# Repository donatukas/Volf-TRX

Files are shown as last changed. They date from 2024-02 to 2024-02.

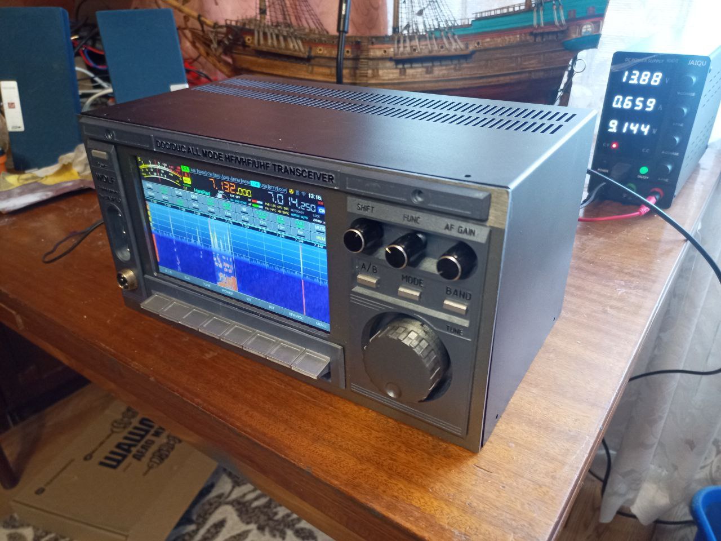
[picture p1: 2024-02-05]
Schematic/Wolf/CASE/7/Panel/photo_2023-04-01_13-19-56.jpg

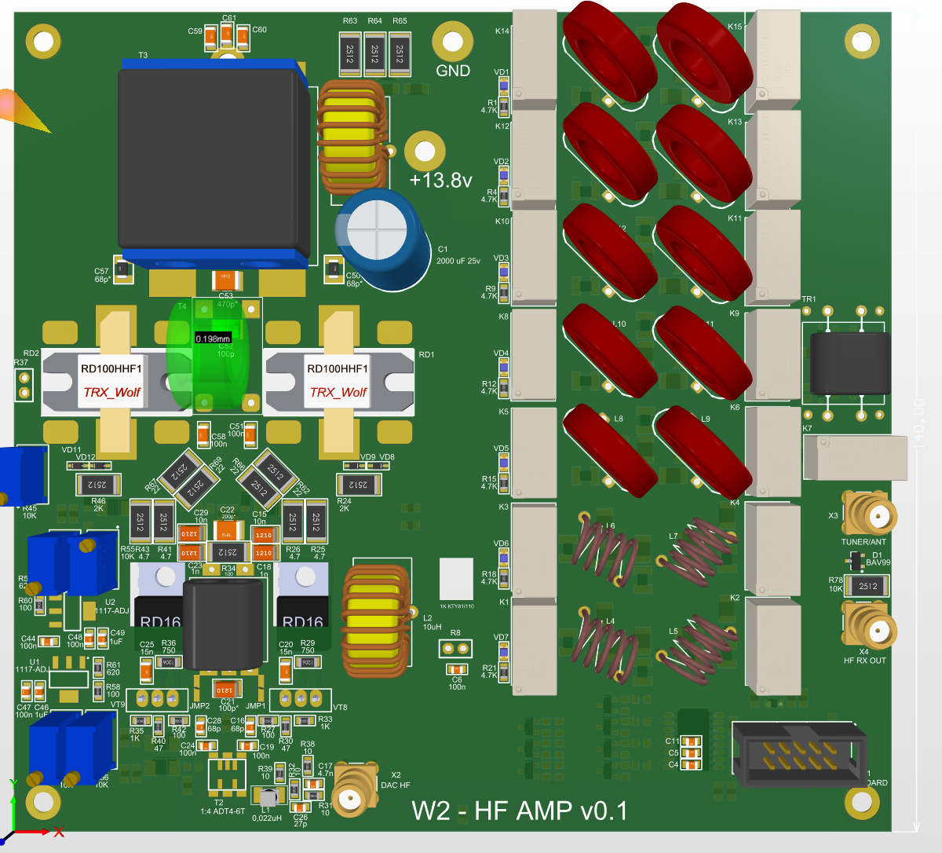
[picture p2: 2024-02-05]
Schematic/Wolf-2/Altium_Designer/W2-HF_AMP/HFAmp_UP_v01.png

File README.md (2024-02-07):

# Transceiver "Wolf"
DDC-DUC SDR Tranceiver project https://ua3reo.ru/tag/transiver-ua3reo/
* DUC-DDC TRANSCEIVER “WOLF”: RELEASE VERSION 9.3.1
* Community telegram channel: https://t.me/TRX_Wolf
* На русском https://github.com/donatukas/Volf-TRX/blob/main/README.ru-RU.md

## Principle of operation

The RF signal is digitized by a high-speed ADC chip and fed to an FPGA processor. <br>
It performs DDC / DUC conversion (digital frequency shift down or up the spectrum) - by analogy with a direct conversion receiver. <br>
The I and Q quadrature signals from the conversions are fed to the STM32 microprocessor. <br>
It filters, (de) modulates and outputs audio to an audio codec / USB. It also handles the entire user interface. <br>
When transmitting, the process occurs in the opposite order, only at the end of the chain there is a DAC, which converts the digital signal back to analog RF. <br>

## Specifications

* Receiving frequencies: 0 MHz - 750 MHz with fading each 61.44 MHz (above 145 MHz - without input filters)
* Transmission frequencies: 0 MHz - 150 MHz with fading on 110 MHz
* TX power (QRP version): 7W+ (HF), 5W (VHF)
* TX power (QRP++ DB5AT version): 20W (HF), 7W (VHF)
* TX power (RU4PN/WF-100D version): 100W (HF), 50W+ (VHF)
* Two antenna inputs
* Modulation types (TX / RX): CW, LSB, USB, AM, FM, WFM, DIGI
* LNA, Preamplifier
* Adjustable attenuator 0-31dB
* Band pass filters
* ADC dynamic range (16 bit) ~100dB
* Supply voltage: 13.8V (overvoltage and polarity reversal protection)
* Consumption current when receiving: ~0.7А (3'2 QRP), 0.9A (7' BIG)
* Current consumption during transmission: ~2.5А+ (QRP), 15A+ (BIG)
* Support for different displays: RA8875/HX8357B/HX8357C/ST7789/ST7796S/ST7735S/ILI9341/ILI9481/ILI9486

## Transceiver Features

* Panorama (spectrum + waterfall) up to 384 kHz wide
* Panorama tweaks and themes
* Dual receiver (mixing A + B or A&B audio in stereo)
* Adjustable bandwidth: HPF from 0Hz to 2700Hz, LPF from 100Hz to 20kHz
* Integrated SWR/power meter (HF)
* Automatic and manual Notch filter
* Switchable AGC (AGC) with adjustable attack rate
* Range map, with the ability to automatically switch modes
* Digital Noise Reduction (DNR), Pulse Noise Reduction (NB)
* CAT virtual COM port (FT-450 / TS-2000 emulation, RTS - PTT, DTR - CW)
* USB operation (audio transmission, IQ, CAT, KEY, PTT)
* RDS/CW/RTTY decoder, self-control, gauss filter
* SWR Graphs
* Spectrum analyzer
* FT8 receiver/transmitter
* Automatic send FT8 qso to log https://allqso.ru/
* WSPR Beacon
* VOX
* Equalizer TX/RX, reverber
* SSB/FM Scanner mode
* Support SDHC/SDSC/SDXC memory cards up to 16Gb
* WAV files radio recording and playback, fast broadcast recorded CQ message
* AGC takes into account the characteristics of human hearing (K-Weighting)
* TCXO frequency stabilization (it is possible to use an external clock source, such as GPS)
* WiFi operation: Time synchronization, virtual CAT interface (see Scheme/WIFI-CAT-instruction.txt)
* Tangent support Yaesu MH-36 и MH-48
* Hardware self-testing
* Firmware update over USB, SD, WiFi
* Digital pre-distortion
* And other.. (see menu)

### RF Parameters

Sensitivity at 10 dB SNR, LNA enabled:

* <150 MHz | -131 dBm | 63.0 nV
* 435 MHz | -121 dBm | 0.2 uV

Out-of-band emissions:

* 14 MHz -69 dBc
* 28 MHz -63 dBc
* 145 MHz -48 dBc -55 dBc

## Build

I ordered the boards in the Chinese service JLCPCB, they and their schemes are in the Scheme folder. <br>
After assembly, you need to flash FPGA and STM32 chips. <br>
If necessary, calibrate the transceiver through the appropriate menu <br>
WiFi module ESP-01 must have fresh firmware with SDK 3.0.4 and higher, and AT commands 1.7.4 and higher <br>

## Management

* **AF GAIN** - Volume
* **RIT / GAIN** - When the RIT function is active - smooth offset from the selected transceiver frequency. Inactive - IF gain control
* **ENC MAIN** - Main encoder for frequency control and menu settings
* **ENC 2** - Auxiliary encoder for menu operation. In normal mode, quickly switches the frequency, in CW fast change WPM
* **ENC 2[click]** - In CW mode, toggles between fast step and WPM selection, in other modes it opens the bandwidth properties.
* **BAND -** - Switch to the band below
* **BAND +** - Switch to higher band
* **MODE -** - Mode group switching SSB-> CW-> DIGI-> FM-> AM
* **MODE +** - Switching subgroup mod LSB-> USB, CW_L-> CW_U, DIGI_U-> DIGI_L, NFM-> WFM, AM-> IQ-> LOOP
* **FAST** - Mode of fast x10 rewinding of the frequency by the main encoder (configurable)
* **FAST [clamp]** - Frequency step settings
* **PRE** - Turn on the preamplifier (LNA)
* **PRE [clamp]** - Turn on the driver and / or amplifier ADC
* **ATT** - Turn on the attenuator
* **REC** - Save audio to SD card
* **CQ** - Play recorded CQ-message from SD card
* **MUTE** - Mute the sound
* **MUTE [clamp]** - Scanner mode
* **AGC** - Turn on AGC (automatic gain control)
* **AGC [clamp]** - AGC settings
* **A = B** - Setting the second bank of the receiver equal to the current
* **BW** - Switch to bandwidth selection menu (LPF)
* **BW [clamp]** - Switch to bandwidth selection menu (HPF)
* **TUNE** - Turn on the carrier for tuning the antenna
* **RF POWER** - Transmitter power selection
* **RF POWER [clamp]** - Squelch setting
* **A / B** - Switches between VFO-A / VFO-B receiver settings banks
* **A / B [clamp]** - Enable automatic mode change by bendmap
* **DOUBLE** - Turn on the dual receiver
* **DOUBLE [clamp]** - Switching between the modes of the dual receiver A&B (each channel of the headphones has its own path) or A + B (mixing signals of 2 receivers)
* **DNR** - Enable digital noise reduction
* **DNR [clamp]** - Turn on the impulse noise suppressor (NB)
* **NOTCH** - Turn on the automatic Notch filter to eliminate narrowband interference
* **NOTCH [clamp]** - Turn on the manual Notch filter to eliminate narrowband interference
* **SPLIT** - Allows you to split transmission and reception to different VFO banks
* **RIT [clamp]** - Enables RIT control from the front panel
* **WPM** - Switch to key speed selection menu (WPM)
* **WPM [clamp]** - Automatic key enable
* **MENU** - Go to the menu
* **MENU [clamp]** - Enable key lock LOCK
* **MENU [at power on]** - Reset transceiver settings
* **MENU [at power on+PRE]** - Reset transceiver settings and calibration
* **RIT** - Offset of the receiving frequency relative to the current frequency (TX without offset)
* **XIT** - Offset of the transmission frequency relative to the current frequency (RX without offset)

## Settings

### TRX Settings

* **Band Map** - Band Map, automatically switches mode depending on the frequency
* **Beeper** - Beep on key press
* **Callsign** - User callsign
* **Channel Mode** - Channel frequency mode (for LPD/PMR and etc.)
* **Custom Transverter** - Enable external transverter on non-ham band (just offset display frequency)
* **DEBUG Type** - Output of debug and service information to USB / UART ports
* **Encoder Accelerate** - Accelerate encoder on fast rates
* **Fine RIT Tune** - Fine or coarse tuning for RIT/XIT (encoder or resistor)
* **Freq Step xxx** - Frequency step by main encoder in each mode, Hz
* **FAST Step Multiplier** - Frequency step multiplier for FAST mode
* **ENC2 Step Mult** - Frequency step multiplier for ENC2 rotation (for CW/SSB)
* **Notch Step** - Frequency step of manual notch filter
* **Full Duplex** - Full duplex RX+TX mode
* **Locator** - User QTH locator
* **RIT Interval** - Offset range RIT (+ -)
* **XIT Interval** - Offset range XIT (+ -)
* **Split freq sync** - Synchronous VFO frequency change in SPLIT mode
* **Transverter XXcm** - Enable external ham band transverter support
* **URSI Code** - Ionogramm URSI Code https://digisonde.com/index.html#stationmap-section
* **Tropo Region** - Region for tropospheric forecast https://www.dxinfocentre.com/tropo.html 
* **Wolf Cluster** - Display Wolf TRX users on spectrum and send self data

### FILTERS Settings

* **AM/FM/CW/SSB LPF Stages** - Adjusting the slopes of the LPF filters in defferent modes
* **CW LPF Pass** - LPF cutoff frequency when working in CW
* **CW Gauss filter** - Gauss responce LPF filter
* **DIGI LPF Pass** - LPF cutoff frequency when working in DIGI
* **FM LPF Pass** - LPF cutoff frequency when working in FM
* **SSB HPF Pass** - HPF cutoff frequency when operating in SSB
* **SSB LPF Pass** - LPF cutoff frequency when operating in SSB
* **NOTCH Filter width** - Cutting width of Manual Notch filter

### RX Settings

* **ADC Dither** - Enable ADC dither for receiving weak signals
* **ADC Driver** - Turn on the preamplifier-ADC driver
* **ADC Preamp** - Turn on the preamplifier built into the ADC
* **ADC Randomizer** - Enables ADC digital line encryption
* **ADC Shutdown** - Turn off the ADC
* **AGC Gain target, LKFS** - Maximum AGC gain (Maximum volume with AGC on)
* **AGC Spectral** - Enable FFT-based AGC
* **AGC Threshold** - Enabling the AGC opening threshold
* **Att step, dB** - Attenuator tuning step
* **Attenuation, dB** - Current attenuation
* **Auto Snap** - Automaticly track and snap to near signal frequency (CW mode)
* **AutoGainer** - Automatic ATT / PREAMP control depending on the signal level on the ADC
* **A/B Balance** - Channels balance in dual RX modes A+B and A&B
* **CODEC Gain** - Adjusting AF gain in audio codec
* **DNR xxx** - Digital squelch adjustment
* **Squelch** - Enable SSB/AM/CW/FM Squelch
* **FM Squelch level** - FM squelch level
* **IF Gain, dB** - IF gain
* **NB Threshold** - Threshold of Noise blanker
* **Free tune** - Allows you to move the reception frequency across the spectrum without changing the center frequency of the spectrum itself
* **Center After Idle** - Center the spectrum with Free Tune active after 20 seconds of inactivity
* **Noise Blanker** - Activating the Surge Suppressor
* **RX AUDIO Mode** - Audio lines control: Stereo\Left\Right
* **RX AGC Hold time** - Time before release of AGC gain in signal peaks, ms
* **RX AGC Hold limit** - Burst limit for AGC delay time
* **RX AGC Hold step up** - AGC Delay Time Step on Peaks
* **RX AGC Hold step down** - AGC Delay Falloff Step at Peaks
* **RX AGC Max gain** - Limit of AGC gain, dB
* **RX AGC Speed** - AGC (automatic signal level control) response speed for reception (more-faster)
* **RX EQ xxx** - Receiver equalizer levels
* **TRX Samplerate** - Max FFT/samplerate on CW/SSB/NFM/DIGI/etc modes
* **FM Samplerate** - Max FFT/samplerate on NFM/WFM mode
* **VAD Threshold** - VAD voice detector threshold (noise suppressor for SSB mode and SCAN mode)
* **Volume step** - AF gain step by ENC2 (X1, Lite)
* **Volume** - AF gain
* **WFM Stereo** - select WFM stereo or mono decoder
* **WFM Stereo Modulation** - Stereo FM sub-carrier level

### TX Settings

* **ATU Cap** - Tuner Capacitance Combination
* **ATU Enabled** - Turning on the automatic antenna tuner
* **ATU Ind** - Combination of tuner inductances
* **ATU T** - Tuner capacitive arm position
* **ATU Mem step, kHz** - Step of saving tuner values for frequencies into memory
* **Auto Input Switch** - Auto input switch (PTT - mix, CAT - USB)
* **CESSB** - Enable controlled-envelope single-sideband modulation
* **CESSB Compress, dB** - Signal pre-amplification level before compression in CESSB
* **Compressor MaxGain** - Maximum comressor gain
* **Compressor Speed** - TX compressor response speed for transmission (more-faster)
* **CTCSS Frequency** - Transmit FM CTCSS sub-tone frequency
* **FT8 Auto CQ** - Automatic transition to CQ mode after FT8 communication
* **Input Type** - Select audio input (microphone, line in, USB)
* **LINE Gain** - Line input codec gain
* **MIC Boost** - +20db hardware mic amplifier
* **MIC EQ xxx** - Microphone equalizer levels
* **MIC Gain** - Microphone gain
* **MIC Noise Gate** - The level below which the microphone signal is muted, dbFS
* **MIC Reverber** - Microphone reverberator level
* **Power for each band** - Save power settings for each band individually
* **Power for each mode** - Save power settings for each mode individually
* **RF Power** - Transmission power,%
* **Repeater Mode"** -  Operation mode via repeater
* **Repeater offset, kHz"** -  Transmission frequency offset in repeater mode
* **SelfHear Volume** - Self Hearing (CW/DIGI) volume relative to the overall transceiver volume
* **TUNER Enabled** - Turning on the antenna tuner
* **Two Signal tune** - Two-signal generator in TUNE mode (1.0 + 2.2kHz)
* **VOX Threshold, dbFS** - VOX Threshold, dbFS
* **VOX Timeout, ms** - VOX transmission delay after silence, milliseconds
* **VOX** - TX Voice activation

### CW Settings

* **Auto CW Mode** - Automatic transition to CW mode when the key is pressed
* **CW In SSB** - Allow CW TX manipulation in SSB mode
* **DotToDash Rate** - Keyer dash to dot length rate
* **Edges smooth, ms** - Smoothing signal edges
* **Iambic Keyer** - Enable Iambic mode keyer
* **Iambic Type** - Type of Iambic keyer (A/B)
* **Key Invert** - Invert dash/dot on key
* **Key timeout** - Time before stopping the transmission mode after releasing the key
* **Keyer WPM** - Key Speed, WPM
* **Keyer** - Automatic Key
* **One symbol memory** - Keyer memory for one symbol for transmit
* **PTT Type** - RX/TX switch type for CW: by key or external PTT (tangent, etc.)
* **Pitch** - Detuning the receive generator from the transmit frequency
* **Self Hear** - Self-control CW (key press is heard)
* **Macros x** - Setting up macros for CW transmission
* **Macros x name** - Setting the macro name to be displayed in the interface

### SCREEN Settings

* **Bottom navi buttons** - Show bottm menu navigation buttons (for 7 inch displays)
* **Color Theme** - Select colors theme (0 - black, 1 - white, 2 - black with colored frequency)
* **Layout Theme** - Select interface theme (0 - default)
* **DX Cluster Type** - Selecting a Data Source for a DX Cluster
* **FFT 3D Mode** - Enable FFT 3D mode (0 - disabled, 1 - lines, 2 - pixels)
* **FFT Automatic** - Automatic FFT scale
* **FFT Averaging** - FFT burst averaging level. Full - automatic selection of upper and lower boundaries, Half - auto lower and manual upper, No - manual setting of the range of spectrum levels. (Remember to select the correct FFT Scale Type so that your range will fit on the screen)
* **FFT BW Style** - FFT bandwidth style: high opacity, low opacity, lines
* **FFT BW Position** - Position of the receiving band on FFT/WTF (everywhere \ at the top \ at the top + lines \ top + bottom with time delay)
* **FFT Background** - Gradient FFT background
* **FFT Color** - FFT colors: 1(blue -> yellow -> red), 2(black -> yellow -> red), 3(black -> yellow -> green), 4(black -> red), 5(black -> green), 6(black -> blue), 7(black -> white)
* **FFT Compressor** - Enable FFT peak comressor
* **FFT DXCluster Azimuth** - Add azimuth data to DX-cluster
* **FFT DXCluster Timeout** - Timeout of DX-cluser spots in minutes
* **FFT DXCluster** - Show DXCluster info over FFT
* **FFT Enabled** - Enable waterfall and FFT
* **FFT Freq Grid** - FFT and waterfall grids: 1(no grid), 2(fft grid), 3(fft+wtf grids), 4(wtf grid)
* **FFT Height** - FFT and waterfall proportional height
* **FFT Hold Peaks** - Show peaks on FFT spectrum
* **FFT Lens** - Enable FFT lens mode (magnify center of spectrum)
* **FFT Manual Bottom, dBm** - Bottom FFT threshold in manual mode
* **FFT Manual Top, dBm** - Top FFT threshold in manual mode
* **FFT Scale Type** - Y-axis style on FFT between signal amplitude and dBm to fit more dynamic range on screen (Useful when manually adjusting FFT range).
* **FFT Sensitivity** - Top threshold of FFT sensitivity in automatic mode (30 - scale to strongest signal)
* **FFT Speed** - FFT and waterfall speed
* **FFT Style** - FFT style: 1(gradient), 2(fill), 3(dots), 4(contour), 5(gradient + contour)
* **FFT Window** - Select FFT window (1-Dolph–Chebyshev 2-Blackman-Harris 3-Nutall 4-Blackman-Nutall 5-Hann 6-Hamming 7-No window)
* **FFT Zoom CW** - FFT spectrum zooming for CW Mode
* **FFT Zoom** - FFT spectrum zooming
* **FFT dBm Grid** - FFT signal power grid
* **LCD Brightness** - Set LCD brightness (not all lcd support)
* **LCD Sleep Timeout** - Idle time before the screen brightness decreases, sec (0 - disabled)
* **Show Sec VFO** - Show secondary VFO position on spectrum
* **WTF Color** - Waterfall colors: 1(blue -> yellow -> red), 2(black -> yellow -> red), 3(black -> yellow -> green), 4(black -> red), 5(black -> green), 6(black -> blue), 7(black -> white)
* **WTF Moving** - Mowe waterfall with frequency changing

### Decoders
* **CW Decoder** - Software CW receive decoder
* **CW Decoder Threshold** - CW receive decoder sensivity
* **RDS Decoder** - Enable RDS Decoder for WFM mode
* **RTTY Freq** - Central frequency of RTTY decoding
* **RTTY InvertBits** - RTTY invert 0 and 1 bits
* **RTTY Shift** - RTTY carrier shifts
* **RTTY Speed** - Speed of RTTY data
* **RTTY StopBits** - RTTY Stop bits

### WIFI Settings

* **WIFI Enabled** - Enable WiFi module (need restart after enable)
* **WIFI Network** - WiFi hotspot selection
* **WIFI Network Pass** - Set password for WiFi hotspot
* **WIFI Timezone** - Time zone (for updating the time via the Internet)
* **WIFI CAT Server** - Server for receiving CAT commands via WIFI
* **WIFI Update ESP firmware** - Start cloud autoupdate firmware for ESP-01 (if present)
* **ALLQSO.RU Token/LogId** - Token и LogID from https://allqso.ru/ web-log

### SD Card

* **File Manager** - Show SD Card file manager, support WAV playback and deleteing files, listening and broadcasting recordings, as well as updating firmware from a memory card
* **Record CQ message** - Record a short message for quick broadcast
* **USB SD Card Reader** - Enable USB SD Card reader
* **Export Settings** - Export settings and calibration data to SD card
* **Import Settings** - Import settings and calibration data from SD card
* **Format SD card** - Format media drive

### Satellites

* **SAT Mode** - Enable satellite mode
* **Download TLE** - Download current satellite data
* **Select SAT** - Select a satellite from the downloaded TLE file
* **QTH xxx** - Setting the Latitude\Longitude\Altitude of your location

### Calibration [appears by long pressing the MENU button in the settings menu]

* **ALC Port Enabled** - Activation of transceiver power control by an external amplifier via the ALC line: up to 1 volt - ALC is disabled and the power set in the transceiver is used. from 1.0v to 3.0v - power adjustment from 0 to 100%
* **ALC Inverted** - Invert ALC logic (3.0v - 0%, 1.0v - 100%)
* **AM Modulation Index** - Set TX AM Modulation Scale
* **ATU Averaging** - The number of steps of averaging SWR values during measurements in the operation of an automatic tuner
* **BPF x** - Bandpass filter parameters
* **CAT Type** - Type of CAT subsystem (FT-450 / TS-2000)
* **COM CAT DTR/RTS** - Configuring the functions of the DTR/RTS control lines of the CAT port
* **COM DEBUG DTR/RTS** - Configuring the functions of the DTR/RTS control lines of the Debug port
* **CICCOMP Shift** - Bit shift after CIC compensator
* **Calibrate reset** - Reset all calibrations to defaults
* **DAC Driver Mode** - DAC Driver OPA2673 bias mode (2 = 100% bias, 1 = 75% bias, 0 = 50% bias)
* **DAC Shift** - Bit shift of the output to the DAC
* **ENABLE 2200m/60m/6m/4m/FM/2m/AIR/Marine Band/70cm** - Enable hidden bands
* **EXT xxx** - External port control by band (EXT3, EXT2, EXT1, EXT0) - open drain
* **Encoder acceleration** - The encoder acceleration on faster rotation speeds
* **Encoder debounce** - Time of debouncing contacts of the main encoder
* **Encoder invert** - Invert the rotation of the main encoder
* **Encoder on falling** - The encoder is triggered only when level A falls
* **Encoder slow rate** - Deceleration rate of the main encoder
* **Encoder2 debounce** - Time of debouncing contacts of the additional encoder
* **Encoder2 invert** - Invert the rotation of the additional encoder
* **Encoder2 on fall** - Mode of operation of the secondary encoder (some encoders skip a step or make an extra one)
* **FAN Full start** - Temperature of the PA for starting the fan at full speed
* **FAN Medium start** - Temperature of the PA for starting the fan at medium speed
* **FAN Medium stop** - Temperature of the PA for stopping the fan
* **FAN Medium PWM** - Adjusting the duty cycle of a PWM fan in Medium mode
* **FM Deviation Scale** - Set TX FM Deviation Scale
* **Flash GT911** - Starting the touchpad update procedure according to LCD screen resolution
* **HPF START** - HPF filter parameters
* **IF Gain MIN/MAX** - IF Gain adjusting limits
* **INA226** - Activation and calibration of the INA226 voltage/current sensor on the I2C bus
* **KTY81 Calibration** - Calibration of the KTY81 sensor (setting the resistance of the divider arm)
* **LCD Rotate** - Rotate screen at 180 degrees
* **LNA Compensation** - Compensates the S-meter value when the LNA is turned on, dBm
* **ATT Compensation** - Compensates the S-meter value when the ATT is turned on
* **LPF END** - LPF filter parameters
* **Linear Pwr Control** - Sets a linear way to change the signal amplitude when adjusting the power (if disabled - logarithmic)
* **MAX ChargePump, kHz** - Maximum PWM frequency for ChargePump circuit
* **MAX PWR on Meter** - Maximim RF power (for indication)
* **MAX Power in TUNE** - Maximum RF power in Tune mode
* **MAX RF Temp** - Maximum temperature of the PA before the protection operation
* **MAX SWR** - Maximum VSWR before protection operation
* **NOTX xxx** - Disable TX on selected bands
* **OTA Update** - Enable OTA firmware update over WiFi
* **RF GAIN xxx** - Calibration of the maximum TX output power for each range
* **RF-Unit Type** - RF-Unit Type (QRP / BIG)
* **RTC COARSE CALIBR** - Very coarse clock crystal calibration
* **RTC FINE CALIBR** - Clock crystal calibration, one division is 0.954 ppm
* **S METER** - S-meter calibration
* **SSB Power addition** - Addition of RF power in SSB power, %
* **SWR FWD/BWD RATE** - Adjustment of the transformation ratio of the SWR meter (forward / return)
* **Swap USB IQ** - Swap USB IQ output
* **Settings reset** - Reset all settings to defaults
* **TCXO Frequency, kHz** - Frequency adjustment of the reference oscillator
* **VCXO Correction** - Correction for main generator frequency offset
* **Touchpad flip** - Flip the touchpad operation horizontally/vertically
* **Touchpad timeout** - Minimum time between taps (protection against false trigger), ms
* **Touchpad click threshold** - Minimum time for triggering a short click, ms
* **Touchpad click timeout** - Maximum time for triggering a short click, ms
* **Touchpad hold timeout** - Time before a long press is triggered, ms
* **Touchpad swipe threshold** - Minimum distance to trigger a swipe, px
* **TSignal Balance** - Sets the power balance between signals in Two signal tune mode
* **TX CICCOMP Shift** - Bit shift after TX CIC compensator
* **TX Start Delay** - Delay before the RF signal is applied (ms), so that the relay has time to trigger
* **Tangent Type** - Select tangent type
* **Transverter Offset, MHz** - Offset frequency shown on the display (for custom transverters)
* **Transverter xxx IF, MHz** - Setting the IF frequency of the transverter
* **Transverter xxx RF, MHz** - Setting the RF frequency of the transceiver to match the IF

### Memory Channels

* Changing names for transceiver memory channels

### Set Clock Time

* Clock setting

### DFU Mode

* Launch STM32 USB firmware update over DFU mode

### OTA Update

* Launch FPGA/STM32 firmware update over internet

### System info

* Show info about TRX

## Services

### Spectrum Analyzer

* **Spectrum START** - Start the spectrum analyzer
* **Begin, kHz** - Starting frequency of the analyzer with a step of 1 kHz
* **End, kHz** - End frequency of the analyzer in 1 kHz steps
* **Top, dBm** - Upper threshold of the graph
* **Bottom, dBm** - Lower threshold of the graph

### WSPR Beacon

* **WSPR Beacon START** - Start WSPR beacon
* **Freq offset** - Offset from center of WSPR band
* **WSPR Band xxx** - Select bands to WSPR beacon

### DX Cluster 

* Show DX Cluster info by current band (from internet)

### Propagation 

* Show propagation statistics (from internet)

### Tropo 

* Show tropospheric forecast

### DayNight Map 

* Displaying the day/night terminator on the map (from internet)

### Ionogram 

* Displaying the ionogram for the selected URSI Code (from internet)

### SWR Analyser

* Run SWR analizer (Band SWR - on current band, HF SWR - on all HF bands, Custom SWR - in selected range)

### RDA Statistics 

* Print statistics from RDA award (from internet)

### FT8

* FT8 Receiver / transmitter

### Locator Info

* Calculate distance and azimuth from QTH-locator

### Callsign Info

* Show callsign data

### Time Beacons

* List of beacons of the exact time (for adjusting the frequency of reception by carrier)

### Self Test

* Run hardware self diagnostic

### Auto calibration

* **Calibrate SWR** - Assistant in measuring SWR and power meter
* **Calibrate Power** - Assistant in adjusting RF Power output

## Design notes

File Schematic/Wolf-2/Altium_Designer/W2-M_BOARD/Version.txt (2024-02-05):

-- v0.3 --
1. Исправлены посадочные под ST6PIC595
2. Диаметр сигнальных межслойных переходов изменен с 0.6мм на 0.5мм
3. Добавлено управление основным вентилятором с соответствующим разъемом.
4. Исправлена инверсия ключа K_VHF (+BSS123).
5. Изменена цепь питания LTC2208 + добавлены блокировочные C - попытка отделить питание цифры и аналога, должно еще снизить шумы.
6. Увеличена площадка стабилизатора +1V2 для улучшения теплоотвода.
7. Стабилизатор 3V3 питания АЦП разместил чуть дальше от стабилизатора 1V2, для лучшего распределения тепла.
8. Стабилизатор 2v5 Плис запитан от 5В. Не хватало входных 3.3В для полной стабилизации.
9. Мелкие правки по шелкографии.
 
-- v0.4 --
1. Исправление по шине управления тюнером

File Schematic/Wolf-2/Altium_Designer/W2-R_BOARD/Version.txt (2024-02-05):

--- v0.3 ---
1. Танталы в УНЧ заменены на электролиты.
2. Сделан выбор питания УНЧ - с фронта или напрямую.
3. Подправлена шелкография реле К1
4. Разъемы выдвинуты еще на пару мм - чтобы прижимались к плате полностью.
5. Увеличены посадочные под SMD шунты (4х0.1R)
6. Исправлено посадочное под ADUM4160
7. Добавлены аттенюаторы по входу УНЧ и Bluetooth, чтобы выровнить сигнал по нужному уровню.
8. В цепи Stand-by УНЧ сделана цепь задержки для исключения кратковременных выключений при смене моды и т.д.
9. Чуть сдвинут разъем X4 внутрь.

--- v0.4 ---
1. Изменена схема управления питанием Bluetooth и УНЧ. Теперь при отключении УНЧ включается Bluetooth и наоборот.

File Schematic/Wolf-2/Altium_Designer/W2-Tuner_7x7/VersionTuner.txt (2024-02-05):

-- v01 --
1. Первый опытный образец.

-- v02 --
1.Исправление по управлению ключами - дешифраторы заменены на регистры.

-- v03 --
1. Исправление полярности реле K4 и К16.

-- v0.4 - 
1. Исправление подключения разъемов Х3, Х4

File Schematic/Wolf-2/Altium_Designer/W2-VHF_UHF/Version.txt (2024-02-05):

-- v0.2 --
1. Разделение платы на логические блоки: управление/144/430.

-- v0.3 --
1. Исправление питания VT1 при FM и WB.
2. Корректировка номиналов обвязки стабилизаторов LP1, LP2, LP3
3. Исправление номиналов L3, L16, L10
4. Аттенюатор TX-сигнала заменен на 5дб.
5. Исправление названия стабилизатора U3. Правильно - AMS1117-5.0

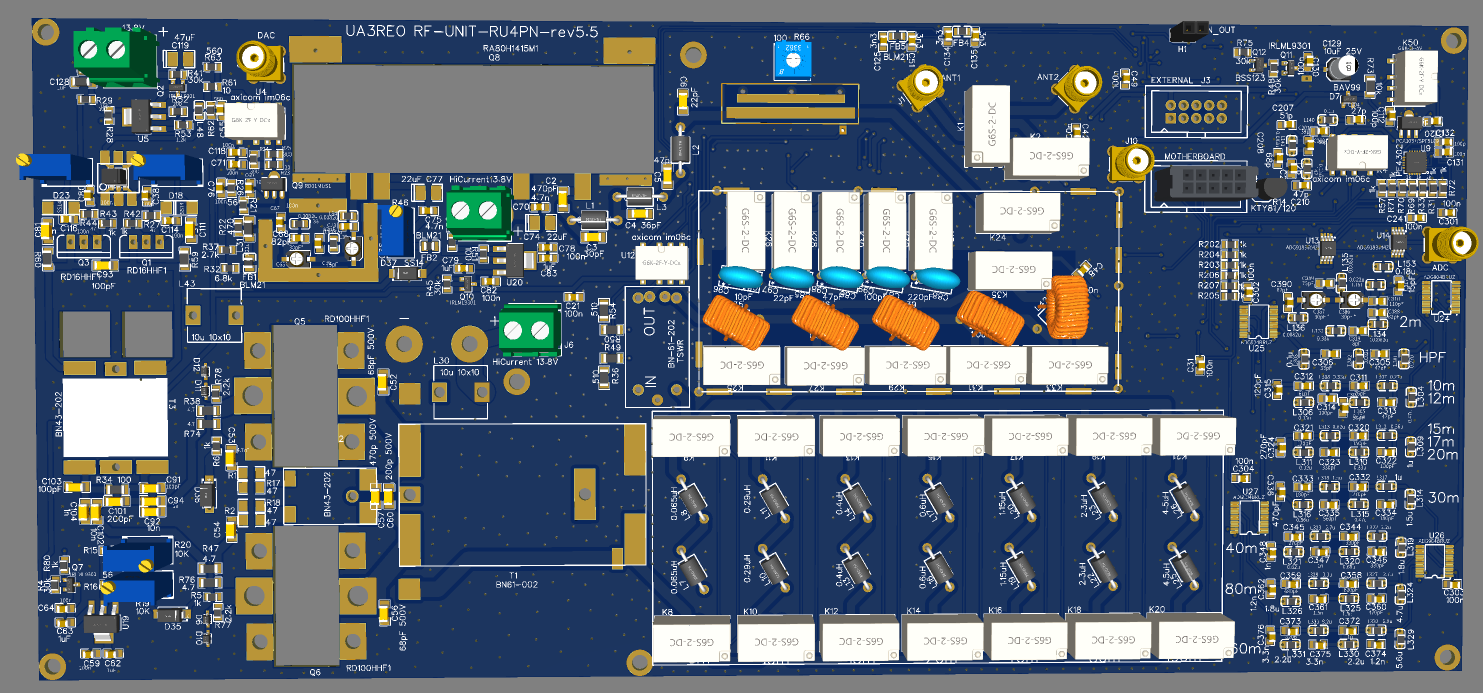
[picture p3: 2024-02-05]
Schematic/Wolf/Assembly/SCHEMATIC-RF-UNIT-BIG-RU4PN-rev5.5_UP.png

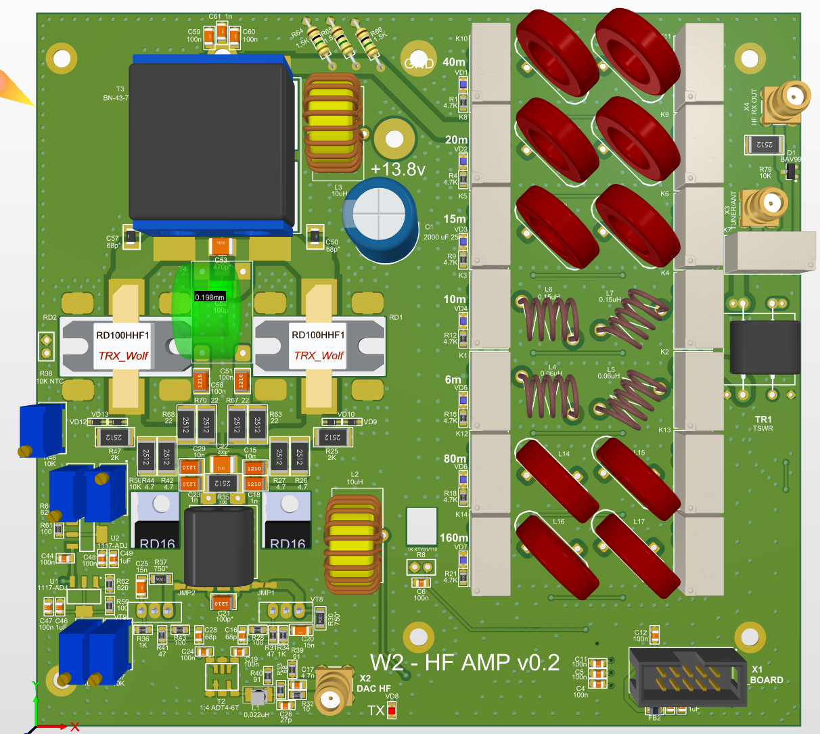
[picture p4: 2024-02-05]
Schematic/Wolf-2/Altium_Designer/W2-HF_AMP/HFAmp_UP_v02.png

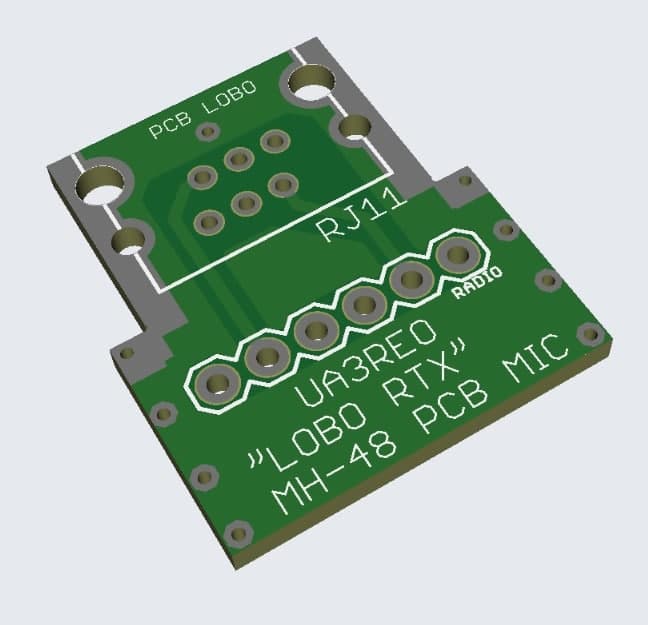
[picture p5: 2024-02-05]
Schematic/Wolf/Addons/PCB MIC MH-48/pcb2.jpg

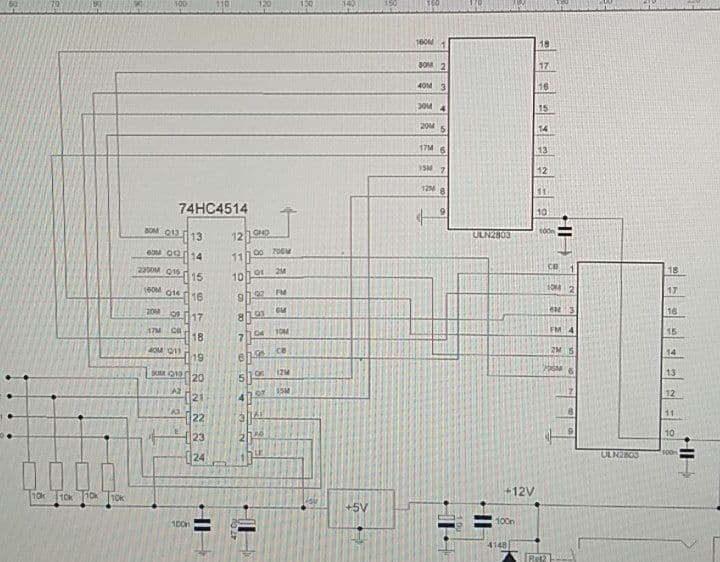
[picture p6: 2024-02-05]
Schematic/Wolf/Addons/LPF_switch.jpg

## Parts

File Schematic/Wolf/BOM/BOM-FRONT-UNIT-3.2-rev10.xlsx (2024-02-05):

Comment | Description | Designator | Footprint | Quantity
0 | RES_0805 | R23, R24, R25 | RES_0805 | 3
1n | CAP_1206 | C5 | CAP_1206 | 1
1n4148w | Diode | D25, D27 | SOD3716X135N | 2
1uF | CAP_1206 | C3 | CAP_1206 | 1
3.3k | RES_0805 | R20, R21, R22 | RES_0805 | 3
4.7k | RES_0805 | R3, R4, R5, R6, R7, R8, R9, R10, R11, R12, R13, R14, R15, R16, R17, R18, R19, R29, R30, R31, R32, R33, R34, R35, R36 | RES_0805 | 25
8.2n | CAP_1206 | C11 | CAPC2013X94X50LL20T25 | 1
10n | CAP_0805 | C12, C13 | CAP_0805 | 2
22uF 10V | EEEFC_sizeB | C10 | EEEFC_sizeB | 1
30k | RES_0805 | R26, R27, R28 | RESC2013X60X40NL20T25 | 3
100n | CAP_0805 | C1, C2, C9 | CAP_0805 | 3
100n | CAP_1206 | C4 | CAP_1206 | 1
120p | CAP_1206 | C8 | CAP_1206 | 1
470p | CAP_1206 | C7 | CAP_1206 | 1
1000uF | CAP250RP | C6 | CAP250RP | 1
BNX016-01 | BNX016-01 | T1 | TRANSF_ICORE | 1
BSS123 | N-Channel Logic Level Enhancement Mode Field Effect Transistor, 1.7 V, -55 to 150 degC, 3-Pin SOT-23, RoHS, Tape and Reel | Q2 | FAIR-SOT23-3_V | 1
DM3AT-SF-PEJM5 | Connector | J2 | DM3ATSFPEJM5 | 1
ESP-01 ESP8266 | ESP-01 ESP8266 | ESP-8266 | ESP-01 ESP8266 | 1
FPC-45P-0.5mm | Connector | J7 | FH12S45S05SH60 | 1
ILI9481 480*320 3'2 | LCD-MODULE_3'2_480х320 | LCD-MODULE | LCD-MODULE-3.2-480-320 | 1
IRFR9024NPBF | IRFR9024NPBF, Транзистор, Р-канал 55В 11А | Q1 | ONSC-DPAK-3-369C-01_V | 1
JX2 | JX2 | ACCUM, IN, MOTHERBOARD, RF-UNIT | JX2 | 4
MCP3008-I/SL | MCP3008-I/SL | U1, U2, U3 | MCP3008-I/SL | 3
MF-MSMF110_16-2 | Fuse | F2 | FUSC4632X85N | 1
OPTICAL ENCODER | OPTICAL ENCODER | ENCODER_MAIN | 644456-4 | 1
PEC12 | PEC12 | ENC2 | PEC12 | 1
PJ-050B | PJ-050B | IN_2 | PJ-050B | 1
PTS645SK50LFS | PTS645SK50LFS | S1, S2, S3, S4, S5, S6, S7, S8, S9, S10, S11, S12, S13, S14, S15, S16, S17, S18, S19, S20, S21, S22, S23 | PTS645SK50LFS | 23
ptv09a-4225f-b102 | Adjustable Resistor PTV09 | R1, R2 | PTV09 | 2
RUEF400 | Fuse | F1 | RUEF400 | 1
SM6T15A | Diode | D28 | SMBJ36CATR | 1

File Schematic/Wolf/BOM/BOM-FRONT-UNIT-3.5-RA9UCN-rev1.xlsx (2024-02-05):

Comment | Description | Designator | Footprint | LibRef | Quantity
JX2 | JX2 | ACCUM, IN, MOTHERBOARD, RF-UNIT | JX2 | JX2 | 4
100n | CAP_0805 | C1, C2, C9, C14, C15, C16, C17, C18, C19, C20, C21, C22, C23, C24, C25, C26 | CAP_0805 | CAP_0805 | 16
1uF | CAP_1206 | C3 | CAP_1206 | CAP_1206 | 1
100n | CAP_1206 | C4 | CAP_1206 | CAP_1206 | 1
1n | CAP_1206 | C5 | CAP_1206 | CAP_1206 | 1
1000uF | CAP250RP | C6 | CAP250RP | CAP250RP | 1
470pF | CAP_1206 | C7 | CAP_1206 | CAP_1206 | 1
120pF | CAP_1206 | C8 | CAP_1206 | CAP_1206 | 1
22uF | EEEFC_sizeB | C10 | EEEFC_sizeB | EEEFC_sizeB | 1
8.2n | CAP_1206 | C11 | CAPC2013X94X50LL20T25 | CMP-2007-04444-1 | 1
10n | CAP_0805 | C12, C13 | CAP_0805 | CAP_0805 | 2
470uF | 10x7.7, 8.7, 10, 10.5, 12.5 | C1001, C1002 | SMD-G-10X10.2 | _SMD-G-10 | 2
1n4148w | Diode | D25, D27 | SOD3716X135N | 1n4148w | 2
SM6T15A | Diode | D28 | SMBJ36CATR | SM6T15A | 1
PEC12 | PEC12 | ENC2 | PEC12 | PEC12 | 1
OPTICAL ENCODER | OPTICAL ENCODER | ENCODER_MAIN | 644456-4 | 644456-4 | 1
ESP-01 ESP8266 | ESP-01 ESP8266 | ESP-8266 | ESP-01 ESP8266 | ESP-01 ESP8266 | 1
RUEF400 | Fuse | F1 | RUEF400 | RUEF400 | 1
MF-MSMF110_16-2 | Fuse | F2 | FUSC4632X85N | MF-MSMF110_16-2 | 1
PJ-050B | PJ-050B | IN_2 | PJ-050B | PJ-050B | 1
DM3AT-SF-PEJM5 | Connector | J2 | DM3ATSFPEJM5 | DM3AT-SF-PEJM5 | 1
FPC-45P-0.5mm | Connector | J7 | FH12S45S05SH60 | FH12S-45S-0.5SH_55_ | 1
 | LCD-MODULE_3'2_480�320 | LCD-MODULE | LCD-MODULE-3.2-480-320 | LCD-MODULE_3'2_480�320 | 1
ESP-07S |  | M1 | ESP-07S | ESP-07S | 1
IRFR9024NPBF | IRFR9024NPBF | Q1 | ONSC-DPAK-3-369C-01_V | CMP-1058-00387-1 | 1
BSS123 | N-Channel Logic Level Enhancement Mode Field Effect Transistor, 1.7 V, -55 to 150 degC, 3-Pin SOT-23, RoHS, Tape and Reel | Q2 | FAIR-SOT23-3_V | CMP-2000-04934-1 | 1
ptv09a-4225f-b102 | Adjustable Resistor PTV09 | R1, R2 | PTV09 | PTV09 | 2
4.7k | RES_0805 | R3, R4, R5, R6, R7, R8, R9, R10, R11, R12, R13, R14, R15, R16, R17, R18, R19, R29, R30, R31, R32, R33, R34, R35, R36 | RES_0805 | RES_0805 | 25
3.3k | RES_0805 | R20, R21, R22 | RES_0805 | RES_0805 | 3
0 | RES_0805 | R23, R24, R25 | RES_0805 | RES_0805 | 3
30k | RES_0805 | R26, R27, R28 | RESC2013X60X40NL20T25 | CMP-2001-00626-1 | 3
PTS645SK50LFS | PTS645SK50LFS | S1, S2, S3, S4, S5, S6, S7, S8, S9, S10, S11, S12, S13, S14, S15, S16, S17, S18, S19, S20, S21, S22, S23 | PTS645SK50LFS | PTS645SK50LFS | 23
BNX016-01 | BNX016-01 | T1 | TRANSF_ICORE | TRANSF_ICORE | 1
MCP3008-I/SL | MCP3008-I/SL | U1, U2, U3 | MCP3008-I/SL | MCP3008-I/SL | 3

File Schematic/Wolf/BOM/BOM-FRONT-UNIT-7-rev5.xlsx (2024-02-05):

Comment | Description | Designator | Footprint | Quantity
0 | RES_0805 | R27, R28, R29 | RES_0805 | 3
0.1 |  | C12 | CH0805C | 1
1k | RES_0805 | R12, R13, R14, R15 | RES_0805 | 4
1n | CAP_1206 | C8 | CAP_1206 | 1
1n4148w | Diode | D2, D3 | SOD3716X135N | 2
1uF | CAP_1206 | C6 | CAP_1206 | 1
2k | RES_0805 | R17, R18, R19, R20 | RES_0805 | 4
3.3k | RES_0805 | R30, R31, R32 | RES_0805 | 3
3.3uH | IND_1812 | L2 | IND_1812 | 1
4.7k | RES_0805 | R1, R8, R9, R10, R11, R21, R22, R23, R24, R33, R34 | RES_0805 | 11
4.7uF 16V | CAPAE_6.6x6.6h5.4 | C2 | CAPAE_6.6x6.6h5.4 | 1
8.2n | CAP_1206 | C11 | CAPC2013X94X50LL20T25 | 1
10n | CAP_0805 | C17, C18 | CAP_0805 | 2
10uH | Inductor | L1 | IND_FERRITE_CORE | 1
15k | RES_0805 | R2 | RES_0805 | 1
22uF 10V | CAPAE_4.3x4.3h5.4 | C3 | CAPAE_4.3x4.3h5.4 | 1
22uF 10V | EEEFC_sizeB | C13 | EEEFC_sizeB | 1
30k | RES_0805 | R3, R4, R5 | RESC2013X60X40NL20T25 | 3
47k |  | R25 | CH0805R | 1
47k |  | R26 | CH0805C | 1
100 |  | R16 | CH0805R | 1
100n | CAP_0805 | C1, C4, C14, C15, C16 | CAP_0805 | 5
100n | CAP_1206 | C7 | CAP_1206 | 1
120p | CAP_1206 | C10 | CAP_1206 | 1
470p | CAP_1206 | C9 | CAP_1206 | 1
1000uF | CAP250RP | C5 | CAP250RP | 1
BNX016-01 | BNX016-01 | T1 | TRANSF_ICORE | 1
BSS123 | N-Channel Logic Level Enhancement Mode Field Effect Transistor, 1.7 V, -55 to 150 degC, 3-Pin SOT-23, RoHS, Tape and Reel | Q2 | FAIR-SOT23-3_V | 1
DM3AT-SF-PEJM5 | Connector | J2 | DM3ATSFPEJM5 | 1
ESP-01 ESP8266 | ESP-01 ESP8266 | ESP-1 | ESP-01 ESP8266 | 1
FPC-45P-0.5mm | Connector | J1 | FH12S45S05SH60 | 1
IRFR9024NPBF | IRFR9024NPBF, Транзистор, Р-канал 55В 11А | Q1 | ONSC-DPAK-3-369C-01_V | 1
JX2 | JX2 | IN1, MOTHERBOARD1, RF-UNIT1 | JX2 | 3
LCD-RA8875 | LCD-RA8875 | U1 | LCD-RA8875 | 1
MCP3008-I/SL | MCP3008-I/SL | U3 | MCP3008-I/SL | 1
MCP6001UT |  | U4, U5 | SOT23-5 | 2
MF-MSMF110_16-2 | Fuse | F2 | FUSC4632X85N | 1
MIC_OUT | 51022-0200 | MIC_OUT1 | 51022-0200 | 1
OPTICAL ENCODER | OPTICAL ENCODER | ENCODER_MAIN1 | 644456-4 | 1
PEC12 | PEC12 | ENC1 | PEC12 | 1
PJ-3,5 |  | J3, J4, J5 | Audio-PJ-392 | 3
PTS645SK50LFS | PTS645SK50LFS | S1, S2, S3, S4, S5, S6, S7, S8, S9, S10, S11, S12 | PTS645SK50LFS | 12
PTT |  | X1, X2 | CON: PLS-6 | 2
PTT_OUT | 51022-0200 | PTT_OUT1 | 51022-0200 | 1
ptv09a-4225f-b102 | Adjustable Resistor PTV09 | R6, R7 | PTV09 | 2
RUEF400 | Fuse | F1 | RUEF400 | 1
SM6T15A | Diode | D1 | SMBJ36CATR | 1
SMAJ5.0A-TR | Diode | D4 | SMBJ36CATR | 1
ST1S10 | ST1S10 | U2 | ST1S10 | 1

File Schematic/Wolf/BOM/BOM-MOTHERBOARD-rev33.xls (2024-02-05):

Comment | Description | Designator | Footprint | LibRef | Quantity | LCSC Part #
JX2 | JX2 | 13.8V + | JX2 | JX2 | 1
51022-0300_1 | 51022-0300 | A_OUT, MIC_IN2 | 51022-0200 - duplicate | 51022-0300_1 | 2
CR1220 + | BR1632A/FA | B1 | KLS5-CR1220-01 | BR1632A/FA | 1
 | 2 Pin | BOOT | 51022-0200 | 51022-0200 | 1
4.7uF 16V | CAPAE_6.6x6.6h5.4 | C1 | SMC | CAPAE_6.6x6.6h5.4 | 1
22uF 10V | CAPAE_4.3x4.3h5.4 | C2, C125, C126 | CAPAE_4.3x4.3h5.4 | CAPAE_4.3x4.3h5.4 | 3
100n | CAP_0805 | C3, C4, C5, C6, C9, C16, C19, C21, C23, C31, C44, C45, C46, C47, C48, C49, C51, C53, C56, C57, C58, C59, C61, C62, C65, C67, C69, C70, C71, C72, C73, C74, C76, C78, C79, C81, C82, C83, C84, C86, C87, C88, C89, C91, C93, C94, C95, C96, C97, C98, C99, C100, C107, C109, C110, C112, C113, C114, C115, C117, C118, C120, C123, C124, C135 | CAP_0805 | CAP_0805 | 65
1uF | CAP_0805 | C7, C11, C12, C13, C14, C15, C35, C92, C119, C121, C122, C1003, C1004 | CAP_0805 | CAP_0805 | 13
10uF 10V | CAPAE_4.3x4.3h5.4 | C8, C20, C22, C24, C32, C54, C60, C75, C77, C80, C85, C1002 | CAPAE_4.3x4.3h5.4 | CAPAE_4.3x4.3h5.4 | 12
470p | CAP_0805 | C10, C90, C104, C116 | CAP_0805 | CAP_0805 | 4
10uF 10V | CAP_0805 | C17 | CAP_0805 | CAP_0805 | 1
1uF 10V | CAPAE_4.3x4.3h5.4 | C25, C26, C29 | CAPAE_4.3x4.3h5.4 | CAPAE_4.3x4.3h5.4 | 3
220p | CAP_0805 | C27, C28, C30 | CAP_0805 | CAP_0805 | 3
220uF 10V | CAPAE_4.3x4.3h5.4 | C33, C34 | EEEFC_size� | CAPAE_4.3x4.3h5.4 | 2
100pF | CAP_0805 | C36 | CAP_0805 | CAP_0805 | 1
10n | CAP_0805 | C37, C63, C137 | CAP_0805 | CAP_0805 | 3
6pF | CAP_0805 | C38, C39 | CAP_0805 | CAP_0805 | 2
10uF | CAP_0805 | C40, C41, C50, C52, C64, C66, C68 | CAP_0805 | CAP_0805 | 7
22p | CAP_0805 | C42, C43 | CAP_0805 | CAP_0805 | 2
7.5p | CAP_0805 | C55 | CAP_0805 | CAP_0805 | 1
10uF 20V | CAPAE_4.3x4.3h5.4 | C101, C108 | CAPAE_4.3x4.3h5.4 | CAPAE_4.3x4.3h5.4 | 2
1uF | CAP_1206 | C102, C103 | CAP_1206 | CAP_1206 | 2
680p | CAP_1206 | C105, C106 | CAP_1206 | CAP_1206 | 2
10p | CAP_0805 | C127 | CAP_0805 | CAP_0805 | 1
8.2n | CAP_0805 | C136 | CAP_0805 | CAP_0805 | 1
1n | CAP_0805 | C1001 | CAP_0805 | CAP_0805 | 1
SMAJ5.0A-TR | Diode | D1, D3, D29, D30, D31, D34, D35, D36, D37, D38, D39, D40 | SMBJ36CATR | SMLVT3V3 | 12 | [NoParam], test
SS34 | Schottky Diode | D1001 | SMB | D Schottky | 1
Diode | Default Diode | D1002 | C1206 | Diode | 1
SJ1-3525NG | SJ1-3525NG | J1, J2, J3, J5 | SJ1-3525NG | SJ1-3523N | 4
RF-UNIT | 2*5 Pin | J4 | 90131-0126 | 90131-0126 | 1
FPC-45P-0.5mm | Connector | J6 | FH12S45S05SH60 | FH12S-45S-0.5SH_55_ | 1
FAN | 51022-0200 | J7 | 51022-0200 | 51022-0200 | 1
USB | 2-1734035-3 | J8 | 2-1734035-3 | 2-1734035-3 | 1
DAC_OUT | SMA | J9 | 31-5431 | 31-5431 | 1
ADC | SMA | J10 | 31-5431 | 31-5431 | 1
 | 2*5 Pin | JTAG_FPGA, JTAG_STM32 | IDC10 | IDC10 | 2
3.3uH | IND_1812 | L1, L9 | IND_1812 | IND_1812 | 2
BLM21 | BLM21 | L3, L8 | CAP_0805 | IND_FERRITE_BEAD | 2
22uH | IND_1206 | L7 | IND_7x7 | IND_1206 | 1
10uH | Inductor | L37, L1001 | IND_7x7 | IND_FERRITE_CORE | 2
10uH | IND_1812 | L1002 | IND_1812 | IND_1812 | 1
PTT_IN | 51022-0200 | PTT_IN | 51022-0200 | 51022-0200 | 1
2SC5103TLP | Transistor BJT NPN | Q1 | 2SC5103TLQ | 2SC5103TLP | 1
7.5k | RES_0805 | R1 | RES_0805 | RES_0805 | 1
39k | RES_0805 | R2 | RES_0805 | RES_0805 | 1
0/NONE | By used crystal | R3 | RES_0805 | RES_0805 | 1
NONE / 0 | RES_0805 | R4, R1001, R1002 | RES_0805 | RES_0805 | 3
5.6k | RES_0805 | R5, R6, R7, R9, R51 | RES_0805 | RES_0805 | 5
30k | RES_0805 | R8, R55 | RES_0805 | RES_0805 | 2
10k | RES_0805 | R10, R13, R24, R27, R28, R30, R31, R32, R33, R36, R37, R38, R39, R46, R47, R48, R56, R57 | RES_0805 | RES_0805 | 18
680 | RES_0805 | R11 | RES_0805 | RES_0805 | 1
47k | RES_0805 | R12, R14, R15, R45 | RES_0805 | RES_0805 | 4
1.5k | RES_0805 | R16, R66 | RES_0805 | RES_0805 | 2
1k | RES_0805 | R17, R18, R19, R25, R26, R49, R50, R52 | RES_0805 | RES_0805 | 8
130 | RES_0805 | R20, R21 | RES_0805 | RES_0805 | 2
82 | RES_0805 | R22, R23 | RES_0805 | RES_0805 | 2
1m | RES_0805 | R29 | RES_0805 | RES_0805 | 1
100 | RES_0805 | R34, R35 | RES_0805 | RES_0805 | 2
22 | RES_0805 | R40, R53, R54, R58 | RES_0805 | RES_0805 | 4
24 | RES_0805 | R41, R42, R43, R64, R65 | RES_0805 | RES_0805 | 5
200 | RES_0805 | R44 | RES_0805 | RES_0805 | 1
 | RES_0805 | R59, R60 | RES_0805 | RES_0805 | 2
330 | RES_0805 | R61 | RES_0805 | RES_0805 | 1
5.6 | RES_1206 | R62, R63 | RES_1206 | RES_1206 | 2
56 | RES_0805 | R67 | RES_0805 | RES_0805 | 1
10 | RES_0603 | R68, R69 | RES_0603 | RES_0603 | 2
Thermistor 20k | Thermistor | R70 | MF52A103F3950A1 | MF52A103F3950_A1_ | 1
ADJ-5k | 306J | R71 | 306J | 306J | 1
0 | RES_0805 | R1003 | RES_0805 | RES_0805 | 1
1:1+1 | Transformer | T3 | TRANSF_ACORE2 | TRANSF_ACORE2 | 1
1:4 ADT4-6T | Transformer | T4 | TRANSF_ACORE2 | TRANSF_ACORE2 | 1
1:1 | Transformer | T6 | TRANSF_ACORE | TRANSF_ACORE | 1
PAM8406 | PAM8406 | U1 | PAM8403 | PAM8406 | 1
LD3985 | LD3985 | U2 | LD3985 | LD3985 | 1
ST1S10 | ST1S10 | U3 | ST1S10 | ST1S10 | 1
WM8731 | WM8731 | U4 | WM8731 | WM8731 | 1
STM32H743VIT6-rev.V | STM32H743VIT6 | U5 | STM32H743VIT6 | STM32H743VIT6 | 1
LM1084IS-3.3 | LM1084IS-3.3 | U6 | LM1085-3.3 | LM1085-3.3 | 1
W25Q16 | W25Q16 | U7 | W25Q16 | W25Q16 | 1
DAC5674 | Integrated Circuit | U8 | QFP50P900X900X100-49N | DAC5674IPHP | 1
25P80 | 25P80 | U9 | 25P80 | 25P80 | 1
EP4CE22E22C8N | EP4CE22E22C8N | U10 | QFP144-20-2222A | EP4CE22E22C8N | 1
1117DT-2.5 | LD1117DT-2.5 DPAK | U11 | TO228P991X238-3N | LM1117DT-ADJ | 1
1117DT-1.2 | LD1117DT-1.2 DPAK | U12 | TO228P991X238-3N | LM1117DT-ADJ | 1
1117-3.3 | LT1117CST-3.3 | U13 | LT1117CST-3.3 | LT1117CST-3.3 | 1
1117-1.8 | LT1117CST-1.8 | U14 | LT1117CST-3.3 | LT1117CST-3.3 | 1
SPEAKER | 4 pins conn | U15 | speaker conn | speaker conn | 1
LTC2208CUP | LTC2208CUP | U16 | LTC2208CUP | LTC2208CUP | 1
LTC6400IUD | Single Channel, Low Noise, Low Distortion Differential ADC Driver for 300 MHz IF, 1800 MHz Typical GBW, 4500 V/us Typical SR, 2.85 to 3.5 V, 16-Pin QFN (UD-16), Industrial, Pb-Free | U17 | LT-UD-16_N | CMP-0359-03855-2 | 1
1117DT-3.3 | LD1117DT33 DPAK | U18 | TO228P991X238-3N | LM1117DT-ADJ | 1
ADUM4160 | Integrated Circuit | U19 | SOIC127P1032X265-16N | ADUM4160BRWZ | 1
OPA2673 | Integrated Circuit | U20 | QFN65P400X400X100-17N-D | OPA2673IRGVT | 1
LM2940S-12/NOPB | 1-A, 26-V, high-PSRR, low-dropout voltage regulator | U21 | TO254P1524X483-4N | LM2940S-12/NOPB | 1
122.88Mhz | NV7050SA VG-4513CA-122.8800M-GGCT3 | XG1 | NV7050SA | NV7050SA | 1
12.288Mhz TCXO 3.3v TTL/CMOS (set other freq in fpga code) | Crystal or Oscillator | XG2 | 581L200X2ITT | 581L200X2ITT | 1
ABS25-32.768KHZ-6-T | Crystal or Oscillator | Y1 | ABS25 | ABS25-32.768KHZ-6-T | 1
8mhz | ECS-200-20-1 | Y2 | ECS-200-20-1 | ECS-200-20-1 | 1

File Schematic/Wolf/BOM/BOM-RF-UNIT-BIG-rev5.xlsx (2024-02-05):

Comment | Description | Designator | Footprint | Quantity
 | Capacitor NP0 HiVolt | C96, C97, C98, C99, C100 | CAP_1206 | 5
0 | RES_0805 | R49, R50, R65, R67 | RES_0805 | 4
0.1uH | Inductor | L35 | IND_FERRITE_CORE_1 | 1
0.22uH | Inductor | L36 | IND_FERRITE_CORE_1 | 1
0.45uH | Inductor | L39 | IND_FERRITE_CORE_1 | 1
1:1 | 1:1 | T5 | TRANSF_ACORE2 | 1
1k | RES_0805 | R5, R6, R35, R42, R43, R64, R68 | RES_0805 | 7
1k | RES_0805 | R31, R33, R57, R69, R70, R71, R72 | RESC2013X60X40NL20T25 | 7
1n | CAP_0805 | C112, C115, C120 | CAP_0805 | 3
1n | CAP_0805 | C122 | 6-0805_M | 1
1n | CAP_1206 | C94, C104 | CAP_1206 | 2
1n8 | CAP_1206 | C105 | CAP_1206 | 1
1N4148 | 1N4148 | D4, D5, D6, D8, D9, D10, D11, D12, D13, D14, D15, D16, D17, D19, D20, D21, D22, D24, D25, D26, D27, D28, D29, D30, D31, D32, D38, D39, D40, D41, D42, D43, D44, D45, D46, D47, D48 | SS14 | 37
1uF | CAP_0805 | C62, C63, C79, C83, C126, C128 | CAP_0805 | 6
1uH | Inductor | L7, L8, L9, L41 | IND_FERRITE_CORE_1 | 4
1.2k | RES_0805 | R53 | RES_0805 | 1
1.2n 500V | CAP_1206 | C57 | CAP_1206 | 1
1.6uH | Inductor | L13, L14, L15, L16, L17, L18 | IND_FERRITE_CORE_1 | 6
2k | RES_0805 | R13 | RES_0805 | 1
2p | Capacitor NP0 HiVolt | C2, C3 | CAP_1206 | 2
2.2k | RES_0805 | R77, R78 | RES_0805 | 2
2.2n | Capacitor NP0 HiVolt | C48, C49 | CAP_1206 | 2
2.2p | Capacitor NP0 HiVolt | C7, C8 | CAP_1206 | 2
2.2uF | CAP_1206 | C95 | CAP_1206 | 1
2.2uH | Inductor | L42 | IND_FERRITE_CORE_1 | 1
2.7k | RES_0805 | R37 | RES_0805 | 1
2.7uH | Inductor | L19, L20, L21 | IND_FERRITE_CORE_1 | 3
4.7 | RES_1206 | R38, R47, R74, R76 | RES_1206 | 4
4.7n | CAP_0805 | C70, C75 | CAP_0805 | 2
4.7n | Capacitor NP0 HiVolt, CAP_1206 | C50, C53, C54 | CAP_1206 | 3
5p | Capacitor NP0 HiVolt | C4, C5, C6 | CAP_1206 | 3
5.1p | Capacitor NP0 HiVolt | C12, C13 | CAP_1206 | 2
6.5-30p | TZC3P300A110 | C65, C66 | 5025[2010] | 2
6.8k | RES_0805 | R32 | RES_0805 | 1
6.8n | Capacitor NP0 HiVolt | C1, C51 | CAP_1206 | 2
6.8uH | Inductor | L22, L23, L24 | IND_FERRITE_CORE_1 | 3
8.2nH | IND_0805 | L32, L33, L34 | IND_0805 | 3
10k | RES_1206 | R73 | RES_1206 | 1
10n | CAP_0805 | C121 | 6-0805_M | 1
10n | CAP_1206 | C69, C92, C102 | CAP_1206 | 3
10p | Capacitor | C84 | B32620A0682J000 | 1
10p | Capacitor NP0 HiVolt | C10 | CAP_1206 | 1
10uF 25V | CAPAE_5.3x5.3h6.1 | C129 | CAPAE_5.3x5.3h6.1 | 1
10uH | Inductor | L30, L43 | IND_FERRITE_CORE | 2
11uH | Inductor | L25, L26, L27 | IND_FERRITE_CORE_1 | 3
12p | Capacitor NP0 HiVolt | C9, C11 | CAP_1206 | 2
13.8V | JX2 | J8 | 1986717-2 | 1
15n | CAP_1206 | C81, C111 | CAP_1206 | 2
18 | RES_1206 | R39 | RES_1206 | 1
20 | RES_1206 | R23, R61 | RES_1206 | 2
22 2W | CFR200J100R | R1, R2 | RES-2W | 2
22nH | IND_0805 | L48 | IND_0805 | 1
22p | Capacitor | C85 | B32620A0682J000 | 1
22p | Capacitor NP0 HiVolt | C14, C15, C16, C17, C18, C22, C23 | CAP_1206 | 7
22uF | CAPAE_6.6x6.6h5.4 | C74, C77 | CAPAE_6.6x6.6h5.4 | 2
27pF | CAP_0805 | C55 | CAP_0805 | 1
30k | RES_0805 | R4, R41, R45, R48, R75 | RES_0805 | 5
33p | Capacitor NP0 HiVolt | C20 | CAP_1206 | 1
39p | Capacitor NP0 HiVolt | C19, C21 | CAP_1206 | 2
47p | Capacitor | C86 | B32620A0682J000 | 1
47p | Capacitor NP0 HiVolt | C25 | CAP_1206 | 1
47uF 25V | CAPAE_6.6x6.6h5.4 | C119 | CAPAE_6.6x6.6h5.4 | 1
50 | RES_1206 | R55, R56 | RES_1206 | 2
56 | RES_0805 | R15, R16, R26, R27, R44 | RES_0805 | 5
56p | Capacitor NP0 HiVolt | C24, C26, C27, C28, C32, C33 | CAP_1206 | 6
82p | Capacitor NP0 HiVolt | C30, C37, C39 | CAP_1206 | 3
100 | RES_0805 | R28, R29, R51 | RES_0805 | 3
100 | RES_1206 | R34 | RES_1206 | 1
100n | CAP_0805 | C38, C59, C64, C67, C71, C76, C78, C80, C82, C89, C90, C107, C108, C109, C110, C113, C114, C116, C117, C118, C123, C124, C125, C130, C133, C134, C135, C136, C137, C138, C139, C140, C141, C142, C143, C144, C145, C146, C147, C148, C149, C150, C151, C152, C153, C154, C155, C156, C157, C158, C159, C160, C161, C162, C163, C164, C165, C166, C167, C168, C169, C170, C171 | CAP_0805 | 63
100n | CAP_0805 | C131 | 6-0805_M | 1
100n | CAP_1206 | C58, C61, C106 | CAP_1206 | 3
100p | CAP_0805 | C72 | CAP_0805 | 1
100p | CAP_0805 | C127, C132 | 6-0805_M | 2
100p | Capacitor | C87 | B32620A0682J000 | 1
100p | Capacitor NP0 HiVolt, CAP_1206 | C29, C31, C91, C93, C103 | CAP_1206 | 5
100pF 500V | CAP_1206 | C52, C56 | CAP_1206 | 2
120p | CAP_0805 | C68, C73 | CAP_0805 | 2
120p | Capacitor NP0 HiVolt | C35 | CAP_1206 | 1
150p | Capacitor NP0 HiVolt | C34, C36 | CAP_1206 | 2
158uH | Inductor | L28, L29, L40 | IND_FERRITE_CORE_1 | 3
180p | Capacitor NP0 HiVolt | C41, C43, C44 | CAP_1206 | 3
200 | RES_0805 | R52 | RES_0805 | 1
200nH | Inductor | L1, L2, L3 | IND_FERRITE_CORE_1 | 3
200p | CAP_1206 | C101 | CAP_1206 | 1
200pF 500V | CAP_1206 | C60 | CAP_1206 | 1
220nH | IND_1206 | L31, L46 | IND_1206 | 2
220p | Capacitor | C88 | B32620A0682J000 | 1
220p | Capacitor NP0 HiVolt | C40, C42 | CAP_1206 | 2
300 | RES_1206 | R24, R25, R62, R63 | RES_1206 | 4
390p | Capacitor NP0 HiVolt | C46 | CAP_1206 | 1
430 | RES_1206 | R59, R60 | RES_1206 | 2
470 | RES_1206 | R22 | RES_1206 | 1
470p | Capacitor NP0 HiVolt | C45, C47 | CAP_1206 | 2
510 | RES_0805 | R36, R54 | RES_0805 | 2
560 | RES_0805 | R3, R7, R8, R9, R10, R11, R12 | RES_0805 | 7
620 | RES_0805 | R58 | RES_0805 | 1
680nH | Inductor | L4, L5, L6 | IND_FERRITE_CORE_1 | 3
750 | RES_1206 | R21 | RES_1206 | 1
820nH | Inductor | L10, L11, L12 | IND_FERRITE_CORE_1 | 3
2027-07-SM-RPLF | Undefined or Miscellaneous | U13 | 200307SMRPLF | 1
51022-0200 | 51022-0200 | FAN_OUT | 51022-0200 | 1
ADC | SMA | J2 | 31-5431 | 1
ADG918BRMZ | Integrated Circuit | U8, U10 | SOP65P490X110-8N | 2
ADJ-1k | 306J | R30, R40, R46 | 306J | 3
ADJ-10k | 3296W-1-103LF | R19, R20 | 3296W-1 | 2
ADJ-100 | 306J | R66 | 306J | 1
ANT1 | SMA | J1 | 31-5431 | 1
ANT2 | SMA | J5 | 31-5431 | 1
Axicom IM06 | Axicom IM06 | U4, U12 | IM06GR | 2
BAT46JFILM | Diode | D1, D3, D49, D50 | SOD2513X117N | 4
BAV99 | BAV99 | D7 | SOT23 | 1
BLM21 | BLM21 | FB1 | IND_0805 | 2
BSS123 | N-Channel Logic Level Enhancement Mode Field Effect Transistor, 1.7 V, -55 to 150 degC, 3-Pin SOT-23, RoHS, Tape and Reel | Q12 | FAIR-SOT23-3_V | 1
DAC | SMA | J9 | 31-5431 | 1
EXTERNAL | 2*5 PIN | J3 | 90131-0126 | 1
G6S-2-DC12 | Relay or Contactor | K1, K2, K3, K4, K5, K6, K7, K8, K9, K10, K11, K12, K13, K14, K15, K16, K17, K18, K19, K20, K21, K22, K23, K24, K25, K26, K27, K28, K29, K30, K31, K32, K33, K34, K35 | G6S2DC12 | 35
HiCurrent 13.8V | JX2 | J6, J7 | 1986717-2 | 2
IRLML9301 | MOSFET | Q2, Q7, Q10, Q11 | SOT23 | 4
KTY81/120 | Integrated Circuit | R14 | TO254P420X460X770-2P | 1
LM1117DT-5.0 | Integrated Circuit | U6 | TO228P991X238-3N | 1
LT1117IST-5.0 | LT1117IST-5.0 | U19 | LT1117IST-ADJ | 1
LT1117IST-ADJ | LT1117IST-ADJ | U5, U20 | LT1117IST-ADJ | 2
MOTHERBOARD | 2*5 PIN | J4 | 90131-0126 | 1
PE4302 | Integrated Circuit | U9 | QFN50P400X400X90-21N | 1
PGA-103+ / SPF5189Z | PGA-103+ / SPF5189Z | Q4 | SOT89 | 1
RA80H1415M1 | RA80H1415M1 | Q8 | RA80H1415M1 | 1
RD01MUS1 | RD01MUS1 | Q9 | SOT89 | 1
RD16HHF1 | RD16HHF1 | Q1, Q3 | RD16_V2 | 2
RD100HHF1 | RD100HHF1 | Q5, Q6 | RD100_V2 | 2
SMAJ5.0A-TR | Diode | D2 | SMBJ36CATR | 1
SS14 | SS14 | D18, D23, D35, D36, D37 | SS14 | 5
STPIC6C595TTR | Integrated Circuit | U1, U2, U3, U7, U11 | SOP65P640X120-16N | 5
SWR_TANDEM_MATCH | SWR_TANDEM_MATCH | TSWR | SWR_TANDEM_MATCH | 1
SWR_VHF | SWR_VHF | T6 | SWR_VHF | 1
TRANSF_HF1 | TRANSF_HF1 | T2 | TRANSF_HF1 | 1
TRANSF_HF2 | TRANSF_HF2 | T1 | TRANSF_HF2-3 | 1
TRANSF_HF3 | TRANSF_HF3 | T3 | TRANSF_HF3 | 1

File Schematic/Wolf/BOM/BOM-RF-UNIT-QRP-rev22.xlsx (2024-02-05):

Comment | Description | Designator | Footprint | Quantity
0 | RES_0805 | R49, R50 | RES_0805 | 2
0 | RES_1206 | R34, R38 | RES_1206 | 2
1:1 | 1:1 | T5 | TRANSF_ACORE2 | 1
1k | RES_0805 | R28, R29, R35, R42, R43 | RES_0805 | 5
1k | RES_0805 | R31, R65, R71, R72, R73, R74, R75, R76, R77, R78, R79, R80, R81, R82, R83, R84, R85 | RESC2013X60X40NL20T25 | 17
1n | CAP_0805 | C47, C112, C115, C120 | CAP_0805 | 4
1n | CAP_0805 | C122 | 6-0805_M | 1
1n8 | CAP_1206 | C105 | CAP_1206 | 1
1n8 100V | CAP_1206 | C92, C94 | CAP_1206 | 2
1N4148 | 1N4148 | D4 | 1N4148 | 1
1uF | CAP_0805 | C126, C128 | CAP_0805 | 2
1uH | IND_0805 | L17 | IND_0805 | 1
1.1n | CAP_0805 | C72, C74 | CAP_0805 | 2
1.2k | RES_0805 | R53 | RES_0805 | 1
1.2n | CAP_0805 | C62 | CAP_0805 | 1
1.3n | CAP_0805 | C61 | CAP_0805 | 1
1.3uH | IND_0805 | L18 | IND_0805 | 1
1.5uH | IND_0805 | L14, L25 | IND_0805 | 2
1.6uH | IND_0805 | L26 | IND_0805 | 1
2k | RES_0805 | R13 | RESC2013X60X40NL20T25 | 1
2uH | IND_0805 | L19, L22, L39, L47 | IND_0805 | 4
2.2uF | CAP_1206 | C95 | CAP_1206 | 1
2.2uF 100V | CAP_1206 | C91, C93 | CAP_1206 | 2
2.2uH | IND_0805 | L30 | IND_0805 | 1
2.4uH | IND_0805 | L31 | IND_0805 | 1
2.7uH | IND_0805 | L23, L27 | IND_0805 | 2
3n | CAP_0805 | C76 | CAP_0805 | 1
3.3n | CAP_0805 | C75 | CAP_0805 | 1
3.6uH | IND_0805 | L28 | IND_0805 | 1
4.3uH | IND_0805 | L24 | IND_0805 | 1
6.2uH | IND_0805 | L29 | IND_0805 | 1
6.5-30p | TZC3P300A110 | C86, C87 | 5025[2010] | 2
6.8uH | IND_0805 | L32 | IND_0805 | 1
8p | CAP_0805 | C16, C19 | CAP_0805 | 2
8T M2000HM 10*6*5 | Transformer | T1 | Rutrof 2 | 1
8T M2000HM 10*6*5 | Transformer | T3 | Rutrof | 1
8.2nH | IND_0805 | L34, L35, L36 | IND_0805 | 3
9.1uH | IND_0805 | L33 | IND_0805 | 1
10k | RES_0805 | R37 | RESC2013X60X40NL20T25 | 1
10k | RES_1206 | R1 | RES_1206 | 1
10n | CAP_0805 | C121 | 6-0805_M | 1
10uF 25V | CAPAE_5.3x5.3h6.1 | C129 | CAPAE_5.3x5.3h6.1 | 1
10uH | Inductor | L37, L38, L43 | IND_FERRITE_CORE | 3
11p | CAP_0805 | C103 | CAP_0805 | 1
15p | CAP_0805 | C18 | CAP_0805 | 1
15pF | CAP_0805 | C17 | CAP_0805 | 1
18 | RES_1206 | R39 | RES_1206 | 1
20p | CAP_1206 | C123, C125 | CAP_1206 | 2
22nH | IND_0805 | L48, L49, L51 | IND_0805 | 3
27nH | IND_0805 | L50 | IND_0805 | 1
27p | CAP_0805 | C55, C104 | CAP_0805 | 2
30k | RES_0805 | R33, R45, R70 | RESC2013X60X40NL20T25 | 3
30k | RES_0805 | R41, R57 | RES_0805 | 2
33p | CAP_0805 | C6 | CAP_0805 | 1
36p | CAP_1206 | C124 | CAP_1206 | 1
43p | CAP_0805 | C101 | CAP_0805 | 1
47p | CAP_0805 | C5, C13, C110 | CAP_0805 | 3
47uF 25V | CAPAE_6.6x6.6h5.4 | C119 | CAPAE_6.6x6.6h5.4 | 1
50 | RES_1206 | R55, R56 | RES_1206 | 2
56 | RES_0805 | R27, R44 | RES_0805 | 2
56p | CAP_0805 | C107 | CAP_0805 | 1
62p | CAP_0805 | C12, C102 | CAP_0805 | 2
68nH | Inductor | L44, L45 | IND_FERRITE_CORE_1 | 2
68p | CAP_0805 | C108 | CAP_0805 | 1
82p | CAP_0805 | C11 | CAP_0805 | 1
91nH | IND_0805 | L2, L41 | IND_0805 | 2
100n | CAP_0805 | C1, C2, C3, C4, C38, C80, C113, C114, C116, C117, C118, C130, C133, C134, C135, C136, C137, C139, C140, C141, C142 | CAP_0805 | 21
100n | CAP_0805 | C131 | 6-0805_M | 1
100n | CAP_1206 | C81, C111 | CAP_1206 | 2
100nH | IND_0805 | L3, L40 | IND_0805 | 2
100p | CAP_0805 | C9 | CAP_0805 | 1
100p | CAP_0805 | C127, C132 | 6-0805_M | 2
110p | CAP_0805 | C8, C10, C22, C89 | CAP_0805 | 4
120 | RES_0805 | R32, R46 | RES_0805 | 2
120p | CAP_0805 | C15, C21 | CAP_0805 | 2
130p | CAP_0805 | C14, C88, C90 | CAP_0805 | 3
160nH | IND_0805 | L5, L42 | IND_0805 | 2
160p | CAP_0805 | C20 | CAP_0805 | 1
180nH | IND_0805 | L6, L53, L54 | IND_0805 | 3
180p | CAP_0805 | C33, C34 | CAP_0805 | 2
200 | RES_0805 | R52 | RES_0805 | 1
220nH | IND_1206 | L46 | IND_1206 | 1
240p | CAP_0805 | C32 | CAP_0805 | 1
270nH | IND_0805 | L1, L7 | IND_0805 | 2
270p | CAP_0805 | C24, C45 | CAP_0805 | 2
300 | RES_1206 | R47, R48 | RES_1206 | 2
300p | CAP_0805 | C23 | CAP_0805 | 1
330nH | IND_0805 | L10, L52, L55 | IND_0805 | 3
330p | CAP_0805 | C44 | CAP_0805 | 1
360nH | IND_0805 | L8, L11 | IND_0805 | 2
360p | CAP_0805 | C46 | CAP_0805 | 1
470nH | IND_0805 | L4, L15 | IND_0805 | 2
470p | CAP_0805 | C36, C60 | CAP_0805 | 2
510 | RES_0805 | R36, R54 | RES_0805 | 2
510p | CAP_0805 | C35 | CAP_0805 | 1
560 | RES_0805 | R3, R7, R8, R9, R10, R11, R12 | RES_0805 | 7
560nH | IND_0805 | L16 | IND_0805 | 1
560p | CAP_0805 | C59 | CAP_0805 | 1
620nH | IND_0805 | L12 | IND_0805 | 1
680nH | IND_0805 | L20 | IND_0805 | 1
750nH | IND_0805 | L21 | IND_0805 | 1
750p | CAP_0805 | C58 | CAP_0805 | 1
820nH | IND_0805 | L13 | IND_0805 | 1
820p | CAP_0805 | C73 | CAP_0805 | 1
910nH | IND_0805 | L9 | IND_0805 | 1
910p | CAP_0805 | C48 | CAP_0805 | 1
2027-07-SM-RPLF | 2027-07-SM-RPLF | U18 | 200307SMRPLF | 1
51022-0200 | 51022-0200 | AMP1_PWR, AMP2_PWR, FAN_OUT | 51022-0200 | 3
ADC | SMA | J2 | 31-5431 | 1
ADG904BRUZ-R | Integrated Circuit | U4, U15, U16, U17 | SOP65P640X120-20N | 4
ADG918BRMZ | Integrated Circuit | U8, U10, U11, U12, U13, U14 | SOP65P490X110-8N | 6
ADJ-1k | 306J | R30, R40 | 306J | 2
ANT1 | SMA | J1 | 31-5431 | 1
ANT2 | SMA | J5 | 31-5431 | 1
Axicom V23079 | Axicom V23079 | K1 | V23079 | 1
BAT46JFILM | Diode | D1, D3 | SOD2513X117N | 2
BAV99 | BAV99 | D24 | SOT23 | 1
BSS123 | N-Channel Logic Level Enhancement Mode Field Effect Transistor, 1.7 V, -55 to 150 degC, 3-Pin SOT-23, RoHS, Tape and Reel | Q6, Q7, Q8 | FAIR-SOT23-3_V | 3
DAC | SMA | J9 | 31-5431 | 1
EXTERNAL | 2*5 PIN | J3 | 90131-0126 | 1
IRLML9301 | MOSFET | Q2, Q5 | SOT23 | 2
JX2 | JX2 | J8 | 1986717-2 | 1
KTY81/120 | Integrated Circuit | R14 | TO254P420X460X770-2P | 1
LM1117DT-5.0 | Integrated Circuit | U6 | TO228P991X238-3N | 1
LT1117IST-ADJ | LT1117IST-ADJ | U5 | LT1117IST-ADJ | 1
MOTHERBOARD | 2*5 PIN | J4 | 90131-0126 | 1
PE4312 | Integrated Circuit | U9 | QFN50P400X400X90-21N | 1
PGA-103+ / SPF5189Z | PGA-103+ / SPF5189Z | Q4 | SOT89 | 1
RD07MVS1 | RD07MVS1 | Q1, Q3 | RD07MVS1 | 2
SMAJ5.0A-TR | Diode | D2 | SMBJ36CATR | 1
SN74HC595D | 8-Bit Shift Registers With 3-State Output Registers, D0016A, TUBE | U1, U3, U7 | D0016A_L | 3
SS14 | SS14 | D18, D23 | SS14 | 2
SWR_TANDEM_MATCH | SWR_TANDEM_MATCH | TSWR | SWR_TANDEM_MATCH | 1
TRANSF_OUT | TRANSF_OUT | T4 | TRANSF_OUT | 1
ULN2003BDR | ULN2003BDR | U2 | ULN2003BDR | 1

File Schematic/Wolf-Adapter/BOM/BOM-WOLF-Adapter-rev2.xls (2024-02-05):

Comment | Description | Designator | Footprint | Quantity
"1.2Ghz" | RF | J8 | CON: SMA | 1
"5.6Ghz" | RF | J9 | CON: SMA | 1
"10Ghz" | RF | J10 | CON: SMA | 1
"144Mhz" | RF | J6 | CON: SMA | 1
"430Mhz" | RF | J7 | CON: SMA | 1
"OUTPUTS_1" |  | J3 | CON: PLD-10 | 1
"OUTPUTS_2" |  | J4 | CON: PLD-10 | 1
"PTT" |  | J5 | CON: PLD-10 | 1
"PTT" |  | X1 | CON: PLS-5 | 1
"TRX" |  | J1 | CON: PLD-10 | 1
"TRX_VHF" | RF | J2 | CON: SMA | 1
0.1u |  | C2, C4 | CH0805C | 2
1k |  | R1, R2, R3, R4 | CH0805R | 4
1N4148 |  | VD1, VD2, VD3, VD4, VD5, VD6, VD7, VD8, VD9, VD10, VD11, VD12, VD13, VD14, VD15, VD16, VD17, VD18, VD19, VD20 | 1N4148 | 20
10k |  | R6 | CH0805R | 1
10uF |  | C1, C3 | TANTAL_B | 2
30k |  | R5 | CH0805R | 1
74HC4514D |  | IC1 | 24-SOIC (W) | 1
100n |  | C5, C6, C7, C8, C9, C10, C11, C12, C13, C14 | CH0805C | 10
BSS123 |  | VT2 | SOT23_132 | 1
G6S-2-D?12 |  | K1, K2, K3, K4, K5, K6, K7, K8, K9, K10 | G6S-2-DC12 | 10
IRLML9301 |  | VT1 | SOT23_132 | 1
LM1117DT-5-5.0 |  | U1 | SOT223 | 1
ULN2803AFWG |  | IC2, IC3 | 18-SOIC (W) | 2

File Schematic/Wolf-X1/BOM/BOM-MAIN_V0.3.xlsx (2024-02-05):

Посадочное место | Номинал | Количество | Footprint
MicroSD1 | DM3AT-SF-PEJM5 | 1 | Micro SD - M
B1 батарейка | CR1220 | 1 | CR1220
C1 | 7.5p | 1 | CH0603C
C2, C3 | 22p | 2 | CH0603C
C4, C7, C30, C33, C38, C39, C40, C44, C45, C46, C47, C62, C63, C64, C66, C118, C154, C176, C177, C181, C182, C184, C190, C193 | 0.1u | 24 | CH0603C
C5, C6 | 2u2 | 2 | CH0603C
C8, C37, C85, C155, C157, C164 | 10u | 6 | CH0603C
C9, C10 | 6p | 2 | CH0603C
C11, C12, C13, C14, C15, C16, C17, C18, C19, C20, C21, C22, C23, C24, C25, C26, C27, C28, C29, C54, C55, C56, C67, C76, C79, C80, C82, C83, C84, C86, C88, C89, C90, C91, C92, C93, C94, C95, C96, C97, C98, C101, C102, C103, C105, C108, C110, C112, C114, C115, C116, C117, C120, C122, C123, C124, C125, C126, C127, C128, C129, C130, C131, C132, C133, C183, C187, C207, C208 | 0.1 | 69 | CH0603C
C31, C32, C178, C179, C180 | 10uF10V | 5 | TANTAL_A
C34, C36, C41, C42, C73, C74, C191, C195, C198 | 1u | 9 | CH0603C
C35, C77, C185, C189 | 470p | 4 | CH0603C
C43 | 10p | 1 | CH0603C
C48, C49, C99 | 1n | 3 | CH0603C
C50, C51, C52 | 1uF | 3 | CH0603C
C53, C57, C58 | 220uF | 3 | POLIMER-E
C59, C60, C61, C65 | 10uF10V | 4 | TANTAL_A
C68, C70, C71 | 1uF 10V | 3 | TANTAL_A
C69, C78 | 10n | 2 | CH0603C
C72, C140, C148 | 220p | 3 | CH0603C
C75 | 10uF 10V | 1 | TANTAL_A
C81, C111 | 8.2n | 2 | CH0603C
C87, C221 | 8p | 2 | CH0603C
C100, C107 | 10uF 10V | 2 | TANTAL_B
C104, C137, C153, C220 | 110p | 4 | CH0603C
C106, C212 | 15p | 2 | CH0603C
C109 | 4.7uF 47V | 1 | POLIMER-E
C113 | 22uF 10V | 1 | POLIMER-E
C119, C204 | 120p | 2 | CH0603C
C121, C145, C201, C211 | 100p | 4 | CH0603C
C134, C138, C142, C146, C150 | 180p | 5 | CH0603C
C135, C151 | 51p | 2 | CH0603C
C136, C152 | 390p | 2 | CH0603C
C139, C147 | 43p | 2 | CH0603C
C141, C149 | 91p | 2 | CH0603C
C143, C199 | 47p | 2 | CH0603C
C144 | 330p | 1 | CH0603C
C156, C165, C172, C202 | 33p | 4 | CH0603C
C158, C174 | 39p | 2 | CH0603C
C159, C168 | 20p | 2 | CH0603C
C160, C162, C166, C214 | 22uf | 4 | CH1206C
C161, C170 | 24p | 2 | CH0603C
C163 | 27p | 1 | CH0603C
C167, C169, C171 | 4.7uF | 3 | TANTAL_A
C173, C175, C192, C194 | 6.8n | 4 | CH0603C
C186 | 10n/none | 1 | CH0603C
C188 | 2.7n | 1 | CH0603C
C196, C197 | 680p | 2 | CH0603C
C200, C203 | 6.5-30pF | 2 | C_trimer
FB1, FB2, FB3 | Ferrite_Bead | 3 | CH0805L
FB4, FB5, L2 | BLM21 | 3 | CH0805L
J1 | BOOT | 1 | CON: PLS-2
J2, J4, J5 | PJ-307 | 3 | PJ-307
L1 | 22uH | 1 | 4020
L3, L44 | 330nH | 2 | L1210
L4, L43 | 22nH | 2 | L1210
L5 | 3.3uH | 1 | IND: CDRH74
L6 | 10uH | 1 | IND: CDRH74
L7, L11, L15 | 6.2uH | 3 | L1210
L8, L12, L16 | 2.2uH | 3 | L1210
L9, L13, L17 | 12uH | 3 | L1210
L10, L14, L18 | 3.3uH | 3 | L1210
L19, L24, L28 | 0.68uH | 3 | L1210
L20, L22, L23, L37 | 2.2uH | 4 | 4020
L21, L26, L30 | 1.2uH | 3 | L1210
L31 | 270nH | 1 | L1210
L32, L34, L36 | 8.2nH | 3 | L1210
L33 | 82nH | 1 | L1210
L35 | 100nH | 1 | L1210
L40, L42 | 180nH | 2 | L1210
L41 | 27nH | 1 | L1210
R1, R2, R3, R7, R11, R13, R14, R15, R16, R23, R24, R25, R33, R42, R65, R70, R73, R87, R88 | 10k | 19 | CH0603R
R4, R48 | 11k | 2 | CH0603R
R5, R6, R9, R51, R75, R77 | 22 | 6 | CH0603R
R8, R27, R28 | 3.3К | 3 | CH0603R
R10, R12, R32, R66, R67, R68, R69, R71, R74 | 1k | 9 | CH0603R
R17 | 1.5k | 1 | CH0603R
R18, R78 | 56 | 2 | CH0603R
R19, R20 | 10 | 2 | CH0603R
R21, R22, R54, R80, R81 | 100 | 5 | CH0603R
R26 | 680 | 1 | CH0603R
R29, R30, R31, R36, R55, R56 | 47K | 6 | CH0603R
R34, R35 | none | 2 | CH0603R
R37 | 5.6k | 1 | CH0603R
R38, R39 | 82 | 2 | CH0603R
R40, R41 | 130 | 2 | CH0603R
R43 | 120k +100k parallel | 1 | CH0603R
R44, R45, R46 | 30k | 3 | CH0603R
R47, R49 | 2K | 2 | CH0603R
R50, R53 | 0 | 2 | CH0603R
R52 | 18k | 1 | CH0603R
R57, R58 |  | 2 | CH0603R
R72 | 1k5 | 1 | CH0603R
R82, R83, R84 | 330 | 3 | CH0603R
R85, R86 | 5.6 | 2 | CH0603R
T1 | 1:4 ADT4-6T | 1 | TC4-1-ADT4-6
T2 | 1:1 T1-6T | 1 | TC4-1-ADT4-6
T3 | 1:1 ADT1-1 | 1 | TC4-1-ADT4-6
U1 | W25Q16 | 1 | SOIC-8-1
U2 | STM32H743 | 1 | 100-LQFP
U3 | M25P80 | 1 | SOIC-8-1
U4 | EP4CE22E22C8N | 1 | 144-QFN
U5, U13 | LM1085-3.3 | 2 | DPAK_132
U6 | LTC6400IUD | 1 | 16-QFN 3x3
U7 | LTC2208CUP | 1 | 64-QFN 9x9
U8 | PAM8406 | 1 | SOP-16
U9 | WM8731 | 1 | 28-SSOP
U10 | LD3985M33R | 1 | SOT23-5
U11 | ACS712-20 | 1 | 8-SOIC
U12, U18 | ADG918BRMZ | 2 | 8-MSOP (NO PAD)
U14 | ST1S10 | 1 | 8-SOIC (PAD)
U15, U16 | MCP6001UT | 2 | SOT23-5
U17 | USBLC6-2SC6 | 1 | SOT23-6-ASM
U19 | SC189CSKTRT | 1 | SOT23-5
U20 | PE4302 | 1 | 20-QFN (4x4)
U21, U22, U23, U24 | FST3253 | 4 | 16-SSOP
U25 | AMS1117-1.8 | 1 | SOT223
U26 | AMS1117-3.3 | 1 | SOT223
U27 | DAC5674IPHP | 1 | 48-TQFP
U28 | OPA2673IRGVT | 1 | 16-QFN 4x4 PAD17
U29, U30, U31 | SC189 | 3 | SOT23-5
D2 | BAV-99 | 1 | SOT23_132
VD1, VD2 | 1N4108 | 2 | 1N4148
VD3 | BZT52-C5V1 | 1 | SOD123
VT1 | BSS123 | 1 | SOT23_132
VT2 | IRFR9024NPBF | 1 | D2PAK_132
X1 | USB-B | 1 | CON: USB-B
X2 | PLS-5 | 1 | CON: PLS-5
X3, X4 | PLD-10 | 2 | CON: PLD-10
X5 | CWF-3 | 1 | CON: CWF-3
X6 | Разъем DC005 | 1 | CON: PJ-102AH
X7 | PLD-10 | 1 | CON: PLD-10
X9 | PLS-3 | 1 | CON: PLS-3
X10 | ENCODER_MAIN1 | 1 | CON: PLS-4
X12, X14 | U.FL-R-SMT U FL IPEX | 2 | CON: u.Fl
X13 | "PTT" | 1 | RJ25-6pin
XG1 | 12.288Mhz TCXO 3.3v TTL/CMOS (set other freq in fpga code) | 1 | OSC: 5032
XG2 | 122.88Mhz | 1 | OCS: GENA
Y1 | 8 мГц | 1 | OSC: Hz
Y2 | ABS 32.768khz | 1 | ABS-25

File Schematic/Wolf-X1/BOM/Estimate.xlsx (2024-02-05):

№ | Название | Количество | Цена | доставка | штук | Ссылка | Чип и дип | Общая цена | Доставка
MAIN |  |  |  |  |  |  |  | 346.32 | 39.12
 | DM3AT-SF-PEJM5 | 1 | 2.94 | 0.74 | 10 | Aliexpress (https://s.click.aliexpress.com/e/_9isgm1)
 | Индуктивность SMD 0630 3.3uH | 1 | 0.63 | 0.24 | 10 | Aliexpress (https://aliexpress.ru/item/4000557059726.html?item_id=4000557059726&sku_id=10000002922152209) |  | 385.44
 | Индуктивность SMD 0630 10uH | 1 | 0.63 | 0.24 | 10 | Aliexpress (https://aliexpress.ru/item/4000557059726.html?item_id=4000557059726&sku_id=10000002922152209)
 | Индуктивность SMD 0420 2,2uH | 4 | 1.60 | 1.29 | 10 | Aliexpress (https://aliexpress.ru/item/1005001648530241.html?spm=a2g2w.productlist.0.0.7b42d5be3thNsw) | ChipDip (https://www.chipdip.ru/product/ha72l-04202r2lftr?from=suggest_product)
 | Индуктивность SMD 0530 10uH | 1 | 0.70 | 0.18 | 10 | Aliexpress (https://aliexpress.ru/item/4001035691825.html?item_id=4001035691825&sku_id=10000013672787789)
 | SC189CSKTRT | 4 | 2.75 | 1.23 | 10 | Aliexpress (https://s.click.aliexpress.com/e/_97KRnB) | ChipDip (https://www.chipdip.ru/product0/8001051325?from=suggest_product)
 | LM1085-3.3 | 2 | 0.79 | 0.75 | 1 | Aliexpress (https://s.click.aliexpress.com/e/_A281Oz)
 | ST1S10PHR | 1 | 4.85 | 2.53 | 5 | Aliexpress (https://s.click.aliexpress.com/e/_9g82VX)
 | ACS712-20 | 1 | 4.36 | 2.53 | 5 | Aliexpress (https://s.click.aliexpress.com/e/_ADbq7F)
 | LD3985M33R | 1 | 0.94 |  | 10 | Aliexpress (https://s.click.aliexpress.com/e/_AMh9kh)
 | AMS1117-3.3 | 2 | 0.92 |  | 20 | Aliexpress (https://s.click.aliexpress.com/e/_AeJeaD)
 | AMS1117-1.8 | 1 | 1.18 |  | 20 | Aliexpress (https://s.click.aliexpress.com/e/_AeJeaD)
 | MCP6001UT | 2 | 1.96 |  | 10 | Aliexpress (https://s.click.aliexpress.com/e/_9ihxe9)
 | PE4302 | 1 | 2.31 | 0.65 | 5 | Aliexpress (https://s.click.aliexpress.com/e/_AfZ1iz)
 | NV7050SA 122.88Mhz | 1 | 5.00 | 3.79 | 1 | Aliexpress (https://s.click.aliexpress.com/e/_A5JA5P)
 | 12.288Mhz | 1 | 20.00 | 3.47 | 2 | Aliexpress (https://aliexpress.ru/item/4000577979227.html?sku_id=10000003324946109)
 | PAM8406DR | 1 | 3.00 | 0.74 | 10 | Aliexpress (https://s.click.aliexpress.com/e/_A8j981)
 | M25P80-VMW6G | 1 | 1.45 |  | 10 | Aliexpress (https://s.click.aliexpress.com/e/_A6hL4Z)
 | EP4CE22E22C8N | 1 | 59.85 | 2.11 | 1 | Aliexpress (https://s.click.aliexpress.com/e/_9iUwY9)
 | STM32H743VIT6 | 1 | 17.78 |  | 1 | Aliexpress (https://aliexpress.ru/item/1005003007981742.html?mp=1&sku_id=12000023197731242)
 | 25Q16BVSIG | 1 | 1.37 |  | 5 | Aliexpress (https://s.click.aliexpress.com/e/_AqCio9)
 | WM8731 | 1 | 4.68 | 2.53 | 2 | Aliexpress (https://s.click.aliexpress.com/e/_Akey6D)
 | LTC6400IUD | 1 | 2.85 | 1.24 | 1 | Aliexpress (https://s.click.aliexpress.com/e/_AseOOZ)
 | LTC2208CUP | 1 | 11.05 | 3.16 | 1 | Aliexpress (https://s.click.aliexpress.com/e/_ADIvIz)
 | OPA2673IRGVT | 1 | 4.95 |  | 5 | Aliexpress (https://s.click.aliexpress.com/e/_AAqwKp)
 | DAC5674IPHP | 1 | 14.00 | 3.04 | 1 | Aliexpress (https://s.click.aliexpress.com/e/_9y3KyN)
 | MC306 32,768 кГц | 1 | 1.08 | 0.41 | 10 | Aliexpress (https://aliexpress.ru/item/1994878414.html?sku_id=52635197667)
 | USBLC6-2SC6 | 1 | 1.01 |  | 10 | Aliexpress (https://s.click.aliexpress.com/e/_9xdO4z)
 | hc-49s 8 МГц | 1 | 1.14 | 0.20 | 20 | Aliexpress (https://s.click.aliexpress.com/e/_9QtdNT)
 | USB B типа «мама» | 1 | 1.01 | 0.37 | 10 | Aliexpress (https://s.click.aliexpress.com/e/_A1iVsh)
 | PJ-307 | 3 | 0.73 |  | 10 | Aliexpress (https://s.click.aliexpress.com/e/_AUoOZf)
 | ADG918BRMZ | 2 | 1.17 | 0.20 | 1 | Aliexpress (https://s.click.aliexpress.com/e/_989xMD)
 | FST3253MTCX | 4 | 1.68 |  | 5 | Aliexpress (https://s.click.aliexpress.com/e/_AFJSln)
 |  |  | 180.36 | 31.64
PA UNIT
 | STPIC6C595TTR | 1 | 2.42 | 0.74 | 5 | Aliexpress (https://aliexpress.ru/item/1005001359582377.html?sku_id=12000015804019376)
 | Реле | 4 | 2.73 |  | 5 | Aliexpress (https://aliexpress.ru/item/4000017778928.html?item_id=4000017778928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)
 | MCP3008-I/SL | 1 | 1.45 | 0.20 | 1 | Aliexpress (https://s.click.aliexpress.com/e/_9JQuQz)
 | RA08H1317M | 1 | 12.89 |  | 1 | Aliexpress (https://s.click.aliexpress.com/e/_A64gRR)
 | RJ12 6pin | 1 | 1.83 |  | 10 | Aliexpress (https://s.click.aliexpress.com/e/_AmN5bL)
 | PGA-103+ | 1 | 2.20 | 1.58 | 1 | Aliexpress (https://s.click.aliexpress.com/e/_9hNUwN)
 | AMS117-ADJ-8V | 1 | 0.99 |  | 20 | Aliexpress (https://s.click.aliexpress.com/e/_9x7Ew5)
 | AMS1117-5 | 1 | 0.99 |  | 20 | Aliexpress (https://s.click.aliexpress.com/e/_A60xMl)
 | Кнопки 4x4х3.5 мм | 7 | 1.67 | 0.74 | 50 | Aliexpress (https://s.click.aliexpress.com/e/_9HYNvf)
 | BN-43-302 | 1 | 0.80 |  | 1 | cqradio.ru (http://cqradio.ru/products/bn-43-302)
 | BN-43-202 | 1 | 0.94 |  | 1 | cqradio.ru (http://cqradio.ru/products/bn-43-202)
 | FT23-43 | 1 | 0.25 |  | 1 | cqradio.ru (http://cqradio.ru/products/ft-23-43)
 | T37-6 | 3 | 0.80 |  | 3 | cqradio.ru (http://cqradio.ru/products/t37-6)
 | RD16 | 2 | 8.00 |  | 2 | CihpDip (https://www.chipdip.ru/product/rd16hhf1-101?from=suggest_product)
 | RD01 | 2 | 1.95 |  | 5 | Aliexpress (https://s.click.aliexpress.com/e/_A4k9sN)
 |  |  | 39.91 | 3.26
Разное
 | Корпус | 1 | 10.38 |  | 1 | Aliexpress (https://s.click.aliexpress.com/e/_ADzTtP)
 | Динамики AIYIMA, 27 мм | 1 | 5.04 | 1.46 | 2 | Aliexpress (https://s.click.aliexpress.com/e/_A2uQWH)
 | Валкодер EC11 | 1 | 1.97 |  | 5 | Aliexpress (https://s.click.aliexpress.com/e/_A7EsjB)
 | Валкодер ENS1D-441-M00128 | 1 | 14.25 |  | 1 | Aliexpress (https://aliexpress.ru/item/1005003171237807.html?bizType=ProductDetail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)
 | Дисплей 1.8, 128x160 | 1 | 4.19 |  | 1 | Aliexpress (https://aliexpress.ru/item/32996979276.html?item_id=32996979276&sku_id=67278796295)
 | Тангента MH-48 | 1 | 10.15 |  | 1 | Aliexpress (https://aliexpress.ru/item/1005001706845338.html?sku_id=12000017235262329)
 | U.FL-R-SMT | 4 | 0.70 | 0.80 | 10 | Aliexpress (https://s.click.aliexpress.com/e/_AOLDKD)
 | Кабель 10см IPEX U.fl | 2 | 4.87 |  | 10 | Aliexpress (https://s.click.aliexpress.com/e/_ACJlXT)
 | UHF SO-239 | 1 | 0.48 | 0.63 | 1 | Aliexpress (https://s.click.aliexpress.com/e/_AUVL2p)
 | ESP8266 ESP-07 | 1 | 1.50 | 0.20 | 1 | Aliexpress (https://s.click.aliexpress.com/e/_A6cNcd)
 | Диоды LL4148 | 5 | 0.53 | 0.37 | 50 | Aliexpress (https://s.click.aliexpress.com/e/_AOTU3P)
 | Конденсаторы 100n |  | 15.71 |  | 4000 | Aliexpress (https://s.click.aliexpress.com/e/_A1oQBJ)
 | Диоды SS14 | 3 | 1.28 | 0.76 | 100 | Aliexpress (https://s.click.aliexpress.com/e/_9IueWH)
 | Набор плат + активация |  | 55.00 |  |  | Telegramm (https://t.me/Wolf_X1)
 |  |  | 126.05 | 4.22

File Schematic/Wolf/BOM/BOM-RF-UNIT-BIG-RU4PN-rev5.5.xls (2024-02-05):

ID | Name | Designator | Footprint | Quantity | Manufacturer Part | Manufacturer | Supplier | Supplier Part | Price
1 | 100n | C1,C7,C8,C9,C10,C11,C16,C21,C26,C31,C36,C38,C42,C47,C48,C49,C50,C59,C64,C67,C71,C76,C78,C80,C82,C89,C90,C113,C114,C116,C117,C118,C130,C131,C136,C137,C138,C139,C167,C170,C171,C241,C301,C302,C303,C304 | C0805 | 46
2 | 470pF | C2 | C1206 | 1
3 | 30pF | C3 | C1206 | 1
4 | 36pF | C4 | C1206 | 1
5 | 47pF | C5,C86 | C1206 | 2
6 | 22pF | C6,C85 | C1206 | 2
7 | 27pF | C12,C15 | C1210 | 2
8 | 20pF | C13 | C1210 | 1
9 | 100pF | C14,C17,C19,C20 | C1210 | 4
10 | 120pF | C18 | C1210 | 1
11 | 150pF | C22,C23,C25,C28 | C1210 | 4
12 | 220pF | C24,C27,C30 | C1210 | 3
13 | 330pF | C29 | C1210 | 1
14 | 470pF | C32,C33,C34,C35 | C1210 | 4
15 | 470+330pF | C37,C41 | C1210 | 2
16 | 1000pF | C39,C45 | C1210 | 2
17 | 560pF | C40 | C1210 | 1
18 | 1000+220pF | C43,C46 | C1210 | 2
19 | 1000+470pF | C44 | C1210 | 1
20 | 3n3 | C51,C125,C134,C135 | C0805 | 4
21 | 68pF 500V | C52,C56 | C1206 | 2
22 | 4.7n* | C53,C54 | C1206 | 2
23 | 27pF | C55 | C0805 | 1
24 | 470p 500V | C57 | C1206 | 1
25 | 100n | C58,C61,C106 | C1206 | 3
26 | 200p 500V | C60 | C1206 | 1
27 | 1uF | C62,C63,C79,C83,C126 | C0805 | 5
28 | 30pF* | C65,C66 | CAP-ADJ-SMD_L4.5-W3.2-L | 2 | TZC3P300A110R00 | Murata Electronics | LCSC | C107707
29 | 82pF | C68,C73,C388,C390 | C0805 | 4
30 | 10n | C69,C107,C108,C109,C110,C121,C123,C124,C133,C141,C142,C143,C144,C145,C146,C147,C148,C149,C150,C151,C152,C153,C154,C157,C158,C159,C160,C161,C162,C163,C164,C165,C166 | C0805 | 33
31 | 4.7n | C70,C75 | C0805 | 2
32 | 75pF | C72,C311,C389 | C0805 | 3
33 | 22uF | C74,C77 | CASE-B_3528 | 2
34 | 15n | C81,C111 | C1206 | 2
35 | 10pF | C84 | C1206 | 1
36 | 100pF | C87,C91,C93,C103 | C1206 | 4
37 | 220pF | C88 | C1206 | 1
38 | 10n | C92,C102 | C1206 | 2
39 | 1n | C94,C104 | C1206 | 2
40 | 2.2uF | C95 | C1206 | 1
41 | * | C96,C97,C98,C99,C100 | CAP-TH_L8.0-W4.0-P7.50-D0.6 | 5 | CC45SL3AD101JYSNA | TDK | LCSC | C2835349 | 0.006
42 | 200pF | C101 | C1206 | 1
43 | 1n8 | C105 | C1206 | 1
44 | 100p | C112,C127,C132 | C0805 | 3
45 | 1n | C115,C122,C347,C348,C372 | C0805 | 5
46 | 47uF | C119 | CASE-B_3528 | 1
47 | 68p | C120,C202,C208 | C0805 | 3
48 | 1uF | C128 | C1206 | 1
49 | 10uF 25V | C129 | CAP-D4.0×H5.5 | 1
50 | 39p | C201 | C0805 | 1
51 | 12p | C203 | C0805 | 1
52 | 27p | C204 | C0805 | 1
53 | 51p | C207 | C0805 | 1
54 | 47p | C210 | C0805 | 1
55 | 47pF | C305,C313 | C0805 | 2
56 | 33pF | C306 | C0805 | 1
57 | 39pF | C307 | C0805 | 1
58 | 110pF | C310 | C0805 | 1
59 | 61pF | C312 | C0805 | 1
60 | 100pF | C314,C322 | C0805 | 2
61 | 120pF | C315,C321 | C0805 | 2
62 | 15pF | C317 | C0805 | 1
63 | 8pF | C319 | C0805 | 1
64 | 150pF | C320 | C0805 | 1
65 | 330pF | C323,C344,C346 | C0805 | 3
66 | 270pF | C324,C332,C345 | C0805 | 3
67 | 180pF | C333,C334 | C0805 | 2
68 | 560pF | C335 | C0805 | 1
69 | 470pF | C336,C360 | C0805 | 2
70 | 820pF | C358,C373 | C0805 | 2
71 | 680pF | C359 | C0805 | 1
72 | 1.5n | C361 | C0805 | 1
73 | 1.2n | C362,C374 | C0805 | 2
74 | 3.3n | C375,C376 | C0805 | 2
75 | 30pF * | C386,C387 | CAP-ADJ-SMD_L4.5-W3.2-L | 2 | TZC3P300A110R00 | Murata Electronics | LCSC | C107707
76 | BAT46JFILM | D1,D3,D49,D50 | SOD-323_L1.8-W1.3-LS2.5-RD | 4 | BAT46JFILM | STMicroelectronics | LCSC | C111205
77 | SMAJ5.0A-TR | D2 | SMA_L4.3-W2.6-LS5.2-RD | 1 | SMAJ5.0A-TR | STMicroelectronics | LCSC | C98802 | 0.037
78 | 1N4148W | D4,D5,D8,D9,D13,D15,D17,D20,D22,D25,D27,D31,D32,D38,D39,D40,D41,D42,D43,D44,D45,D46,D47,D48,D51 | SOD-123FL_L2.6-W1.6-LS3.4-RD | 25 | 1N4148W | Tak Cheong | LCSC | C129216 | 0.003
79 | CDSOD323-T05C | D6,D10,D11,D12 | SOD-323_L1.8-W1.3-LS2.5-BI | 4 | CDSOD323-T05C | BOURNS | LCSC | C711706 | 0.048
80 | BAV99 | D7 | SOT-23-3_L2.9-W1.3-P1.90-LS2.4-BR | 1 | BAV99-7-F | DIODES | LCSC | C106919 | 0.005
81 | SS14 | D18,D23 | SS14 | 2 | SS14 | MDD | LCSC | C2480 | 0.002
82 | SS14 | D35,D36,D37 | SMA_L4.4-W2.8-LS5.4-RD | 3 | SS14 | MDD | LCSC | C2480 | 0.002
83 | BLM21 | FB1,FB2 | L0806 | 2
84 | BLM21 | FB4,FB5 | L0805 | 2 | BLM21PG300SN1D | MuRata | LCSC | C16903 | 0.004
85 | FAN_OUT | H1 | HDR-F-2.54_1X2 | 1 |  |  | LCSC | C49661 | 0.006
86 | ANT1 | J1 | SMA-TH_BWSMA-KE-Z001 | 1 | SMA-KE-P901 | DreamLNK | LCSC | C914556 | 0.109
87 | ADC | J2,J10 | SMA-TH_BWSMA-KE-Z001 | 2 | SMA-KE-P901 | DreamLNK | LCSC | C914556 | 0.109
88 | EXTERNAL | J3 | IDC-10 | 1
89 | MOTHERBOARD | J4 | IDC-10 | 1
90 | ANT2 | J5 | SMA-TH_BWSMA-KE-Z001 | 1 | SMA-KE-P901 | DreamLNK | LCSC | C914556 | 0.109
91 | HiCurrent 13.8V | J6 | CONN-TH_TY500-5.08-02P-14-00AH | 1 | TY500-5.08-02P-14-00AH | Toponelec(拓宜) | LCSC | C2828268 | 0.032
92 | HiCurrent13.8V | J7 | CONN-TH_TY500-5.08-02P-14-00AH | 1 | TY500-5.08-02P-14-00AH | Toponelec(拓宜) | LCSC | C2828268 | 0.032
93 | 13.8V | J8 | CONN-TH_TY500-5.08-02P-14-00AH | 1 | TY500-5.08-02P-14-00AH | Toponelec(拓宜) | LCSC | C2828268 | 0.032
94 | DAC | J9 | SMA-TH_BWSMA-KE-Z001 | 1 | SMA-KE-P901 | DreamLNK | LCSC | C914556 | 0.109
95 | G6S-2-12V | K1,K2,K8,K9,K10,K11,K12,K13,K14,K15,K16,K17,K18,K19,K20,K21,K24,K25,K26,K27,K28,K29,K30,K31,K32,K33,K34,K35 | RELAY-TH_G6S-2-X | 28 | G6S-2-12V | OMRON | LCSC | C28410 | 0.145
96 | axicom im06c | K4,U4,U12 | IM06C | 3 | axicom im06c |  | axicom
97 | G6K-2F-5V | K50 | RELAY-TH_G6K-2F-Y | 1 | 0 | Omron Electronics | LCSC | C231389 | 0.201
98 | 0,047uH | L1 | BEAD-TH_BD3.5-L4.7-P8.70-D0.7 | 1 | BL02RN2R1M2 | China |  | C84974
99 | 0.047uH | L2,L3 | BEAD-TH_BD3.5-L4.7-P8.70-D0.7 | 2 | BL02RN2R1M2 | China |  | C84974
100 | 0.065uH | L7,L8 | BEAD-TH_BD3.5-L4.7-P8.70-D0.7 | 2 | BL02RN2R1M2 | China |  | C84974
101 | 0.29uH | L10,L11 | BEAD-TH_BD3.5-L4.7-P8.70-D0.7 | 2 | BL02RN2R1M2 | China |  | C84974
102 | 0.4uH | L13,L14 | BEAD-TH_BD3.5-L4.7-P8.70-D0.7 | 2 | BL02RN2R1M2 | China |  | C84974
103 | 0.6uH | L16,L17 | BEAD-TH_BD3.5-L4.7-P8.70-D0.7 | 2 | BL02RN2R1M2 | China |  | C84974
104 | 1.15uH | L19,L20 | BEAD-TH_BD3.5-L4.7-P8.70-D0.7 | 2 | BL02RN2R1M2 | China |  | C84974
105 | 2.3uH | L22,L23 | BEAD-TH_BD3.5-L4.7-P8.70-D0.7 | 2 | BL02RN2R1M2 | China |  | C84974
106 | 4.5uH | L25,L26 | BEAD-TH_BD3.5-L4.7-P8.70-D0.7 | 2 | BL02RN2R1M2 | China |  | C84974
107 | 10u 10x10 | L30,L43 | B82464Z4 | 2
108 | 0.22u | L31 | L1206 | 1
109 | 0.0082u | L32,L33,L34 | L0805 | 3
110 | 0.1uH | L35 | BEAD-TH_BD3.5-L4.7-P8.70-D0.7 | 1 | BL02RN2R1M2 | China |  | C84974
111 | 0.22uH | L36 | BEAD-TH_BD3.5-L4.7-P8.70-D0.7 | 1 | BL02RN2R1M2 | China |  | C84974
112 | 0.45uH | L39 | BEAD-TH_BD3.5-L4.7-P8.70-D0.7 | 1 | BL02RN2R1M2 | China |  | C84974
113 | 1.0uH | L41 | BEAD-TH_BD3.5-L4.7-P8.70-D0.7 | 1 | BL02RN2R1M2 | China |  | C84974
114 | 2.2uH | L42 | BEAD-TH_BD3.5-L4.7-P8.70-D0.7 | 1 | BL02RN2R1M2 | China |  | C84974
115 | 0.22u | L46 | L0805 | 1
116 | 0.022u | L48 | L0805 | 1
117 | 0.0082u | L134,L135,L136 | L0805-WOLF | 3 | L0805C100MDWIT | KEMET | LCSC | C696787 | 0.037
118 | 0.1u | L140 | L0805-WOLF | 1
119 | 0.082u | L141 | L0805-WOLF | 1
120 | 0.15u | L142 | L0805-WOLF | 1
121 | 0.022u | L151 | L0805-WOLF | 1 | L0805C100MDWIT | KEMET | LCSC | C696787 | 0.037
122 | 0.18u | L153 | L0805-WOLF | 1 | L0805C100MDWIT | KEMET | LCSC | C696787 | 0.037
123 | 0.33u | L155,L308,L310,L311 | L0805-WOLF | 4 | L0805C100MDWIT | KEMET | LCSC | C696787 | 0.037
124 | 0.27u | L301,L307 | L0805-WOLF | 2 | L0805C100MDWIT | KEMET | LCSC | C696787 | 0.037
125 | 0.082u | L302 | L0805-WOLF | 1 | L0805C100MDWIT | KEMET | LCSC | C696787 | 0.037
126 | 0.1u | L303 | L0805-WOLF | 1 | L0805C100MDWIT | KEMET | LCSC | C696787 | 0.037
127 | 0.47u | L304,L315 | L0805-WOLF | 2 | L0805C100MDWIT | KEMET | LCSC | C696787 | 0.037
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

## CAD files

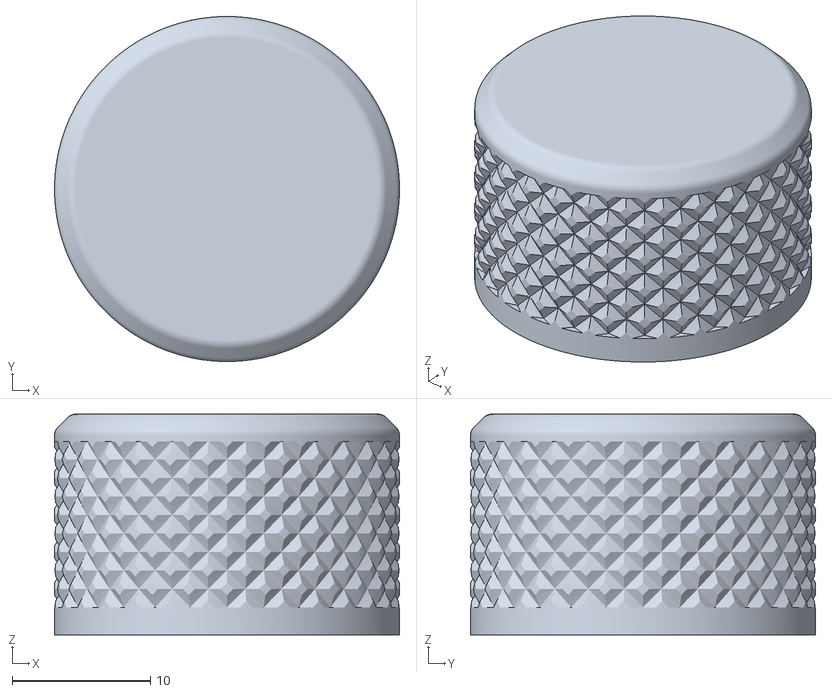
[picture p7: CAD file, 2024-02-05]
Schematic/Wolf-X1/Addons/20mm_Main_Encoder.stl
25.0 x 25.0 x 16.0

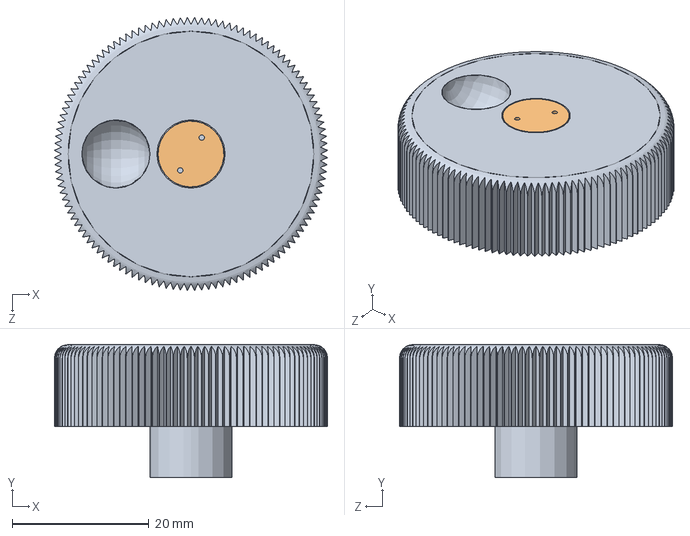
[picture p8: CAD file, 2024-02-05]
Schematic/Wolf/CASE/3'2/3DPrinter/case/shuttle_knob_construct.SLDASM
40.0 x 19.5 x 40.0 mm
shuttle_knob
shuttle_knob_cap

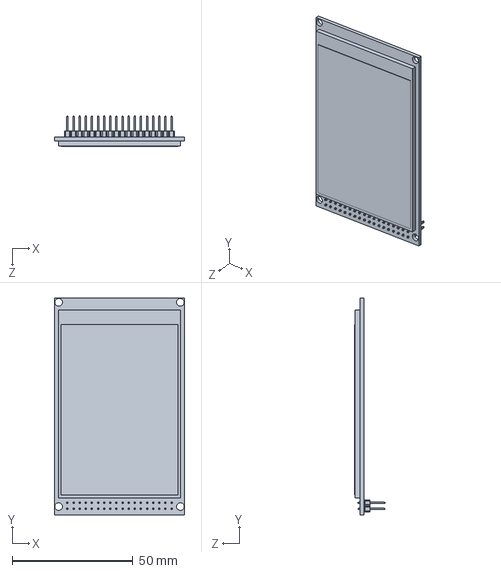
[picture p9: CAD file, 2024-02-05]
Schematic/Wolf/CASE/3'2/3DPrinter/Display480x320.SLDASM
54.1 x 90.0 x 12.6 mm

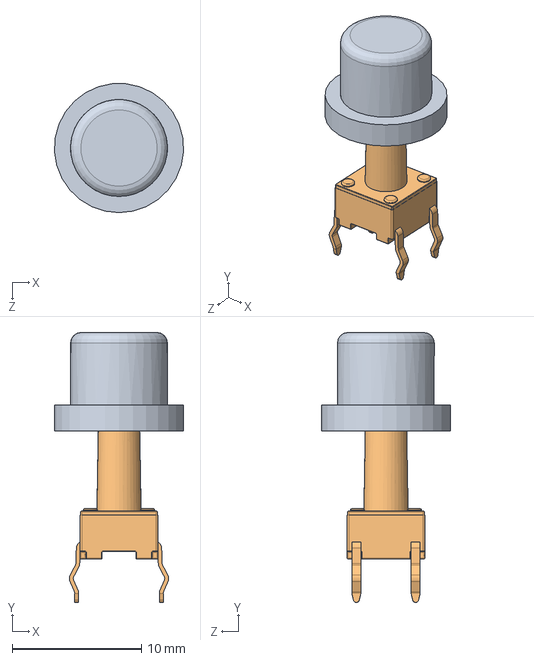
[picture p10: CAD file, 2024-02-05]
Schematic/Wolf/CASE/3'2/3DPrinter/case/button_construct.SLDASM
9.99 x 20.9 x 10.0 mm
button
tactileswitch-long

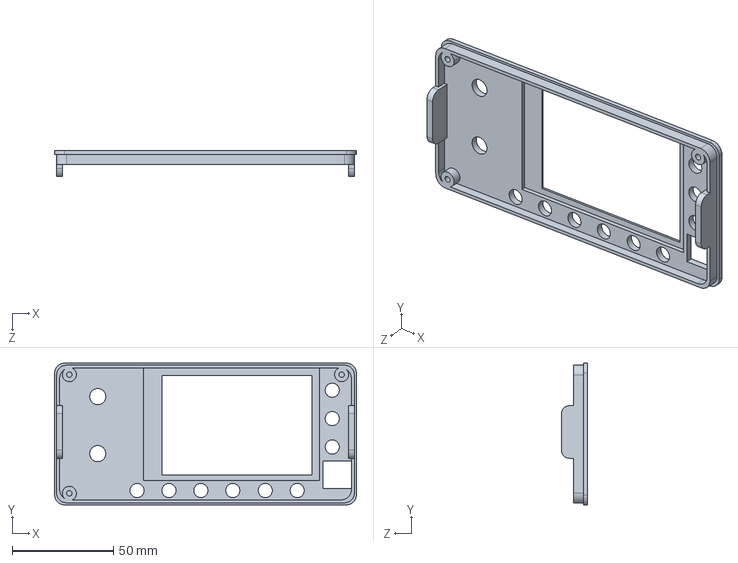
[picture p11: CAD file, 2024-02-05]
Schematic/Wolf-Lite/Case/Front Lite V2.SLDPRT
149.0 x 70.0 x 13.0 mm

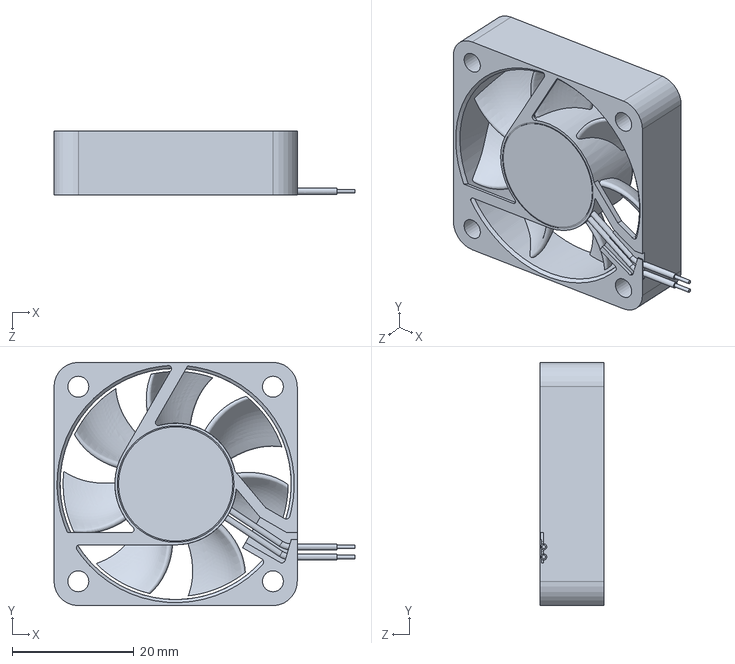
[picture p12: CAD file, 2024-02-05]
Schematic/Wolf/CASE/3'2/3DPrinter/40x40x10 DC Fan.SLDPRT
49.5 x 40.0 x 10.5 mm

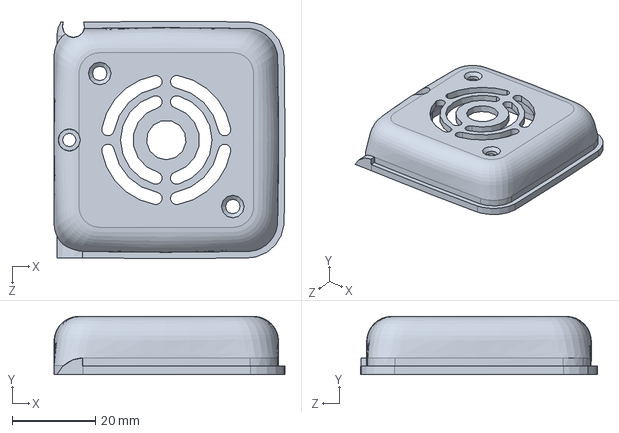
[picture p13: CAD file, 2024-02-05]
Schematic/Wolf/CASE/3'2/3DPrinter/case/case_cooller.SLDPRT
55.5 x 14.0 x 57.1 mm

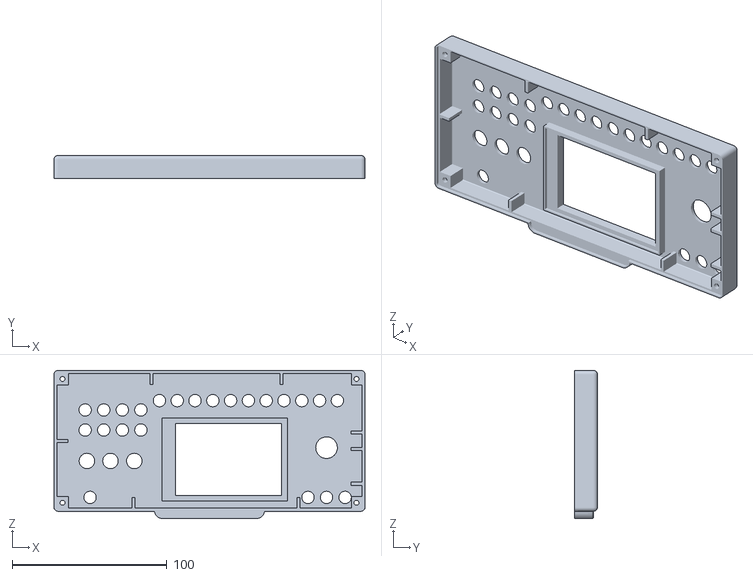
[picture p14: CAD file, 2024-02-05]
Schematic/Wolf/CASE/3'2/3DPrinter/STL/case_front.STL
201.0 x 14.8 x 95.7

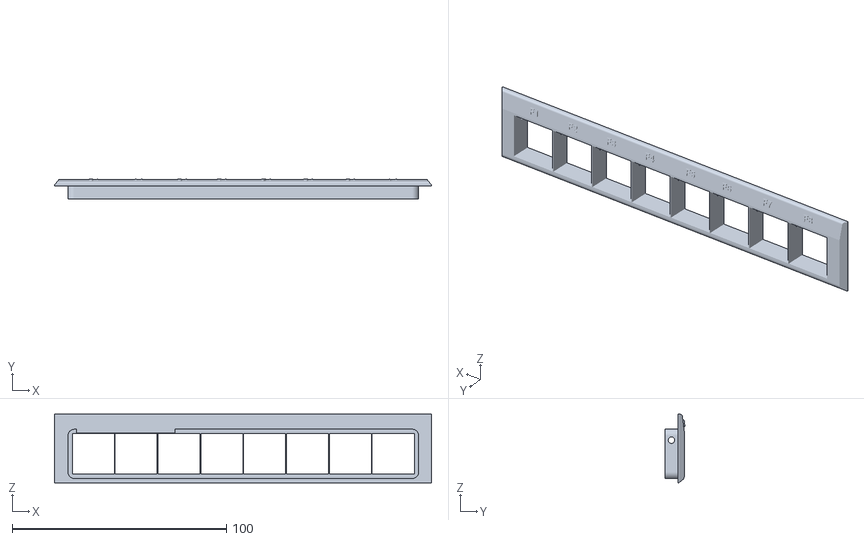
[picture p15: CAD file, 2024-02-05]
Schematic/Wolf/CASE/7/Panel/рамка_низ_7.stl
176.0 x 9.31 x 32.0

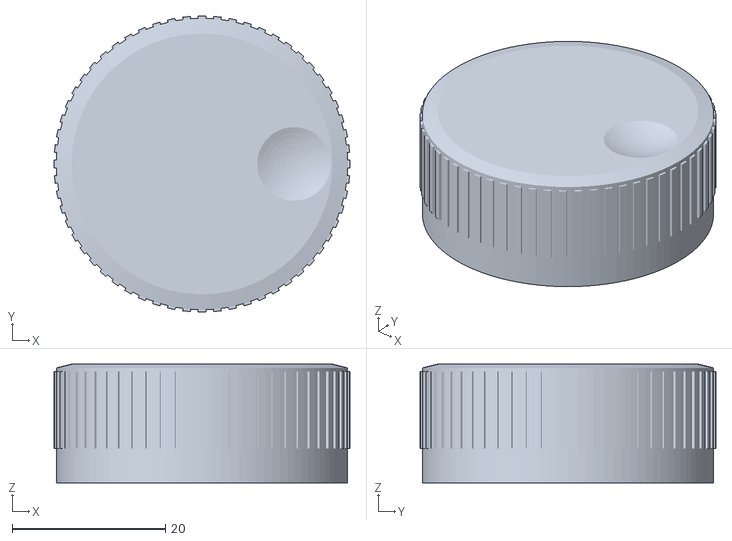
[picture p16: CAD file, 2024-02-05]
Schematic/Wolf/CASE/VFO/VFO_38mm.stl
38.6 x 38.6 x 15.5

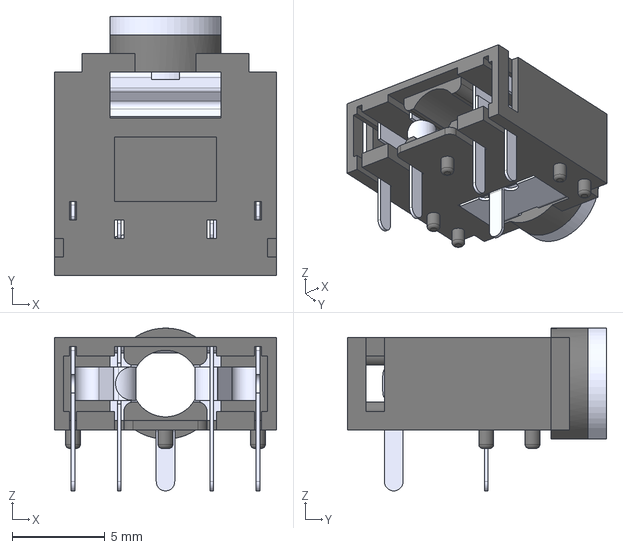
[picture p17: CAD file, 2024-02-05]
Schematic/Wolf/CASE/3'2/3DPrinter/ST-212.step
12.0 x 14.0 x 8.80 mm

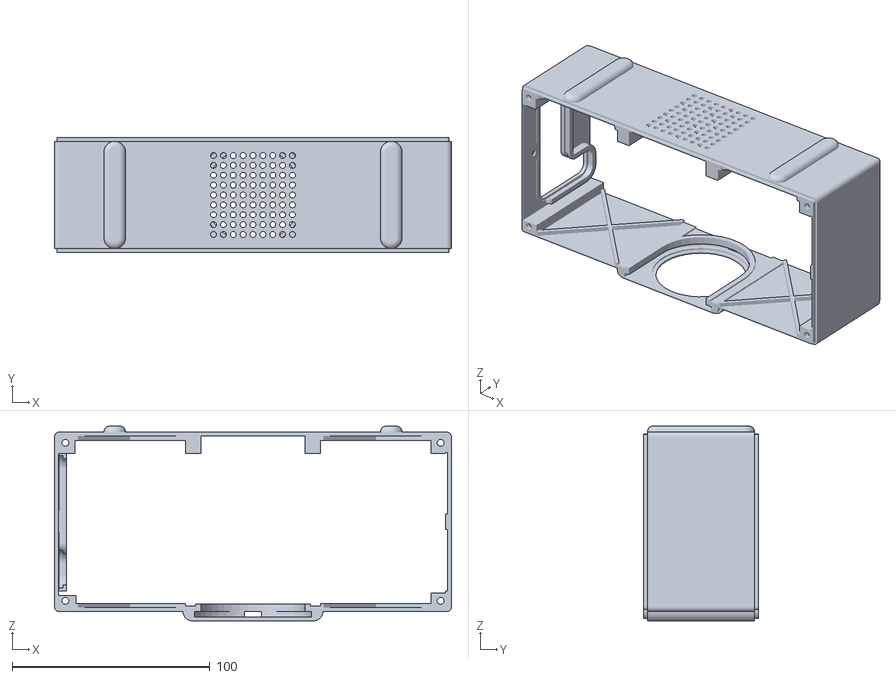
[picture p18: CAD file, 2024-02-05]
Schematic/Wolf/CASE/3'2/3DPrinter/STL/case_shell.STL
201.0 x 58.4 x 98.7

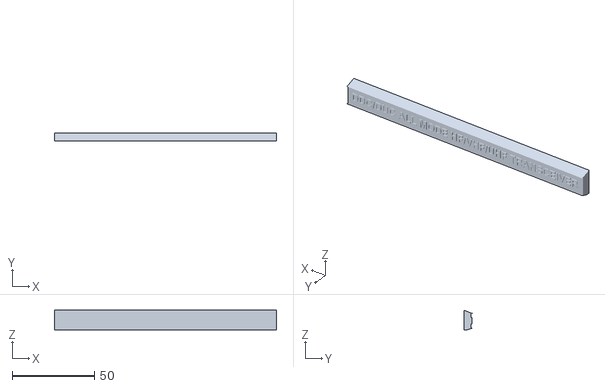
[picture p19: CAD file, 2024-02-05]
Schematic/Wolf/CASE/7/Panel/верхняя планка волк7_2.stl
135.0 x 5.00 x 12.0

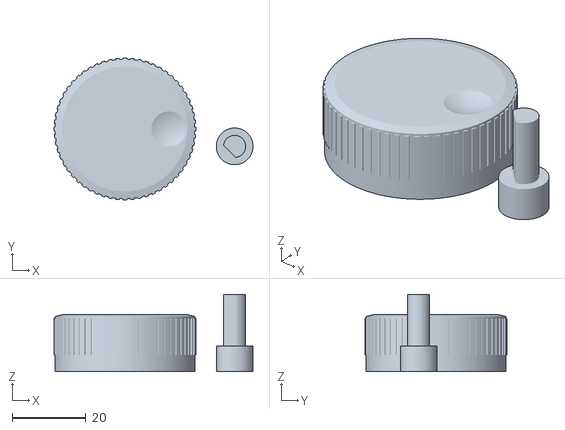
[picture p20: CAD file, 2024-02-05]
Schematic/Wolf/CASE/VFO/VFO38WithExt.stl
54.1 x 38.6 x 21.0

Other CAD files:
Schematic/Wolf/CASE/3'2/3DPrinter/KY-040 Rotary Encoder.SLDASM
Schematic/Wolf-Lite/Case/BOT-LITE.SLDPRT
Schematic/Wolf-X1/Addons/Milling_Top.DWG
Schematic/Wolf/CASE/3'2/3DPrinter/case/case_front.SLDPRT
Schematic/Wolf-Lite/Altium_Designer/Front-Unit/Wl-FRONT-EDM/16-SOIC_MCP3008-I_SL.x_t
Schematic/Wolf-Lite/Altium_Designer/Front-Unit/Wl-FRONT-EDM/BAT__CH224-2032_POWER_BAT.x_t
Schematic/Wolf-Lite/Altium_Designer/Front-Unit/Wl-FRONT-EDM/BUT__6x6_SMD_Tactile_switches.x_t
Schematic/Wolf-Lite/Altium_Designer/Front-Unit/Wl-FRONT-EDM/BUT__6x6_Tactile_switches.x_t
Schematic/Wolf-Lite/Altium_Designer/Front-Unit/Wl-FRONT-EDM/CH0805C_Capacitor.x_t
Schematic/Wolf-Lite/Altium_Designer/Front-Unit/Wl-FRONT-EDM/CH0805R_Resistor.x_t
Schematic/Wolf-Lite/Altium_Designer/Front-Unit/Wl-FRONT-EDM/CON__PLS-5_5-Connector.x_t
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

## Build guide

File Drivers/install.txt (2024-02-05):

This driver uses windows USB Virtual com port driver files
If it;s dont work, please update system drivers from https://my.st.com/content/my_st_com/en/products/development-tools/software-development-tools/stm32-software-development-tools/stm32-utilities/stsw-stm32102.html

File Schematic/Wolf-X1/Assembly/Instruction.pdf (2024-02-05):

Инструкция по сборке трансивера Wolf X1

Трансивер Wolf X1 является совместной разработкой UA3REO и R7KBI автор не несет ответственность за не качественные комплектующие в случае если у Вас не запустился трансивер с первого раза, в случае если не работает какой то узел, обращается нужно в телеграмм чат https://t.me/TRX_Wolf четко изложить проблему, по возможности приложить фотографии не работающего узла или участка, либо записать коротенькое видео.

При правильной сборке и не бракованных комплектующих, вся наладка сводится на проверку АЧХ полосовых фильтров, ФНЧ. Установку токов покоя на транзисторы VT4, VT6 (RD16HHF1) выходного каскада и установку опорного напряжения U5 RA08H1317M. На этом при правильной сборке вся наладка заканчивается. Остается только калибровка в меню настроек.

Ниже я опишу сборку MAIN платы, так как это собирал я R7KBI Вы в праве нарушить алгоритм сборки как посчитаете лучше для Вас, но рекомендую следовать инструкции.

### 1. В первую очередь необходимо запаять dc-dc, U14 ST1S10 с AliExpress это

«Русская рулетка» я бы по советовал либо искать проверенного продавца или искать в местных магазинах. Это довольно ответственный узел, если пробьет U14 она за собой потянет другие узлы. Необходимо убедится, что на выходе ST1S10 было не больше 5V, это важно!!!

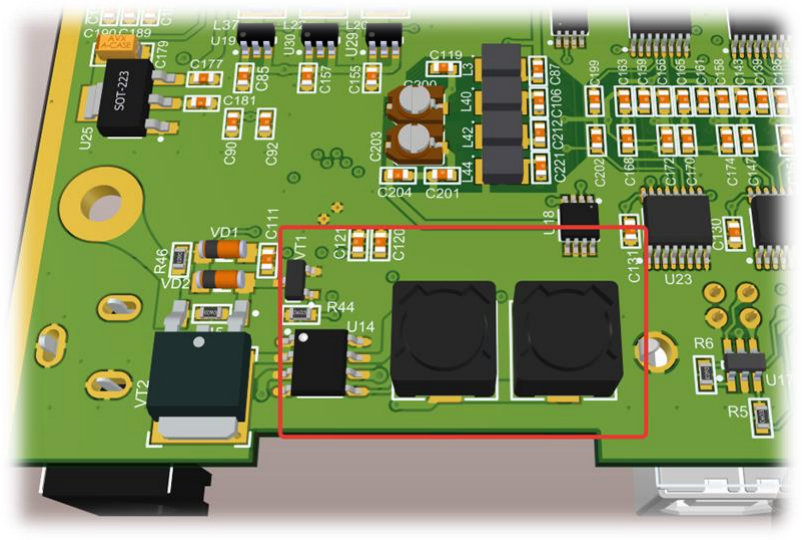
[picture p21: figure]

Рисунок – 1

### 2. Вторым этапом запаять dc-dc U19, U29, U30. Микросхемы SC189 бывают

на напряжения, которые указаны в таблице, нас интересуют в корпусе SOT23-5.

Для питания U4 EP4CE22E22C8N, необходима три напряжения 1.2V, 2.5V, 3.3V. Можно применить U19 SC189CSKTRT, U29 SC189YSKTRT, U30 SC189ZSKTRT, но в этом случае резисторы R34, R3, R4 не устанавливать, а резисторы R53, R48, R52 заменить на нулевые (перемычки). На момент написания данной инструкции, я не смог найти по оптимальной цене с нужным индексом данные микросхемы, поэтому можно применить SC189ASKTRT или SC189CSKTRT в этом случае устанавливаем делители на резисторах согласно схеме.

Индуктивности должны быть силовые, но по высоте есть конструктивные ограничения, (это касается всех компонентов, которые находятся на нижнем слое платы MAIN) не выше 5мм.

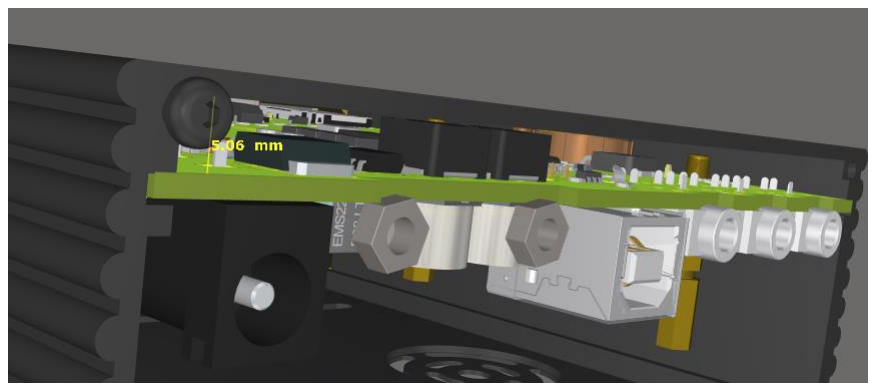
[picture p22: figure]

Рисунок – 2

После установки необходимо проверить выходные напряжения, они должны быть строго как на схеме 1.2V, 2.5V, 3.3V в ином случае можно сжечь U4 EP4CE22E22C8N.

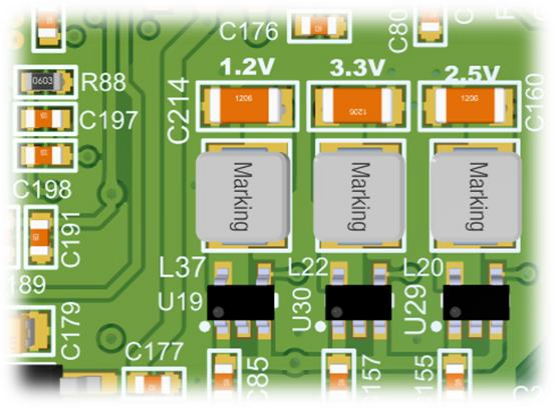
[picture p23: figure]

Рисунок – 3

3. Следующим | этапом | можно | распаивать | линейные | стабилизаторы
напряжения. Обратите внимания для питания STM32H743VIT6 и периферии применяется на выбор понижающие стабилизаторы, U13 LM1085-3.3 или U31 SC189 (смотрите пункт 2 по обвязке). Тут вы сами определяйтесь какой применить dc-dc или линейный стабилизатор, я испробовал два варианта оба отлично за рекомендовали и у обоих есть свои плюса.

Смотря что, Вы выбрали, к примеру U13, в этом случае обвязку U31 распаивать не нужно (смотрите схему).

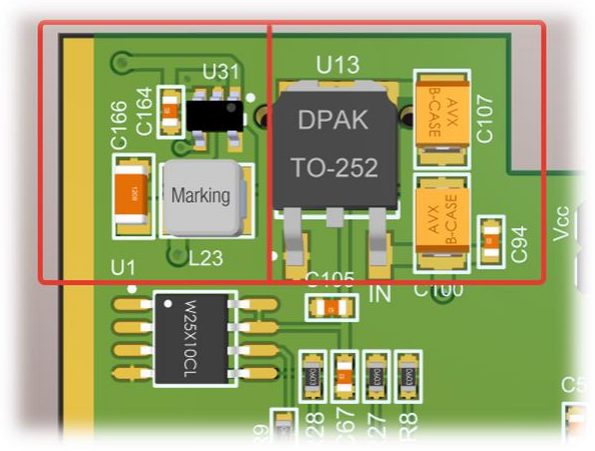
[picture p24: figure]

Рисунок – 4

### 4. После установки всех стабилизаторов напряжения, приступаем к установке

всех блокировочных конденсаторов 0.1мкф (100n). Почему именно с них следующий этап!? Да все просто, лично я не раз попадал на конденсаторы, которые в КЗ (коротком замыкании) поэтому я рекомендую, запаивать партиями, то есть – запаять штук 10, подать питание, если все нормально идем дальше, пока все не установите. В ином случае если не повезет, может оказаться один в КЗ, в этом случае будет сложно найти какой из 93 штук.

Примечание

Не запаивайте гнезда под наушники, микрофон и телеграфный ключ. Обосную почему я рекомендую их установить в самом конце сборки – дело в том, что Вам придется работать с паяльным феном, и эти гнезда расплавятся от высокой температуры. Но учтите, что без гнезда J2 под наушники не будет звука в динамике.

### 5. После проделанных 4 пунктов, можно устанавливать компоненты, которые

есть в наличии, но первые 4 пункта настоятельно рекомендую соблюсти, во избежание проблем с выхода из строя дорогостоящих компонентов.

Обратите внимание на крепежное отверстие для латунной стоки с нижней правой стороны

Рисунок – 5

Через данную стойку поступает напряжение на плату UM поэтому будьте внимательны, когда под стойку установите шайбу, что бы она не была большого размера и не замкнулась с земляным полигоном. И рекомендую на бронзовую стойку одеть термоусадку.

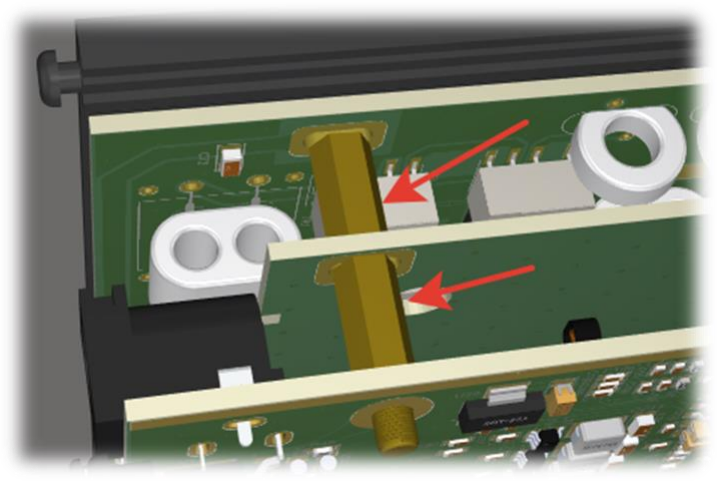
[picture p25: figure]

Рисунок – 6

После сборки можно приступить к прошивке трансивера, последовательность что прошивать в первую очередь не имеет значения.

Чтобы первый раз прошить STM32H743VIT6 есть два способа.

- При помощи программатора ST-Link
- Через USB

Второй способ через USB более универсальный, не нужны ни какие программаторы, просто подключаем трансивер через USB шнур к компьютеру, замыкаем перемычку J1 BOOT рис. 7 и подаем питание на плату MAIN при этом удерживаем кнопку включения, но ею будет не удобно воспользоваться если трансивер не полностью собран, По этому

Рисунок – 7

Нужно исключить узел, отвечающий за включение рис. 8 Или лучше даже посадить на землю пин on/off на разъеме X7 рис. 7.

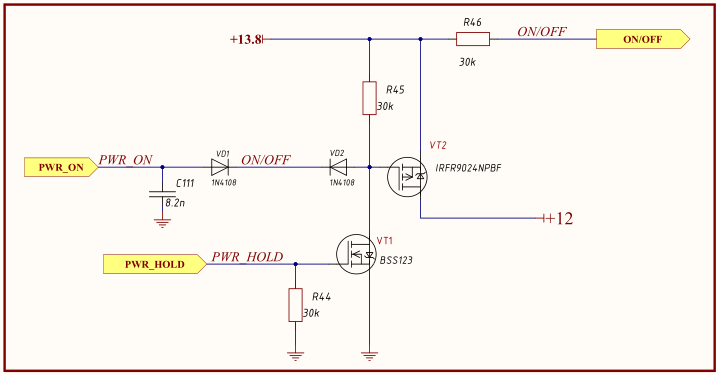
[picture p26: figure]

Рисунок – 8

И подать питание на прямую на сток транзистора VT2 это фланец транзистора рис. 9.

Рисунок – 9

После проделанной процедуры трансивер определите на компьютере и при помощи программы STM32CubeProgrammer (скачать можно с официального сайта https://www.st.com она бесплатная, нужна только регистрация)

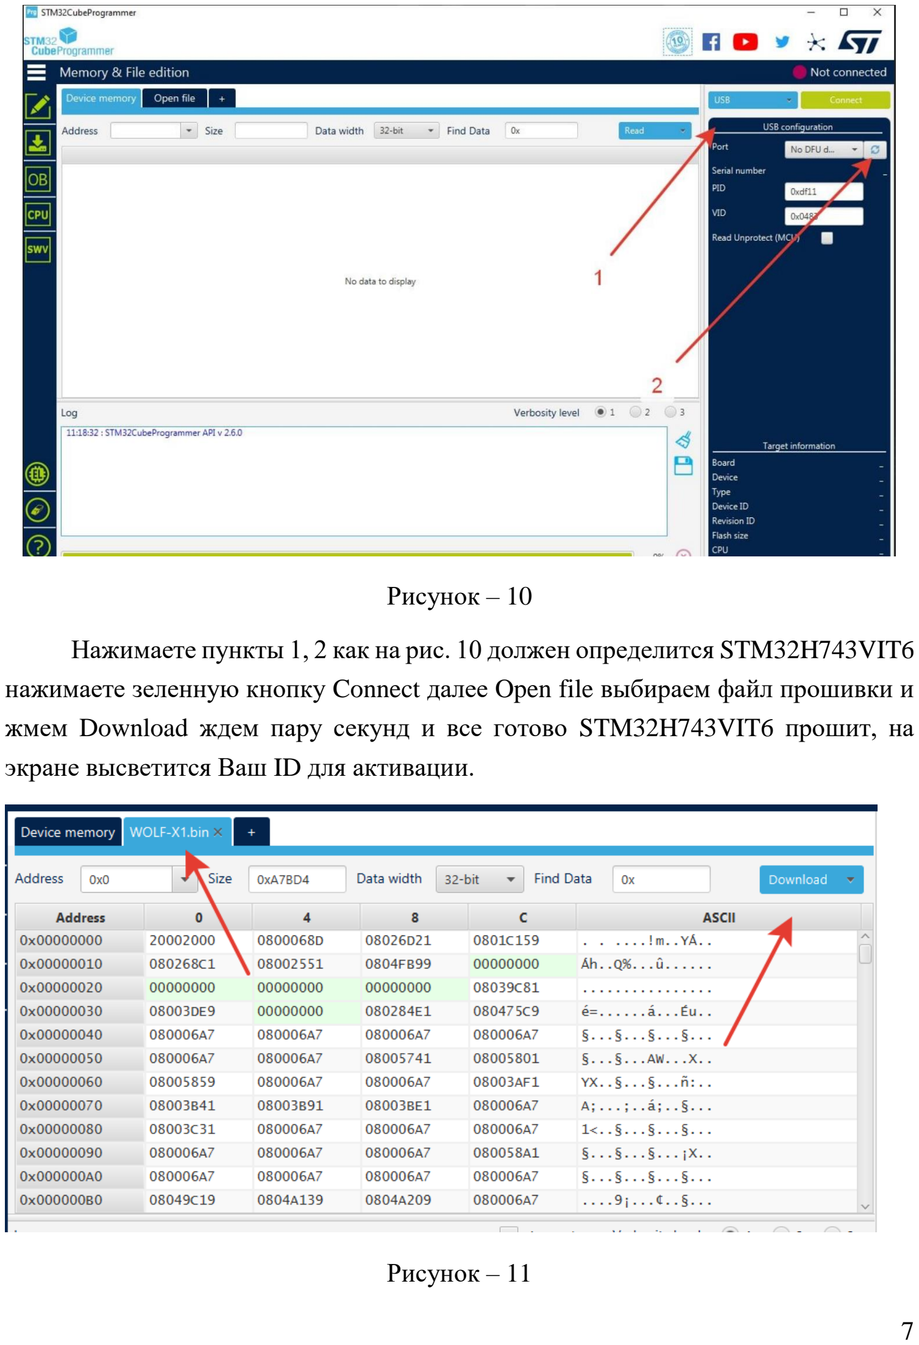
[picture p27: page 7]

Рисунок – 10

Нажимаете пункты 1, 2 как на рис. 10 должен определится STM32H743VIT6 нажимаете зеленную кнопку Connect далее Open file выбираем файл прошивки и жмем Download ждем пару секунд и все готово STM32H743VIT6 прошит, на экране высветится Ваш ID для активации.

Рисунок – 11

Данную процедуру прошивки необходимо провести только в случае, если прошиваете первый раз, в последующие обновления это не понадобится, можно будет прошиться через WI-Fi, или файловые менеджер, предварительно загрузив прошивку на SD карту.

Прошивка FPGA |

Как проверить АЧХ ДПФ!? Да есть некоторые сложности из-за тесноты компоновки. Есть два способа:

- На выключенной плате MAIN, но при этом не запаянные ключи U21, U22, U23, U24, U12, U18
- На включенном и полностью собранной плате MAIN

Первый вариант не совсем удобен, но в этом ключи не будут вносить затухания это, как и плюс так и минус.

Второй способ более правильный, в этом случае необходимо исключить конденсатор С122 что бы он не садил сигнал через трансформатор T1.

Необходимо под паятся кабелями от измерительного прибора (к примеру NanoVNA) к резисторам R65, R70 к верхней части как на рис. 12, а минусовой в любом удобном месте. После проверки АЧХ желательно продублировать процедуру, но уже проверить сквозное АЧХ от антенного гнезда и до входа трансформатора T1, но это не обязательно.

Особое внимание уделите полосовому фильтру на 144мГц от точности настройки зависит чувствительно приема на диапазоне 2М (145мГц) или вообще может отсутствовать прием.

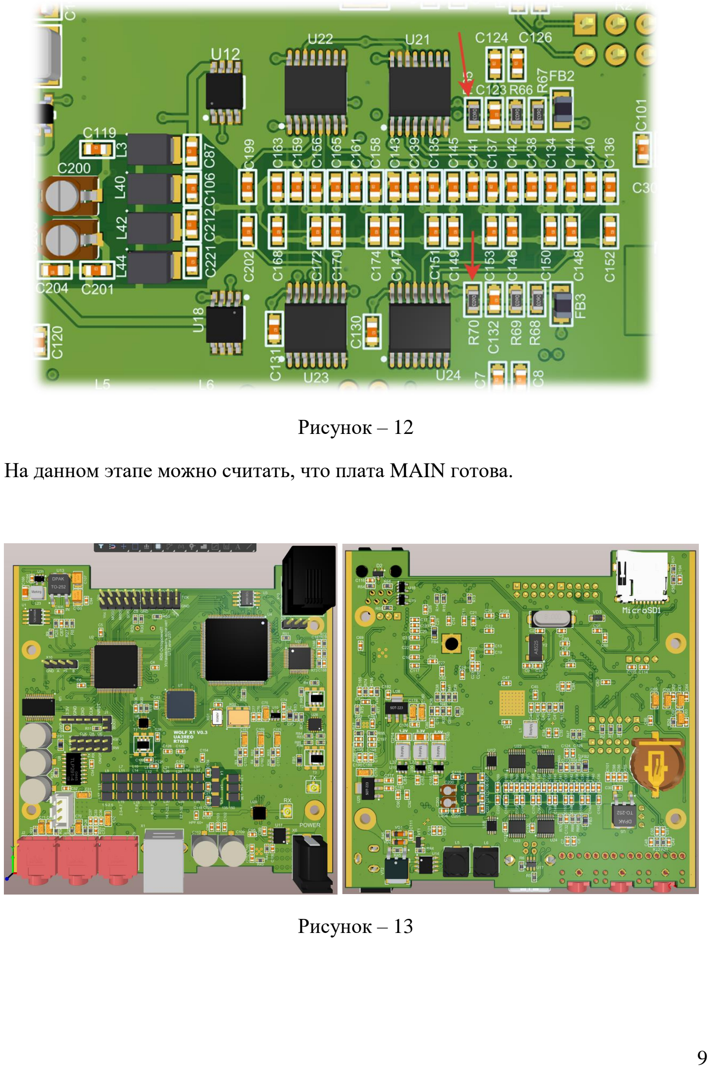
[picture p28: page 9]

Рисунок – 12

На данном этапе можно считать, что плата MAIN готова.

Рисунок – 13

СБОРКА «СРЕДНЕЙ» ПЛАТЫ

она служить для экранирования платы UM от платы MAIN, а также для соединения платы MAIN с платой UM, и на ней размещен модуль WI-FI.

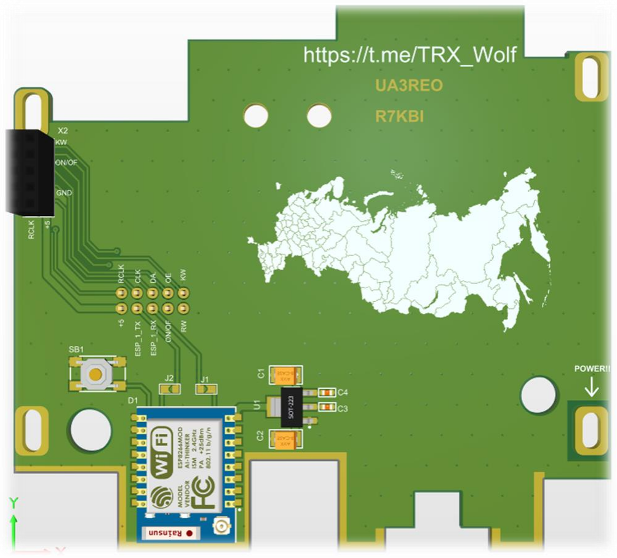
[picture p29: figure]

Рисунок – 14

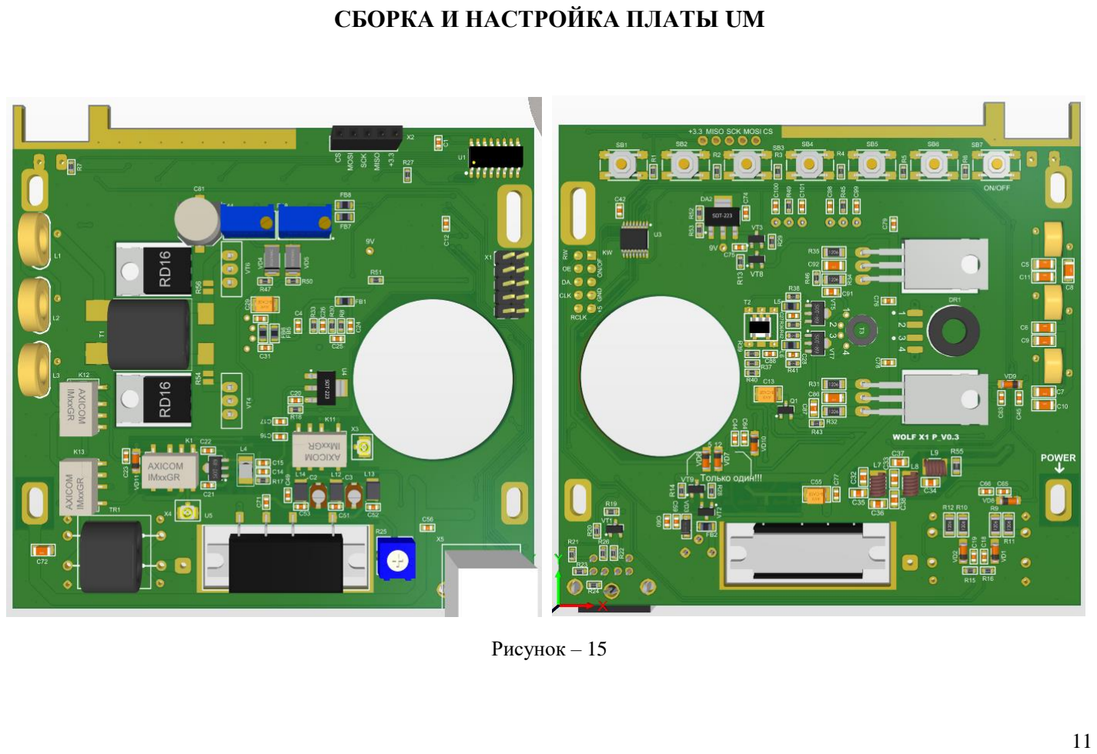
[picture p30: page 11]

11

СБОРКА И НАСТРОЙКА ПЛАТЫ UM

Рисунок – 15

Сборка UM не привязана к последовательности, можно запаивать что есть в наличии. Тут только нужно настроить токи покоя для транзисторов VT4, VT6, и установить напряжение на выводе VGG (2 пин) модуля U5 RA08H1317M построечным резистором R25, оно должно соответствовать графику на конкретный модуль, для примера график на рис.16

Не гонитесь за большой мощностью не нужно «стрелку ложить»

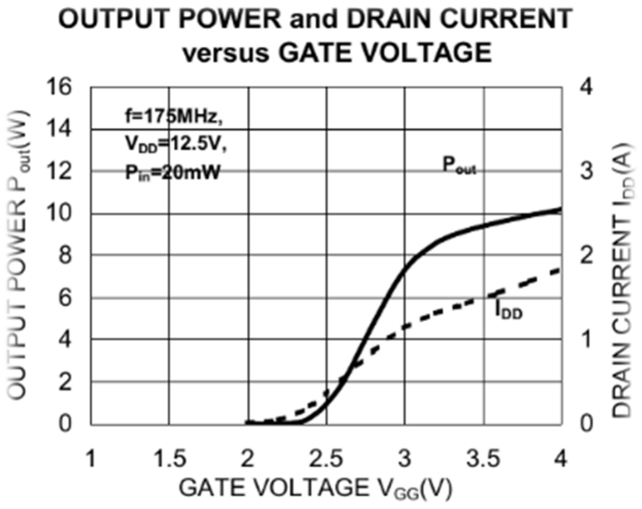
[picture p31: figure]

Рисунок – 16

Проще всего настроить токи покоя для VT4, VT6, которое должно составлять 200ма на каждый, это отвязать плату UM от MAIN от лабораторного источника питания подать напряжение 13.8V через миллиамперметр на переходное отверстие которое является (как рассказывал в пункте 5 ) рис. 17

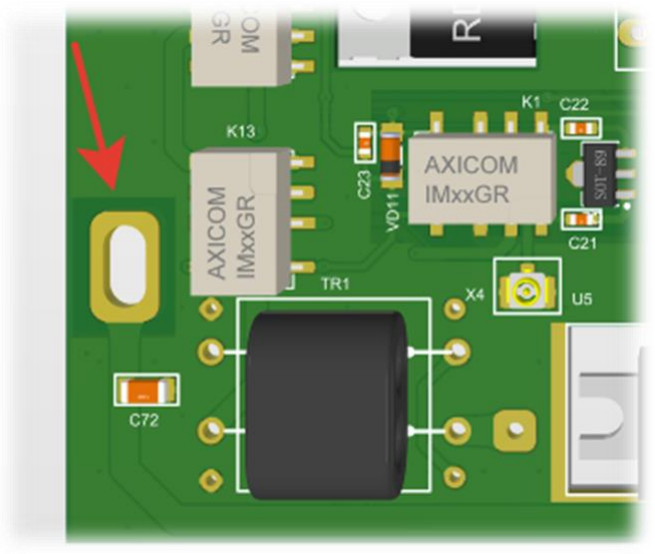
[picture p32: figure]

Рисунок – 17

Далее, чтобы перевести плату в режим TX необходимо запаять перемычку на стабилизатор DA2, подать на прямую напряжение как на рис. 18-19

Рисунок – 18

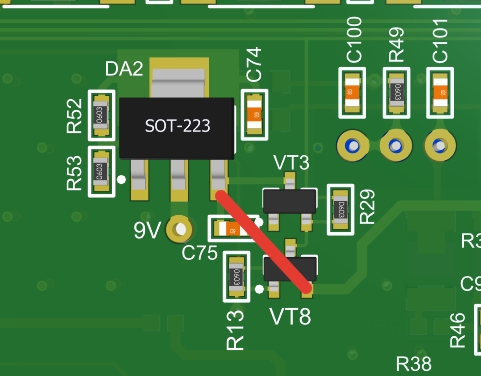
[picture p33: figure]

Рисунок – 19

К выходному трансформатору подключить эквивалент нагрузки 50 Ом. Подстроечные резисторы R44, R48 выкрутить в нулевое положение, и при подаче напряжения показания миллиамперметра должно показать потребление 20ма, по очереди выкручивая движки подстрочных резисторов установить на каждом транзисторе 200ма, учитывая потребление самой платы, должно получится на одном плече 220ма, и при подстройке на втором общее потребление 420ма.

В ревизии платы UM V0.3 рис.20 добавил джампера для установки токов покоя в этом случае можно не учитывать общее потребление платы, после установки токов покоя джампера J1, J2 нужно замкнуть каплей припоя

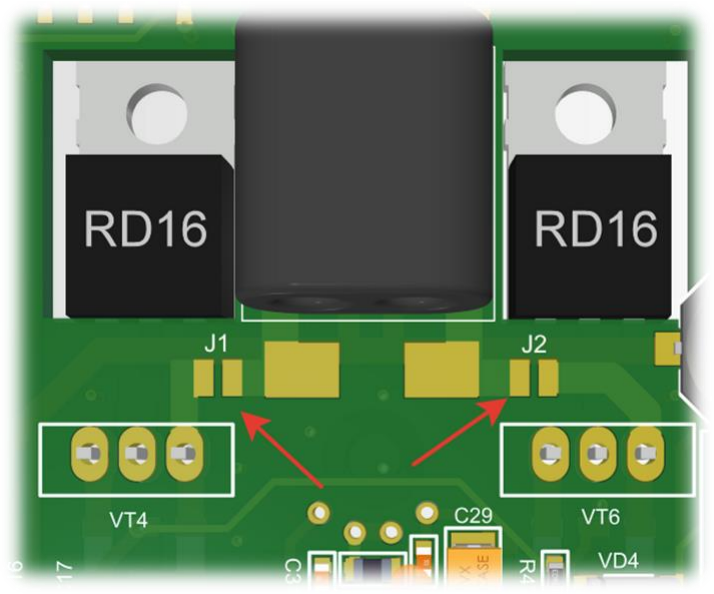
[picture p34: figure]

Рисунок – 20

Не забываем еще снять АЧХ с ФНЧ. Я применял самодельные катушки, рассчитать индуктивность можно в онлайн калькуляторе . (https://coil32.ru/calc/one-layer.html)

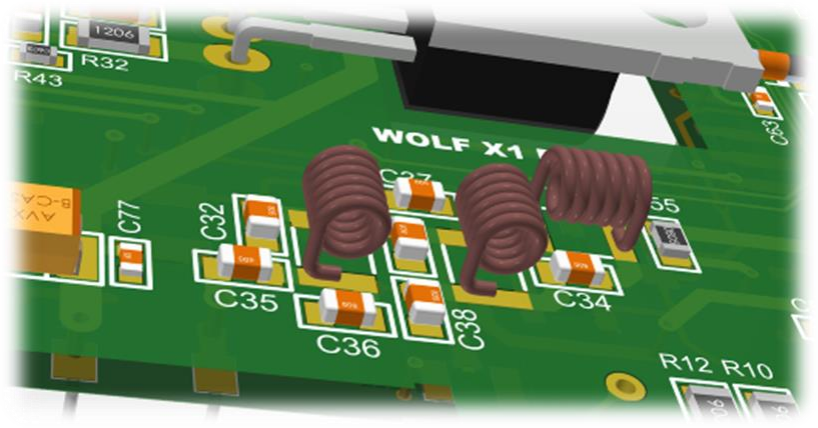
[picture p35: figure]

Рисунок – 21

На этом сборка и настройка платы UM завершена.

КРЕПЛЕНИЕ ДИСПЛЕЯ К ЛИЦЕВОЙ ПАНЕЛИ

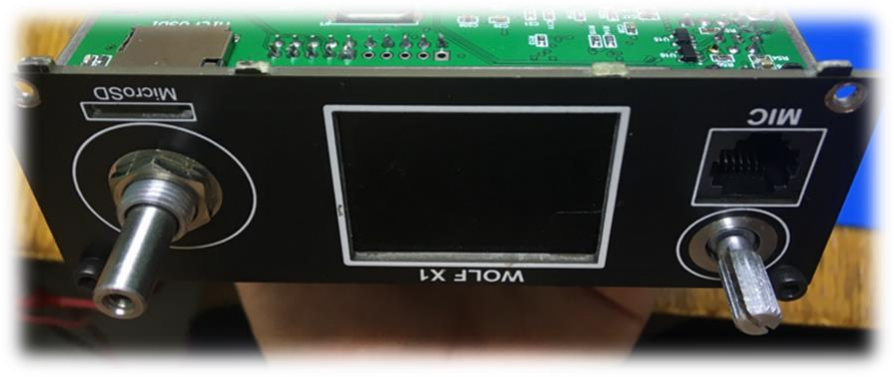
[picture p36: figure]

Рисунок – 22

Тут ничего хитроумного нет 😊позиционируем и лужёным проводом фиксируем.

В процессе наладки можно использовать длинные провода от дисплея, а при финишной сборке необходимо максимально укоротить во избежание ВЧ наводок.

Дисплей | MAIN

GND –––––––––––––––– GND
VDD –––––––––––––––– Vcc
SCL –––––––––––––––– SCK
SDA –––––––––––––––– MOSI
RES соединить с VDD
DC –––––––––––––––– MISO
CS –––––––––––––––– CS
BLK не задействуется

СБОРКА ПЛАТ В ОДИН «БУТЕРБРОД» И УСТАНОВКА В КОРПУС

Рисунок – 23

Расстояние нижней платы MAIN от верхнего слоя и до нижнего слоя платы UM должно быть 23мм рис.24

Рисунок – 24

Я применял латунные стойки длиной 10мм рис. 25 две стойки с учетом толщины средней платы 1.6мм получается 21.6мм отставшие 1.4мм подогнал шайбами.

Рисунок – 25

Когда сложили «бутерброд» можно приступить к сборке его в корпус. Сборка в корпус начинается с платы UM к верхней крышке (в папке с документацией есть файл DWG и PDF с чертежом вырезов в крышке под кнопки, вырез под динамик и крепежные отверстия под транзисторы VT4, VT6, отверстия рассчитаны под транзисторы от центров отверстий в плате, я бы рекомендовал их наметить самостоятельно что бы не промазать. Как это сделать, красим фланцы транзисторов, к примеру лаком для ногтей и прикладываем к крышке, останется след от отверстий, останется просверлить и нарезать резьбу М3. Есть один нюанс, когда будите прикладывать плату для оставления следа, необходима чтобы задний торец платы был на одном уровне с крышкой рис.26

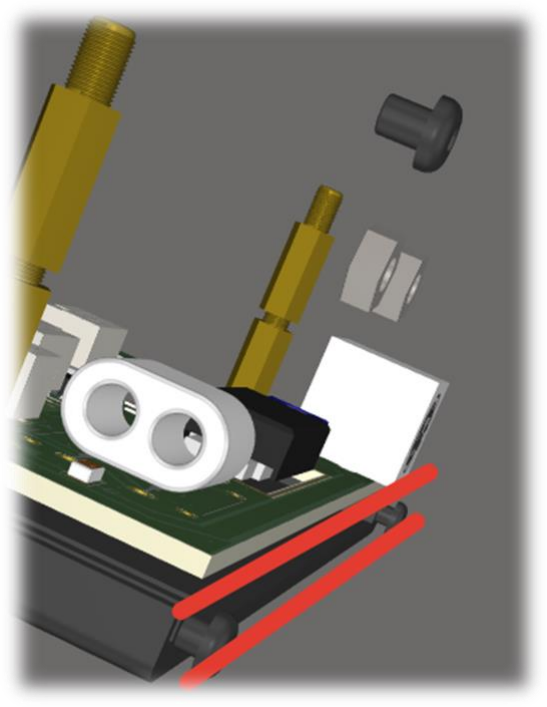
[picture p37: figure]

Рисунок – 26

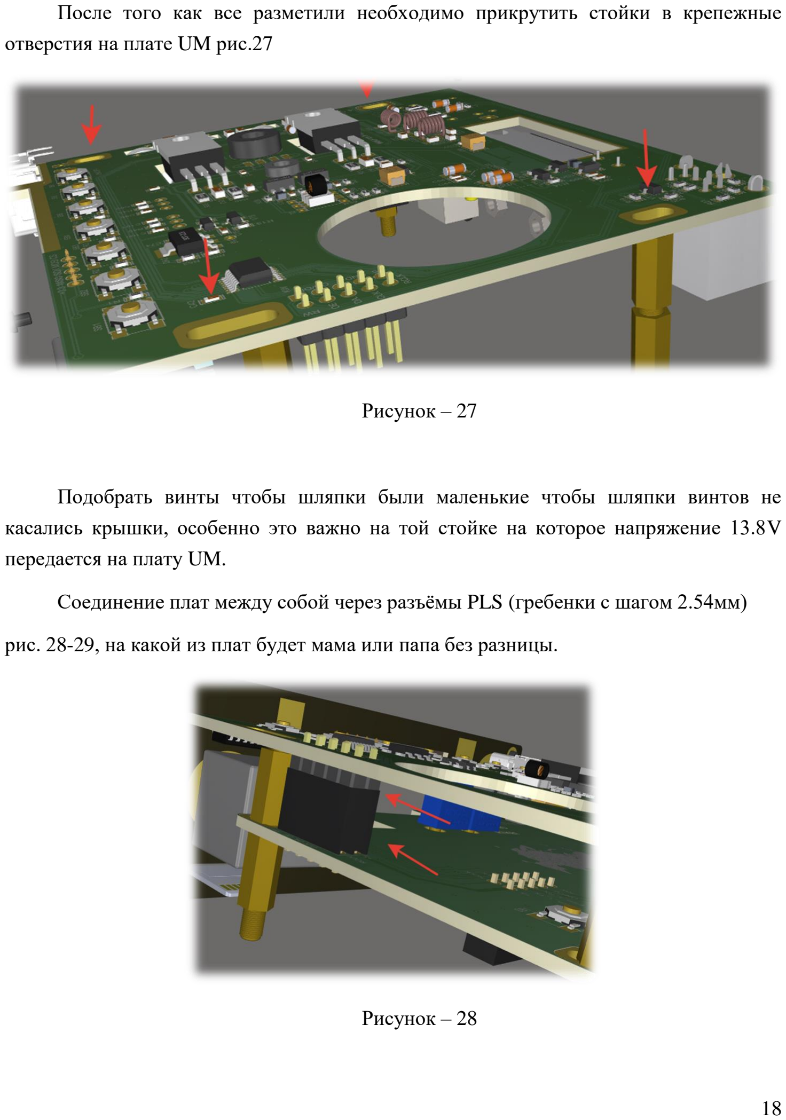
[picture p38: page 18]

После того как все разметили необходимо прикрутить стойки в крепежные отверстия на плате UM рис.27

Рисунок – 27

Подобрать винты чтобы шляпки были маленькие чтобы шляпки винтов не касались крышки, особенно это важно на той стойке на которое напряжение 13.8V передается на плату UM.

Соединение плат между собой через разъёмы PLS (гребенки с шагом 2.54мм)

рис. 28-29, на какой из плат будет мама или папа без разницы.

Рисунок – 28

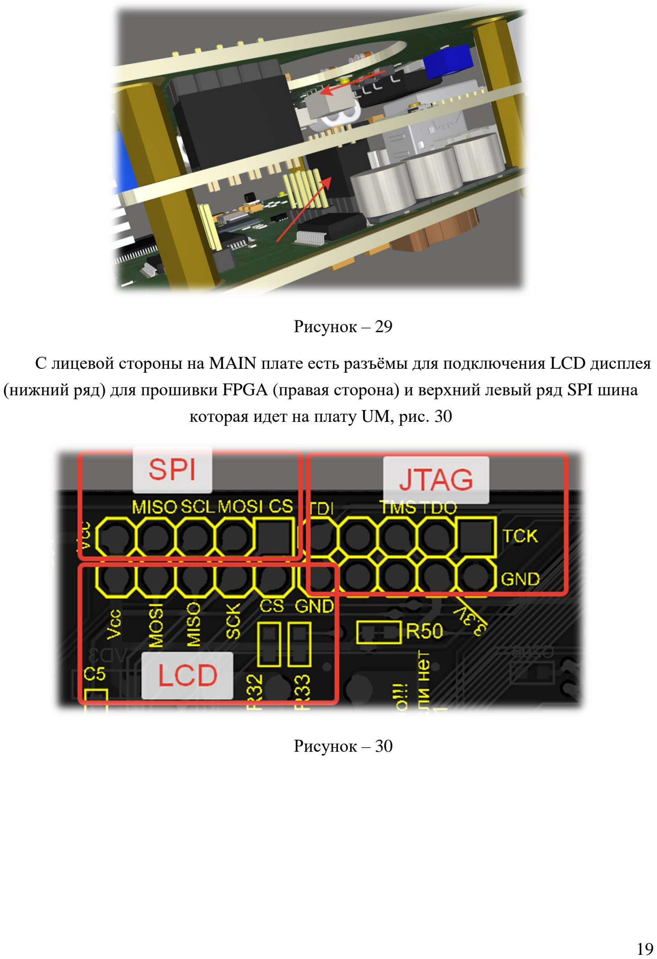
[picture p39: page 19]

Рисунок – 29

С лицевой стороны на MAIN плате есть разъёмы для подключения LCD дисплея (нижний ряд) для прошивки FPGA (правая сторона) и верхний левый ряд SPI шина которая идет на плату UM, рис. 30

Рисунок – 30

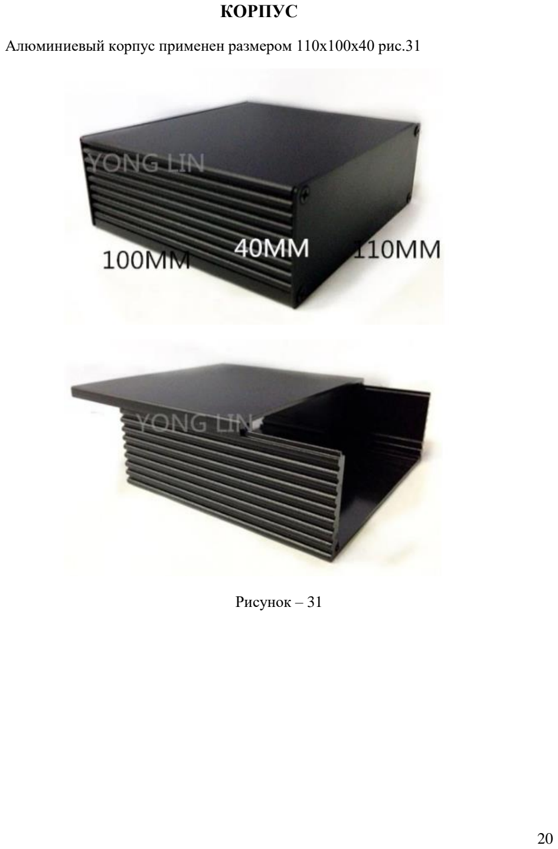
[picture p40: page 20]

КОРПУС

Алюминиевый корпус применен размером 110х100х40 рис.31

Рисунок – 31

ДИНАМИК

В трансивере предусмотрена установка динамика с размерами как на рис. 32

Рисунок – 32

Оставлю ссылки на AliExpress, но на момент написания данной инструкции не обещаю, что они будут активные. Если ссылки не рабочие, поищите по названию SOTAMIA 27мм и AIYIMA 27мм.

### 1. Первая ссылка (https://aliexpress.ru/item/32825276359.html?mp=1&sku_id=64943182055)

2. Вторая ссылка (https://aliexpress.ru/item/4000184341538.html?mp=1&sku_id=10000000678041661)

Можно примерить и другой главное, чтобы поместился в корпусе и был достойное звучание.

ОПТИЧЕСКИЙ ЭНКОДЕР

Энкодер применен ENS1D-441-M00128. Для удобства размещения в корпусе желательно отрезать родной шлейф ближе к энкодеру и запаять мягкий провод, я применил провод МГТФ, но это не принципиально.

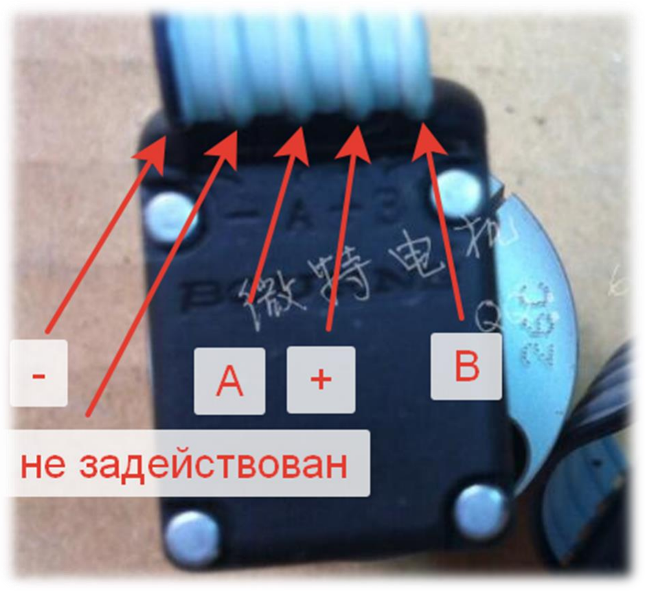
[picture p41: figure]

Рисунок – 33

На рис.33 показана распиновка энкодера, на нем есть не задействованный один проводник, нужно быть внимательным не перепутать при подключении к разъёму X10 на плате MAIN.

Выход EXTERNAL

Гнездо EXTERNAL на задней крышке трансивера, предназначен для управления внешним усилителем мощности. Его можно выпаять из старых материнских плат от ПК, ну или купить новый, а ответную часть, можно срезать от старой клавиатуры или мыши.

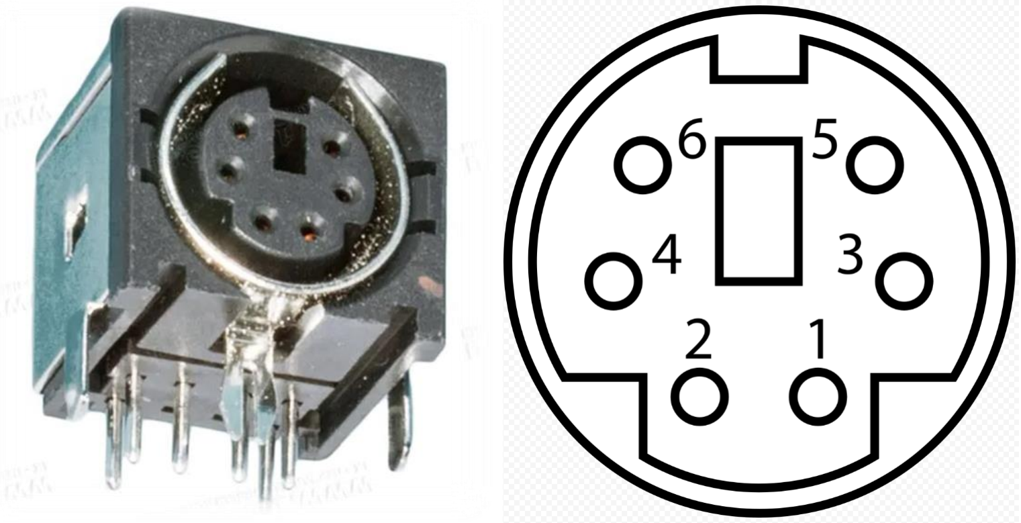
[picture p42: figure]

Рисунок – 34

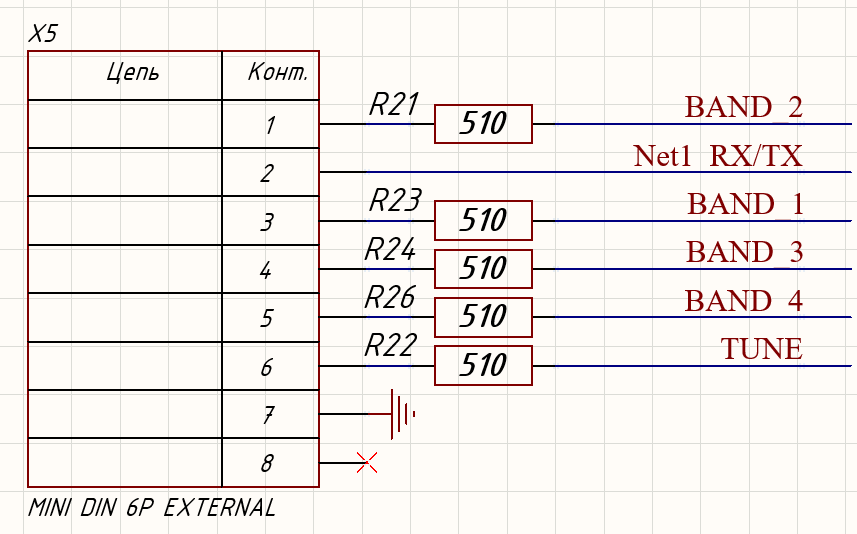
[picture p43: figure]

Рисунок – 35

Переведя трансивер на передачу (TX) на контакте «2» будет присутствовать 13.8В. А на остальных контактах на оборот подтянется к «земле». Назначение контактов 1,3,4,5 можно переназначить в меню трансивера.

Настройка ДПФ

Как настроить ДПФ на НЧ диапазоны описывать не стану тут все традиционно)), а вот как настроить 2м диапазон напишу, как, а точней по рекомендую.

### 1. выход NanoVna (или любой другой измерительный прибор) цепляем разъём RX

материнки (предварительно откалибровав NanoVna в ноль на проводах какими подпаиваем), второй конец прибора подключаем к конденсатору C122 при этом конденсатор нужно отпаять.

### 2. паяем последовательные фильтры режектора, ДПФ замыкаем, добываемся

максимального провала в FM диапазоне при низких потерях на 145мгц.

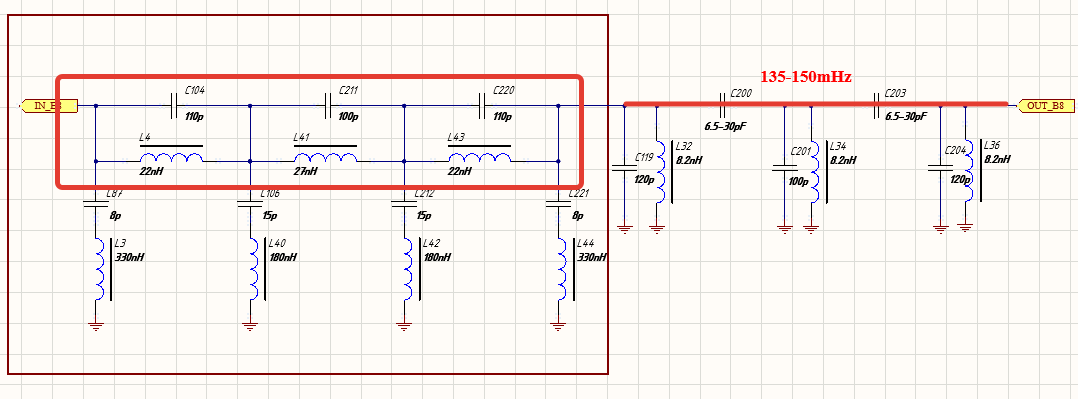
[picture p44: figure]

Рисунок – 36

### 3. поочередно подпаиваем параллельные звенья режектора, углубляя подавление в

FM.

### 4. собираем ДПФ на 145мгц, конденсаторами добиваемся максимального пика на

145мгц. Если он выше при любых настройках - поднимаем поочерёдно ёмкости конденсаторов С119, С201, С204 добиваясь нужного эффекта. Если низко -снижаем ёмкость

Если у Вас версия MAIN платы младше V0.3 и для выравнивания АЧХ на 2м диапазоне, необходимо 9 вывод (2A) микросхем FST3253 U21, U22,

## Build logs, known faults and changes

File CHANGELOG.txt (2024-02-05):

----Version 9.3.1----
+HARDW: W-Lite: Исправление марки диодов в схеме MotherBoard. Автор R7KBI
+STM32: W-Lite: Исправлена регулировка скорости водопада. Автор RA3RBE
+STM32: Для CW моды добавил дополнительное предусиление в ПЧ, Tnx RU4PN
+STM32: Обдув в режиме Full теперь работает до установленной температуры, а не до Medium stop, Tnx RU4PN
+STM32: Частота по умолчанию для 2м бенда установлена в 145.500, Tnx R7KBI
+STM32: При активном Free Tune, переключение Zoom/Samples перемещает спектр в центр полосы приёма, Tnx UR7CQ
+STM32: W-Mini: добавлены дополнительные настраиваемые функциональные кнопки (FT8/VOX/...), Tnx R6DLC
+STM32: Исправлена работа функциональной кнопки MEMORY, Tnx SP7MFR
+STM32: Добавлена настройка "Center After Idle", центрирующая спектр Free Tune во время бездействия более 20 секунд, Tnx R7KBI
+STM32: Изменение положения навигационных кнопок на 8-ми кнопочной версии, Tnx SP7MFR
+STM32: В сервис Self Test добавлена палитра для проверки подключения шины LCD панелей
+STM32: Устранение различных ошибок
+STM32: W-Lite: Добавлена настройка экрана (Mirror) при первом старте программы. Автор RA3RBE
+STM32: Обновлены системные библиотеки

----Version 9.3.0----
+HARDW: Wolf-Motherboard-rev34: Исправления в посадочных местах, переход на USB Type-C, разъём для подключения I2C периферии и прочие исправления. Автор R7KBI
+HARDW: Wolf-Front-Unit-7-rev6: Исправления в посадочных местах. Автор R7KBI
+OTA: Сервер обновлений и сервисов переведён в Нидерланды
+STM32: W-Mini: Добавлена поддержка УКВ платы, Tnx R7KBI
+STM32: W-Mini: Автоматический выбор соответствующей функциональной страницы кнопок при активации режима MEMO / моды CW, Tnx R7KBI
+STM32: Добавлена регулировка ручного Notch-фильтра, Tnx EA7HOG
+STM32: Добавлена поддержка бенда 630м и трансвертеров 1.2см
+STM32: Вывод текущей даты на 7 дюймовых дисплеях, Tnx ats52
+STM32: Добавлена "запятая" в окно ручного ввода частоты, Tnx R4HID
+STM32: Устранение ошибок, Tnx ats52
+STM32: W-Lite: Включено декодирование CW сигнала
+STM32: W-Lite: Включены настройки трансвертеров
+STM32: При активации SPLIT принудительно отображается второй VFO на водопаде, Tnx UR7CQ, UT8EU
+STM32: При активации SPLIT свайп\тап по водопаду перемещает вторичный VFO, а не основной, Tnx UR7CQ
+STM32: Функция MEMORY добавлена в нижний ряд настраиваемых кнопок (через меню), Tnx SP7MFR

----Version 9.2.1----
+STM32: Устранение ошибок, Tnx Martin AD, SP7MFR

----Version 9.2.0----
+HARDW: Wolf-2: Обновлена плата УКВ, Автор RU4PN
+HARDW: W-Lite: Исправлена шелкография у стабилизаторов на материнской плате, Tnx Андрей Сергеев
+STM32: Долгое нажатие на водопад переключает режимы Free Tune / Center Tune. Автор BD6MM
+STM32: Улучшена поддержка некоторых видов SD карт, Tnx UN7LAS
+STM32: Обновлены параметры "Repeater offset, kHz" по умолчанию, Tnx SP7MFR
+STM32: Уменьшен уровень передачи записанного WAV файла, Tnx UZ5DM
+STM32: Доработки процесса OTA и прошивки с SD, Tnx RV9CT, SQ7BCN
+STM32: FFT Automatic теперь принимает 3 значения: Full - автоматический выбор верхней и нижней границ, Half - авто нижний и ручной верхний, No - ручное выставление диапазона уровней спектра. (Не забывайте выбрать нужный FFT Scale Type, чтобы диапазон уместился на экране). Tnx ats52
+STM32: ENC2 теперь корректно работает на AM/NFM/WFM модах, обновлены настройки по умолчанию, Tnx R3TKS
+STM32: Прописаны моды по умолчанию за границами бендов, Tnx RU4PN
+STM32: W-Lite: Добавлено управление 6м ФНЧ, Tnx UN7FHS
+STM32: Для 9-ти кнопочных версий (WF-100D / Wolf-2) перемещены кнопки пролистывания к центральной, чтобы надписи соответствовали расположению кнопок, Tnx SP7MFR
+STM32: Устранение ошибок, Tnx R4FZ, SP7MFR, R4HID, RU4PN

----Version 9.1.0----
+HARDW: Motherboard: Обновлён номинал резистора R10 в обвязке аудио-кодека, выбирается по необходимому усилению микрофона, Tnx R3TKS
+STM32: W-Mini: Перестроен интерфейс главного экрана. Иконки режимов работы выстроены в один ряд, увеличено место под основную частоту. Автор RA3RBE
+STM32: W-Mini: Ниже основной частоты выведена частота второго VFO. Автор RA3RBE
+STM32: W-Mini: Добавлен режим каналов. В меню установлены 20 каналов, можно менять им имена, не более 6 букв. Автор RA3RBE
+STM32: W-Mini: Изменен режим SCAN. В режиме MEMO сканирование идет по заполненным каналам памяти. Автор RA3RBE
+STM32: W-Mini: Добавлена иконка работы WiFi. Автор RA3RBE
+STM32: W-Mini: Множество мелких изменений. Автор RA3RBE
+STM32: W-Lite: Открыта регулировка RF GAIN на 6 м. Автор RA3RBE
+STM32: Обновлены настройки АРУ по умолчанию (аккуратней с импортом старых), Tnx R3RM, RU4PN
+STM32: Разделены настройки "AGC Gain target" для CW и SSB, Tnx R3RM
+STM32: Добавлена настройка HPF фильтра для DIGI мод, Tnx SP3JDZ
+STM32: Repiter mode теперь сохраняется в память частот, Tnx SP7MFR
+STM32: Переработаны настройки шага перестройки частоты: Для каждой моды выставляется свой базовый шаг, и настраивается множитель для FAST и ENC2 шагов
+STM32: Добавлена возможность настроить индивидуальный шаг перестройки для DIGI мод, Tnx SP7MFR
+STM32: Устранение ошибок, Tnx Serg, R4HID

----Version 9.0.1----
+STM32: Исправлена ошибка "Line length error", Tnx SP7MFR
+STM32: Добавлен кГц разряд при сохранении в память частоты >100МГц, Tnx SP7MFR
+STM32: Добавлена настройка "ATU Mem step, kHz", регулирующая шаг ячеек памяти автотюнера, Tnx R7KBI
+STM32: Исправлена ошибка с полным пропадаем звука в WFM

----Version 9.0.0----
+FPGA: W-Mini: Добавлены прошивки с поддержкой новых плат
+STM32: W-Lite: Добавлены команды САТ интерфейса DN,UP. Автор RA3RBE
+STM32: Начало разработки Satellite Mode (режима работы через спутники). Реализовано скачивание TLE, выбор спутника и отображение элевации\азимута для текущего QTH
+STM32: Исправлена работа команды САТ интерфейса NR, Thanks Кшисек SP7MFR. Автор RA3RBE
+STM32: Оптимизация скорости работы математических функций
+STM32: В режиме FT8 добавлена регулировка мощности основным энкодером при ТХ, Tnx RU4PN
+STM32: Wolf-2: Увеличена точность определения нажатия на кнопки лицевой панели
+STM32: Wolf-2: Добавлена возможность регулировки полосы фильтра в модах DIGI отдельным энкодером
+STM32: Ручной ввод частоты вынесен в отдельную кнопку
+STM32: По умолчанию, при сохранении частоты в память, в название канала пишется частота, далее можно отредактировать имя через меню
+STM32: Wolf-Mini: Добавлена регулировка IF Gain второстепенным энкодером
+STM32: Для каждого канала памяти индивидуально сохраняется настройка CTCSS, Tnx SP7MFR+SP7GRV
+STM32: Вернул старый CW декодер, но с исправлениями проблем, Tnx BD6MM
+STM32: Улучшена защита от проглатывания первой точки в CW, Tnx BD6MM, Serg
+STM32: Переработан код электронного ключа для более точной генерации символов, Tnx BD6MM
+STM32: Добавлена настройка CW "Edges smooth, ms", отвечающая за сглаживание фронтов сигнала
+STM32: При выходе из FT8 декодера трансивер возвращается в предыдущую частоту\моду, Tnx UN7LAS
+STM32: Устранение ошибок, Tnx UZ5DM, ats52, EA7HOG, BD6MM

----Version 8.6.4----
+STM32: W-Lite: Добавлены команды САТ интерфейса NB,NR,NT,PA,RA. Автор RA3RBE
+STM32: W-Lite: Расширена область приема АМ вниз до 100кгц, Автор RA3RBE
+STM32: Вернули настройку Encoder2 on fall, настраивающую режим работы ENC2
+STM32: Переделан механизм анти-дребезга энкодера (аккуратнее с импортом старых калибровок ENC2, могут не подойти)
+STM32: Вернул регулировку уровня предусиления перед сжатием сигнала "CESSB Compress"
+STM32: Добавлена поддержка трансвертеров на 144мгц, Tnx R6DLC
+STM32: Устранение ошибок, Tnx R6DLC, RA9N

----Version 8.6.3----
+STM32: W-Lite: Подвинул индикатор полосы пропускания и подпись под ним, Автор RA3RBE
+STM32: Устранение ошибок, Tnx R3RM, R7KBI

----Version 8.6.0----
+STM32: W-Lite: Расширил место под АТТ, Автор RA3RBE
+STM32: W-Lite: Перестановки в карусели, Автор RA3RBE
+STM32: W-Lite: Убрал клавишу IF и вместо нее сделал CESSB, Автор RA3RBE
+STM32: W-Lite: Ограничил перестройку "по кругу" IF GAIN, Автор RA3RBE
+STM32: W-Lite: Вернул в карусель клавиши BAND+, BAND- и NB, Автор RA3RBE
+STM32: W-Lite: на спектре выводятся маркеры сохраненных частот, маяков, смещение от несущей в SAM
+STM32: W-Mini: Добавлен "пиксель" в правой части экрана, отображающий статус WiFi соединения, Tnx R7KBI
+STM32: W-Mini: управление NB выведено в нижнюю карусель функциональных кнопок, Tnx R7KBI
+STM32: Переработка Noise Blanker, Tnx R3RM, RA3RBE
+STM32: Переделаны функции-обработчики сигналов с энкодеров, Tnx RA3RBE
+STM32: Добавлена настройка VCXO Correction для точной подстройки отклонения частоты генератора от эталонного
+STM32: Добавлена поддержка 12.8МГц TCXO, Tnx ats52
+STM32: Разделены настройки Mic Gain для AM и FM
+STM32: На спектре выводятся маркеры сохраненных в память частот, Tnx Martin AD
+STM32: Добавлена настройка "FFT BW Position" для регулировки положения отрисовки полосы приёма на FFT\WTF
+STM32: Добавлен режим "Delay" для "FFT BW Position" (отрисовка с временной задержкой), Tnx ats52
+STM32: ATU теперь хранит настройки с шагом в 50кГц для каждой антенны, Tnx UT8EU
+STM32: Увеличено количество каналов памяти на 7 дюймовках, Tnx SP7MFR
+STM32: Оптимизация работы CW декодера
+STM32: Добавлена настройка "A/B Balance", регулирующая баланс каналов в режимах двойного приёмника A+B и A&B, Tnx SP7MFR
+STM32: Если режим вторичного энкодера переключен на "MEM", и есть сохранённые частоты в память, то функция SCAN ведётся по ним, Tnx EA7HOG
+STM32: Отключена компрессия в CESSB, оставил только контроль огибающей квадратуры
+STM32: Устранение ошибок, Tnx RV9CT, UN7FHS, SP7MFR, UZ5DM, BD6MM, R7KBI, Adi, Vit

----Version 8.5.1----
+STM32: Устранение ошибок

----Version 8.5.0----
+HARDW: Доработки по плате тюнера Wolf-2, Tnx RU4PN
+STM32: Доработки по работе основного энкодера в системном меню, Tnx RA3RBE
+STM32: Уменьшен шаг калибровки шунта INA226, Tnx R5ZX
+STM32: Добавлена поддержка плат с 4 антенными выходами, Tnx R2AJI
+STM32: Изменён цвет подсветки при отображении второго VFO на спектре, Tnx SP7MFR
+STM32: Добавлены узкополосные SSB фильтры, Tnx SP7MFR
+STM32: Для RTTY декодера устанавливается узкая полоса фильтра, Tnx EA7HOG
+STM32: Добавлено меню редактирования названий каналов памяти, Tnx Martin AD
+STM32: Записи эфира складываются в отдельную директорию Recordings, Tnx Martin AD
+STM32: W-Lite: Убраны квадраты вокруг индикаторов режимов как не несущие полезной нагрузки, только загромождающие экран, Автор RA3RBE
+STM32: W-Lite: Индикаторы распределены равномерно по сторонам экрана визуально разгружая центр экрана, Автор RA3RBE
+STM32: W-Lite: Выведена на экран частота второго VFO, Автор RA3RBE
+STM32: W-Lite: Режимы второго энкодера выделены на экране белой рамочкой, Автор RA3RBE
+STM32: W-Lite: Удалена клавиша "LOCK", блокировка трансивера осуществляется нажатием на кнопку второго энкодера, Автор RA3RBE
+STM32: W-Lite: Скорость работы основного энкодера уменьшается в 10 раз при переходе в меню. Это удобно при наборе имени и прочего, Автор RA3RBE
+STM32: W-Lite: Добавлены 20 ячеек памяти. Можно запоминать в них текущую частоту, читать частоту из памяти и присваивать ее основной частоте, Автор RA3RBE
+STM32: W-Lite: Можно стирать содержимое ячейки, если повторно записать в нее ту же самую частоту, Автор RA3RBE
+STM32: W-Lite: Режим работы с памятью выбирается нажатием на кнопку второго энкодера до появления надписи "Memory". Перебирать каналы можно вращением второго энкодера. Запись в память и извлечение из нее осуществляется кнопками в нижней прокрутке "Mem->Fr" и "Fr->Mem", Автор RA3RBE
+STM32: W-Lite: Добавлен индикатор “SPLIT” в режиме SPLIT, при смене диапазона режим SPLIT выключается, Автор RA3RBE
+STM32: W-Lite: Добавлен индикатор “MUTE” при долгом нажатии на клавишу MUTE, Автор RA3RBE
+STM32: W-Lite: При длительном нажатии на клавишу AGC сделан переход в пункт меню AGC MAX GAIN, Автор RA3RBE
+STM32: W-Lite: Уточнены константы работы с тангентой MH-48, Автор RA3RBE
+STM32: Добавлен режим "CW In SSB", позволяющий на передачу работать телеграфом, возвращаясь обратно в SSB на приём, Tnx SP7MFR
+STM32: Режимы SAM-LSB и SAM-USB вынесены в отдельные моды, Tnx ats52
+STM32: Устранение ошибок, Tnx RA3RBE, R3TKS, UR8IP, SP7MFR, Papandupolo, UR5VLC, Виталий

----Version 8.4.2----
+STM32: Устранение ошибок, Tnx R3RM, SP7MFR, RA3RBE, R7KBI

----Version 8.4.0----
+STM32: В калибровках реализован выбор сопротивления шунта цепи INA226 датчика
+STM32: Поддержка нескольких наборов калибровок для импорта\экспорта, Tnx UT8EU
+STM32: AGC Threshold отключается при активном DNR
+STM32: Разнесены настройки Mic Gain для AM/FM и SSB мод, Tnx R6DLC
+STM32: В калибровки добавлена RF-плата "NONE", выбранная по умолчанию, Tnx Vit
+STM32: Добавлена калибровка скорости вентилятора в Medium режиме, Tnx RU4PN
+STM32: Добавлено отображение других пользователей трансивера Волк на спектре через WiFi. Настройка называется "Wolf Cluster", Tnx RV9XG
+STM32: Добавлена калибровка для компенсации аттенюатора на с-метре, Tnx ats52
+STM32: Добавлена настройка шага регулировки ручного Notch-фильтра, Tnx EA7HOG
+STM32: Добавлен режим Free Tune, позволяющий перемещать полосу приёма по спектру не меняя центральную частоту самого спектра, Tnx R7KBI
+STM32: При отключении тюнера отображается соответствующая надпись на CN/CN+ темах, Tnx SP7MFR
+STM32: Добавлен выбор режима работы SAM демодулятора: Stereo\LSB\USB, Tnx ats52
+STM32: Добавлена возможность переименовывания названий CW макросов на функциональных кнопках, Tnx UZ5DM
+STM32: На CN/CN+ темах выводится текущий WPM в CW моде, Tnx R9IT
+STM32: На CN/CN+ добавлена возможность открыть окно выбора моды VFO-A, Tnx F4EXB
+STM32: Доработки оформления системного меню, Tnx BD6MM
+STM32: Во время записи\воспроизведения файла в файл-менеджере отображается время, Tnx BD6MM
+STM32: Добавлена функция Auto CW, переключающая моду на CW при работе ключом, Tnx SP7MFR
+STM32: Разделены настройки фильтров VFO-A и VFO-B, Tnx SP7MFR
+STM32: Wolf-Lite: Поддержка стилей FFT контур и градиент+контур, Tnx RA3RBE
+STM32: Wolf-Lite: Различные оптимизации, Tnx RA3RBE
+STM32: Устранение ошибок, Tnx RC3RF, ats52, R3RM, RA3RBE, Alex, Гена, R7KBI

----Version 8.3.1----
+STM32: Бенды 6м\FM\2м теперь отключаемы через калибровки
+STM32: Wolf-2 Кнопка TX переключает между TX/RX, а не включает TX только во время нажатия, Tnx UT8EU
+STM32: Добавлена настройка "RX AUDIO Mode", позволяет управлять линиями аудио: стерео, только левый канал, только правый, Tnx RU4PN
+STM32: Добавлена калибровка датчика INA226 по напряжению, Tnx RU4PN
+STM32: Добавлена калибровка переворота тачпада по вертикали, Tnx UT8EU
+STM32: Добавлена настройка "AGC Threshold", включающая порог открытия АРУ, Tnx R7KBI
+STM32: Устранение ошибок, Tnx RU4PN, Дмитрий, R5ZX, Alex

----Version 8.3.0----
+STM32: Добавлен Self Test для диапазона 145МГц, Tnx Serg Iv
+STM32: Добавлены калибровки для индивидуальной настройки функций DTR/RTS линий CAT/Debug портов
+STM32: Добавлена калибровка для инверсии IQ сигнала, передаваемого по USB, Tnx Виктор Георгиевич
+STM32: В Self Test добавлена проверка звука (вывод сигнала в левый и правый канал), Tnx RU4PN
+STM32: Доработки для Wolf-Mini, Tnx R7KBI
+STM32: Различные оптимизации кода
+STM32: В настройки выведен выбор уровня принимаемого стерео-FM канала
+STM32: Добавлен 8кГц эквалайзер для WFM, Tnx R7KBI
+STM32: Обновление настроек эквалайзера для выравнивания АЧХ по умолчанию (не используйте предыдущие настройки), Tnx R7KBI
+STM32: Во время передачи встроенным FT8 блокируется управление частотой главным энкодером, Tnx UZ5DM
+STM32: Добавлен сервис, отображающий прогноз тропосферного прохождения (регион выбирается в настройках), Tnx Martin AD
+STM32: Добавлена возможность сохранять\загружать 3 комплекта настроек под разные нужды, Tnx Martin AD
+STM32: Экспорт\импорт настроек и калибровок разделен по разным файлам (полезно при обновлении прошивки, чтобы импортировать только калибровки)
+STM32: Настройки RX LPF CW/SSB/AM/FM фильтров сохраняются для каждого диапазона индивидуально, Tnx DL1EGQ
+STM32: Устранение ошибок, Tnx R6DLC, R7KBI, UZ5DM, Martin AD

----Version 8.2.0----
+STM32: Wolf-Mini: отображаются активные функции в нижнем меню, Tnx R7KBI
+STM32: Кнопки пагинации в нижнем меню перекрашены в отдельный цвет, Tnx R7KBI
+STM32: Добавлен простой алгоритм сглаживания границ экранных шрифтов, Tnx Aleksey Thunder
+STM32: Добавлено увеличение спектра x32 (полоса 1.5кГц при samplerate 48кГц), Tnx UR8IP
+STM32: Строка с рапортом теперь выводит S9+ значения кратно 5, Tnx R7KBI
+STM32: Режим отображения спектра по умолчанию выставлен в градиент+контур
+STM32: Добавлена FT8 частота для QO-100 трансвертера 10.489.540, Tnx UR8IP
+STM32: Wolf-2: Датчик INA226 включен по умолчанию 
+STM32: Wolf-2: Добавлены сочетания клавиш при запуске: F1 - сброс настроек, F1+F9 - сброс настроек и калибровок, Tune - переход в режим DFU
+STM32: Громкость самоконтроля CW теперь не зависит от общей громкости трансивера, Tnx UZ5DM
+STM32: Wolf-Mini: На экран выводятся текущие значения ATU, Tnx R7KBI
+STM32: Добавлен шаг перестройки AM равный 8.33кГц, Tnx Martin AD
+STM32: Wolf/Wolf-X1/Wolf-2: Частота тактирования ЦАП автоматически адаптируется в зависимости от бенда чтобы избегать пораженных частот на 6м, Tnx DD8BA 
+STM32: Увеличен порядок TX фильтра Гильберта
+STM32: В меню калибровок вынесены настройки тачпада (пороги и время срабатываний), Tnx Martin AD
+STM32: Режим FAST сохраняется для каждого бенда отдельно, Tnx R6DLC
+STM32: Устранение ошибок, Tnx RU4PN, R7KBI, SP3JDZ

----Version 8.1.2----
+STM32: Устранение ошибок, Tnx SP5TAA, R7KBI, DJ0AK, Виталий, SP3JDZ

----Version 8.1.0----
+HARDW: Обновлены версии плат Wolf-2, Tnx RU4PN
+STM32: Устранены лишние циклы переключений на ВЧ плате RU4PN
+STM32: В режиме Two Signal Tune отключено ограничение мощности по калибровке (Max Tune power)
+STM32: Кнопка Tune в нижнем меню подсвечивается при активном ATU, Tnx RA3WSA
+STM32: Долгим нажатием на кнопку Tune включается\отключается ATU, Tnx UT8EU, UZ5DM
+STM32: Во время записи на SD и воспроизведения с SD в эфир не применяются настройки эквалайзера, Tnx R3TKS, R6DLC
+STM32: Максимальная длина CW макросов увеличена до 60 символов (большие макросы проще редактировать через файл настроек), Tnx UZ5DM
+STM32: Добавлена проверка версии FPGA при запуске, Tnx UA3AAE
+STM32: Добавлен режим "градиент+контур" для настройки FFT Style, Tnx UZ5DM
+STM32: Устранение ошибок, Tnx R9FDL, Виталий, UT8EU, R7KBI, UZ5DM

----Version 8.0.0----
+HARDW: Добавлена плата внешнего PLL для использования внешнего генератора (например GPSDO) в качестве опорного (Папка Schematic\Wolf\Addons\PLL_DL2FW). Автор DL2FW
+HARDW: Устранение ошибок W-Lite, Tnx R7KBI
+FPGA: Уменьшение джиттера тактового сигнала ЦАП
+STM32: Первые эксперименты с Digital-Pre-Distortion (функция скрыта в программируемые кнопки нижнего меню, долгое нажатие - запуск калибровки под текущий бенд)
+STM32: Оптимизации кода
+STM32: Добавлено управление "FT8 Auto CQ" через настройки, Tnx SP7DQR
+STM32: Файл лога FT8 переименован в FT8_QSO_Log.adi, Tnx SP7DQR
+STM32: Вывод количества QSO (строк) в логе FT8, Tnx Анатолий Митрофанов
+STM32: Синтез тона FT8 вместо девиации частоты передатчика, Tnx RV9CT
+STM32: Перевод WiFi сервисов на международный домен
+STM32: Синхронизирован размер полосы ZoomFFT на больших значениях приближения при переходе с RX на TX, Tnx R7KBI
+STM32: Обновление цветов кнопок пагинации нижней панели, Tnx R7KBI
+STM32: Добавлена калибровка датчика KTY81 (установка сопротивления плеча делителя), Tnx R6DLC
+STM32: Обновления для поддержки последних версий плат Wolf-2, Tnx RU4PN
+STM32: Уменьшена частота опроса датчика мощности (для повышения точности измерений)
+STM32: Устранение ошибок, Tnx K4BAC, RU4PN, SP7DQR, R9IT, RU4PN, R7KBI, RC9M

----Version 7.6.0----
+HARDW: Обновлены номиналы обвязки ЦАП, рекомендуется всем актуализировать элементы на своих платах для улучшения качества сигнала, Tnx RA6UAC
+FPGA: Доработки шины обмена с STM32
+STM32: Доработки CW Гаусс фильтра, Tnx R9IT, UT8EU, RU4PN
+STM32: Добавлено меню установки даты, Tnx RN3OZ
+STM32: Добавлена сортировка по имени в файл-менеджере SD карты
+STM32: На клавиатуру добавлены кнопки с символами, раскрашены кнопки enter\backspace\shift, Tnx VU2OBR, R3DBQ
+STM32: В помощь для настройки IF Gain, на спектре отображается текущий уровень АРУ
+STM32: Доработки АРУ + новые настройки задержки усиления АРУ на пиках, Tnx RU4PN
+STM32: Добавлено подменю "Time beacons" в меню "Services" со списком маяков точного времени, Tnx R2AJI
+STM32: На спектре отображаются метки для частот маяков точного времени, Tnx R2AJI
+STM32: При работе в моде SAM отображается разница между частотой приёмника и несущей. Для подстройки частоты опорного генератора по АМ станциям и маякам точного времени (во время передачи постоянной несущей), Tnx R2AJI
+STM32: Добавлен выбор типа ямбического ключа (A / B), Tnx Антон Ивачев
+STM32: Добавлен режим ключа с памятью на один символ, Tnx UT8EU
+STM32: Устранение ошибок, Tnx SP7SP, DL1EGQ, RU4PN

----Version 7.5.0----
+HARDW: Добавлена 3д модель панели для 7 дюймовой версии, Tnx Александр
+STM32: Доработки по цветам меню (вошли в 7.4.1), Tnx R3DBQ
+STM32: Воспроизведение CQ теперь останавливается при повторном нажатии на кнопку, Tnx R4HID
+STM32: Поддержка дробных таймзон (например +3:30), Tnx VU2OBR
+STM32: Увеличен шрифт меню установки времени для 3'5 дюймовых дисплеев, Tnx С1-49
+STM32: Добавлена возможность выбора HPF фильтра в NFM моде, Tnx R6DLC
+STM32: Добавлены настройки "LINE Gain" и "CODEC Gain" для регулировки аппаратного усиления (в кодеке) линейного входа и НЧ выхода
+STM32: Добавлена настройка "ALC Inverted", инвертирующая логику ALC порта (1.0v - 100% мощности, 3.0v - 0%), Tnx SP7SP
+STM32: Добавлена NOFPGA версия прошивки STM32 для Wolf-2, Tnx RU4PN
+STM32: Устранение ошибок, Tnx Андрей, RU4PN, Евгений J, R6DLC, R9IT, R5ZX

----Version 7.4.1----
+HARDW: Обновлены платы для проекта Wolf-2, Tnx RU4PN
+STM32: Устранение ошибок, Tnx R4HID, RU4PN, R6DLC, RA9UCN

----Version 7.4.0----
+STM32: Добавлена настройка "Bottom navi buttons", отображающая кнопки навигации по страницам нижних навигационных кнопок, Tnx R4HID
+STM32: Для настраиваемых функциональных кнопок добавлен режим "NONE", скрывающий кнопку. Если страница содержит только скрытые кнопки - она тоже скрывается из навигации, Tnx R4HID
+STM32: Для второстепенного энкодера добавлена функция перехода между сохранёнными частотами в память (при их наличии), Tnx DL1EGQ
+STM32: Исправление ошибки с отключением FT8, Tnx RV9CT
+STM32: Сокращен интервал синхронизации времени через интернет, Tnx RV9CT
+STM32: Изменён внешний вид системного меню для поддержки тачпада (для 7 дюймовой версии)
+STM32: Устранение мелких ошибок, Tnx R7KBI

----Version 7.3.0----
+HARDW: Добавлены платы и схемы проекта WOLF-2, Tnx RU4PN
+HARDW: Добавлена инструкция для подключения управления внешним усилителем к WF-100D, Tnx SP7DQR, SP7SP
+STM32: Реализована возможность одновременной работы RIT и XIT (для Fine RIT Tune), Tnx UA3RBM
+STM32: Исправления в регулировке калибровок BPF, Tnx R6WAM
+STM32: Доработки по Wolf-2, Tnx RU4PN
+STM32: Доработки по Wolf-Mini, Tnx R7KBI
+STM32: Кнопка Split перемещена ближе к A/B, Tnx SP7SP
+STM32: Repeater Mode теперь настраивается для каждого VFO/бенда раздельно
+STM32: Добавлена настраиваемая функциональная кнопка "Repeater Mode" для нижней панели
+STM32: Перетряхнули меню настроек и калибровок, Tnx RU4PN
+STM32: Уменьшена ступенька на минимуме регулировки громкости, расширен диапазон регулировки в дБ, Tnx R4HID
+STM32: Работает самоконтроль во время передачи WAV в эфир, Tnx R4HID
+STM32: Добавлен режим отладки ошибок I2C (Debug Console), Tnx RU4PN
+STM32: Устранение мелких ошибок, Tnx C1-49, R7KBI

----Version 7.2.0----
+STM32: Автоматическая отправка FT8 связей в онлайн-журнал https://allqso.ru/ (подробнее о журнале на сайте), Tnx RU4PN
+STM32: Немного улучшена отзывчивость тачпада
+STM32: Wolf-2: Доработка управления с лицевой панели
+STM32: При выключенном режиме Fast корректно считает шаг перестройки в AM/FM/WFM
+STM32: Настройки ATU сохраняются для каждой выбранной антенны отдельно, Tnx R4HID
+STM32: Настройки по бендам, в том числе ATU, сохраняются на SD при экспорте, Tnx RU4PN
+STM32: Добавлена настройка "Split freq sync", отвечающая за синхронное изменение частоты VFO в SPLIT режиме, Tnx SP7SP
+STM32: Добавлена настройка "DX Cluster Type", отвечающая за выбор источника данных кластера (reversebeacon.net или dxsummit.fi), Tnx SP7SP
+STM32: CESSB активирован по умолчанию (с предусилением в 1дб, настройте по вкусу)
+STM32: Добавлен режим работы через репитеры "Repeater Mode" со смещением во время передачи из настройки "Repeater offset, kHz", Tnx EA7HOG

----Version 7.1.0----
+STM32: Исправлен запуск ATU при первом старте CQ в FT8, Tnx RU4PN
+STM32: Добавлены 60m и 70cm бенд во встроенный FT8, Tnx DL1EGQ
+STM32: Расширен выбор шага перестройки до 100гц в AM и FM модах
+STM32: Добавлена регулировка крутизны фильтров для CW и SSB мод (помогает от звона)
+STM32: Исправлена проблема с обновлением значка ANT при смене бенда энкодером, Tnx Юрий Колесников
+STM32: Исправлена проблема с импортом значений калибровок QO-100, Tnx UR5VLC
+STM32: Добавлены отдельные настройки эквалайзера для WFM моды, Tnx EA7HOG
+STM32: WF-100D: При смене диапазона кнопками меняется частота открытого FT8 декодера, Tnx RU4PN
+STM32: Исправление разных ошибок

----Version 7.0.0----
+HARDW: Новая версия платы RF-UNIT-BIG-RU4PN-rev5.5, Tnx RU4PN
-Убрано одно звено режекторного фильтра 144МГц, меньше затуханий без потери режекции + переразведен сам RX BPF 2m
-Скорректированы номиналы в УКВ-фильтрах RX/TX
-Выходной BPF 144 переделан в LPF, меньше потери
-Питание на RD16 теперь берется с питания RD100
-Переделаны переходные отверстия - исключены из PADов элементов, на что постоянно ругались инженера JLCPCB
-Переделана коммутация LNA для исключения самовозбуда в некоторых ситуациях
-FB1 и FB2 заменены на BLM21 SMD
-Добавлены резисторы в цепи управления ключей BIAS_ON
-В цепи смещения РД16, РД100 внесены небольшие правки, добавлены емкости
-По затворам РД100 добавлены супрессоры для защиты
-Косметические правки

+HARDW: Добавлена плата Wolf-Adapter-rev2 предназначенная для управления внешними усилителями\трансвертерами\МШУ\фильтрами (максимум 16 каналов) через External порт трансивера, Tnx R7KBI

+STM32: Доработки FT8, Tnx RU4PN, RA6UAC
+STM32: Добавлена поддержка трансвертеров\бенда QO-100, Tnx UR8IP
+STM32: Добавлена функция "Full Duplex" - включает режим одновременного приёма и передачи (можно увидеть свой сигнал), использовать осторожно и не допускать перегрузки входных цепей
+STM32: Расширен список значений для Freq Step FM, Tnx UR5YDW
+STM32: Корректировка границ бендов, Tnx R2AJI
+STM32: Добавлена регулировка скатов фильтров AM/FM настройкой "AM/FM LPF Stages" (больше - круче скаты), Tnx UR5YDW
+STM32: Добавлена калибровка "MAX ChargePump, kHz" для ограничения максимальной частоты ШИМ VCXO корректора, стоит корректировать при проблемах с стабилизацией частоты
+STM32: Доработки CW Decoder
+STM32: Добавлена поддержка FT8 для экранов 320x240 (Wolf-Mini, Wolf-Lite-2), Tnx DJ0AK
+STM32: Wolf-X1: на быстрые кнопки добавлено управление драйвером АЦП, Tnx RU4PN
+STM32: Калибровки "по умолчанию" для External порта установлены под использование платы Wolf-Adapter
+STM32: Добавлена калибровка "ALC Port Enabled" - включающая управление мощностью трансивера внешним усилителем по линии ALC, Tnx R6WAM

----Version 6.8.2----
+STM32: Восстановлена работа прошивальщика FPGA с SD карт (для прошивок FPGA 6.8.0 и далее)
+STM32: Восстановлена работа FT8
+STM32: W-Lite: Исправление переключения Sample Rate, Tnx UN7FHS

----Version 6.8.1----
+STM32: Улучшен процесс подключения SD карты
+STM32: Ограничена частота ШИМ ChargePump

----Version 6.8.0----
+FPGA: Переход на Quartus 22.1 Standart
+FPGA: Добавлена функция отключения VCXO корректора
+FPGA: Добавлена прошивка для Wolf-Lite-2, Tnx DJ0AK
+FPGA: Новый корректор VCXO частоты, Tnx DJ0AK, EU1SW
+STM32: Частота TCXO генератора теперь выбирается в STM32, поддерживаются модели: 5.12, 8, 9.6, 10, 12, 12.288, 13, 14, 14.4, 15, 16, 16.8, 19.2, 19.44, 19.68, 20, 20.48, 24, 25, 26, 27, 28, 30, 32, 38.4, 40, 50 МГц
+STM32: Добавлены настройки шага перестройки частоты для FM/AM мод, Tnx DJ0AK
+STM32: Корректировка бендмапа CB диапазона, Tnx DJ0AK
+STM32: Доработки ATU, Tnx RU4PN
+STM32: Добавлены FT4/FT8/MSK144 регионы на бендмапе 2m/70cm/23cm/13cm/6cm/3cm
+STM32: Добавлена возможность управления бендами (трансвертерами) 23cm/13cm/6cm/3cm через CAT
+STM32: W-Lite: Изменены цвета С-метра на S9+, Tnx R7KBI
+STM32: W-Lite: Доработка управления кнопкой Menu при открытом меню настроек, Tnx RL6MR
+STM32: Доработки FT8 при нестандартных последовательностях ответов (требуется тестирование), Tnx RW4CPA
+STM32: При записи связи FT8 в лог корректно рассчитывается дата\время в UTC исходя из настроек текущей временной зоны, Tnx RU4PN
+STM32: Обновлены тайминги ШИМ RA8875
+STM32: Исправление мелких ошибок

----Version 6.7.0----
+STM32: В режиме отладки Debug console = System в консоль выводятся усреднённые данные о dBm приёмника, полезно для измерений Noise Figure усилителей
+STM32: В случае перегрузки КСВ/ALC датчика выводится значок ошибки OVS, Tnx R7KBI
+STM32: Расширены границы подстройки FFT Automatic, Tnx R4HID
+STM32: 7Inch: Доработка процесса пробуждения LCD от сна по тачу на экран, Tnx DL1EGQ
+STM32: Исправление ошибок переключения режимов ENC2, Tnx DL1EGQ
+STM32: Добавлены прототипы прошивок для Wolf-2, Wolf-Lite-2, Wolf-Mini, Tnx RU4PN, DJ0AK, R7KBI
+STM32: При переключении на WFM не сбрасывается настройка Zoom, Tnx R7KBI
+STM32: Обновлены настройки FFT/WTF во время передачи, Tnx R7KBI
+STM32: Нет ошибок при сбросе настроек\калибровок через меню
+STM32: На Analog/CN темах КСВ выводится с точностью до сотых, Tnx R7KBI
+STM32: Исправлена проблема с TX Start Delay во встроенном FT8, Tnx RU4PN
+STM32: Реализован механизм CW макросов для передачи заранее сформированных сообщений, Tnx R7KBI
+STM32: RIT/XIT не сбрасываются в ноль при повторном включении, Tnx АлександрDX
+STM32: Уточнены границы вещательных бендов, Tnx R2AJI
+STM32: На FFT и в Services->DX Cluster теперь дополнительно выводится информация о AM вещательных станциях (название, страна, мощность), Tnx R2AJI
+STM32: Для встроенного FT8 добавлен диапазон 160m
+STM32: Wolf-Lite: изменение управления, короткое нажатие Menu листает функциональные кнопки, долгое - вход в меню, долгое нажатие на ENC2 - Lock и калибровки, Tnx RL6MR

----Version 6.6.0----
+STM32: Добавлена калибровка RF Gain для 60м и СВЧ бендов, Tnx EA7HOG
+STM32: Кнопка Play переименована в CQ во избежание путаницы, Tnx R6TW
+STM32: Обновлены системные библиотеки
+STM32: Исправления в работе Spectral AGC
+STM32: Исправлен процесс обновления STM32 по OTA на WF-100D аппаратах, применится только со следующего обновления после 6.6.0, Tnx RV9CT
+STM32: При работе через CAT корректно восстанавливаются настройки по диапазонам (например тюнер), Tnx RA9N
+STM32: Обновлены выбранные частоты бендов и трансвертеров "по умолчанию"
+STM32: 7Inch: Добавлена возможность удаления сохранённых MEM частот с помощью повторной записи в ту же ячейку, Tnx EA7HOG
+STM32: 7Inch: Долгое нажатие на кнопку Services сохраняет скриншот экрана на SD карту, Tnx EA7HOG
+STM32: Полупрозрачный маркер полосы на водопаде изменяет свой размер от ширины HPF фильтра
+STM32: Улучшение работы FFT за счёт новой оконной функции Generalized adaptive polynomial optimized Nuttall
+STM32: De-emphasis функция теперь выполняется в аудио-кодеке

----Version 6.5.0----
+FPGA: Улучшена стабильность по приёму
+FPGA: Доработка алгоритма VCXO корректора
+STM32: Исправление оформления в self-test, Tnx Григорий Потемкин
+STM32: WF-100D: На X16 (U32) выведены сигналы EXTERNAL (выбор бенда или трансвертера)
+STM32: При перегрузке по ПЧ (IF Gain), и в следствие нестабильной работы АРУ с искажениями, выводится значок IFO
+STM32: W-Lite: убран пункт меню WiFi settings reset, Tnx C1-49
+STM32: CW Decoder теперь работает и во время передачи, Tnx BD6MM
+STM32: Мелкие исправления по интерфейсу
+STM32: Доработка процесса выхода LCD из затенённого режима, Tnx DL1EGQ

----Version 6.4.0----
+HARDW: Добавлен небольшой README файл по типам лицевых\вч плат
+STM32: Доработки темы для экранов с разрешением в 320 пикселей, Tnx DJ0AK
+STM32: Исправление сохранения последних частот по бендам, Tnx R2AJI
+STM32: Теперь есть возможность настройки ВЧ и ПЧ частот для каждого трансвертера отдельно (70cm/23cm/13cm/6cm/3cm)
+STM32: Актуализирована часть настроек по умолчанию
+STM32: Добавлена настройка "Power for each band", позволяющая устанавливать выходную мощность для каждого бенда\трансвертера отдельно
+STM32: Добавлена настройка "Power for each mode", позволяющая устанавливать выходную мощность для каждой моды отдельно, Tnx DJ0AK
+STM32: Долгое нажатие на экранную кнопку "NB" открывает настройки NoiseBlanker, Tnx RA9N
+STM32: Добавлена калибровка "TOUCHPAD horiz flip", отражающая работу тачпада по горизонтали (для некоторых версий GT911), Tnx RV9CT
+STM32: На не-CN темах восстановлена обводка вокруг кнопок
+STM32: Обновлены цвета цифрового S-метра для S9+ зоны (Волк 3'5+7), Tnx R7KBI
+STM32: На экран выводится выбранный уровень мощности (Волк 7'), по тапу открывается меню с выбором мощности
+STM32: Доработка оформления меню установки времени, Tnx Григорий Потемкин
+STM32: Переход на Keil 5.38 / CMSIS-DSP 1.14.2
+STM32: W-Lite: Исправлен запуск с входом в режим DFU (Включение при зажатой кнопке Band+)

----Version 6.3.2----
+HARDW: Новая версия платы MOTHERBOARD-rev33 от RA9UCN:
-Фильтр T1 на входе заменен на обычный дроссель (L1001 - с ним "фонит" наружу меньше) 
-Дополнительно развязана шина 13,8В идущая на стабилизатор 12В через L1002. Все эти дроссели, включая L37, унифицированы, типоразмер 0630
-L7 и L37 заменены на меньший размер 7*7 мм (в работе проверены, не греются).
-Линия TX к STM защищена диодом D1002 и зашунтирована (опционально) конденсатором C1001
-Разъём MIC_IN2 заменён на трёхконтактный(добавлен PTT), с возможностью запайки с обратной стороны платы для удобства стыковки с FRONT UNIT
-PTT на микрофонный разьем подается через перемычку R1003
-Добавлен дроссель L9 в цепь питания УНЧ
-Линейный аудиовыход с кодека выведен на разьём для экспериментов с внешним УНЧ
-Премычка "BOOT" вынесена ближе к краю платы для удобства программирования
-Увеличена ширина шин питания и добавлено количество переходных отверстий на них
-По возможности разнесены проблемные для начинающих близкорасположенные детали
-Добавлены отверстия для запайки выводов не SMD трансформаторов
-Добавлены отверстия для запайки выводного кварцевого резонатора на 32768 Гц
-Разъемы под батарею, USB, мини-джеки подвинуты ближе к краю
-Немного оптимизирована разводка ST1S10

----Version 6.3.1----
+STM32: Исправлена работа NB на двойном приёмнике, Tnx R4HID
+STM32: Исправлена работа функциональной кнопки CESSB, Tnx R4HID
+STM32: Wolf-3.5: Исправлена работа кнопки NB, SNAP Left назначена на долгое нажатие Notch, SNAP Right назначена на долгое нажатие на Services, Tnx RA9N

----Version 6.3.0----
+STM32: Корректировки в работе Autogainer
+STM32: Корректировки зон тача LCD
+STM32: В ряд нижних кнопок добавлена функция быстрого управления CESSB (функции кнопок настраиваются в меню), Tnx R9FDL
+STM32: Для большего контроля функция SNAP разделена на SNAP влево и SNAP вправо. Autosnap работает в полосе как раньше, Tnx RU4PN
+STM32: Из ряда нижних кнопок убраны стрелки, остался только свайп влево-вправо
+STM32: Функция SNAP теперь работает в SSB и AM модах (в SSB нет несущей, поэтому точность попадания условная)
+STM32: Изменён алгоритм Noise Blanker
+STM32: В настройки вынесена регулировка порога NoiseBlanker, Tnx RA9N
+STM32: Добавлена цветовая гамма водопада BGYRM (черный->синий->зеленый->желтый->красный->фиолетовый), Tnx UN7LAS
+STM32: На экранную клавиатуру добавлен Enter, который возвращает в меню, Tnx UN7LAS

----Version 6.2.1----
+STM32: Исправлена проблема с отображением частоты VFO-B на CN темах, Tnx BD6MM
+STM32: Исправлена проблема с отображением режима ENC2, Tnx Viktor
+STM32: Изменены настройки по умолчанию (например тип CAT по умолчанию теперь TS-2000)

----Version 6.2.0----
+HARDW: Обновлена версия платы RF-UNIT-QRP-RU4PN-rev3, Tnx автору RU4PN
+HARDW: Обновлена схема и BOM плат QRP/SPLIT: Аттенюатор PE4302 заменён на PE4312 без изменений на плате
+STM32: Теперь трансивер может работать с SD, на которых ранее была ошибка Disk Error, Tnx RU4PN
+STM32: Доработаны шрифты в CN теме
+STM32: Расширена зона для тача и холда кнопок на экране
+STM32: Выводится текущий режим ENC2, Tnx B
+STM32: Сброс настроек WiFi на случай ошибок при прошлых обновлениях
+STM32: Исправление расчёта положения RIT индикатора
+STM32: Исправление работы быстрой настройки SQL через второстепенный энкодер, Tnx Sergo K
+STM32: Исправлено отображение кнопки mode на VFO-B темы CN, Tnx R4HID
+STM32: Реализовано отображение DX-кластера на 3D водопаде, Tnx RV9CT
+STM32: Если прошивка ESP-01 слишком старая, то при запуске выводится ошибка (требуется перепрошивка)

----Version 6.1.0----
+STM32: Новые цветовые схемы "CN", "CN+Green", "CN+White" и темы оформления "CN", "CN+", автор BD6MM
+STM32: Обновлена библиотека работы с файловой системой SD карты
+STM32: Доработки CW Snap, Tnx RU4PN
+STM32: В нижней панели кнопок подсвечиваются включенные функции (7 дюймовая версия), Tnx RU4PN
+STM32: Расширены границы регулировки эквалайзеров RX/TX, Tnx UR5YDW
+STM32: Настройки WiFi вынесены в отдельную область EEPROM, которая не сбрасывается при обнулении калибровок и настроек, Tnx UA9ULT
+STM32: 5-ти полосный эквалайзер вместо 3-х полосного, Tnx UR5YDW
+STM32: Исправлена ошибка с исчезновением звука в FM, Tnx RU4PN
+STM32: Скорректировано усиление в FM, Tnx UN7LAS

----Version 6.0.0----
+HARDW: MOTHERBOARD-rev32: Исправлена полярность c77, c75, c80, c85, c125, c126, Tnx EW6D
+HARDW: MOTHERBOARD-rev32: U21 заменён на LM2940S-12, Tnx EA7HOG
+HARDW: MOTHERBOARD-rev32: Убрана диодная сборка D2 BAT54C, Tnx R7KGA
+HARDW: MOTHERBOARD-rev32: Доработки разводки USB изолятора, Tnx R7KGA
+HARDW: Добавлена новая плата RF-UNIT-QRP-RU4PN-rev2, Tnx RU4PN
+FPGA: Увеличена точность коррекции VCXO. Замечено что на некоторых версиях плат WiFi модуль влияет на синхронизацию генераторов, просаживая питание FPGA, рекомендую добавить электролит рядом с модулем, если есть проблема
+FPGA: Включена коррекция VCXO во время передачи, Tnx RA9N
+FPGA: Добавлена прошивка FPGA NO-TCXO, позволяющая делать коррекцию VCXO через ШИМ без использования опорного генератора
+STM32: Расширены варианты регулировки настройки "Freq Step WFM, kHz", Tnx EA7HOG
+STM32: При переключении в моду WFM сбрасывается значение Zoom, Tnx EA7HOG
+STM32: RDS декодер теперь корректно работает при частоте семплирования в 384кГц, Tnx EA7HOG
+STM32: Для Spectrum analyzer шаг перестройки увеличен до 1МГц, Tnx EA7HOG
+STM32: Улучшение работы с трансвертерами
+STM32: В меню сервисов добавлены помошники в калибровке SWR и выходной мощности
+STM32: Функция CW SWAP, если нет сигнала в полосе, перестраивается на ближайший сигнал, а не сильнейший
+STM32: Auto Snap теперь поддерживает NFM моду, для отслеживания перемещающихся сигналов (например со спутника, экспериментальная функция), Tnx Saw_spb
+STM32: Добавлен тач-интерфейс для кнопок FT8, Tnx R6WAM
+STM32: Улучшена работа FT8 на поиск, Tnx RD3Q
+STM32: Убран всплеск ВЧ сигнала при переходе на передачу
+STM32: Новая экспериментальная функция "TX CESSB" - использование модуляции с контролем огибающей при формировании SSB сигнала. Позволяет получить более пробивной сигнал при той же PEP мощности.
+STM32: Настройка "TX CESSB Compress, dB" - уровень компрессии в CESSB, чем выше - тем больше средняя мощность сигнала.
+STM32: На экран выводится текущий уровень SQL в моде NFM/WFM (7 дюймовая версия), Tnx EA7HOG
+STM32: Доработки OTA
+STM32: В System info выведен текущий уровень ALC с внешнего усилителя
+STM32: Новый алгоритм работы ALC: до 1 вольта - ALC отключен и используется мощность выставленная в трансивере. с 1.0v до 3.3v - регулировка мощности от 0 до 100 %
+STM32: Поддержка Two Signal Tune в моде AM
+STM32: Wolf-X1: исправления оформления, Tnx R7KBI

----Version 5.2.1----
+HARDW: Добавлена новая версия RF-UNIT-BIG-RU4PN-rev5.3, Tnx RU4PN
+STM32: W-Lite: Реализована возможность работы в Windows 7

----Version 5.2.0----
+FPGA: Расширение границ регулировки VCXO Correction, Tnx RA0LCC
+FPGA: Снижение частоты ЦАП для подавления паразитных выбросов (также снизился уровень на выходе ЦАП, необходимо компенсировать калибровками или номиналами драйвера\аттенюатора)
+FPGA: Подготовлены прошивки для 10МГц, 12.228МГц, 13МГц, 20МГц и 25МГц TCXO генераторов 
+STM32: Улучшена работа на СВЧ бендах (через трансвертер)
+STM32: Новая функция Snap (для моды CW), которая подстраивает частоту на самый мощный сигнал в полосе (а если нет такого, то в спектре), Tnx R3MCD
+STM32: Новая функция Auto Snap (долгое нажатие на Snap или в меню), которая подстраивает частоту в полосе автоматически
+STM32: Доработка функции Amp Mute, Tnx RA3WSA
+STM32: Увеличено время отображения всплывающих сообщений, Tnx DL1EGQ
+STM32: Доработка механизма отстройки от DC-DC помех
+STM32: Исправление отображения FFT при Scale Type = dBm, Tnx UN7FHS
+STM32: Отключен микрофонный компрессор для DIGI-мод, Tnx RA9N
+STM32: Исправлено изменение мощности энкодером в режиме Tune, Tnx С1-48
+STM32: Wolf-Lite: Исправлено отображение при запуске Tune вне диапазонов, Tnx RA4CGO
+STM32: Wolf-Lite: Исправлено сохранение IF Gain из функций быстрого доступа, Tnx RA4CGO
+STM32: Доработка автоматики FFT в режиме Squared, Tnx R7KBI
+STM32: В сервис Self Test добавлена проверка частоты семплов (зависит от корректности работы тактовых сигналов с FGPA)
+STM32: Новая настройка "Freq Step WFM, kHz" для выбора шага перестройки в WFM моде, Tnx EA7HOG
+STM32: Добавлен диалог подтверждения форматирования SD карты, Tnx StevenSaH
+STM32: Исправлены ошибки при некорректном выборе CAT порта, Tnx UZ5DM

----Version 5.1.0----
+DOC: В readme файл добавлена ссылка на подробную инструкцию по функциям трансивера
+STM32: Добавлен пункт "Attenuation, dB" для выбора текущего затухания в аттенюаторе через меню
+STM32: Добавлено усреднение для замеров с MCP3008 для улучшения стабильности
+STM32: Исправлена работа Default+ темы в канальном режиме
+STM32: Скорректирована работа FFT Lens на 7 дюймовых дисплеях
+STM32: Mic Gain теперь регулируется в децибеллах и с повышенной точностью, Tnx R7KBI
+STM32: Доработка процесса обновления списка сетей WiFi, Tnx АлександрDX
+STM32: В калибровки добавлен диапазон регулировки усиления ПЧ (минимум\максимум), Tnx EA7HOG
+STM32: Изменены коэффициенты FFT компрессора
+STM32: В меню калибровок добавлены пункты сброса настроек и калибровок по умолчанию, Tnx DL1EGQ
+STM32: Добавлена возможность импорта\экспорта настроек функциональных кнопок на SD, Tnx RU4PN
+STM32: Доработки по тракту USB->TX и компрессора
+STM32: Реализован сервис отображения ионограмм через интернет (для выбранного URSI Code, для стран где это доступно), Tnx EA7HOG

----Version 5.0.0----
+STM32: Реализована возможность передачи на 70cm (432 MHz) диапазоне в режиме работы на гармонике (применимо для CW, FM, требует полосового фильтра на входе усилителя)
+STM32: Новые темы оформления "Default+" и "Analog+" для 7 дюймовых дисплеев, Tnx автору LZ1HAA
+STM32: Новая функция "Flash GT911" в калибровках, обновляет прошивку тачпада под разрешение экрана (актуально при покупке ненастроенных), Tnx R6DTB
+STM32: Увеличена чувствительность FFT в моде WFM
+STM32: Увеличены границы регулировки HPF, Tnx RC9M
+STM32: Новая калибровка "DAC Driver Mode" - режим работы драйвера OPA2673 (2 = 100% bias, 1 = 75% bias, 0 = 50% bias)
+STM32: Доработка отображения ячеек памяти на 7 дюймовом дисплее, Tnx EA7HOG
+STM32: Долгое нажатие на Play открывает файл-менеджер (для 7 дюймов), Tnx EA7HOG
+STM32: X1: Во время передачи блокируются функциональные кнопки (во избежание помех), Tnx RU4PN
+STM32: Новая контрастная тема для водопада (WTF) "BlR>Y>R", Tnx R7KBI
+STM32: Функция Scan при активном канальном режиме перебирает каналы, а не частоты, Tnx Radek
+STM32: Доработки отображения в сервисе Propagination, Tnx EA7HOG
+STM32: Начальная поддержка прототипа Wolf-Mini, Tnx R7KBI
+STM32: Различные доработки по использованию трансивера в CW моде, Tnx UA3RF, RA3RFA, UA3RJ
+STM32: Новый режим FFT Scale Type: Squared, позволяющий вытягивать слабые сигналы на спектре
+STM32: Исправление разных ошибок и недоработок, Tnx R4HID, R7KBI, UT8EU, R3DBQ, RU4PN, C1-49, ivan

----Version 4.4.0----
+STM32: Wolf-Lite: доработка внешнего вида, Автор R7KBI
+STM32: Корректировка времени срабатывания FM SQL, Tnx R8LBZ
+STM32: Новый алгоритм расчёта для регулировки уровня выходной мощности, Tnx BH4PJB
+STM32: Filemanager перенесён из меню Services в SD Menu, Tnx R4HID
+STM32: Калибровка "MAX RF Power" переименована в "MAX PWR on Meter", Tnx Serge I.
+STM32: Скорректировано отображение аналогового с-метра для измерения малых мощностей < 20 ватт, Tnx АлександрDX
+STM32: Добавлены калибровки для 4м диапазона, Tnx EA7HOG
+STM32: Wolf-X1: Исправление отображения некоторых пунктов меню, Tnx R7KBI
+STM32: Wolf-X1, Wolf-Lite: Добавлена настройка шага регулировки громкости вторичным энкодером, Tnx R7KBI
+STM32: Wolf-X1, Wolf-Lite: IF Gain сохраняется индивидуально для каждого диапазона, Tnx С1-49
+STM32: Wolf-Lite: Драйвер больше не участвует в функции Autogain, Tnx С1-49
+STM32: Обновлены драйвера COM-портов (протестирована работа в Win 7 + Win XP SP3 на VirtualBox), Tnx UR5VLC, RC9M
+STM32: WF-100D: Новый алгоритм обновления сдвиговых регистров
+STM32: Доработка механизма работы памяти по бендам, Tnx RA6UAC
+STM32: Во время передачи запрещено движение по частоте вторичным энкодером, Tnx Sergey Iv
+STM32: Добавлена регулировка HPF в SSB через функции ENC2, Tnx RC9M
+STM32: Исправление разных ошибок, Tnx LZ1HAA, RC9M, RA4CGO, UT8EU

----Version 4.3.0----
+STM32: Добавлена поддержка плат Wolf-Lite (с ограничениями функционала относительно старшей версии), теперь проекты будут жить и развиваться совместно, Thx R7KBI
+STM32: Файлы, схемы и прочее от Wolf-X1 и Wolf-Lite объединены в единый репозиторий
+STM32: Исправление разных ошибок, Tnx R7KBI, Alexander, R6WAM, R4HID, sun, R8LBZ, R3MCD, RU4PN, LZ1HAA, R5ZX, UR5HBA
+STM32: Переработка метода чтения с SD
+STM32: Исправлена ошибка при повторной записи CQ Message, Tnx R9FDL
+STM32: Для 100 ваттных версий реализован запрет на обновление сдвиговых регистров во время передачи, для избежания помех и дребезга (кроме режима TUNE и во время работы вентилятора)
+STM32: Добавлен 4 метровый диапазон (активируется в калибровках), Tnx EA7HOG
+STM32: Добавлена кнопка Shift для смены раскладки на виртуальной клавиатуре, Tnx R4HID
+STM32: В программируемый ряд кнопок добавлен VOX (кнопки настраиваются в меню Screen), Tnx RU4PN
+STM32: WF-100D: Для унификации сброс настроек и калибровок происходит по нажатию F1+F8 (как в 7 дюймовой BIG версии)
+STM32: Доработки RDS декодера
+STM32: Повышение чувствительности CW декодера
+STM32: При клике по аналоговому с-метру во время передачи меняется режим отображения: SWR или мощность, Tnx R6WAM
+STM32: В меню Services добавлена карта терминатора (дня и ночи), для 7 дюймовой версии, Tnx UA3DPB 
+STM32: Расширены значения шагов для перестройки частоты, Tnx C1-49 

----Version 4.2.0----
+STM32: Кодовая база Wolf X1 объединена с Волком, теперь прошивка полностью открыта, а изменения синхронизированы, Thx R7KBI
+STM32: Доработки FM демодулятора
+STM32: Для NFM моды теперь доступен авто-Notch фильтр
+STM32: Ускорено срабатывание шумодава на FM, Tnx R8LBZ
+STM32: При отключенном TUNER, но активном ATU не происходит ложных переборов и индикаций, Tnx RA3WSA
+STM32: В меню добавлена индикация текущего КСВ для ручной настройки тюнера, Tnx RA3WSA
+STM32: Доработка логирования записей FT8, Tnx RU4PN
+STM32: Дополнительный IQ выход через USB устройство, позволяющий направить необработанные IQ данные текущего VFO для скиммера, Tnx UT8EU
+STM32: Мелкие доработки интерфейса
+STM32: Добавлен функционал микрофонного VOX (активация передачи голосом, проверьте что микрофон не размыкается кнопкой PTT)
+STM32: Добавлена возможность регулировки FM SQL через функциональный режим ENC2, Tnx UR6QW
+STM32: В меню Callsign, Locator, WiFi Password добавлена экранная клавиатура (для 7 дюймовой версии)
+STM32: Исправление разных ошибок, Tnx RU4PN, R7KBI, Alexander

----Version 4.1.0----
+FPGA: Исправления ошибок по TX
+STM32: Исправления в работе свайпа по FFT
+STM32: Начаты эксперименты с новым АРУ, включается опцией "AGC Spectral" (вкл по умолчанию)
+STM32: Доработан FFT BW Style, Tnx R7KBI
+STM32: Исправлены названия RIT/XIT/SPLIT в соответствии со стандартами, Tnx RA4CGO
+STM32: Доработки процесса инициализации WiFi, Tnx Saw
+STM32: Доработки FFT
+STM32: Доработки усреднений показаний датчиков
+STM32: При превышении защитного порога по КСВ, мощность сбрасывается до 20%, а не отключается полностью
+STM32: Новый режим выбора антенн 1RX/2TX, Tnx R6WAM
+STM32: В меню добавлена ссылка на FT8, Tnx RA9UAC
+STM32: Доработка управления смещением трансвертеров, Tnx UA9OLB
+STM32: В режиме Two signal Tune автоматический подбор значений ATU отключается, Tnx R4HID
+STM32: Новая калибровка "TSignal Balance" - задаёт баланс мощности в % между сигналами в режиме Two signal tune, Tnx R4HID
+STM32: Новая калибровка "Linear Pwr Control" - Задаёт линейный способ изменения амплитуды сигнала при регулировке мощности (если отключен - логарифмический), Tnx RU4PN
+STM32: 15 канал CB отмечен модой AM в бендмапе, Tnx R8LBZ
+STM32: Добавлены сетки частот ABDE для CB, Tnx R8LBZ
+STM32: Доработки оформления номеров канального режима, Tnx R8LBZ
+STM32: Оптимизирован размер прошивки
+STM32: Добавлен JPEG декодер для крупных изображений
+STM32: Новая стартовая картинка для 7 дюймовых дисплеев, Tnx UA3DPB
+STM32: При импорте/экспорте настроек с SD Card добавлен запрос подтверждения, Thx RU4PN
+STM32: При нажатии на ключ вне CW моды, он работает как педаль PTT
+STM32: Дополнительная функция второстепенного энкодера, позволяющая регулировать ширину LPF не заходя в меню, Tnx RC9M
+STM32: Добавлена настройка для регулировки порога срабатывания VAD детектора голоса (шумоподавитель для SSB моды и SCAN режима)
+STM32: Исправления мелких ошибок

----Version 4.0.3----
+FPGA: Исправления ошибок
+STM32: Исправления ошибок

----Version 4.0.2----
+FPGA: Доработки цепей TX, Tnx RA9N, RU4PN, R3MCD, UR5VLC, UN7LAS, UA9ULT
+FPGA: Исправления в работе двойного приёмника, Tnx Мистер X
+STM32: Увеличение максимальной мощности TX, Tnx RA9N
+STM32: Ссылка на меню сервисов добавлено в основное меню
+STM32: Доработки двухтонального генератора
+STM32: Доработка автоматического отключения ФНЧ (RF-RU4PN, WF-100D)
+STM32: Исправление работы изменения частоты основным энкодером на низких значениях Freq step, Tnx Sergey Iv
+STM32: При выходе из Self test восстанавливаются исходные настройки PRE/DRV/ATT/PGA, Tnx R4HID
+STM32: VAD шумоподавитель теперь может работать в режиме Dual RX, Tnx Мистер X

----Version 4.0.1----
+FPGA: Доработки цепей TX, Tnx RA9N
+STM32: Доработки цепей TX, Tnx RA9N
+STM32: При активном LCD Sleep timeout в FT8 больше не отключается экран, Tnx RU4PN

----Version 4.0.0----
+HARDW: Новая MOTHERBOARD-RA9UCN-mod-rev31: Доработана Charge Pump цепь, рекомендуется обновить свои трансиверы в соответствии с новыми номиналами, Tnx RA9N
+FPGA: Доработки и оптимизации
+FPGA: Сокращена лишняя разрядность
+FPGA: Объединены узлы RX_CIC, RX_CICCOMP, TX_CICCOMP, TX_CIC
+FPGA: Скорректирована частота DAC
+FPGA: Доработки по фильтрам TX/RX
+FPGA: Исправлена проблема с отсутствием приёма на 384кГц полосе с выключенным DRV
+FPGA: Исправлены периодические проблемы с TX
+STM32: Доработки Stereo FM, Tnx RU4PN
+STM32: Разные оптимизации
+STM32: Исправлено меню цветов FFT/WTF, Tnx UR6QW
+STM32: Доработка заставки, Tnx UA3DPB
+STM32: Долгое нажатие на иконку полосы вызывает меню настройки, Tnx UR6QW
+STM32: Доработка индикации RIT, Tnx UR6QW
+STM32: Исправлено движение пика максимума S-метра
+STM32: Исправлена работа AGC при переходе TX/RX, Tnx RC9M
+STM32: Добавлена калибровка "LNA Compensation", которая компенсирует увеличение значения S-метра при включении LNA, dBm, Tnx RA4CGO
+STM32: Поддержка FT8 декодера и передатчика для 7 дюймовой версии, Tnx DB5AT
+STM32: Доработки процесса соединения WiFi
+STM32: В самодиагностику добавлен тест TCXO, Tnx UN7LAS
+STM32: При длинном нажатии на диапазонную кнопку (WF-100D), запоминается  частота. При коротком частоты вызываются по кольцу (3 ячейки памяти на бенд), Tnx RA6UAC
+STM32: Доработки VCXO корректора, Tnx RA9N
+STM32: Доработки WiFi, Tnx RV3NX
+STM32: Доработки ATU
+STM32: Теперь мощность FT8 не ограничена настройками мощности Tune
+STM32: Доработки ADIF логгера FT8, Tnx RU4PN

----Version 3.5.1----
+STM32: Восстановлена работа звука по USB
+STM32: Изменена картинка загрузки на 7 дюймовой версии, Tnx UA3DPB

----Version 3.5.0----
+STM32: Новая настройка "Fine RIT Tune", при её активации RIT настраивается мультифункциональным энкодером, а не резистором. Tnx RL6MR
+STM32: Обновление системных библиотек
+STM32: Стрелка аналогового S-Метра стала более плавной, Tnx TGZ, UR6QW
+STM32: При настройке FFT Averaging более 10 начинается не только усреднение выборок, но и сглаживание результатов, Tnx TGZ
+STM32: Исправлена работа SQL на КВ (SSB/AM), Tnx UR6QW
+STM32: Исправлено отображение DNR в меню, Tnx UR6QW
+STM32: Во время передачи главный энкодер управляет мощностью, Tnx UR5VLC
+STM32: В течение 3-х минут после передачи TX ФНЧ не отключается (платы RU4PN, WF-100D), Tnx RU4PN
+STM32: При активации настройки Auto Input Switch происходит автоматическая подстройка источника звука (PTT - Mic, CAT/COM - USB), Tnx RC9M
+STM32: Улучшение звучания в Stereo FM, Tnx RU3KV, RU4PN
+STM32: Новая тема оформления FFT/WTF "Bl>B>Y>R"

----Version 3.4.1----
+STM32: Исправление ошибок с SD картой, Tnx R4HID, RD3Q, Мистер X
+STM32: Иконка FAN для 3'2 версии, Tnx Мистер X
+STM32: Восстановлен 3D FFT, Tnx RV9CT
+STM32: Усреднение показателей температурного датчика, Tnx KENWOOD
+STM32: Починен FFT Height 5 на 3'5 дисплеях в семисегментном режиме, Tnx DL1EGQ
+STM32: SPLIT/SHIFT не сбрасывал частоту при выключении, Tnx RL6MR
+STM32: Доработки CW через COM-порт, Tnx RC9M
+STM32: DNR вернулся на старые алгоритмы
+STM32: Исправление разных ошибок, Tnx UR6QW, DL1EGQ
+STM32: Расширены диапазоны настройки параметров Freq Step, Tnx R8LBZ
+STM32: Доработки ATU, Tnx RU4PN

----Version 3.4.0----
+FPGA: Выложены версии для 10 MHz и 20 MHz TCXO генераторов (требуется тестирование), Thx R7KBI
+STM32: Доработки обмена по WiFi
+STM32: При включении вентилятора отображается соответствующая иконка, Thx RU4PN, UR5VLC
+STM32: В моде CW прибавлено усиление, чтобы приблизить громкость к SSB
+STM32: Цвет границ водопада, при перестроении частоты, рисуется ближе к цветам водопада (вместо черного), Thx svyatoslavx
+STM32: В NFM/WFM модах на S-метре отображается граница срабатывания шумоподавителя, Thx UR6QW
+STM32: Меню запоминает выбранный пункт в каждом подменю при повторном входе, Thx UR6QW
+STM32: Алгоритмы DNR заменены на Speex, настройка DNR Level выбирает на сколько dB давить шум, Thx за код UA1ARN
+STM32: RTS и DTR поменялись местами (RTS - PTT, DTR - CW), Thx RC9M
+STM32: Доработки АРУ, чтобы он не задерживался на резких одиночных пиках, Thx RU4PN
+STM32: Добавлена поддержка бендов и трансвертеров на 70/23/13/6/3cm с ПЧ на 144МГц (требуется тестирование), Thx RC9M
+STM32: Добавлено управление внешними трансвертерами через разъём External (настраивается в калибровках, требуется тестирование), Thx RC9M

----Version 3.3.1----
+STM32: Исправлена работа энкодера на УКВ диапазонах, Thx Григорий Потемкин
+STM32: Добавлена настройка порога минимального уровня сигнала при срабатывании CW декодера, Thx R3MCD

----Version 3.3.0----
+HARDW: Новая RF-UNIT-BIG-RU4PN, Thx RU4PN
+HARDW: Новые платы корпуса и тангенты, Thx EA7GIB
+HARDW: Новая плата подключения аудио(и не только) разъёмов, Thx EA7GIB
+HARDW: Новая версия RF-UNIT-BIG-DB5AT на основе AFT05mp075nr1, Thx DB5AT
+HARDW: Новая версия плат корпуса от DB5AT
+STM32: Добавлена поддержка измерителя INA226, Thx DB5AT
+STM32: Доработки для версии WF-100D и RU4PN
+STM32: Доработки ATU
+STM32: ATU сохраняет значениям по бендам
+STM32: Функция Mic Noise Gate, обрезающая микрофонный сигнал ниже заданного в настройках уровня, Thx R6WAM
+STM32: Доработки FFT dBm Grid, Thx UR6QW
+STM32: Восстановлено приветствие на экранах загрузки 7 дюймовых моделей, Thx UA9ULT
+STM32: Добавлена настройка Tuner Enabled, позволяющая отключить антенный тюнер полностью, Thx RU4PN
+STM32: Добавлена калибровка ATU Averaging, позволяющая регулировать количество замеров при работе ATU, Thx RU4PN
+STM32: Увеличена частота обращений к SNTP серверу за точным временем, Thx RA9N
+STM32: Исправлние разных ошибок, Thx UA9ULT
+STM32: Исправлено округление частоты для акселератора энкодера, Thx RU4PN
+STM32: Долгое нажатие на MUTE отрубает УНЧ, но не кодек, Thx UT3UOR
+STM32: Исправлена работа CLAR в моде CW, Thx UR5YDW
+STM32: Добавлена настройка "FFT BW Style", переключающая оформление полосы приёма на FFT, Thx R7KBI
+STM32: Добавлен режим отладки в консоль "CAT"
+STM32: Управление CW/PTT перенесено на второй порт (см. настройки N1MM)
+STM32: Базовая поддержка CAT протокола TS-2000 (выбирается в калибровках)
+STM32: Добавлена настройка FFT Scale Type, меняющая стиль оси Y на FFT между амплитудой сигнала и dBm, что позволяет уместить больший динамический диапазон на экране (Полезно при ручной настройке диапазона FFT).
+STM32: Улучшено звучание в Stereo WFM режиме, Thx UR6QW
+STM32: Значение Mic Noise Gate в -120dbFS отключает его полностью, Thx UR6QW
+STM32: Настройки HPF фильтра разделены на RX и TX, Thx UR6QW
+STM32: При включенном Split во время передачи отображается частота с учётом смещения, Thx UR6QW
+STM32: Долгое нажатие на кнопку DNR (7 дюймов), вызывает из меню настройку DNR, Thx UR6QW
+STM32: Настройки цветов FFT и WTF разделены, Thx UR6QW

----Version 3.2.1----
+HARDW: В папку Case добавлены STL модели ручек энкодера для распечатки на 3д принтере, Thx автору EB4DYL
+HARDW: Добавлена поддержка измерителя INA226T-Thx добав-rev3, Thx RU4PN
+HARDW: Новая RF-UNIT-RU4PN-rev3, Thx и RU4PN
-Tandem VHF разведён прямо на плате
-Уменьшены ёмкости ФНЧ дорожек
-Добавлены места пайки экрана на входные фильтра УКВ-модуля
+STM32: Исправление водопада, декодера RDS/CW, Thx RU4PN, UA9ULT, UR4UOQ и другим
+STM32: Диапазон FFT Averaging расширен до 10, Thx Гена

----Version 3.2.0----
+HARDW: Новая 100 ваттная +ATU плата RF-UNIT-RU4PN-rev2, которая пришла на замену RF-UNIT-BIG, Thx автору RU4PN
+HARDW: Добавлены интерактивные монтажные схемы boastools, Thx автору EB4DYL
+HARDW: Добавлена новая экспериментальная материнская плата версии RA9UCN (при поддержке UA9ULT)
-фильтр T1 на входе заменен на обычный дроссель (L1001)и дополнительно развязана шина 13,8В идущая на стабилизатор 12В через L1002. Все эти дроссели, включая L37, унифицированы, типоразмер 0630.
-L7 и L37 заменены на меньший размер 7x7 мм (в работе проверены, не греются).
-Стабилизатор 7812 заменён на LM1086 (1085, 1084), т. к. при разнице потенциалов в 1,8 вольта 7812 стабилизировал условно.
-Линия TX к STM защищена диодом D1002 и зашунтирована (опционально) конденсатором C1001!
-Разъём MIC_IN2 заменён на трёхконтактный(добавлен PTT), с возможностью запайки с обратной стороны платы для удобства стыковки с FRONT UNIT.
-PTT на микрофонный разьем подается через перемычку R1003.
-Добавлен дроссель L9 в цепь питания УНЧ.
-Линейный аудиовыход с кодека выведен на разьём для экспериментов с внешним УНЧ.
-Премычка "BOOT" вынесена ближе к краю платы для удобства программирования.
-Увеличена ширина шин питания и добавлено количество переходных отверстий на них.
-По возможности разнесены проблемные для начинающих близкорасположенные детали.
-Добавлены отверстия для запайки выводов не SMD трансформаторов.
-Добавлены отверстия для запайки выводного кварцевого резонатора на 32768 Гц.
+HARDW: Добавлена новая экспериментальная лицевая панель 7 дюймов версии RA9UCN (при поддержке UA9ULT)
-Уменьшены габариты до 110,5*220 мм.
-Убраны фронтальные разъёмы (предполагается использование основных на MB).
-Ряд функциональных кнопок сделан скрытым (доступ снизу) ввиду их невостребованности.
-Разъём FPC-45 смещен до одного уровня с разъемом на MB, для устранения перекоса шлейфа.
-Картридер перенесен на лицевую сторону.
-Установлен угловой разъём на гарнитуру (J3 6P6C, но возможно понадобится приподнять на 0,7 мм LCD).
-DC-DC перенесён на другую сторону.
-Дроссель L1 заменён на меньший размер 7x7 мм.
-Добавлен дроссель L1001 для блокировки помех от DC-DC по цепи 12В.
-В цепь DCDC SYNC добавлен фильтрующий элемент R1011 (резистор или дроссель).
-Добавлена возможность запайки Wi-Fi модуля с внешней антенной (ESP-07s) с возможностью конфигурации резисторами (R1001-R1006).
-Напряжение питания основного энкодера(3 или 5В) задается перемычками R1009-R1010.
-Добавлены токоограничительные резисторы в цепи переменных резисторов (R1007, R1008).
-Добавлены блокировочные конденсаторы.

+FPGA: Улучшена коррекция VCXO, Thx RA9N
+STM32: Добавлена поддержка FT8 в режиме TX/RX (для версии 3'2 / 3'5 дюймов), Thx автору DB5AT
+STM32: Вернул тактование I2S/SPI от FPGA, были щелчки при передаче, Thx RU4PN
+STM32: ATU теперь не работает в УКВ диапазонах, Thx RU4PN
+STM32: Новая калибровка "SSB Power addition" - в режиме SSB прибавляет мощность к выбранной в настройках, Thx UR5YDW
+STM32: Отдельная настройка полосы фильтра для DIGI мод, Thx UR5YDW
+STM32: Новый резим КСВ анализатора - измерение в выбранных границах частот, Thx UR5YDW
+STM32: Теперь КСВ анализатор выводит частоту с минимальным КСВ, Thx UR5YDW
+STM32: Функция "LCD Sleep Timeout" - 7 дюймовый экран снижает яркость спустя некоторое время без активности пользователя, Thx DL1EGQ
+STM32: Исправление различных ошибок, Thx DJ0AK

----Version 3.1.0----
+HARDW: добавлена FRONT-UNIT-3.5-RA9UCN: Новая версия лицевой панели от RA9UCN
-Размеры платы уменьшены до одного размера с MB (187*77 мм.) при сохранении возможности установки 3,2" или 3,5" LCD.
-Разъём FPC-45 смещен до одного уровня с разъемом на MB, для устранения перекоса шлейфа.
-Предусмотрена запайка угловых разъемов по питанию и увеличены размеры отверстий под них.
-Картридер заменен на такой же, как и на FRONT-UNIT-7", и перенесен на лицевую сторону, чтоб не перекрывал энкодер.
-Добавлена возможность запайки Wi-Fi модуля с внешней антенной (ESP-07s).
-Для снижения высоты добавлены посадочные места под SMD электролитические конденсаторы C1001 и C1002 (470uF*25V).
-Увеличены отверстия под запайку механического энкодера и переменных резисторов.
-Надписи упорядочены и добавлены к кнопкам, для удобства отладки.
-Внимание! Кнопки выровнены в единую сетку, поэтому передние панели от прежних версий НЕ подойдут!

+HARDW: Новая MOTHERBOARD-RA9UCN-mod-rev30: Новая версия материнской платы редакции RA9UCN (заменила старую материнскую плату)
-Предусмотрена запайка углового питающего разъема и увеличены размеры отверстий под него.
-Защитный диод по входу питания
-L7 большего типоразмера
-Возможность запайки двух перемычек (R1001 и R1002) под U19 ("опторазвязка" USB), при её отсутствии, например.
-Увеличена ширина питающих дорожек.
-Отсимметрированы по диагонали отверстия под радиаторы U5, U10, U16, относительно их корпуса.
-Предусмотрены отверстия для запайки земляных падов у U8(DAC) и U16(ADC).
-U11 убрана из под шлейфа.
-Немного увеличены/симметрированы полигоны под некоторыми стабилизаторами.
-Освобождено место вокруг разъёмов под динамики и второй микрофон для возможности запайки XH2.54.
-Батарейный отсек скорректирован под более качественный с толстыми выводами.
-Увеличен вырез под провода и предусмотрены отверстия для их фиксации.
-Упорядочены надписи.

+STM32: Устранение ошибки в телефонном самоконтроле, Thx UA9ULT
+STM32: Доработки поддержки RF-UNIT-QRP, Thx UA9ULT
+STM32: Запрет смены диапазона/vfo во время передачи, Thx RM0A
+STM32: Доработки прёмного тракта/фильтров AM/NFM, Thx RA9N
+STM32: При нажатии на экранную кнопку ATT, появляется выпадающий список с типовыми значениями аттенюатора, Thx UT3NI
+STM32: В меню ручного управления тюнером выводятся значения в uH/pF, а не номером комбинации
+STM32: В дополнение к режиму Shift (отстройка частоты приёма от выбранной), реализован режим Split (отстройка частоты передачи от выбранной), Thx UR5YDW
+STM32: Возможность воспроизведения любого записанного wav файла в эфир (через файл-менеджер), а не только CQ, Thx RM0A
+STM32: Исправлена ошибка в работе кнопки Mute, Thx Pidgornyi Sergii
+STM32: Добавлена версия прошивки, позволяющая запускать трансивер без FRONT-UNIT (управление по USB), Thx R3MCD
+STM32: Исправлена 7ми сегментная тема для 3'2-3'5 дюймовой версии, Thx RA9UCN
+STM32: Доработки аналогового с-метра, Thx DL1EGQ
+STM32: Поддержка экспериментальной RF-UNIT-SPLIT со стороны прошивки (требуется тестирование)
+STM32: Поддержка экспериментальной RF-UNIT-RU4PN со стороны прошивки (требуется тестирование), Thx RU4PN
+STM32: Добавлена функция инверсии битов RTTY декодера, Thx RU4PN
+STM32: Устранение ошибок с RDS, Thx EA7GIB
+STM32: АПЧ SAM демодулятора сокращена до 300гц, Thx RU4PN
+STM32: RX эквалайзер теперь работает на оба канала, Thx RU4PN
+STM32: Исправлена SAM демодуляция в режиме двойного приёмника

----Version 3.0.0----
+HARDW: RF-UNIT-QRP_20W: Добавлена 20 ваттная QRP++ версия платы RF-UNIT, Thx автору DB5AT
+HARDW: RF-UNIT-SPLIT-rev3: Доработки шелкографии, переходов, контура, Thx UB3DKI
+HARDW: Добавлена плата PCB MIC MH-48 (папка Addons) для 7 дюймовой лицевой панели, Thx автору EA7GIB
+HARDW: RF-UNIT-QRP-rev22: Обновлены номиналы всех фильтров (TX/RX ФНЧ, ФВЧ, ДПФ) для достижения лучшего АЧХ, Thx Radist2
+HARDW: Начата поддержка версии WF-100D, Thx R6WAM
+FPGA: Поддержка функций самодиагностики
+STM32: В меню сервисов добавлена самодиагностика FPGA, MCP3008, STM32 EEPROM, WM8731, линий АЦП, Симметрии АЦП, ADC DRV, ADC PGA, LNA, ATT
+STM32: Новая настройка SelfHear Volume - регулировка громкости самоконтроля относительно общей громкости трансивера, Thx RM0A
+STM32: Переход на CMSIS 5.8.0
+STM32: На кнопки каналов памяти выведена сохранённая частота, Thx RM0A, DL1EGQ
+STM32: Новая настройка "Show Sec VFO" - включает отображение положения второго VFO на спектре
+STM32: Исправление мелких ошибок, Thx Sergey Iv
+STM32: Кнопки, EEPROM и SD теперь не требуют тактового сигнала с FPGA для работы
+STM32: Новая опция FFT DXCluster Timeout - таймаут отображения спотов с кластера, минутах, Thx RM0A 
+STM32: Новая опция CW PTT Type - тип перехода на передачу в CW: от ключа или от педали, Thx UA9ULT
+STM32: При установленной плате с ATU, во время передачи на экран выводятся значения текущих C и I тюнера, Thx DB5AT
+STM32: Новая опция WFM Stereo - включает стерео декодер FM станций (внимание: стерео имеется не на всех вещалках + стерео сигнал требует хорошей антенны из-за меньшей мощности)

----Version 2.9.1----
+STM32: Доработки в манипуляции CW через N1MM, управление PTT через RTS линию CAT порта, CW через DTR, Thx RM0A
+STM32: Расширены варианты выбора RTTY Shift, Thx R3MCD
+STM32: Самоконтроль CW при нулевой мощности, Thx RC9M

----Version 2.9.0----
+HARDW: BOM очищены от ошибок в номиналах/футпринтах
+STM32: Уменьшено моргание интерфейса при работе CW
+STM32: Доработана настройка TX Start Delay в режиме CW, Thx RA9N
+STM32: В меню калибровок добавлена возможность переворота экрана на 180 градусов, Thx RA6UAC
+STM32: Новая настройка CW DotToDash Rate, которая задаёт отношение длинны тире к точке, Thx UA3DPB
+STM32: Новая настройка CW Iambic Keyer, которая включает ямбический ключ, Thx UA3DPB
+STM32: Исправлена сетка частоты поверх спектра
+STM32: Исправление периодических проблем со звуком в режиме самоконтроля
+STM32: Исправлена ошибка, когда пытаешься проиграть файл быстрого вызова, не имея его на SD карте, Thx RM0A
+STM32: Доработан вывод FFT при ручной калибровке диапазонов сигнала
+STM32: Новая настройка FFT dBm Grid, выводящая сетку силы сигнала поверх спектра, Thx RM0A
+STM32: Новая настройка CW Key Invert, инвертирующая точку/тире на ключе, Thx UA9OLB
+STM32: Доработка алгоритма включения аттенюатора после отработки autogainer
+STM32: Новый сервис Locator Info, отображающий расстояние и азимут до корреспондента, Thx UT3NI
+STM32: Новый сервис Callsign Info, отображающий информацию о стране, области, азимуте и т.п., Thx UT3NI
+STM32: Новая настройка FFT DXCluster Azimuth, добавляющая азимут к выводу dx-кластера на спектре, Thx UT3NI
+STM32: Новая мода-декодер RTTY, а также новое меню Decoders, где находятся настройки декодеров, Thx EW3ABA

----Version 2.8.1----
+HARDW: Исправлена Motherboard rev30, Thx RA9UCN

----Version 2.8.0----
+HARDW: Добавлены платы лицевой и задней панели разработки EA7GIB
+HARDW: RF-UNIT-BIG-rev5: Добавлены блокировочные конденсаторы, Thx UR4QBP
+HARDW: RF-UNIT-BIG-rev5: Максимальная мощность увеличена до 100вт, исправлены ошибки, Thx DJ0AK
+HARDW: RF-UNIT-BIG-rev5: Многооборотные резисторы подстройки тока покоя ОК
+HARDW: RF-UNIT-BIG-rev5: Доработано управление LNA
+HARDW: Новая версия экспериментальной платы коммутации RF-UNIT-SPLIT-rev1 (управление фильтрами/усилителями/тюнерами в формате отдельных плат)
+HARDW: В обвязке LNA все версий RF-UNIT заменены конденсаторы на 1nf, для увеличения чувствительности
+HARDW: Ферритовые бусины заменены на BLM21
+HARDW: Motherboard rev30: Добавлена USB изоляция по линии VBUS
+HARDW: Motherboard rev30: На шлейф передней панели выведена линия синхронизации DC-DC для подавления помех на части бендов, Thx DL1EGQ
+HARDW: Motherboard rev30: Стабилизатор LM1085-3.3 заменён на более мощный LM1084IS-3.3
+HARDW: Motherboard rev30: Стабилизаторы FPGA (1.2, 2.5) и АЦП (3.3) заменены на более мощные, в корпусах DPAK, Thx Игорь @Q
+HARDW: Motherboard rev30: Увеличено количество переходных отверстий под АЦП
+HARDW: Motherboard rev30: Добавлены отверстия для крепления радиаторов к АЦП/FPGA/STM32, Thx RU4PN
+HARDW: FRONT-UNIT-7 rev5: Выведена линия синхронизации DC-DC для подавления помех на части бендов (для MOTHERBOARD-rev30 и новее), Thx DL1EGQ
+HARDW: FRONT-UNIT-7 rev5: Доработка трассировки питания, Thx Дмитрий Кириенко
+HARDW: FRONT-UNIT-7 rev5: Защитный диод по питанию дисплея, Thx R4DZ
+HARDW: RF-UNIT-QRP rev21, RF-UNIT-BIG-rev5: Добавлен разрядник по входу RX, Thx R4DZ
+HARDW: RF-UNIT-QRP rev21: Выходной трансформатор рекомендовано мотать 25омным кабелем, Thx R2AVB
+HARDW: RF-UNIT-QRP rev21: Добавлен выходной симметрирующий трансформатор, Thx RA9N
+HARDW: RF-UNIT-QRP rev21: Для ДПФ фильтра 145МГц добавлен режекторный фильтр FM бенда, Thx EA7GIB
+STM32: Ограничение нижнего уровня FFT спектра на передачу, Thx Alex
+STM32: Новая настройка Mic Boost, управляющая 20db усилителем микрофона в аудио-кодеке
+STM32: Доработки FFT спектра
+STM32: Увеличен предел настройки TX Start Delay (задержка при передаче), Thx RA9N
+STM32: Доработки ручного Notch-фильтра, Thx RU4PN
+STM32: При включенном режиме CLAR, частоты VFO-A и VFO-B изменяются синхронно, Thx Radist2
+STM32: Доработана поддержка N1MM, Thx UT7NI
+STM32: Для 7 дюймового интерфейса добавлена возможность сохранения частот в ячейки памяти (любимые частоты, в меню выбора бенда), Thx UR5YDW
+STM32: FM шумодав теперь регулируется в уровне dbm принимаемого сигнала, Thx EW2MS

----Version 2.7.0----
+HARDW: Релиз RF-UNIT-BIG-35W-rev4, 35 ваттная версия rf-unit с антенным тюнером, размером с 7 дюймовую лицевую. Рекомендуется снизить усиление драйвера ЦАП перед подключением (R59, R60)
+STM32: Реализована поддержка встроенного антенного тюнера (RF-UNIT-BIG)
+STM32: Исправления различных ошибок, Thx R4DZ
+STM32: Исправления работы аналогового измерителя на УКВ, Thx АлександрDX
+STM32: Доработки внешнего вида меток DX-кластера, Thx RU4PN
+STM32: Вывод полосы VFO-B на спектр, если он находится рядом с VFO-A, Thx R4HID(ex.RN4HAQ)

----Version 2.6.0----
+HARDW: Экспериментальная Motherboard rev28 доработана, исправленный rev29 готов для заказа
+STM32: Добавлено управление ножкой Mute для УНЧ (Motherboard rev28 и новее)
+STM32: Добавлено управление усилением драйвера ЦАП (Motherboard rev28 и новее). Снижает энергопотребление и улучшает ДД. Калибровка RF GAIN 0-100% - 50% мощности, 101-200% - 75% мощности. 201-300% - 100% мощности.
+STM32: Небольшие доработки работы с SD
+STM32: Доработки вывода DX кластера поверх спектра, Thx RU4PN
+STM32: Антенна переключается тапом по иконке на экране, Thx RU4PN

----Version 2.5.0----
+STM32: Добавлена поддержка тангенты Yaesu MH-48, в меню калибровки выбирается необходимая тангента (MH-36 / MH-48), обновлена схема подключения
+STM32: Изменение ZoomFFT от жеста тачпадом (разведение пальцев в стороны на водопаде)
+STM32: Добавлено меню калибровки КСВ для 6М диапазона, Thx UR5YDW
+STM32: В меню Services реализована функция записи коротких сообщений для быстрой передачи в эфир
+STM32: Кнопка Play воспроизводит в эфир записанное ранее быстрое сообщений (CQ, CQ ...)
+STM32: Связка DFU + сторожевой таймер больше не приводит к перезагрузке, Thx R4HID(ex.RN4HAQ)
+STM32: Доработки CW декодера, Thx RA9N
+STM32: Доработки оформления, Thx АлександрDX
+STM32: Доработки передачи в SSB, Thx EW3ABA
+STM32: Реализована обработка внешнего источника ALC, трансивер будет снижать усиление, пока напряжение на входе держится более 1 вольта.
+STM32: Добавлена сетка частот 2м диапазона, Thx UR5YDW
+STM32: Новая тема оформления для 7 дюймовой версии, Thx RZ1ZR
+STM32: Новый SAM демодулятор (синхро AM), Thx UR5YDW
+STM32: Вывод DX кластера на спектр, Thx UR5YDW

----Version 2.4.1----
+STM32: Расширен диапазон регулировки SWR FWD/REF Calibration, Thx R4DZ
+STM32: Доработка самоконтроля в CW, Thx UR5YDW
+STM32: Доработка индикации перегрузки, Thx UR5YDW
+STM32: Новый калибровочный параметр для регулировки задержки перед передачей (времени срабатывания реле), Thx UR5YDW
+STM32: Разделены калибровки КСВ метра для КВ и УКВ, Thx UR5YDW
+STM32: Доработки процесса обновления с SD, вывод возможных ошибок на экран, Thx R4DZ
+STM32: Исправление ошибок в Channel Mode, Thx R4HID(ex.RN4HAQ)
+STM32: Доработки инициализации SD карты, Thx DB5AT

----Version 2.4.0----
+HARDW: Доработки экспериментальной RF-UNIT-BIG-rev3, переход на RD16 + RD100
+FPGA: Доработки PLL
+STM32: Доработки импорта с SD
+STM32: Доработки настройки FFT Height, Thx АлександрDX
+STM32: Доработки передачи в SSB, Thx EW3ABA
+STM32: Добавлена функция калибровки мощности на диапазоне CB, Thx EW3ABA
+STM32: Доработки OTA
+STM32: Расширен диапазон регулировки FFT Height, Thx R4DZ
+STM32: Исправления КСВ-анализатора, Thx UR4UOQ, UR5YDW
+STM32: Доработка FM шумодава, Thx АлександрDX
+STM32: Включен сторожевой таймер, который выключает трансивер если он завис более чем на 5 секунд, Thx UR5YDW

----Version 2.3.6----
+STM32: Релизовано декодирование и вывод информации RDS в WFM моде (отключается в меню)
+STM32: Исправления различных ошибок, Thx Alexey, EW3ABA, RU4PN, UR1MO
+STM32: При выводе гигагерцовых частот (с трансвертера) выводятся разряды ГГц, МГц, кГц, без герц, Thx UT3NI
+STM32: Новая настройка - делитель шага перестройки частоты для CW моды, Thx Alexey
+STM32: Доработка FFT и переход на Keil 5.34, Thx Антон (linoobs)
+STM32: Новый режим работы АРУ с задeржкой в пиках сигнала, в меню выведены дополнительные настройки для максимума усиления и времени задержки, Thx RU4PN
+STM32: Доработки Beeper'а, Thx RA9N

----Version 2.3.5----
+FPGA: Исправление пути генерации RBF-файла, Thx Konstantin N. Savchenko
+STM32: Оптимизация некоторых частей кода, Thx Дмитрий Кириенко
+STM32: Исправление ошибок в темах оформления, Thx UT3NI, Антон (linoobs), R4HID(ex.RN4HAQ
+STM32: Настройки SQL сохраняются для каждого Бенда/VFO индивидуально, Thx Sergo K
+STM32: Настройки каждого из бендов сохраняются на SD карту, Thx Sergo K
+STM32: Шаг настройки CW Pitch снижен до 10гц, Thx UR5YDW
+STM32: Расширен диапазон настройки трансвертера, Thx UT3NI
+STM32: Реализована передача CTCSS субтона в FM
+STM32: Доработки WFM моды
+STM32: На экран выводится текущее значение ZoomFFT
+STM32: Для 7 дюймовой версии добавлена возможность регулировки ширины полосы и ZoomFFT с помощью нижнего ряда функциональных кнопок, Thx UR5YDW

----Version 2.3.4----
+FPGA: Исправлен номер версии
+FPGA: При компиляции автоматически создаётся RBF файл
+FPGA: Мелкие доработки
+STM32: Переработка механизма работы CW и реализация полноценного CW Pitch, Thx UR5YDW
+STM32: Проверка CRC при работе с SD картой
+STM32: Доработки SD-кардридера
+STM32: Возможность прошивки STM32 с SD карты (для BIN файлов, через файл-менеджер)
+STM32: Возможность прошивки FPGA с SD карты (для JIC файлов, через файл-менеджер)
+STM32: Добавлено уведомление о выходе новой версии прошивки (определяется по WiFi)
+STM32: Реализовано OTA обновление прошивки STM32 и FPGA через WiFi
+STM32: Исправление работы без FFT Compressor
+STM32: Исправлены ошибки при переключении частоты механическим энкодером на УКВ, Thx UT3NI
+STM32: Доработки CAT подсистемы, Thx Sergo K
+STM32: Долгое нажатие на кнопку SQL (7inch) открывает меню настройки шумодава
+STM32: Исправление в работе меню, Thx EW2MS
+STM32: Калибровка S-метра разделена для КВ и УКВ, Thx UA9OLB
+STM32: Доработки AM/FM моды, Thx EW3ABA
+STM32: Выведена новая калибровка для AM модуляции
+STM32: Доработки DNR2, уровень срабатывания DNR2 вынесен в настройки
+STM32: При перегрузке ЦАП выводится ошибка и медленно снижается усиление, чтобы нормализовать выход

----Version 2.3.3----
+HARDW: Доработки экспериментальной RF-UNIT-BIG
+HARDW: На схему LNA добавлена более мощная альтернатива PGA-103+ -> SPF5189Z, на выбор, для фанатов УКВ. Thx UA9MBQ, R9US
+STUFF: Добавлен логотип в векторе
+FPGA: Доработки буфферов RX, TX
+STM32: Добавлена базовая экспериментальная поддержка RF-UNIT-BIG и антенного тюнера (включается в меню калибровки)
+STM32: Добавлена поддержка Logger32, Thx UA4FTA
+STM32: Добавлена поддержка некоторых видов SD карт
+STM32: Добавлен сервис вывода данных из DX кластера
+STM32: В файловый менеджер SD добавлена функция воспроизведения записанных WAV файлов
+STM32: Доработки цифрового ALC
+STM32: Управление SSB/FM шумодавом вынесено на экран (7 дюймов), Thx EW2MS
+STM32: Управление комбинациями порта External в зависимости от диапазона вынесено в меню калибровки, Thx EW3ABA
+STM32: Частота дискретизации устанавливается для любой FM моды, а не только WFM
+STM32: Настройки частоты дискретизации сохраняются для каждого бенда, Thx Sergo K
+STM32: Разделены настройки входа (MIC/LINE/USB) для DIGI и других мод, Thx UR5YDW
+STM32: Самоконтроль на DIGI модах, Thx UR5YDW
+STM32: Возможность запрета передачи на выбранных диапазонах через меню калибровки, Thx R6WAM, UA3DPB
+STM32: Добавлен морской VHF диапазон, Thx UA3DPB
+STM32: Скрытые диапазоны (60m, Marine VHF) включаются через меню калибровки
+STM32: Добавлен "канальный" режим, где навигация по бенду идёт по сетке каналов.
+STM32: Добавлена сетка каналов Marine VHF бенда, Thx UA3DPB
+STM32: Добавлена сетка каналов CB(C), LPD433, PMR446
+STM32: В случае ошибки подключения модуля ESP-01 запускается его перезапуск, Thx EW2MS
+STM32: Релизован ввод частоты вручную на 7 дюймовых дисплеях, в окне выбора бенда нужно нажать на текущий, Thx UT3NI
+STM32: Раздельная настройка эквалайзера и компрессора на передачу в разных модах (раздельно SSB и AM/FM), Thx UR5YDW

----Version 2.3.2----
+STM32: Сохранённые пики функции FFT HoldPeaks не сбрасываются при перемещении по частоте
+STM32: Добавлена калибровка часового кварца (грубая и точная), меньше значения - быстрее время, Thx Dmitriy Sorokin
+STM32: Доработки обнаружения сетей WiFi, Thx АлександрDX, R6WAM
+STM32: Режим сканера теперь доступен не только в SSB, но и в FM моде (работает в паре с шумодавом), Thx Konstantin K
+STM32: Теперь в меню HPF/LPF фильтры можно выбрать с любым шагом, а не из списка предустановленных
+STM32: В файловый менеджер SD-карт добавлена функция удаления файлов
+STM32: Доработки и исправления ошибок

----Version 2.3.1----
+HARDW: Добавлены эскизы/герберы передней панели для 3'2 дюймовой версии, Thx Анатолий Ступаков
+HARDW: Добавлен эскиз передней панели для 7 дюймовой версии, Thx Валерий Гаврилов
+HARDW: Добавлена схема коммутации дополнительного ФНЧ для трансивера Волк, Thx R6WAM
+FPGA: Доработка фильтров
+STM32: Доработка функций вывода отладочной информации
+STM32: Оптимизировано использование CPU и памяти
+STM32: Расширена поддержка SDHC/SDSC/SDXC карт памяти до 16 Гб
+STM32: VFO переключается по касанию на частоту на экране, второй клик открывает панель диапазонов
+STM32: Переименованы пункты в меню WiFi, Thx EW3ABA
+STM32: Доработки в меню выбора сети WiFi, Thx EW3ABA
+STM32: В настройках разделены уровни отладки, на системную, отладку WiFi, отладку кнопок и отладку тачпада
+STM32: Ускорен вывод FFT / 3D FFT
+STM32: Обновлена версия CubeMX и библиотек
+STM32: В меню сервисов добавлен файловый менеджер для просмотра файловой структуры SD-карты памяти
+STM32: Вывод ошибок EEPROM на экран, а не только в консоль, Thx R4DZ
+STM32: HPF фильтры расширены до 600гц, Thx Sergey Iv
+STM32: Для WFM моды увеличен шаг перестройки второстепенным энкодером
+STM32: Доработки фильтров
+STM32: Реализован выбор ширины полосы спектра (48кГц, 96кГц, 192кГц, 384кГц), ZoomFFT приближает относительно выставленного значения. Чем шире полоса, тем больше нагрузка на CPU
+STM32: Для WFM моды ширина спектра автоматически переключается на выставленную в настройках (по умолчанию 192кГц), улучшено звучание FM-вещалок.
+STM32: Уменьшены всплески ZoomFFT при перемещении по частоте
+STM32: Функция Autogainer теперь автоматически управляет уровнем аттенюатора
+STM32: При переключении бендов сохраняются настройки выбранной антенны, Thx R6WAM
+STM32: Поправлено отображение активного VFO в режиме передачи в режиме CLAR
+STM32: Доработки и исправления ошибок, Thx R7KBI, NJ, R4HID(ex.RN4HAQ)

----Version 2.3.0----
+HARDW: Экспериментальная RF-UNIT-BIG-rev1: Прототип платы для отладки работы раздельных мощных оконечных усилителей, КСВ метров, ант-тюнера, фильтров
+HARDW: Экспериментальная Motherboard-rev28: Добавлено управление ножкой Mute для УНЧ
+HARDW: Экспериментальная Motherboard-rev28: Добавлено управление усилением драйвера ЦАП
+HARDW: Экспериментальная Motherboard-rev28: Обвязка CLK цепи ЦАП приведена к даташиту
+HARDW: Экспериментальная Motherboard-rev28: На разъём MIC выведен контакт PTT
+HARDW: Экспериментальная Motherboard-rev28: Добавлен стерео выход с УНЧ
+HARDW: Экспериментальная Motherboard-rev28: Добавлен USB изолятор ADuM4160
+HARDW: Экспериментальная Motherboard-rev28: Подключены выводы USB VBUS/ID
+HARDW: Экспериментальная Motherboard-rev28: Добавлена цепь управления вентилятором АЦП
+HARDW: Экспериментальная Motherboard-rev28: Добавлен стабилизатор на 12в для ЦАП
+HARDW: Экспериментальная Motherboard-rev28: Дополнительные слои земли и переходы
+HARDW: Экспериментальная Motherboard-rev28: Добавлены защитные диоды по линиям CPU_PW_ON, CPU_PW_HOLD
+HARDW: Все Front-Unit: опциональные конденсаторы основного энкодера заменены на 10nF
+HARDW: Front-Unit-7-rev4: Увеличена толщина дорожки VCC12_IN
+HARDW: RF-Unit-rev20: Добавлен 10кОм резистор по входу RX антенны
+HARDW: RF-Unit-rev20: Добавлены перемычки для измерения тока каждого из плеч оконечного каскада
+HARDW: RF-Unit-rev20: Добавлена сетка из переходов между слоями
+HARDW: RF-Unit-rev20: Изменён номинал резистора R31 на 1 ком для лучшего срабатывания преампа, Thx R6WAM
+HARDW: FRONT-UNIT-4-IPS-rev1: Добавлены герберы для новой фронт-панели на 4 дюйма с IPS матрицей, Thx Павел Д Непийвода, R7KBI
+STM32: Восстановлена работа WSPR маяка, Thx АлександрDX
+STM32: Доработки меню установки времени, Thx RV9CT
+STM32: Добавлена версия прошивки HX8357C-SLOW, для медленных экранов HX8357C, которые не справляются со стандартными таймингами
+STM32: Устранены некоторые баги в системном меню
+STM32: Настройки срабатывания вентилятора охлаждения оконечного каскада вынесены в меню калибровки (FAN Medium start, FAN Medium stop, FAN Full start). Подробности в файле README
+STM32: Настройки срабатывания защиты по температуре и КСВ вынесены в меню калибровки (MAX RF Temp, MAX SWR). Подробности в файле README
+STM32: Исправления в работе двойного приёмника, Thx R4HID(ex.RN4HAQ)
+STM32: Разделены настройки полосовых фильтров TX/RX, Thx R4DZ, R7KBI
+STM32: Доработки тракта TX, Thx R4DZ
+STM32: Доработки FM моды
+STM32: Добавлена калибровка TUNE Max Power, отвечающая за максимально возможную мощность в режиме Tune, при превышении сбавляет выход, Thx Александр Свибович
+STM32: Добавлен режим картридера, позволяющий работать с SD картой трансивера по USB (включается в меню SD)
+STM32: Доработан механизм записи эфира на SD
+STM32: К некоторым пунктам меню добавлено текстовое значение, вместо цифр
+STM32: К нижнему слайдеру меню добавлены стрелки, для прокрутки без свайпа
+STM32: Новая опция FFT Hold Peaks - сохраняет и выводит пики сигналов на спектре FFT
+STM32: Исправления работы WIFI, Thx EW3ABA
+STM32: Мелкие доработки и исправления ошибок

----Version 2.2.4----
+HARDW: Выложена раскладка кнопок 7 дюймовой панели (Front-Panel.xlsx)
+FPGA: Небольшие доработки
+STM32: Увеличены тайминги для HX8357C
+STM32: Исправлены замирания при переключении масштаба FFT
+STM32: Разделены калибровки прямого и отраженного каналов КСВ-метра, Thx АлександрDX
+STM32: Исправлено сохранение настроек на 2200м диапазоне, Thx R4HID(ex.RN4HAQ)
+STM32: Начата работа над новой темой оформления с 7-сегментными шрифтами, Thx US4LLU
+STM32: Доработки процесса инициализации тачпада GT911
+STM32: Доработка и оптимизация кода вывода FFT/WTF
+STM32: При сбросе настроек/калибровки выводится соответствующее уведомление
+STM32: Настройки компрессора TX вынесены в меню
+STM32: Добавлена возможность отключения автоматики и выставления порогов FFT вручную
+STM32: Исправление ошибок

----Version 2.2.3----
+STM32: Небольшие корректировки цветов оформления
+STM32: Ускорена отзывчивость с-метра для CW моды
+STM32: Исправление ошибок

----Version 2.2.2----
+HARDW: Добавлены PCB и гербер-файлы корпуса для 3'5 версии, автор Тихомир
+STM32: Доработан интерфейс переключения VFO на 7 дюймах, Thx Антон
+STM32: Подписи частот над сеткой FFT для 7 дюймов, Thx R6WAM
+STM32: Новая тема оформления со стрелочным индикатором, Thx R9US, Alex
+STM32: Включены подтяжки к питанию по линиям LCD, Thx EW3ABA
+STM32: Новый Digital Noise Reduction (второй, с регулировкой от IF Gain)
+STM32: Вывод иконки статуса SD карты, Thx EW3ABA
+STM32: Динамическое изменение точности FFT от скорости смены частоты
+STM32: Калибровка выходной мощности разнесена на каждый бенд индивидуально, Thx R4DZ
+STM32: Настроена система сборки Keil batch build, настройки экранов перенесены в индивидуальные target
+STM32: Улучшено звучание и исправлены ошибки в приёмном тракте, Thx R4HID(ex.RN4HAQ), R4DZ
+STM32: При переключении VFO применяются выбранные для бенда настройки DRV, PRE и т.п. , Thx R4HID(ex.RN4HAQ)
+STM32: Выведено сообщение при перегрузке ПЧ (IFO'verflow)
+STM32: Доработки по FM моде
+STM32: При записи эфира на SD в имя файла добавлена частота приёма, Thx R4HID(ex.RN4HAQ)
+STM32: Исправление ошибок, Thx R4HID(ex.RN4HAQ), R4DZ

----Version 2.2.1----
+HARDW: Удалён лишний защитный диод по линии PTT на 7 дюймовой версии
+FPGA: При отключении АЦП теперь нет ошибочных сигналов
+STM32: Исправление проблемы с USB 3.0, Thx R9US
+STM32: Поддержка переворота экрана у RA8875, Thx RZ6AT
+STM32: Доработки интерфейса на 7 дюймовой версии
+STM32: Возможность регулировки яркости экрана RA8875 через меню
+STM32: Новый дизайн выбора диапазонов на 7 дюймовой версии
+STM32: Доработки FFT, ZoomFFT, 3D FFT
+STM32: Новый параметр FFT Top: регулировка чувствительности FFT
+STM32: Поддержка до 3-х точек доступа WiFi одновременно, Thx Анатолий Ступаков
+STM32: Добавлены функции контроля стека
+STM32: Реализована функция записи эфира на SD карту
+STM32: Плавная перестройка частоты при тапе по экрану, Thx Сергей Титов
+STM32: Исправление ошибок

----Version 2.2.0----
+HARDW: Новая дополнительная плата-лицевая панель для 3'5дюймов. Thx Тихомир
+HARDW: Доработки QRP-ФНЧ платы. Thx Тихомир
+HARDW: PAM8403 заменён на PAM8406, на старых платах достаточно замкнуть 9ю ногу на землю после замены.
+STM32: Поддержка 7 дюймовых дисплеев RA8875 (800*480) + тачпада GT911
+STM32: Поддержка тангенты Yaesu MH-36 (в 7 дюймовой версии)
+STM32: Поддержка дисплея ST7796S. Thx Александр Иванов
+STM32: Доработки FFT/ZoomFFT
+STM32: Новая опция в меню: FFT HiRes - Повышение разрешения ZoomFFT за счёт большего накопления данных
+STM32: Новая опция в меню: WTF Moving - Смещение водопада вместе с изменением частоты
+STM32: Доработаны CW фильтры, Thx R4DZ
+STM32: Исправление ошибок

----Version 2.1.2----
+HARDW: Мелкие исправления оформления на схеме
+HARDW: MOTHERBOARD: Доработана обвязка УНЧ: R17(удалить), C35(замкнуть), R18(замкнуть), R8(заменить на 30кОм), C13(заменить на 1uF), вывод 10 PAM8403 подключен к земле
+FPGA: Переработан корректор частоты VCXO, улучшена работа УКВ диапазонов
+STM32: Исправление ошибок, Thx: Анатолий Ступаков, Nadir Saidoff, R4DZ, АлександрDX
+STM32: Добавлен режим проверки шины обмена с FPGA при запуске трансивера
+STM32: Улучшен механизм прошивки FPGA через STM32, Thx R4HID(ex.RN4HAQ)
+STM32: Немного уменьшен размер прошивки
+STM32: Новый пункт меню - вывод системной информации (версия прошивки, статус АЦП, VCXO и т.п.), Thx R4HID(ex.RN4HAQ)
+STM32: Расширен ассортимент фильтров CW от 100гц до 1000гц в шагом 50гц, Thx R4DZ
+STM32: Доработаны CW Gauss фильтры, Thx R4DZ
+STM32: Доработан CW ключ, Thx R4DZ
+STM32: Сглажены фронты CW сигналов, Thx R4DZ
+STM32: Новые оконные функции для FFT, по умолчанию используем Dolph–Chebyshev
+STM32: Улучшено качество и контрастность спектра, разрешение ZoomFFT
+STM32: Реализована работа трансивера с Windows 7
+STM32: Оптимизация кода
+STM32: Новая опция FFT Style: 4 вида отображения спектра: градиент, заливка, точки, контур

----Version 2.1.1----
+HARDW: Новая дополнительная плата-расширение с ФНЧ фильтрами. Thx Тихомир
+HARDW: RF-UNIT: изменение номиналов C38 и C80 с 1n до 100n  - улучшение АЧХ на 160/80м
+HARDW: RF-UNIT: изменение номиналов L39, L47, R32, R46, C111, C81 и тока покоя оконечника - улучшение линейности на всех бендах
+HARDW: MOTHERBOARD: исправление зазоров и настроек слоёв, теперь плата отображается в JLCPCB предпросмотре. Thx R7KBI
+HARDW: Новая, перерисованная схема от R7KBI (в папке Scheme/ALTIUM_DESIGNER/R7KBI), намного более привычная для Русских пользователей
+FPGA: Оптимизация и исправление ошибок
+STM32: Оптимизация кода
+STM32: Доработка кода вывода FFT
+STM32: Водопад стал более плавным при изменении частоты
+STM32: Доработан процесс выключения
+STM32: Отрезаны неиспользуемые части FFT спектра
+STM32: Режим линзы для FFT
+STM32: Режим 3D FFT
+STM32: Очистка буффера TX при переходе в режим приёма
+STM32: Поправка на КСВ метр для 2м диапазона
+STM32: Исправление ошибок, Thx R4HID(ex.RN4HAQ)

----Version 2.1.0----
+HARDW: Возможность измерения КСВ на сверх-малых мощностях, используя усилитель AD8307. Дополнительная плата расширения + изменения в коде. Thx Тихомир
+HARDW: 4-я нога драйвера OPA2673 посажена на землю, на старых версиях плат желательно соединить дорожки вручную. Thx R7KBI
+HARDW: Для улучшения стабильности на 145МГц, на плате Motherboard резистор R53 заменён на C55 номиналом 7.5pf
+HARDW: Для улучшения согласования входа оконечника на 145МГц, на плате RF-UNIT удален конденсатор C8, трансформатор T5 включен в широкополосном варианте, и добавлена согласующая цепь L48, C55
+HARDW: Мощность на УКВ поднялась до 5 ватт, убраны искажения. Заменены номиналы RF-UNIT R34, R38, новые трансформаторы по выходу
+FPGA: Оптимизация кода
+FPGA: Увеличена точность NCO
+STM32: Обновлен драйвер, добавлена поддержка Windows 7/8 (требуется тестирование)
+STM32: Исправлен шум DC-DC на некоторых частотах
+STM32: Рядом с температурой добавлен знак градуса, RF переменован в PA
+STM32: Сообщения об ошибках (например перегрузка по входу) перенесены над текст моды
+STM32: Для AM моды добавлен DC-фильтр
+STM32: Для CW моды теперь доступен фильтр с распределением Гаусса (приём пика в центре полосы)
+STM32: Отдельный параметр ZoomFFT для CW моды
+STM32: Новый пункт меню: запуск автообновления прошивки ESP-01 (для SDK2 и выше, при активном интернете)
+STM32: Релизован режим WSPR маяка
+STM32: Исправление ошибок

----Version 2.0.9----
+FPGA: Улучшены характеристики приёмника, ДД, фильтры и подавление зеркал
+STM32: Исправлено сохранение моды при смене диапазона и активном Bandmap
+STM32: Исправлено моргание при переходе в меню по горячим клавишам
+STM32: Меню теперь можно использовать без применения основного энкодера, только второстепенным + его нажатием
+STM32: Исправление ошибок
+STM32: Исправлено моргание некоторых элементов интерфейса
+STM32: Сокращение расхода CPU и памяти за счёт индексирования палитры цветов
+STM32: Графическое отображение конфигурации фильтров LPF/HPF и положение Shift, thx R6WAM

----Version 2.0.8----
+FPGA: Доработки функции обновления прошивки FPGA
+STM32: Исправления ошибок
+STM32: Изменения в карте диапазонов
+STM32: При неподключенной RF-UNIT не отображается отрицательная температура
+STM32: Для FM мод добавлен De emphasis фильтр

----Version 2.0.7----
+HARDW: На схеме исправлен тип кабеля в трансформаторе оконечного каскада
+HARDW: Изменён номинал R37 в RF-UNIT, thx Александр Иванов
+HARDW: Увеличены прощадки под D18, D23 в RF-UNIT, thx Анатолий Ступаков
+HARDW: Увеличены прощадки под C33, C34 в MOTHERBOARD, thx Анатолий Ступаков
+HARDW: Увеличены прощадки креплений у FPC разъёмов, thx Анатолий Ступаков
+HARDW: Увеличен диаметр отверстий разъёмов питания, thx Анатолий Ступаков
+HARDW: Батарейка заменена на отсек KLS5-CR1220-01, thx Анатолий Ступаков
+HARDW: Скорректированы координаты пинов питания 3'2 дисплея
+HARDW: Экспортированы Assembly PDF файлы
+FPGA: Улучшена точность VCXO коррекции
+FPGA: Оптимизация кода
+STM32: Исправление ошибок
+STM32: Добавлены всплывающие уведомления для некоторых функций
+STM32: Добавлена поддержка LCD HX8357C, R61581 (в тестовом режиме)
+STM32: Добавлен WIFI сервис - вывод информации по прохождению на КВ/УКВ
+STM32: Добавлен WIFI сервис - вывод информации по диплому RDA
+STM32: Заложен механизм смены темы оформления
+STM32: Оптимизация скорости кода
+STM32: Оптимизация потребления памяти
+STM32: Переход на DMA2D для функций заливки
+STM32: Добавлен диапазон калибровки мощности оконечного каскада 15-30МГц
+STM32: Настройка акселератора энкодера вынесена в меню калибровки
+STM32: Добавлена проверка контрольной суммы при считывании калибровки

----Version 2.0.6----
+HARDW: Оптимизированы цепи ЦАП, замена номиналов R34, R35, R16
+HARDW: Оптимизированы цепи Драйвера, замена номиналов R53
+HARDW: Оптимизированы цепи TCXO, замена номиналов R45, C134
+HARDW: На схеме указаны напряжения во всех точках ВЧ цепи TX материнской платы
+FPGA: Исправления по цепям TX
+STM32: Исправления по цепям TX

----Version 2.0.5----
+HARDW: Новая плата для дисплея ILI9486, Thx Тихомир
+HARDW: Новая плата-расширение Motherboard с УНЧ TS4994, Thx Тихомир
+STM32: Базовый функционал работы с SD: определение подключения, вывод размера тома
+STM32: Возможность форматирования SD карты через меню
+STM32: Бекап настроек теперь также хранится в EEPROM, а не только в SRAM
+STM32: Добавлена поддержка дисплеев ILI9486, Thx Тихомир
+STM32: Возможность экспорта настроек и калибровок на SD карту
+STM32: Возможность импорта настроек и калибровок из SD карты
+STM32: Оптимизирован и доработан код работы с EEPROM
+STM32: Настройки скорости SPI шины для SD, FRONT-UNIT и EEPROM вынесены в settings.h
+STM32: Исправление ошибок
+STM32: Новая настройка: ревербератор микрофона
+STM32: Доработки AGC, добавлен кольцевой буффер для анализа будущих семплов
+STM32: Режим быстрой регулировки WPM в CW моде с помощью дополнительного энкодера
+STM32: Поддержка разных цветовых тем оформления. Новая настройка "Color Theme" для переключения на лету
+STM32: Добавлена белая тема оформления
+STM32: Режим работы с трансвертером, отображение частоты с учётом смещения

----Version 2.0.4----
+HARDW: Исправление мелких ошибок на Motherboard, Thx Тихомир, Владимир Емельянцев
+HARDW: Пересчитаны BPF фильтры на более корректные и эффективные, Thx ideapad2009
+HARDW: Новый слот под SD карту (FRONT-UNIT)
+HARDW: Прототип платы под 7 дюймовый дисплей
+HARDW: Для избежания перегрузки LNA на КВ, уменьшены номиналы С112 и C120 (RF-UNIT)
+STM32: Приоритетные участки кода отправлены в ITCM память
+STM32: Начальный этап поддержки 7 дюймового дисплея RA8875 с тачпадом GT911
+STM32: Оптимизации частей кода
+STM32: Исправлена формула расчёта S-метра под разные режимы работы (PGA, DRV), Thx Тихомир
+STM32: Доработан Fast step вторичного энкодера
+STM32: Доработан AutoGainer, настройки сохраняются по диапазонам
+STM32: Исправлено дрожание температуры ОУ при промежуточных значениях
+STM32: Более плавная регулировка громкости
+STM32: Доработан AGC, разделены настройки для SSB и CW, Thx Сергей Туров
+STM32: Настройки сохраняются в два банка памяти по очереди
+STM32: Корректность сохранённых настроек проверяется контрольной суммой
+STM32: Вывод приветствия (напр. позывного) на экране загрузки

----Version 2.0.3----
+STM32: Исправление ошибок, щелчков
+STM32: Доработки AGC
+STM32: Компрессия пиков для предотвращения перегрузки FFT (настройка FFT Compressor)
+STM32: Изменён интерфейс, под водопад выделено больше места
+STM32: На S-метр добавлен кубик, отображающий пиковую амплитуду сигнала
+STM32: Звуковое подтверждение нажатия на кнопки (отключается через меню настроек)
+STM32: Новая настройка FFT Background, рисует градиентный фон за спектром
+STM32: SSB шумоподавитель на основе VAD (Voice Activity Detector), настройка VAD Squelch
+STM32: Режим сканера(поиска) сигналов SSB
+STM32: Динамический энкодер, автоматическое ускорение при высокой скорости вращения, Thx R3TJL
+STM32: Доработан AutoNotch
+STM32: Доработан AutoGainer
+STM32: Доработан анализатор спектра
+STM32: Добавлена защита оконечного каскада от перегрева и высокого КСВ
+STM32: Добавлена функция построения графиков КСВ по диапазону(ам)

----Version 2.0.2----
+HARDW: Добавлена широкая версия FRONT-PANEL, с более удобным расположением кнопок, но с другими креплениями, Thx R7KBI
+STM32: Исправлена ошибка с двойным приёмником, когда один канал в FM
+STM32: Исправлена работа S-метра
+STM32: Доработан внешний вид S-метра
+STM32: Доработан внешний вид FFT/WTF
+STM32: Реализована сетка на водопаде
+STM32: Частота ядра повышена до 480 MHz
+STM32: Доработан AutoGainer, проверяет наличие интермодов в LNA
+STM32: Dither и Randomizer АЦП включены по умолчанию
+STM32: Разделена поддержка дисплеев ILI9481 и HX8357B
+STM32: Улучшено отображение на ILI9481
+STM32: Исправление мелких ошибок
Thx to: коллегам из https://t.me/SDR_Radio за ценные идеи:
+STM32: Новая настройка FFT Height: занимаемой высоты FFT и водопада
+STM32: Новая настройка FFT Color: семь видов цветовой гаммы оформления спектра
+STM32: Вывод текущей ширины полосы на экран
+STM32: Вывод текущей температуры оконечного каскада и STM32 на экран
+STM32: Вывод RX/TX/Tune на экран
+STM32: Шрифт разряда герц уменьшен и стал светлее
+STM32: Выведено значение RIT
+STM32: Перенесены и перекрашены значки функций
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

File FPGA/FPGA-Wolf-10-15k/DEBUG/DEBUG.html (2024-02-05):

DEBUG

2022.11.27.12:52:08 | Datasheet

Overview

Memory Map

## in_system_sources_probes_0

altera_in_system_sources_probes v18.1

Parameters

device_family | CYCLONEIVE
gui_use_auto_index | true
sld_auto_instance_index | YES
sld_instance_index | 0
instance_id | DBG1
probe_width | 32
source_width | 0
source_initial_value | 0
create_source_clock | false
create_source_clock_enable | false
enable_metastability | NO
deviceFamily | UNKNOWN
generateLegacySim | false

Software Assignments
(none)

generation took 0,02 seconds | rendering took 0,02 seconds

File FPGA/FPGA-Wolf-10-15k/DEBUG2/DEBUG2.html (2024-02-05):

DEBUG2

2022.11.27.13:36:10 | Datasheet

Overview

Memory Map

## in_system_sources_probes_0

altera_in_system_sources_probes v18.1

Parameters

device_family | CYCLONEIVE
gui_use_auto_index | true
sld_auto_instance_index | YES
sld_instance_index | 0
instance_id | DBG2
probe_width | 3
source_width | 0
source_initial_value | 0
create_source_clock | false
create_source_clock_enable | false
enable_metastability | NO
deviceFamily | UNKNOWN
generateLegacySim | false

Software Assignments
(none)

generation took 0,02 seconds | rendering took 0,02 seconds

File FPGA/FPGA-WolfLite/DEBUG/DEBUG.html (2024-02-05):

DEBUG

2022.04.04.00:42:04 | Datasheet

Overview

Memory Map

## in_system_sources_probes_0

altera_in_system_sources_probes v18.1

Parameters

device_family | CYCLONEIVE
gui_use_auto_index | true
sld_auto_instance_index | YES
sld_instance_index | 0
instance_id | DBG1
probe_width | 24
source_width | 0
source_initial_value | 0
create_source_clock | false
create_source_clock_enable | false
enable_metastability | NO
deviceFamily | UNKNOWN
generateLegacySim | false

Software Assignments
(none)

generation took 0,01 seconds | rendering took 0,03 seconds

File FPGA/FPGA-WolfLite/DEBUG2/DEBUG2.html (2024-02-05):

DEBUG2

2022.05.19.19:26:26 | Datasheet

Overview

Memory Map

## in_system_sources_probes_0

altera_in_system_sources_probes v18.1

Parameters

device_family | CYCLONEIVE
gui_use_auto_index | true
sld_auto_instance_index | YES
sld_instance_index | 0
instance_id | DBG2
probe_width | 1
source_width | 0
source_initial_value | 0
create_source_clock | false
create_source_clock_enable | false
enable_metastability | NO
deviceFamily | UNKNOWN
generateLegacySim | false

Software Assignments
(none)

generation took 0,01 seconds | rendering took 0,02 seconds

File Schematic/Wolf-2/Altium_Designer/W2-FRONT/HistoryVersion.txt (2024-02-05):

V05:
Первая тестовая версия

V06:
- Заменен корпус W25Q16 на SOICW-8
- увеличены дорожки +3.3vSTM
- Исправить футпринты регуляторов и энкодеров

V07:
1. Найден косяк с зеркальной разводкой сд-карты, исправил. 
2. Неверный тип корпуса у 25q16, исправлено. 
3. ШИМ по схеме для LCD МР3202 заменен на 4103, т.к. первый грелся. 4103 также стоит на оригинальной плате дисплея. 
4. Чуть подправил отверстия под энкодеры и переменники. Кто-то их просил увеличить, оказалось во вред, тяжело спозиционировать их ровно при таких широких отверстиях.
5. Перенес разъем подключения основного энкодера под диапазонные кнопки, так будет удобнее при установке в корпус. 
6. Подправил термопады

V08:
1. Добавлен подтягивающий резистор в цепи BOOT для более стабильного запуска STM32.
2. Замена футпринтов разъемов(добавлены ключи для удобства ориентации разъемов).
3. Замена батарейки и держателя на компактную CR1220 для удобного доступа внутри будущего корпуса.
4. Заменен дроссель в ШИМ +5в, чуть расширены площадки теплоотвода под ST1S10 (+разнесены между собой)

V09:
1. Кнопка питания заменена на тактовую со встроенной подсветкой.

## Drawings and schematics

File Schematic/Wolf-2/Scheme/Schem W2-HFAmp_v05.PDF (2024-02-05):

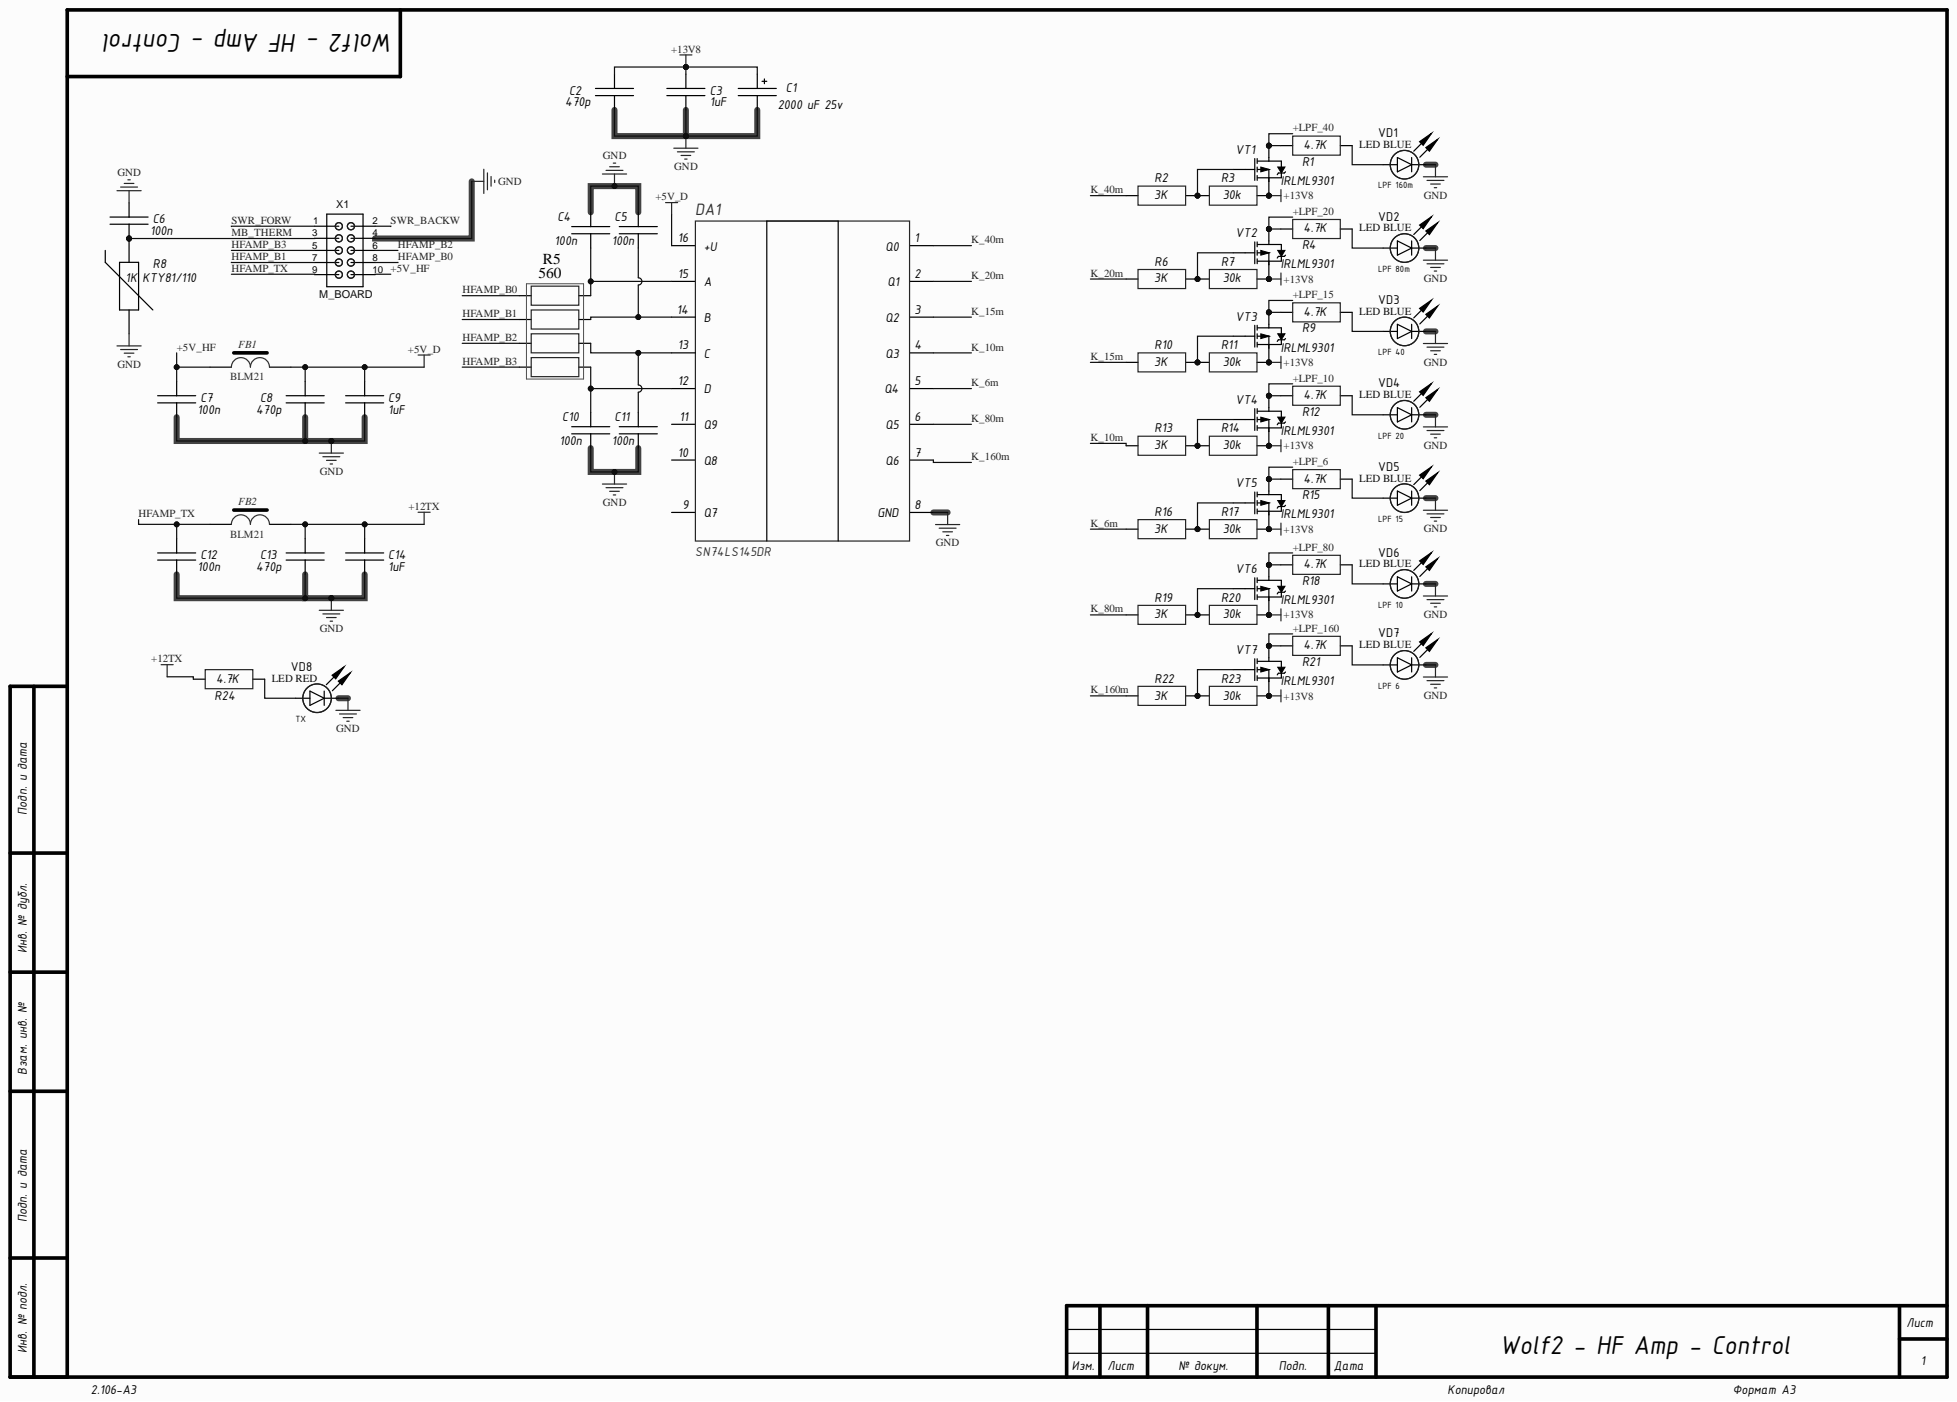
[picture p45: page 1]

Инв. № подл. Инв. № дубл. Подп. и дата Взам. инв. № Подп. и дата

Wolf2 - HF Amp - Control | Лист1

Изм . | Лист | № докум . | Подп . | Да т а

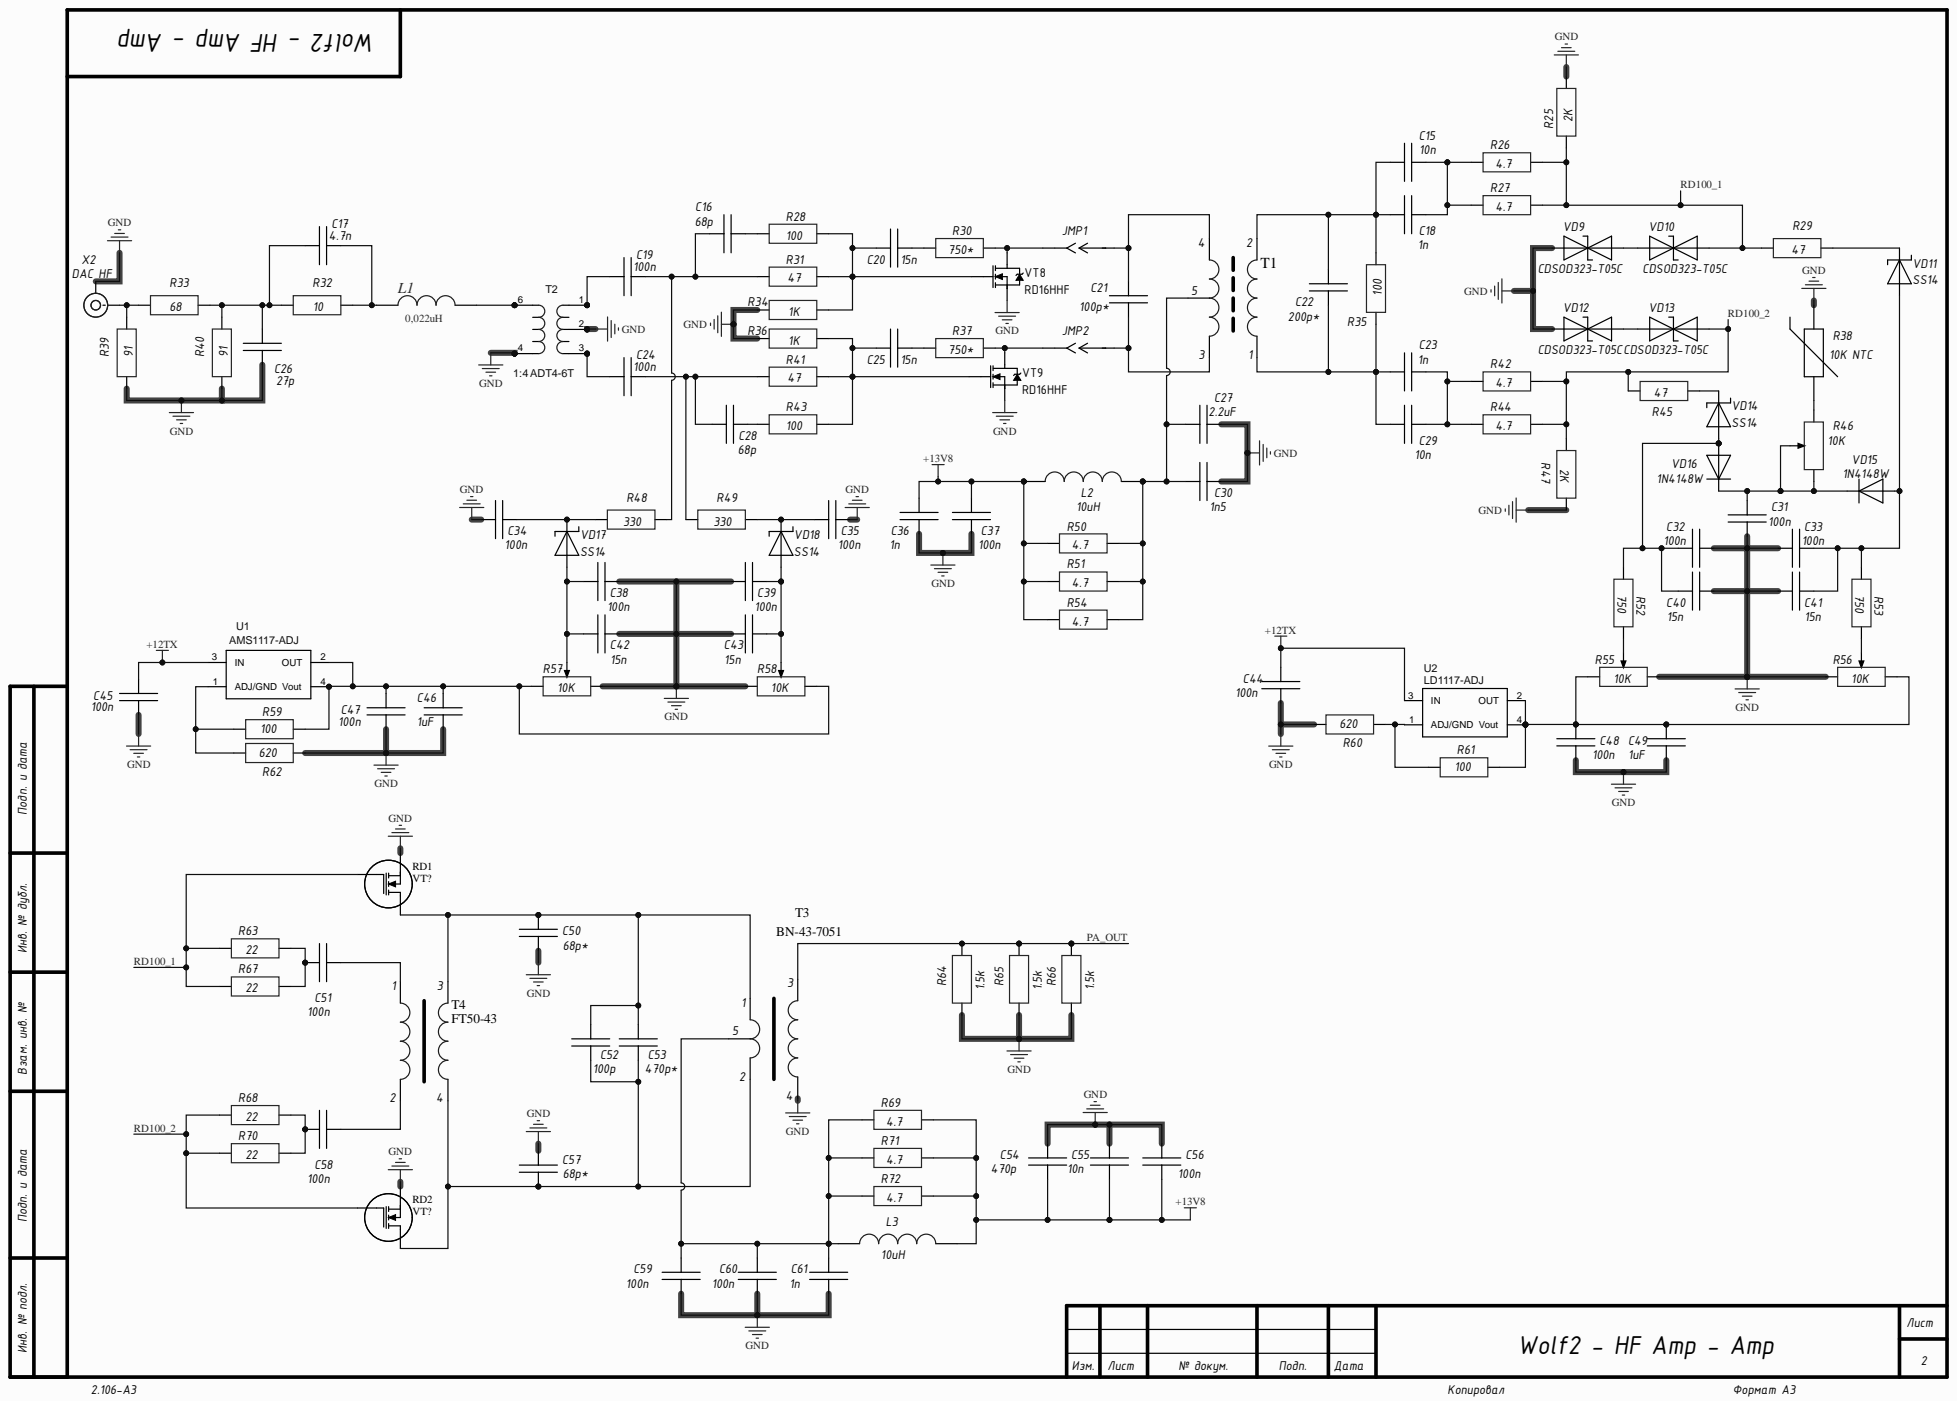
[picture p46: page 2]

Инв. № подл. Инв. № дубл. Подп. и дата Взам. инв. № Подп. и дата

Wolf2 - HF Amp - Amp

Изм. | Лист | № докум. | Подп. | Дата

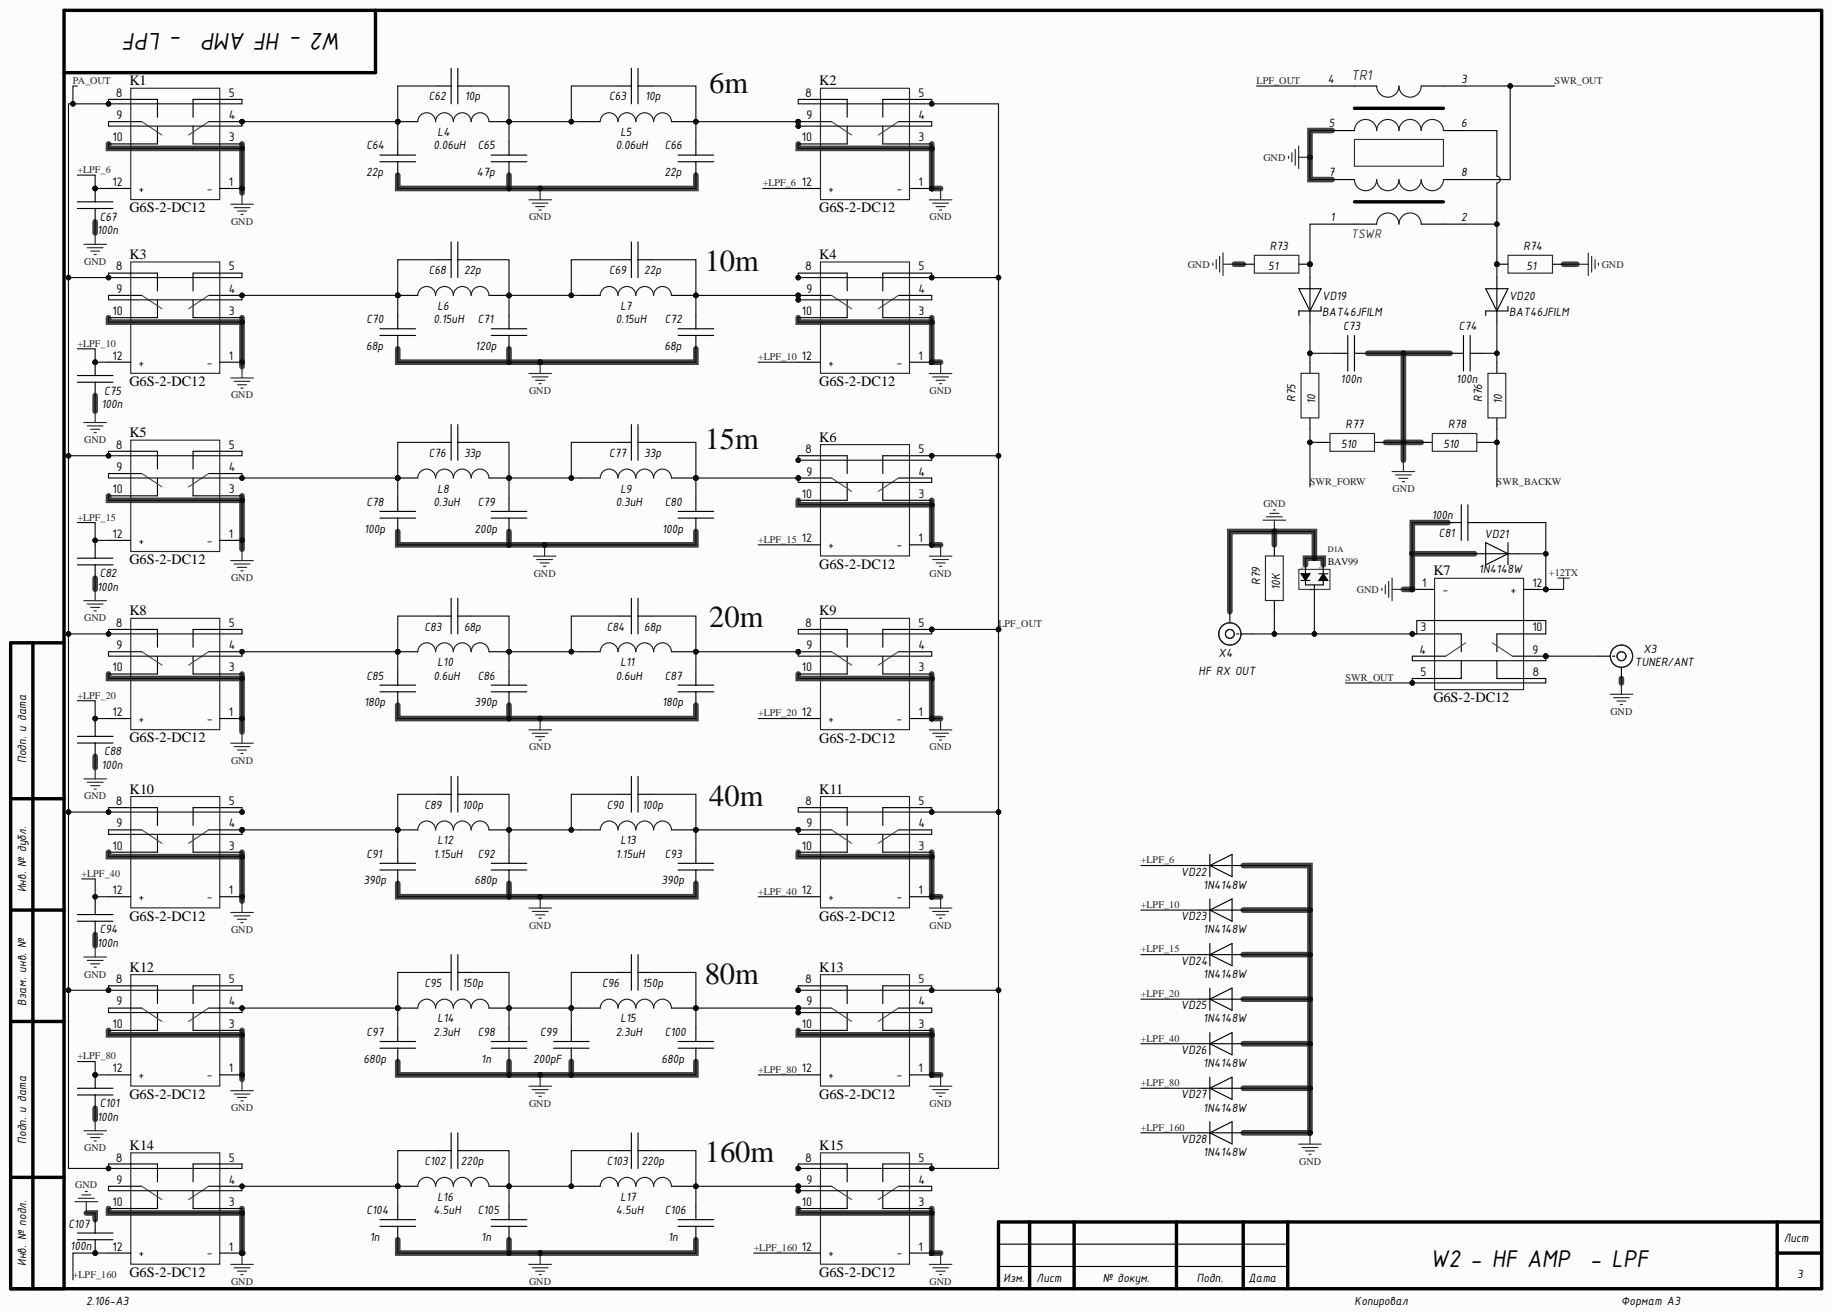
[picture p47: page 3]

+LPF_ | 9

Инв. № подл. Инв. № дубл. Подп. и дата Взам. инв. № Подп. и дата

+LPF_ | 9 | | 43

100n GNDGN 9 | 43

W2 - HF AMP - LPF | Лист3

Изм . | № докум . | Подп . | Да т а

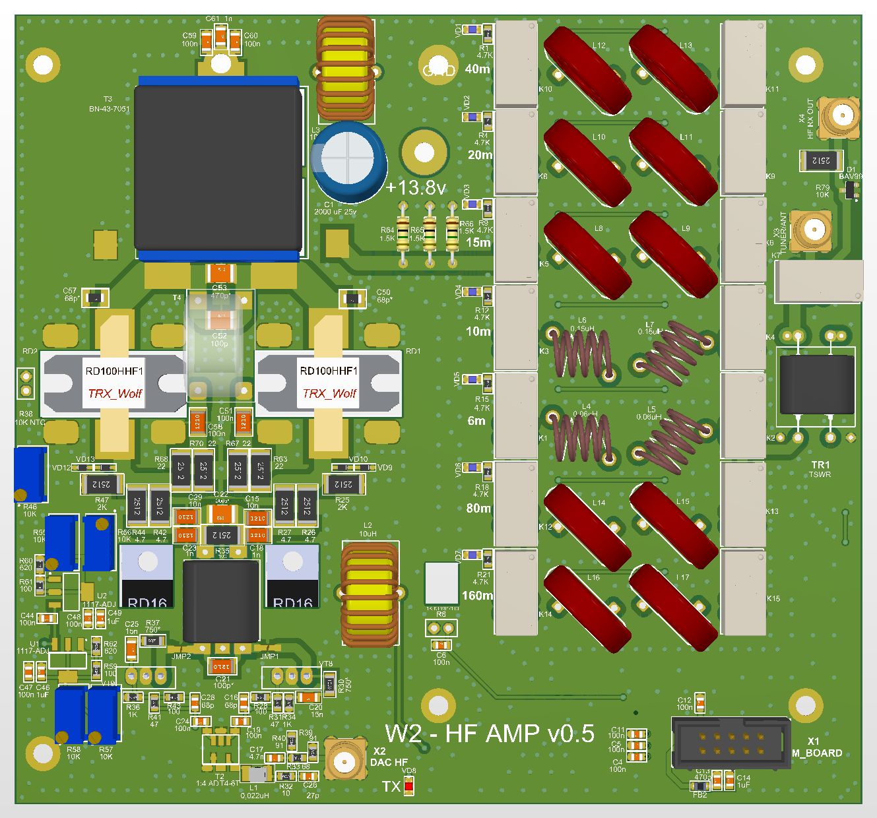
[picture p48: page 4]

Comment | Description | Designator | Footprint | LibRef | Quantity
2000 uF 25v | | C1 | D13C5H20 | AlumCap | | 1
470p | | C2, C8, C13 | CH0805C | Capacitor | | 3
1uF | | C3, C9, C14, C46, C49 | CH0805C | Capacitor | | 5
100n | | C4, C5, C6, C7, C10, C11, C12, C19, C24, C31, C32, C33, C34, C35, C37, C38, C39, C44, C45, C47, C48, C67, C75, C82, C88, C94, C101, C107 | CH0805C | Capacitor | 28
10n | | C15, C29 | CH1210C | Capacitor | | 2
68p | | C16, C28 | CH0805C | Capacitor | | 2
4.7n | | C17 | CH0805C | Capacitor | | 1
1n | | C18, C23 | CH1210C | Capacitor | | 2
15n | | C20, C25 | CH1206C | Capacitor | | 2
100p* | | C21 | CH1210C | Capacitor | | 1
200p* | | C22 | CH1812C | Capacitor | | 1
27p | | C26 | CH0805C | Capacitor | | 1
2.2uF | | C27 | CH1206C | Capacitor | | 1
1n5 | | C30 | CH1206C | Capacitor | | 1
1n | | C36 | CH0805C | Capacitor | | 1
15n | | C40, C41, C42, C43 | CH0805C | Capacitor | | 4
68p* | | C50, C57 | CH1206ATC | Capacitor | | 2
100n | | C51, C58 | CH1210C | Capacitor | | 2
100p | | C52 | CH1812C | Capacitor | | 1
470p* | | C53 | CH1812C | Capacitor | | 1
470p | | C54 | CH1206C | Capacitor | | 1
10n | | C55 | CH1206C | Capacitor | | 1
100n | | C56, C59, C60, C73, C74, C81 | CH1206C | Capacitor | | 6
1n | | C61 | CH1206C | Capacitor | | 1
10p | | C62, C63 | CH1206ATC | Capacitor | | 2
22p | | C64, C66, C68, C69 | CH1206ATC | Capacitor | | 4
47p | | C65 | CH1206ATC | Capacitor | | 1
68p | | C70, C72, C83, C84 | CH1206ATC | Capacitor | | 4
120p | | C71 | CH1206ATC | Capacitor | | 1
33p | | C76, C77 | CH1206ATC | Capacitor | | 2
100p | | C78, C80, C89, C90 | CH1206ATC | Capacitor | | 4
200p | | C79 | CH1206ATC | Capacitor | | 1
180p | | C85, C87 | CH1206ATC | Capacitor | | 2
390p | | C86, C91, C93 | CH1206ATC | Capacitor | | 3
680p | | C92, C97, C100 | CH1206ATC | Capacitor | | 3
150p | | C95, C96 | CH1206ATC | Capacitor | | 2
1n | | C98, C104, C105, C106 | CH1206ATC | Capacitor | | 4
200pF | | C99 | CH1206ATC | Capacitor | | 1
220p | | C102, C103 | CH1206ATC | Capacitor | | 2
BAV99 | | D1 | SOT23_132 | BAV99 | | 1
SN74LS145DR | | DA1 | 16-SOP | SN74LS145N | | 1
BLM21 | | FB1, FB2 | CH0805L | FB-1 | | 2
Jumper_2 | Jumper | JMP1, JMP2 | CON: JUMPER_2 | Jumper_2 | | 2
G6S-2-DC12 | | K1, K2, K3, K4, K5, K6, K7, K8, K9, K10, K11, K12, K13, K14, K15 | G6S-2-DC12 | G6S-2-12VDC | 15
0,022uH | | L1 | CH1210L | Inductor-2 | | 1
10uH | | L2, L3 | IND: R24 | Inductor ring | | 2
0.06uH | | L4, L5 | DR1 | Inductor ring | | 2
0.15uH | | L6, L7 | DR1 | Inductor ring | | 2
0.3uH | | L8, L9 | T68-0 | Inductor ring | | 2
0.6uH | | L10, L11 | T68-0 | Inductor ring | | 2
1.15uH | | L12, L13 | T68-0 | Inductor ring | | 2
2.3uH | | L14, L15 | T68-0 | Inductor ring | | 2
4.5uH | | L16, L17 | T68-0 | Inductor ring | | 2
4.7K | | R1, R4, R9, R12, R15, R18, R21, R24 | CH0805R | Resistor | | 8
3K | | R2, R6, R10, R13, R16, R19, R22 | CH0805R | Resistor | | 7
30k | | R3, R7, R11, R14, R17, R20, R23 | CH0805R | Resistor | | 7
560 | | R5 | CAT16 | CAT10-0804 | | 1
1K KTY81/110 | | R8 | CON: PBS-2 | NTC | | 1
2K | | R25, R47 | CH2512R | Resistor | | 2
4.7 | | R26, R27, R42, R44, R50, R51, R54, R69, R71, R72 | CH2512R | Resistor | 10
100 | | R28, R43, R59, R61 | CH0805R | Resistor | | 4
47 | | R29, R31, R41, R45 | CH0805R | Resistor | | 4
750* | | R30, R37 | CH1206R | Resistor | | 2
10 | | R32, R75, R76 | CH0805R | Resistor | | 3
68 | | R33 | CH0805R | Resistor | | 1
1K | | R34, R36 | CH0805R | Resistor | | 2
100 | | R35 | CH2512R | Resistor | | 1
10K NTC | | R38 | CON: PBS-2 | NTC | | 1
91 | | R39, R40 | CH0805R | Resistor | | 2
10K | | R46, R55, R56, R57, R58 | RES: 3296W | ADJ resistor | | 5
330 | | R48, R49 | CH0805R | Resistor | | 2
750 | | R52, R53 | CH0805R | Resistor | | 2
620 | | R60, R62 | CH0805R | Resistor | | 2
22 | | R63, R67, R68, R70 | CH2512R | Resistor | | 4
1.5k | | R64, R65, R66 | R-DIP | Resistor | | 3
51 | | R73, R74 | CH1206R | Resistor | | 2
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

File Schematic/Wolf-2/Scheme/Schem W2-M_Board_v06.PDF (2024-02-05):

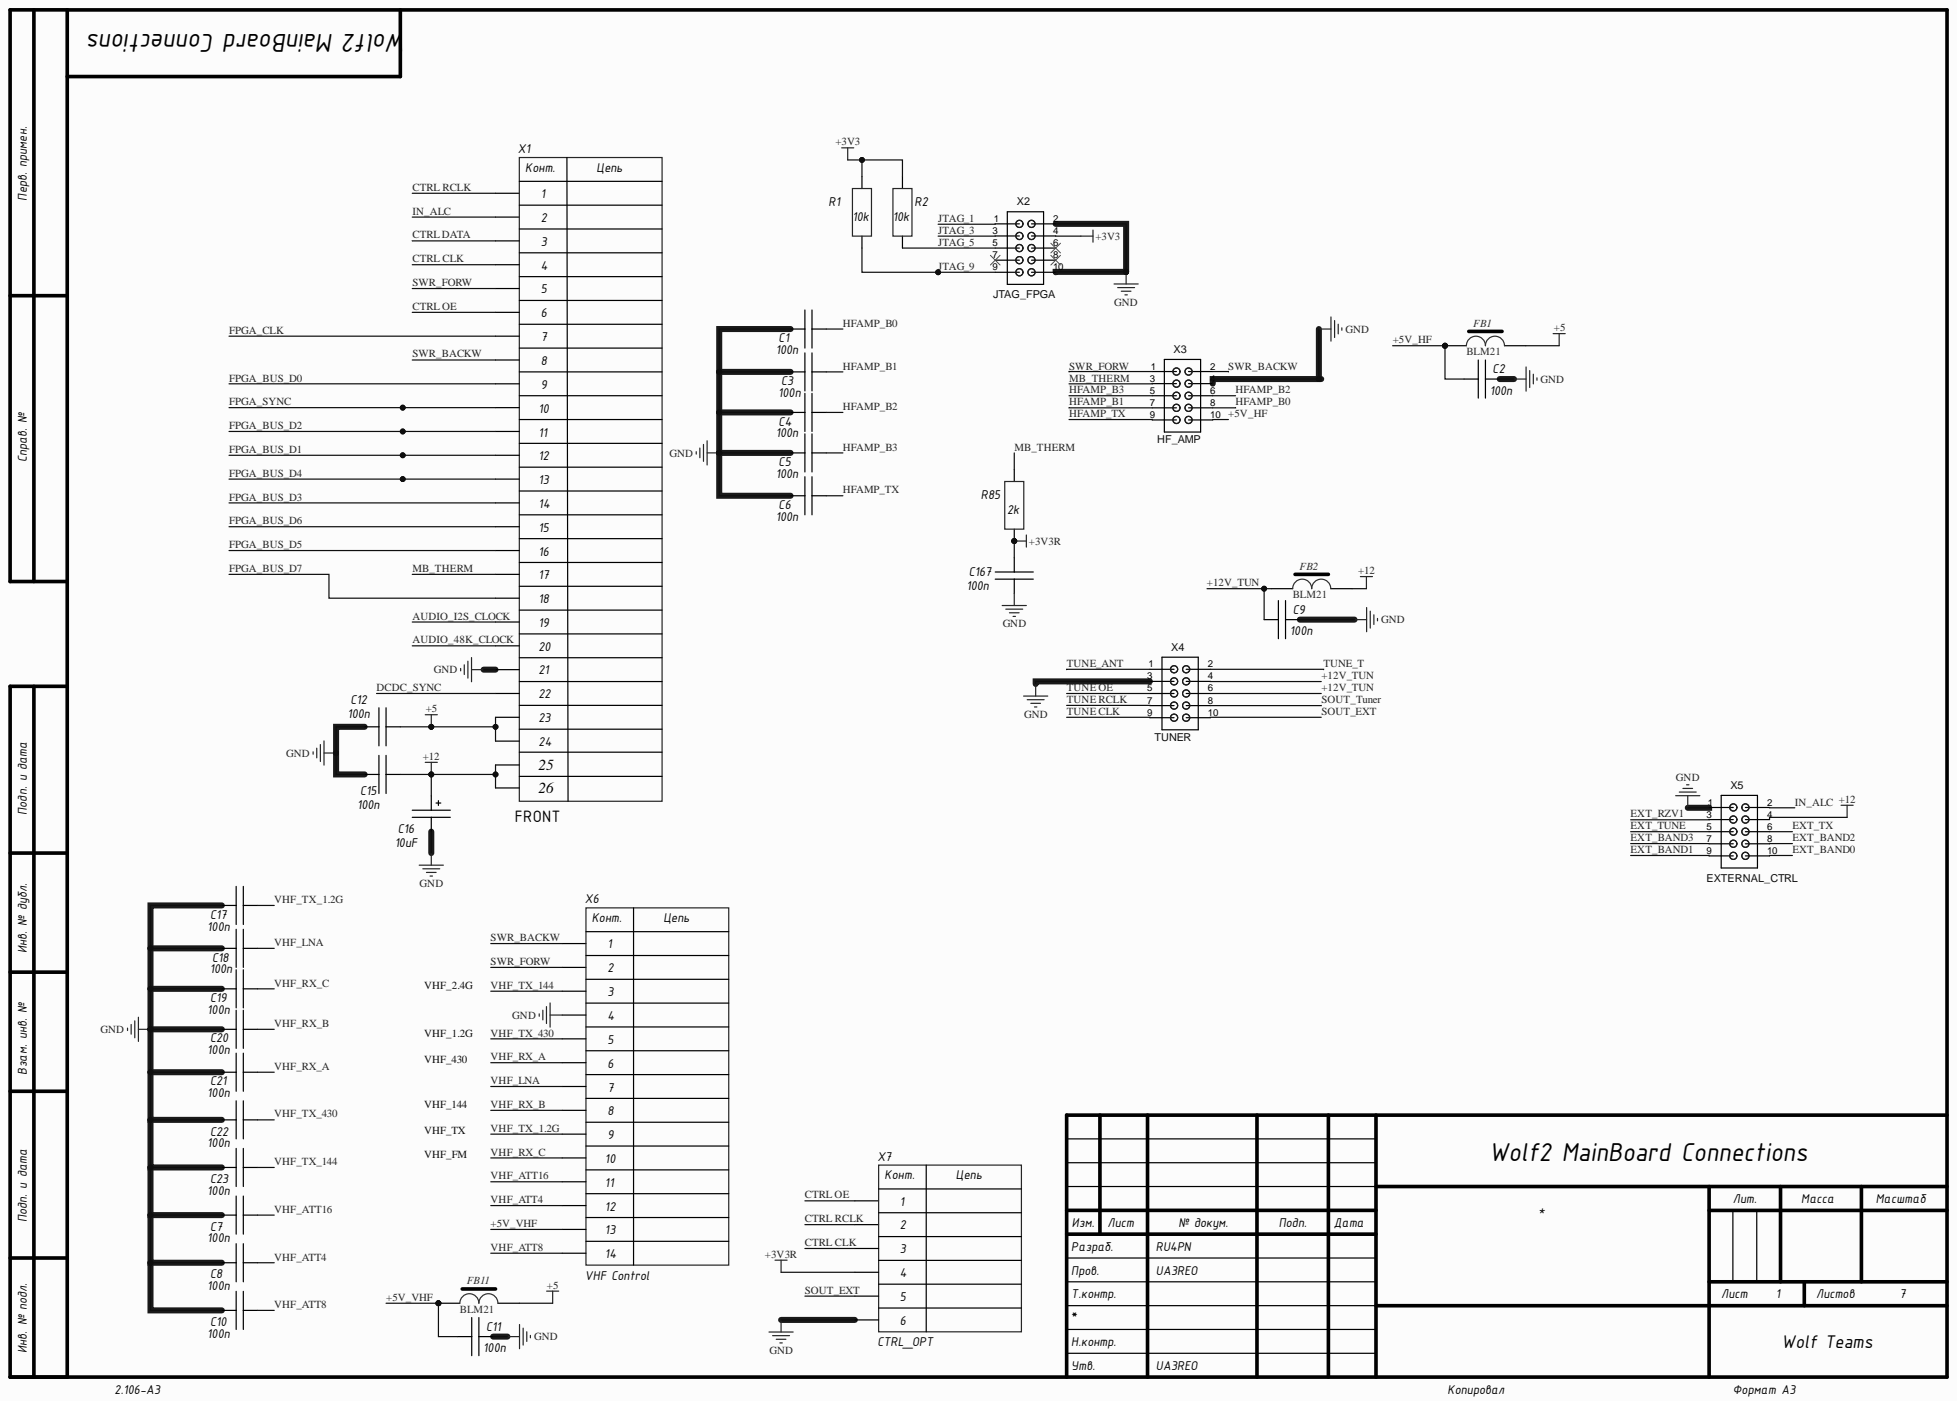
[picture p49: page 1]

Инв. № подл. Инв. № дубл. Подп. и дата Взам. инв. № Подп. и дата Перв. примен. Справ. №

Конт. | Цепь

JTAG_9 | 7 | 8

24
25
26

Т.контр. | | Лист | Листов 7
* | | Wolf Teams

Н.контр.

Утв. | UA3REO

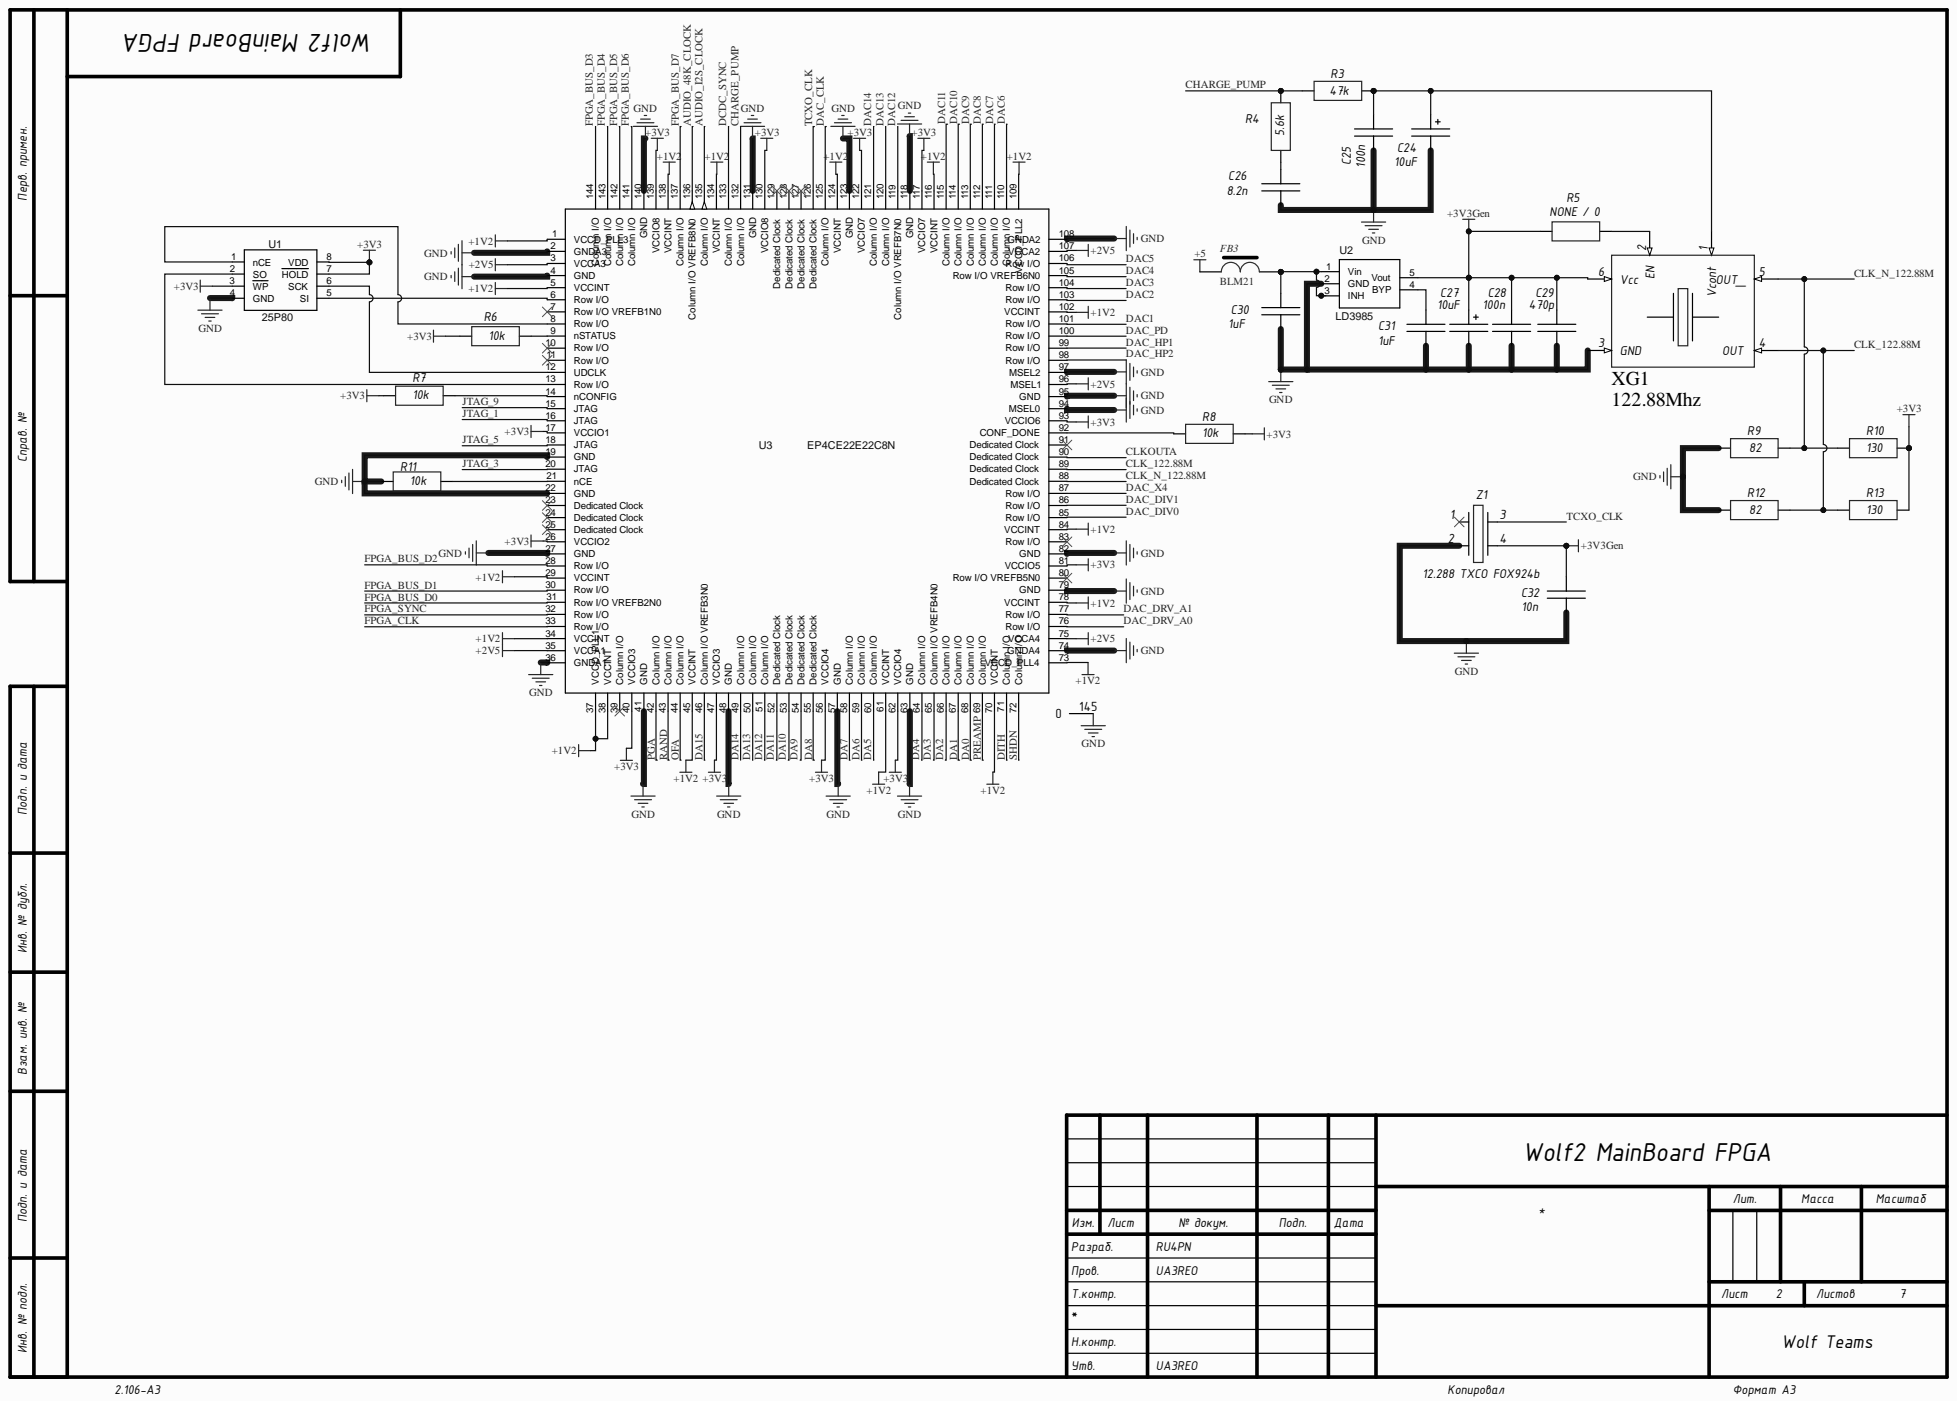
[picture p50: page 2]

Инв. № подл. Инв. № дубл. Подп. и дата Взам. инв. № Подп. и дата Перв. примен. Справ. №

Column I/O 72 Column I/O 71 VCCINT 70 Column I/O 69 Column I/O 68 Column I/O 67 Column I/O 66 Column I/O VREFB4N0 65 Column I/O 64 GND 63 VCCIO4 62 VCCINT 61 Column I/O 60 Column I/O 59 Column I/O 58 GND 57 VCCIO4 56 Dedicated Clock 55 Dedicated Clock 54 Dedicated Clock 53 Dedicated Clock 52 Column I/O 51 Column I/O 50 Column I/O 49 GND 48 VCCIO3 47 Column I/O VREFB3N0 46 VCCINT 45 Column I/O 44 Column I/O 43 Column I/O 42 GND 41 VCCIO3 40 Column I/O 39 VCCINT 38 VCCD_PLL1 37

Wolf2 MainBoard FPGA

* | Лит. | Масса | Масштаб

Изм. | Лист | № докум. | Подп. | Дата

Разраб. | | RU4PN

Пров. | | UA3REO

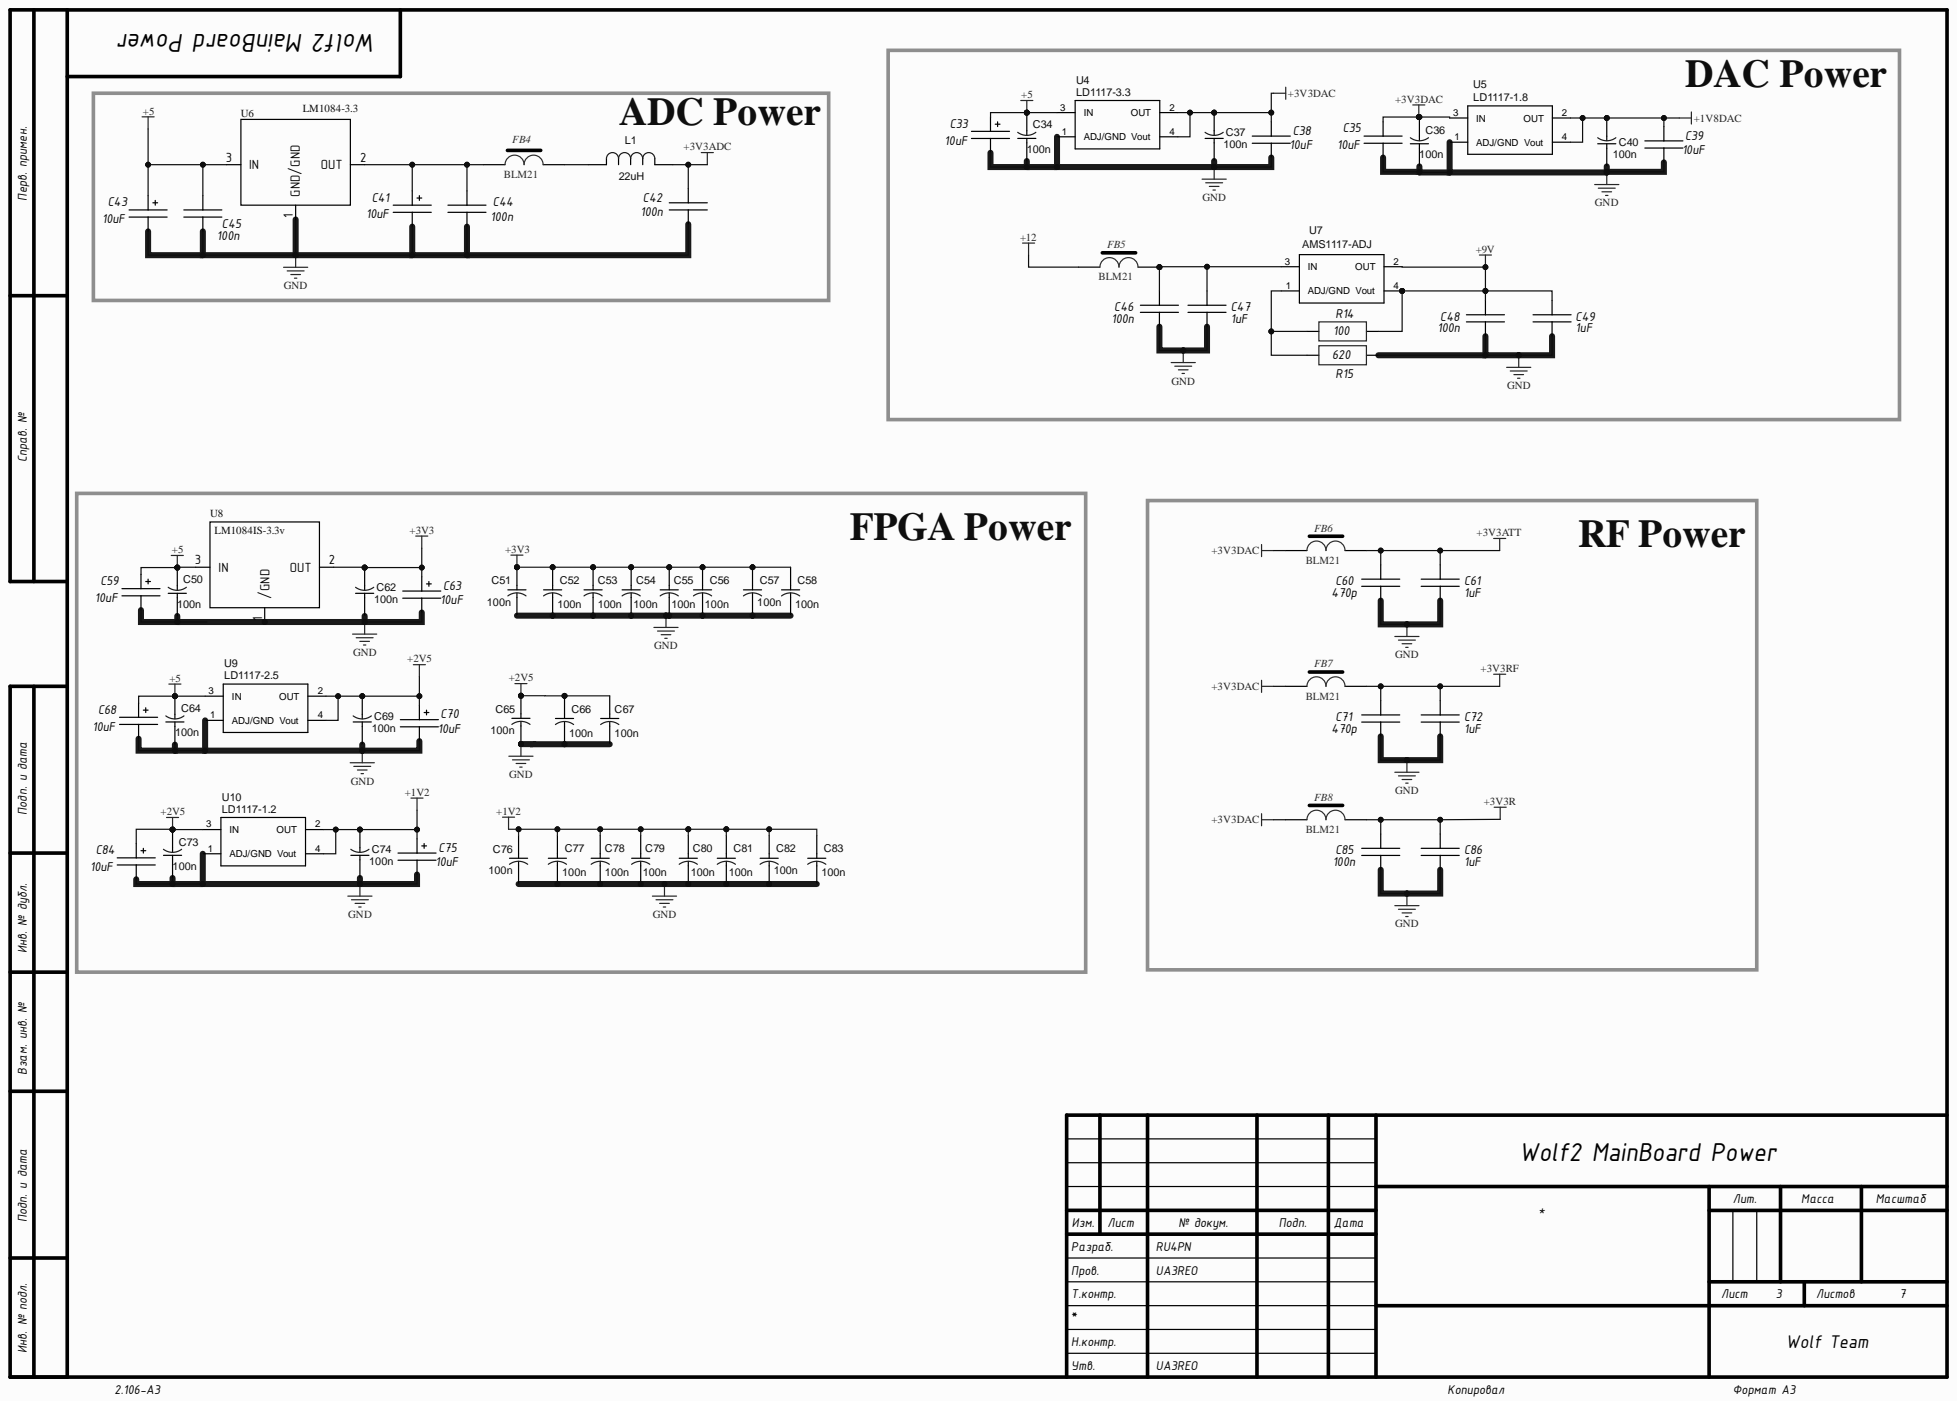
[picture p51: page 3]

Инв. № подл. Инв. № дубл. Подп. и дата Взам. инв. № Подп. и дата Перв. примен. Справ. №

+3V3ATT C61 +3V3RF

ADJ/GND 1

Wolf2 MainBoard Power

* | Лит. | Масса | Масштаб

Изм. | Лист | № докум. | Подп. | Дата

Разраб. | | RU4PN

Пров. | | UA3REO

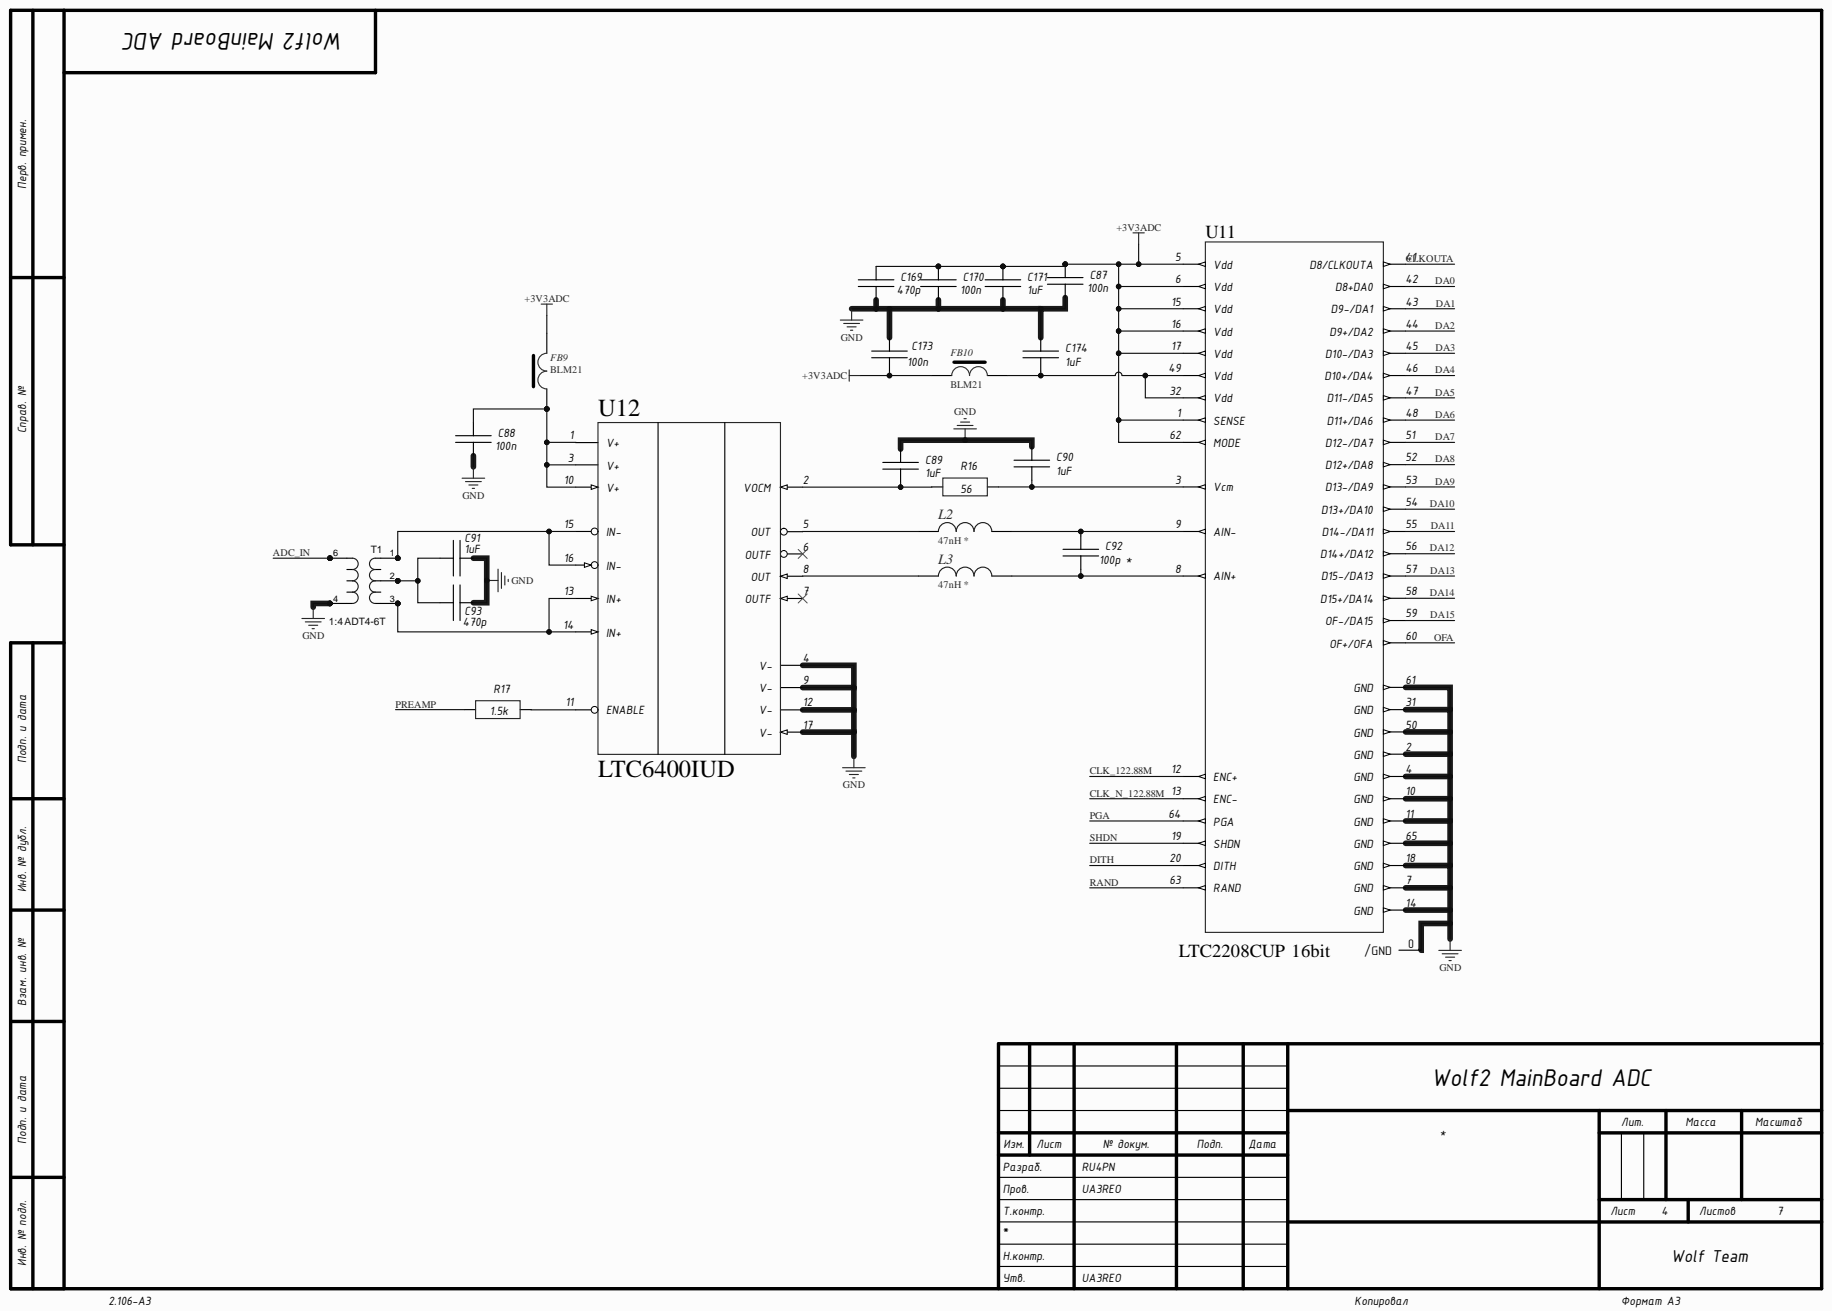
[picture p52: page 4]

Инв. № подл. Инв. № дубл. Подп. и дата Взам. инв. № Подп. и дата Перв. примен. Справ. №

Vdd 15 | 4 3

Vdd 16 | 4 4

Vdd 17 | 4 5

U12 LTC6400IU V+ V+ I N | VOCM O U T O U T F O U T O U T F V-V-V-

Wolf2 MainBoard ADC

* | Лит . | Масса | Масшта б

. Лист Р азра б . | R U 4 P N

Изм . | № докум . | Подп . | Да т а

Пров . | UA3REO

Т .контр | | | | Лист | Листов

Н .контр .

Утв .

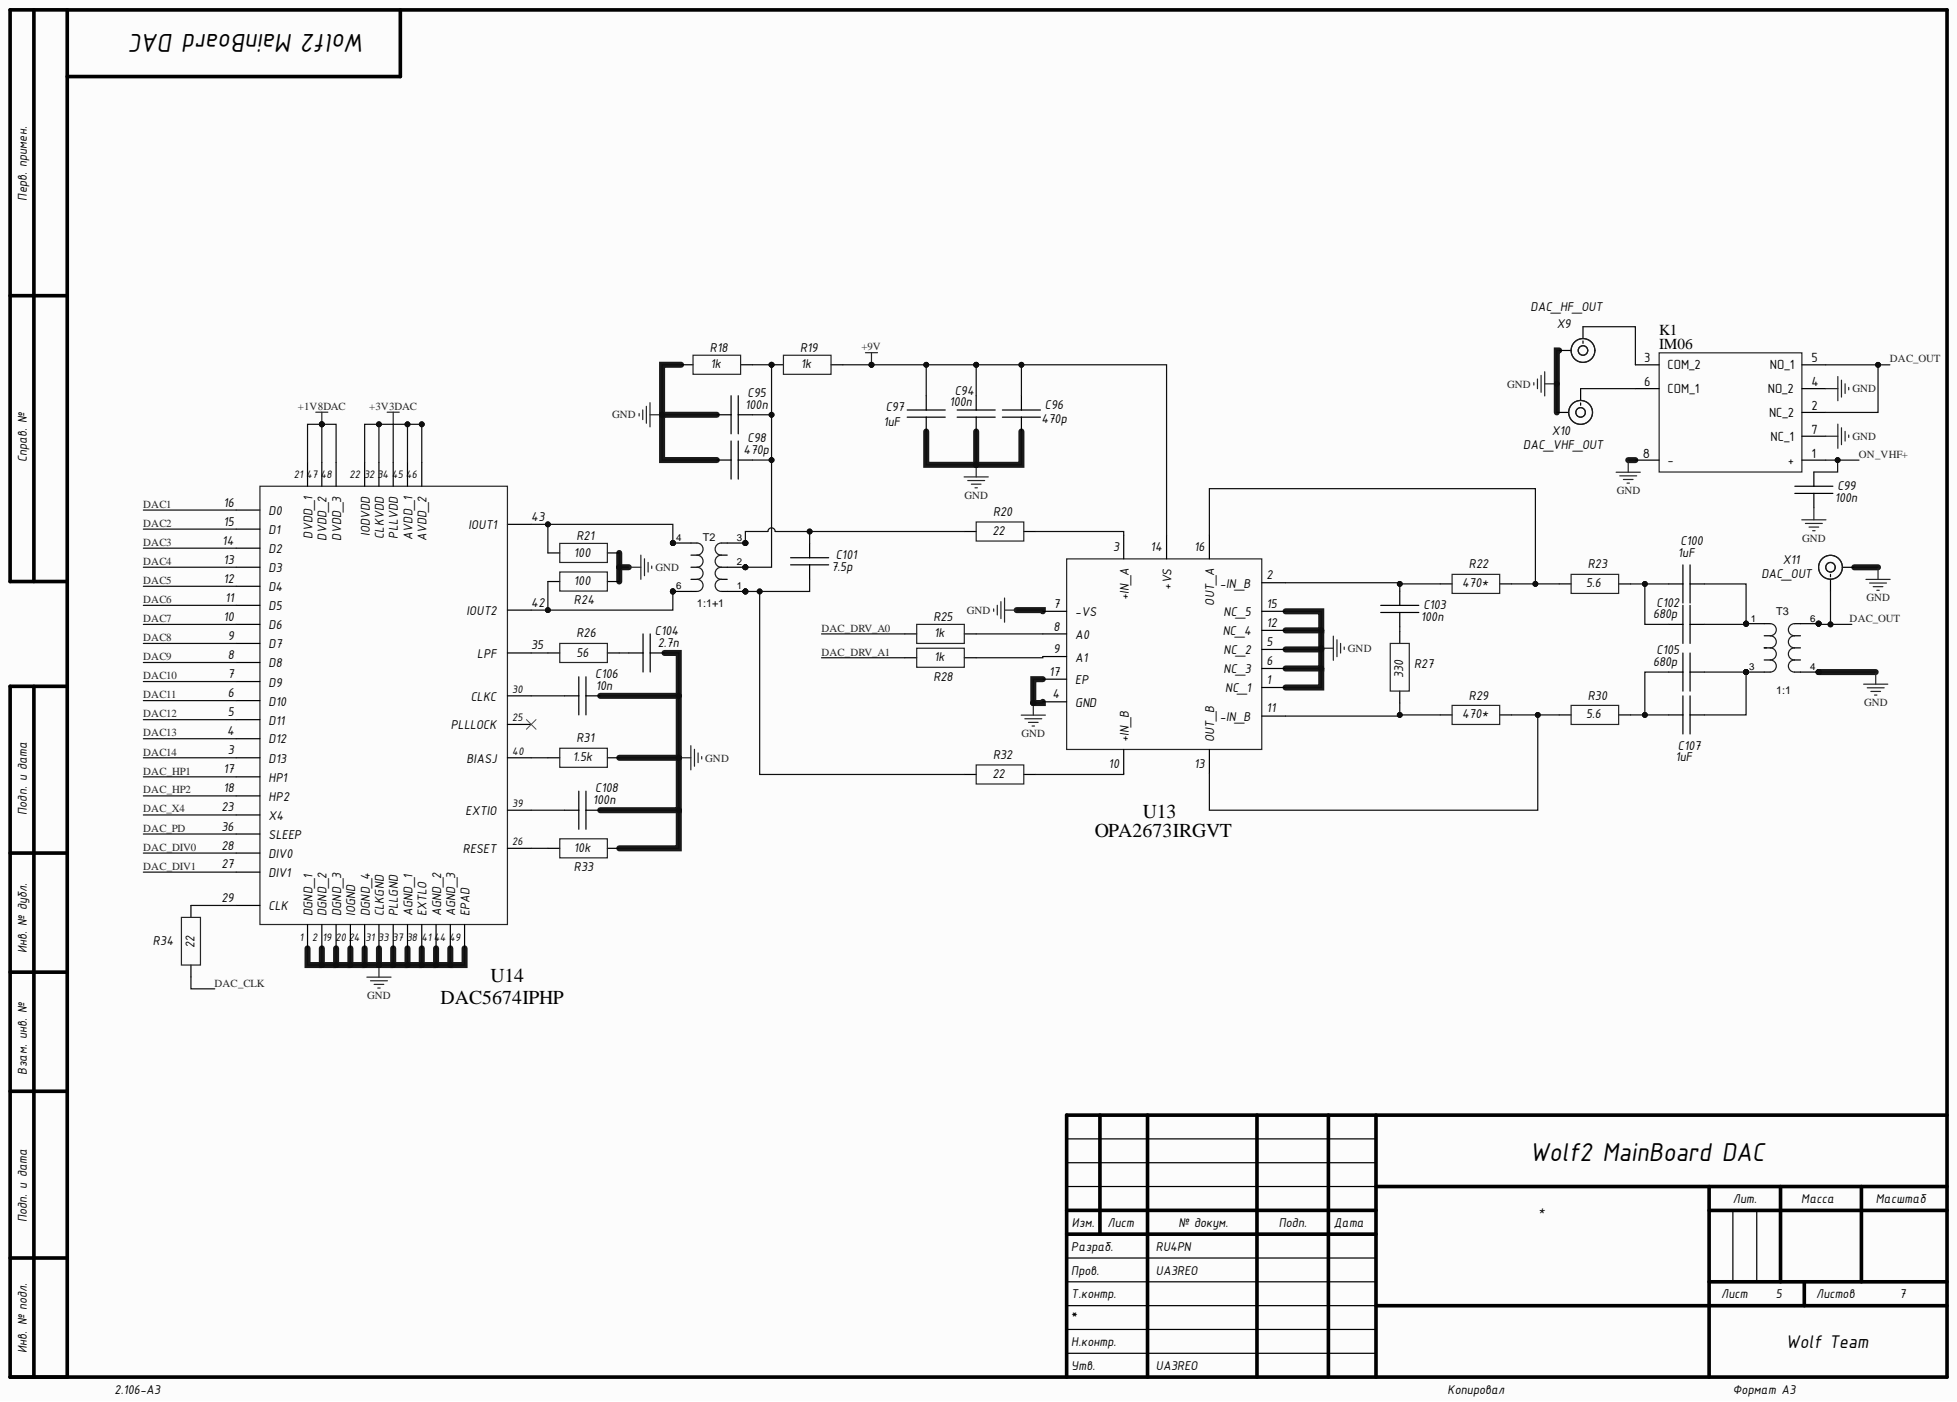
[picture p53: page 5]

Инв. № подл. Инв. № дубл. Подп. и дата Взам. инв. № Подп. и дата Перв. примен. Справ. №

Wolf2 MainBoard DAC

* | Лит . | Масса | Масшта б

. Лист Р азра б . | R U 4 P N

Изм . | № докум . | Подп . | Да т а

Пров . | UA3REO

Т .контр | | | | Лист | Листов

Н .контр .

Утв .

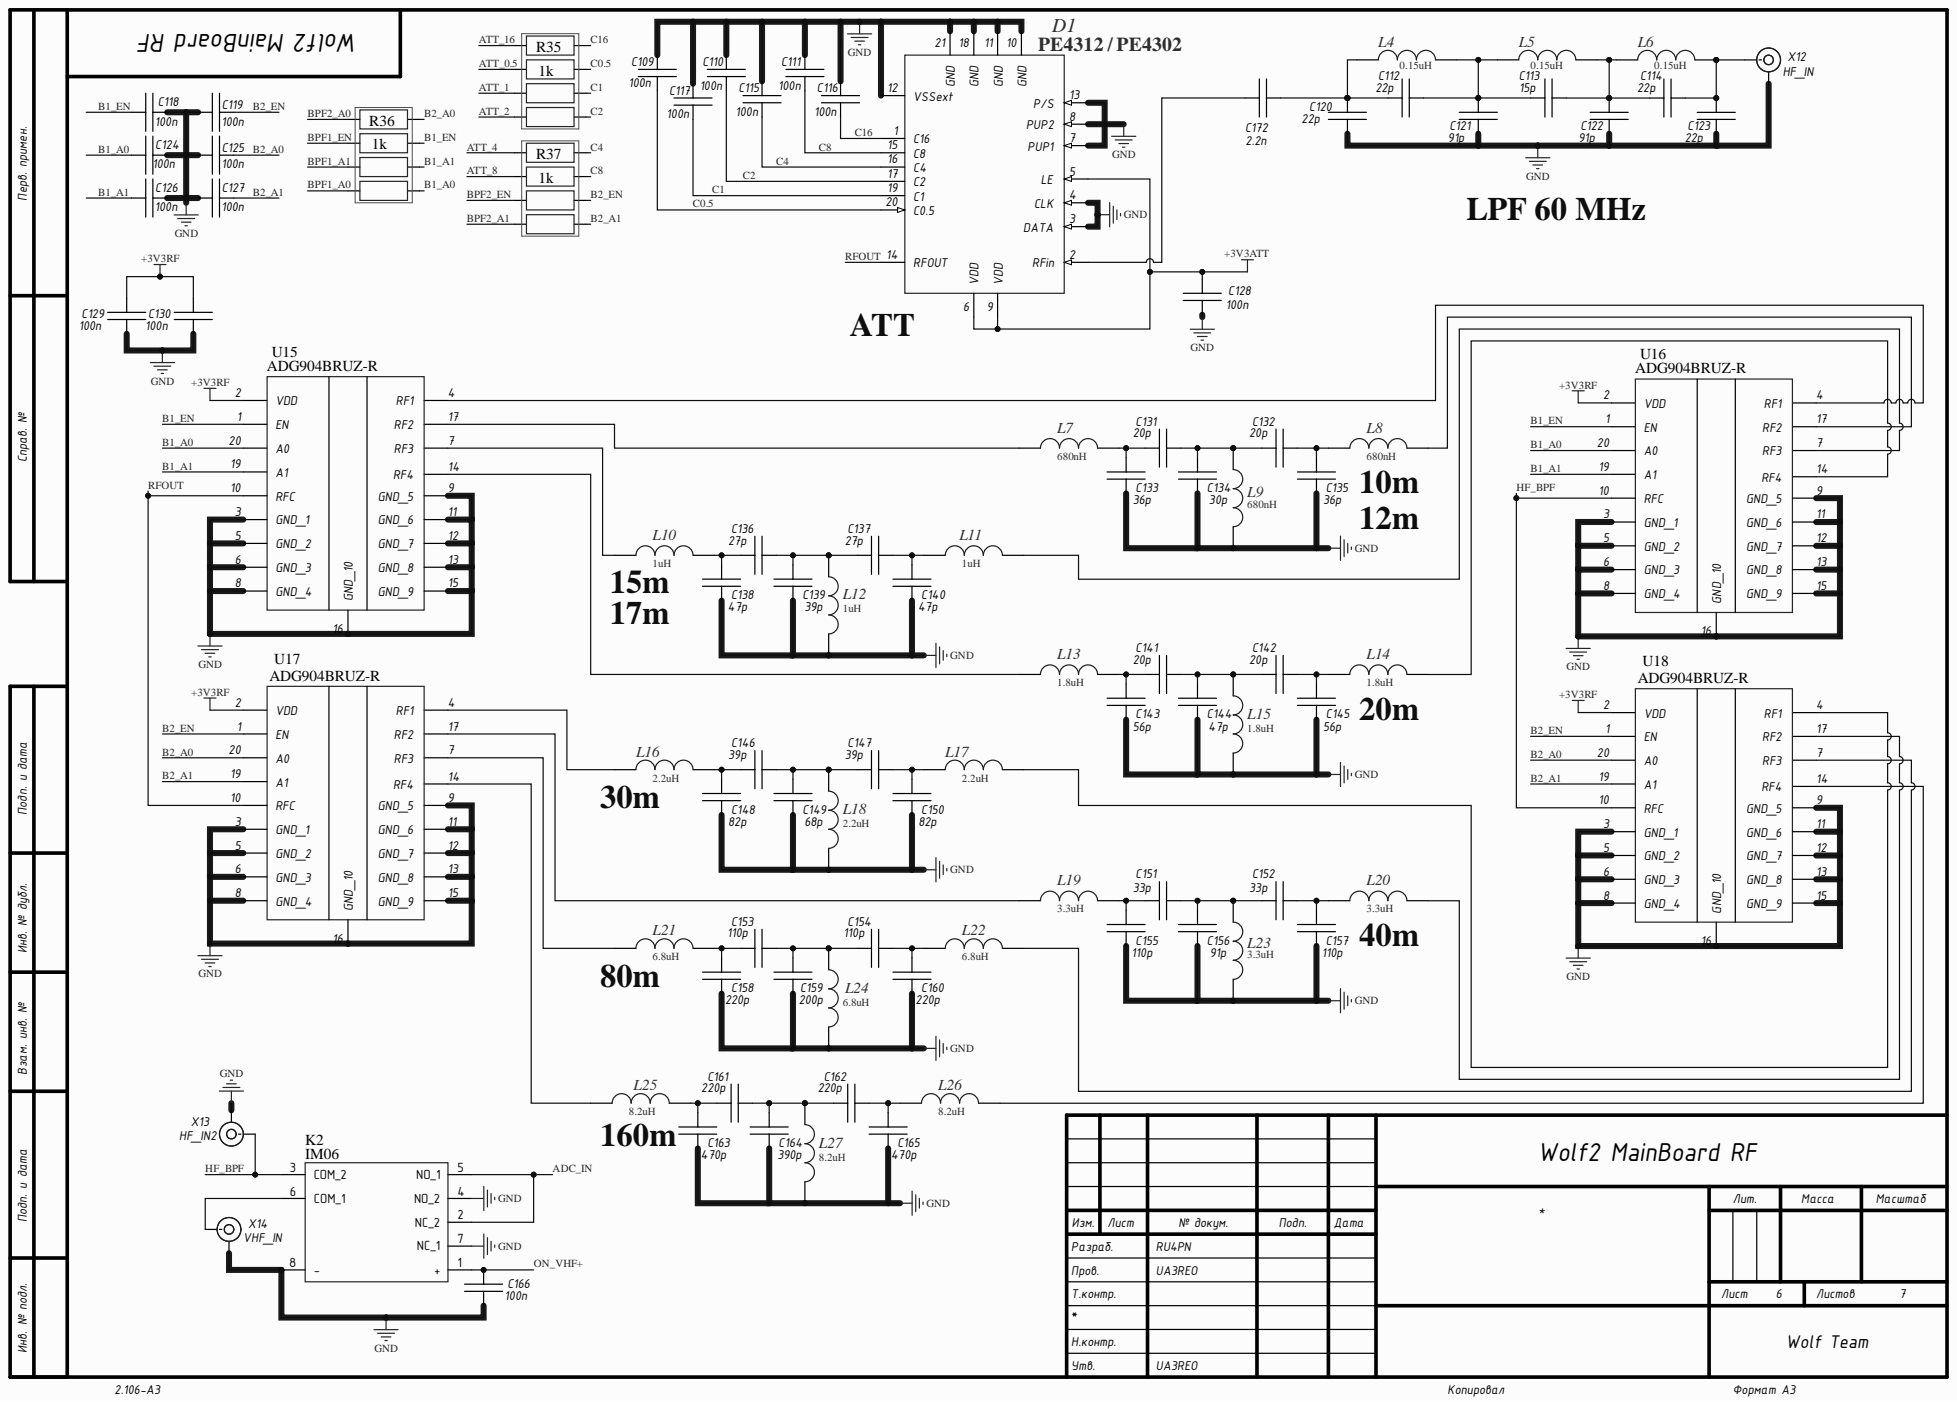
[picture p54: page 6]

Инв. № подл. Инв. № дубл. Подп. и дата Взам. инв. № Подп. и дата Перв. примен. Справ. №

Wolf2 MainBoard RF

* | Лит. | Масса | Масштаб

Изм. | Лист | № докум. | Подп. | Дата

Разраб. | | RU4PN

Пров. | | UA3REO

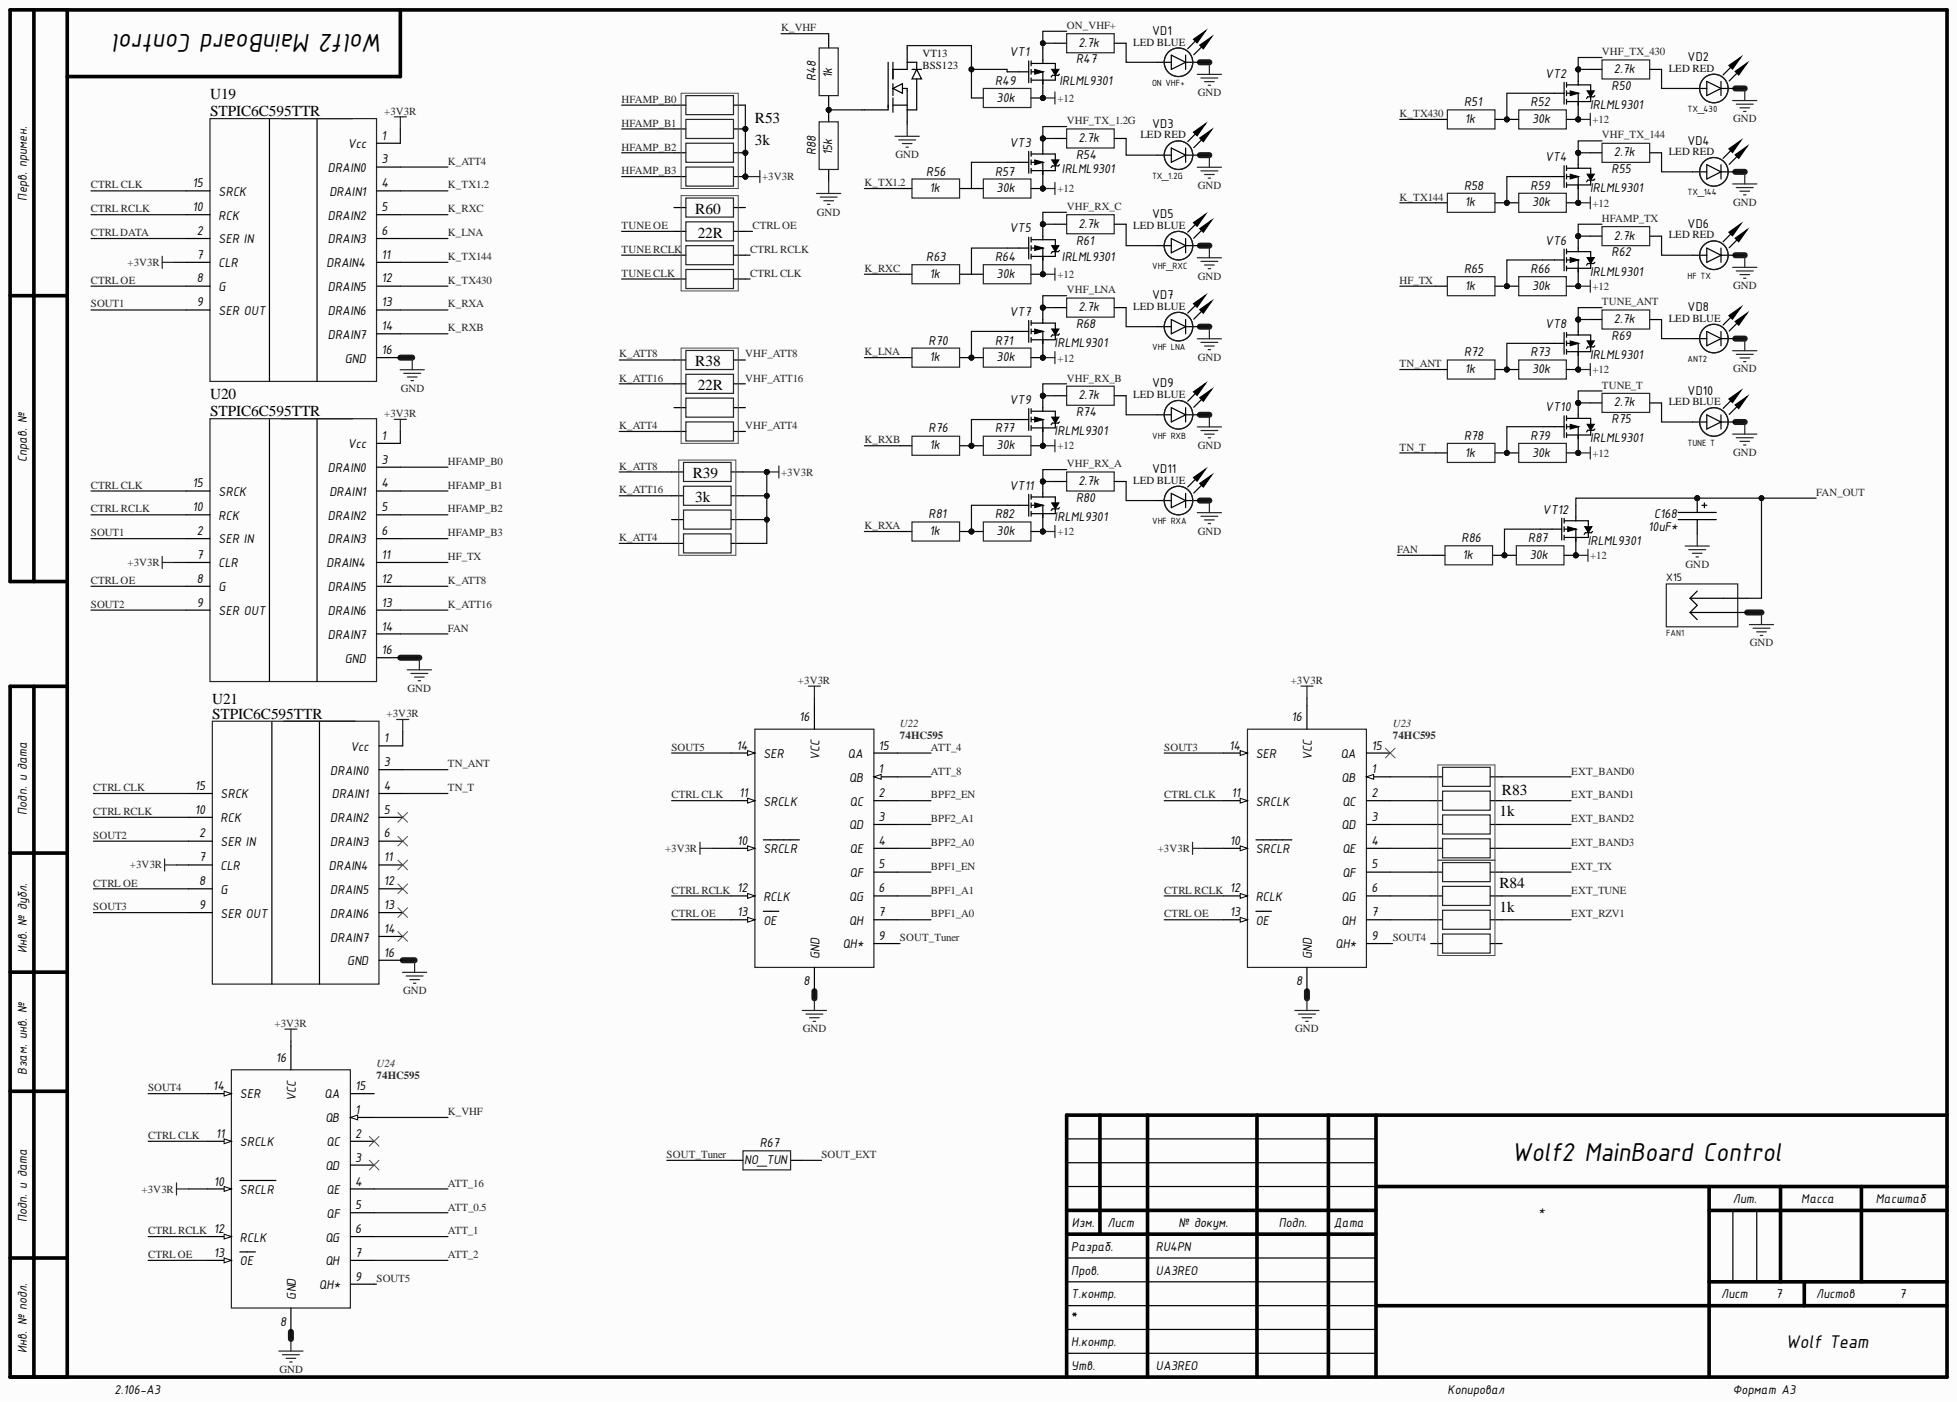
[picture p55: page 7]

30k

Инв. № подл. Инв. № дубл. Подп. и дата Взам. инв. № Подп. и дата Перв. примен. Справ. №

. Лист Р азра б . | R U 4 P N

Изм . | № докум . | Подп . | Да т а

Пров . | UA3REO

Т .контр | | | | Лист | Листов

Н .контр .

Утв .

Comment | Description | Designator | Footprint | LibRef | Quantity
100n | [NoValue], CAP_0805
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

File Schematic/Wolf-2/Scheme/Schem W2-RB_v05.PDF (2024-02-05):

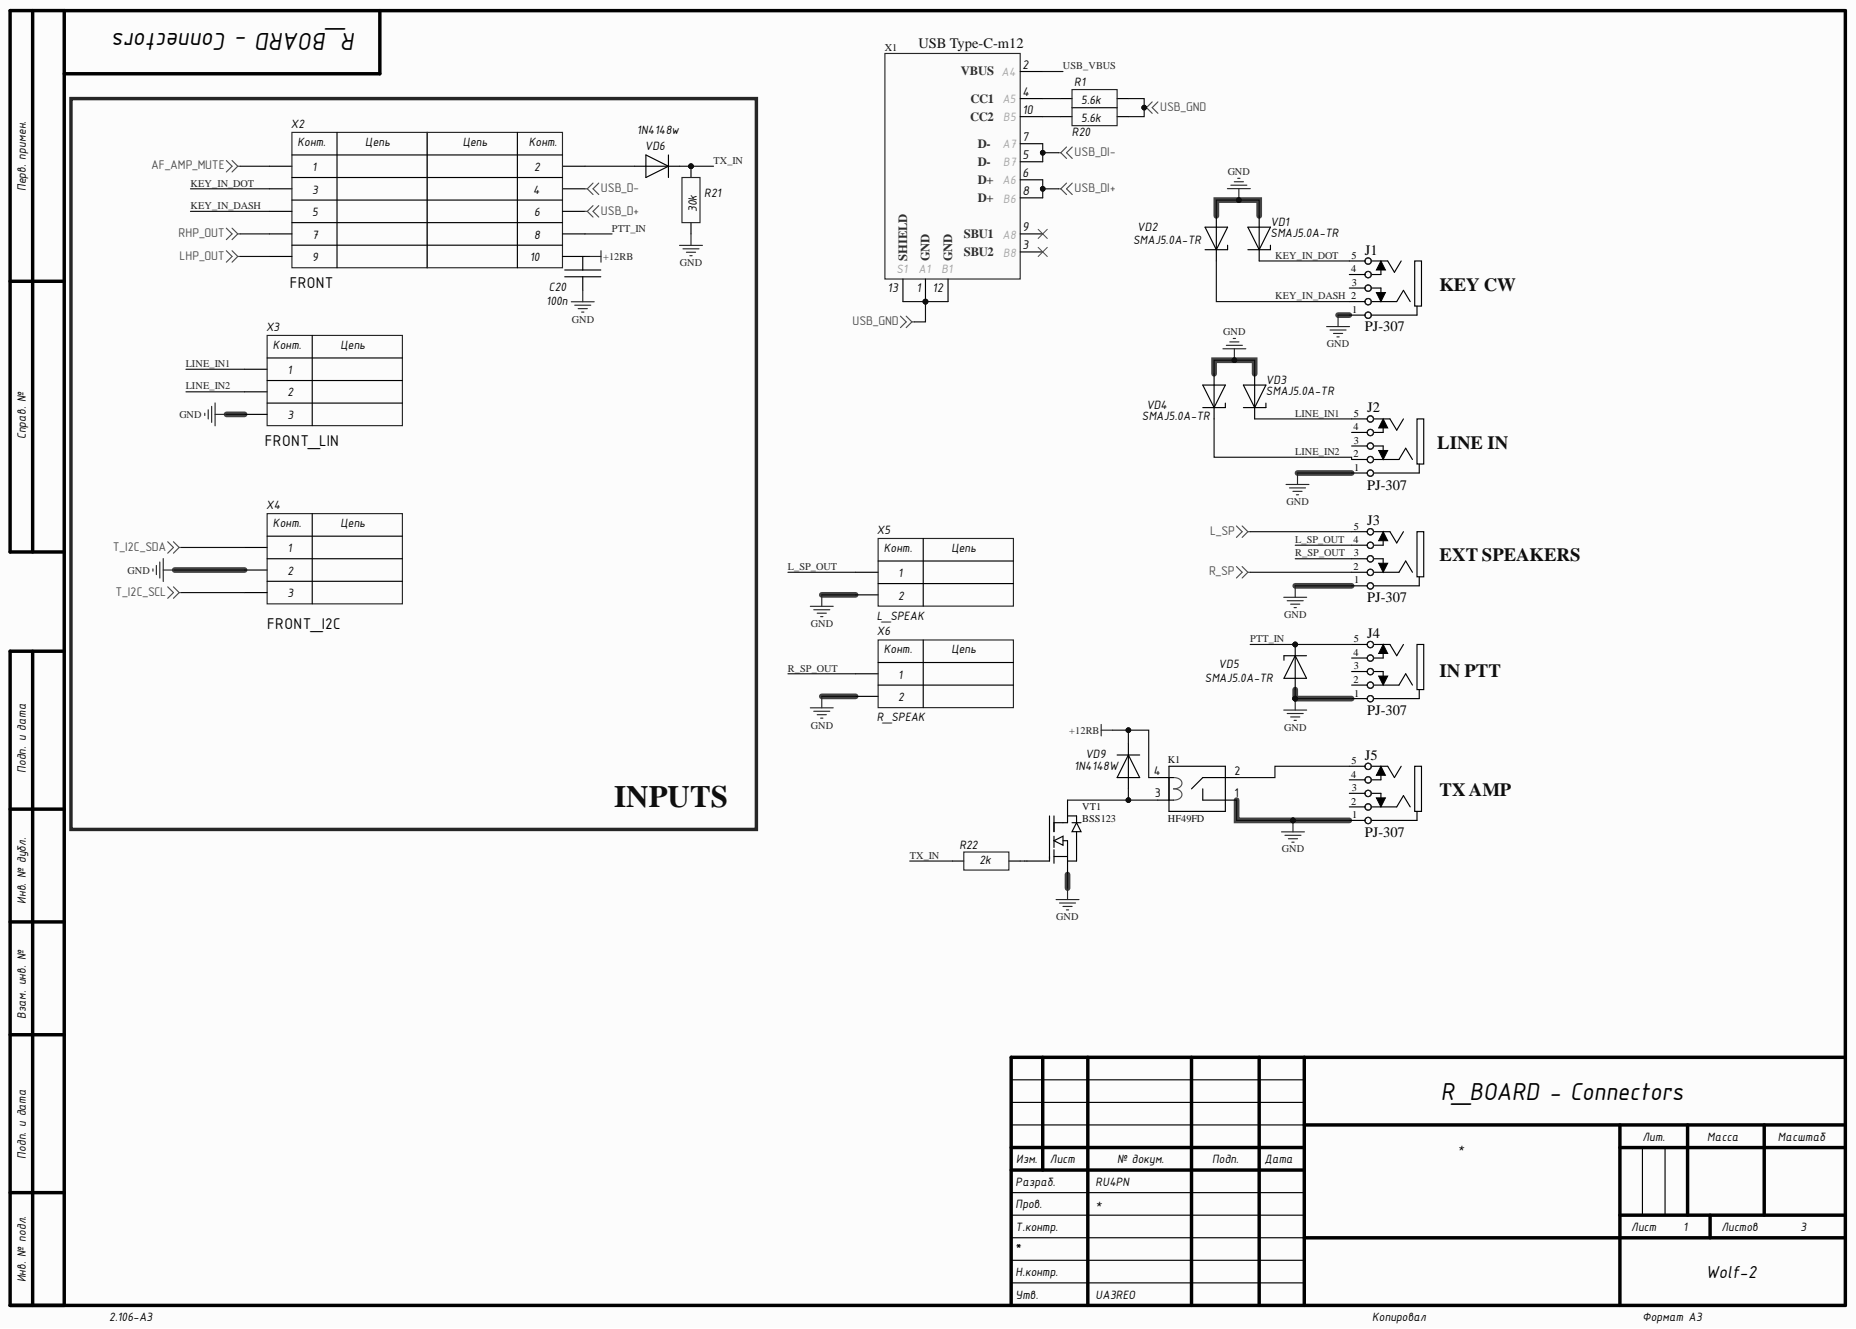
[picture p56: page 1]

Инв. № подл. Инв. № дубл. Подп. и дата Взам. инв. № Подп. и дата Перв. примен. Справ. №

Конт. | Цепь | Цепь | Конт.

Конт. | Цепь

R_BOARD - Connectors

* | Лит. | Масса | Масштаб

Изм. | Лист | № докум. | Подп. | Дата

Разраб. | | RU4PN

Пров. | | *

Т.контр. | | | | | Лист | Листов 3
* | | | | | Wolf-2

Н.контр.

Утв. | UA3REO


Инв. № подл. Инв. № дубл. Подп. и дата Взам. инв. № Подп. и дата Перв. примен. Справ. №

Конт. | Цепь

Alert 3

SCL 5

R_BOARD - Power

* | Лит. | Масса | Масштаб

Изм. | Лист | № докум. | Подп. | Дата


Инв. № подл. Инв. № дубл. Подп. и дата Взам. инв. № Подп. и дата Перв. примен. Справ. №

InR 9

AGND 8

R_BOARD - Audio

* | Лит. | Масса | Масштаб

Изм. | Лист | № докум. | Подп. | Дата

Разраб. | | RU4PN

Пров. | | *

Line # | Name | Description | Designator | Quantity | Manufacturer 1 | Manufacturer Part Number 1 | Manufacturer Lifecycle 1 | Supplier 1 | Supplier Part Number 1 | Supplier Unit Price 1 | Supplier Subtotal 1
| 1000uF 25v | | C1, C14, C19 | 3
| 100n | | C2, C3, C4, C6, C7, C8, C10, C12, C13, C20, C21, C25 | 12
| 1uF | | C5, C15, C18, C23, C24 | 5
| 10uF | | C9 | 1
| 22uF 25V | | C11 | 1
| 10uF 16v | | C16 | 1
| 100uF 16v | | C17 | 1
| 100uF 16v | | C22 | 1
| AMS1117-3.3v | LDO | D1 | 1
| INA226 | | DA1 | 1
| BLM21 | | FB1, FB2, FB3, FB4 | 4
| PJ-307 | KEY | J1 | 1
| PJ-307 | LIN | J2 | 1
| PJ-307 | OUT_SPEAKERS | J3 | 1
| PJ-307 | PTT_IN | J4 | 1
| PJ-307 | TX | J5 | 1
| HF49FD | | K1 | 1
| 5.6k | | R1, R20 | 2
| 24R | | R2, R3, R4, R5 | 4
| 1M / 0 | | R6 | 1
| NONE / 24R | | R7, R8 | 2
| 4x0.1R | | R9 | 1
| 0 | | R10, R11 | 2
| 22R | | R12, R13 | 2
| 10k | | R14, R15, R16, R17, R30, R31 | 6
| 39k | | R18 | 1
| 1k | | R19 | 1
| 30k | | R21, R24, R37, R38 | 4
| 2k | | R22 | 1
| 0R / NONE | | R23 | 1
| 2.2k | | R25, R28 | 2
| 15k | | R26, R27, R35 | 3
| 5.1k | | R29, R32 | 2
| 0/None | | R33 | 1
| NONE | | R34 | 1
| 43k | | R36 | 1
| "Connect" | 6x6mm | SB1 | 1
| ADUM4160BRWZ | Isolator USB | U1 | 1
| LD1117DT50TR | | U2 | 1
| TDA1519 | | U3 | 1
| Bluetoth AC20BP | | U4 | 1
| SMAJ5.0A-TR | | VD1, VD2, VD3, VD4, VD5, VD7 | 6
| 1N4148w | | VD6 | 1
| Blue | | VD8 | 1
| 1N4148W | | VD9 | 1
| NONE / BAT46JFILM | | VD10 | 1
| BSS123 | | VT1, VT2, VT4 | 3
| IRLML9301 | Mosfet | VT3, VT5 | 2
| USB Type-C-m12 | | X1 | 1
| FRONT | | X2 | 1
| FRONT_LIN | | X3 | 1
| FRONT_I2C | | X4 | 1
| L_SPEAK | | X5 | 1
| R_SPEAK | | X6 | 1
| OUT_13.8V | | X8 | 1


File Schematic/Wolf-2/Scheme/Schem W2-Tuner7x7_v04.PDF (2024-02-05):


Инв. № подл. Инв. № дубл. Подп. и дата Взам. инв. № Подп. и дата

W2-Tuner_Con t r o l | Лист1

Изм . | Лист | № докум . | Подп . | Да т а


Инв. № подл. Инв. № дубл. Подп. и дата Взам. инв. № Подп. и дата Перв. примен. Справ. №


Comment | Description | Designator | Footprint | LibRef | Quantity
470p | | C1, C7 | CH0805C | Capacitor | 2
1uF | | C2, C8, C15 | CH0805C | Capacitor | 3
100n | | C3, C4, C5, C6, C14, C17, C18, C19, C20, C28, C29, C30, C31, C32, C33, C34, C35, C36, C37 | CH0805C | Capacitor | 19
10p | | C21 | CH1206ATC | Capacitor | 1
22p | | C22 | CH1206ATC | Capacitor | 1
47p | | C23 | CH1206ATC | Capacitor | 1
100p | | C24 | CH1206ATC | Capacitor | 1
220p | | C25 | CH1206ATC | Capacitor | 1
470p | | C26 | CH1206ATC | Capacitor | 1
1000p | | C27 | CH1206ATC | Capacitor | 1
AMS1117-5v | LDO | D1 | SOT223 | NCP1117LPST50T3G | 1
BLM21 | | FB1, FB2, FB3 | CH0805L | FB-1 | 3
HK4100F | | K1, K2, K3, K5, K13, K14, K15 | NK4100F | NK4100F | 7
G6S-2-DC12 | | K4, K16 | G6S-2-DC12 | G6S-2-12VDC | 2
HF49FD | | K6, K7, K8, K9, K10, K11, K12 | HF49FD | HF49FD 012-1H12 | 7
0.05uH | | L1 | DR1 | Inductor ring | 1
0.1uH | | L2 | DR1 | Inductor ring | 1
0.22uH | | L3 | DR1 | Inductor ring | 1
0.45uH | | L4 | T68-0 | Inductor ring | 1
1uH | | L5 | T68-0 | Inductor ring | 1
2.2uH | | L6 | T68-0 | Inductor ring | 1
4.4uH | | L7 | T68-0 | Inductor ring | 1
4.7K | | R1, R2, R3, R4, R6, R8, R10, R12, R16, R18, R21, R23, R25, R29, R31, R35 | CH0805R | Resistor | 16
30k | | R5, R7, R9, R11, R14, R17, R19, R22, R24, R27, R30, R32, R34, R36 | CH0805R | Resistor | 14
1k | | R13, R20, R26, R33 | CAT16 | CAT10-0804 | 4
STPIC6C595TTR | | U1, U2 | 16-TSOP | STPIC6C595TTR | 2
LED BLUE | | VD1, VD2, VD3, VD4, VD5, VD6, VD7, VD8, VD9, VD10, VD11, VD12, VD13, VD14, VD15, VD16 | LED: 0805B | LED_single | 16
1N4148W | | VD17, VD18, VD19, VD20, VD21, VD22, VD23, VD24, VD25, VD26, VD27, VD28, VD29, VD30, VD31, VD32 | SOD123 | Diod | 16
IRLML9301 | Mosfet | VT1, VT2, VT3, VT4, VT5, VT6, VT7, VT8, VT9, VT10, VT11, VT12, VT13, VT14 | SOT23_132 | IRLML9301 | 14
MainBoard | 2*5 Pin | X1 | CON: BH-10 | IDC10 | 1
IN_TUNER | RF | X2 | CON: SMA | SMA | 1
ANT1 | RF | X3 | CON: SMA | SMA | 1
ANT2 | RF | X4 | CON: SMA | SMA | 1

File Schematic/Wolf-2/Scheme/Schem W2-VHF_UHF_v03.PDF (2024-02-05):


C9 100n | ATT4 | ATT8 | ATT16

Инв. № подл. Инв. № дубл. Подп. и дата Взам. инв. № Подп. и дата

Wolf-2 VHF/UHF Connector


Конт. | Цепь

Инв. № подл. Инв. № дубл. Подп. и дата Взам. инв. № Подп. и дата


Конт. | Цепь

OUT 4 GND 5 RA1 VHF Module

Инв. № подл. Инв. № дубл. Подп. и дата Взам. инв. № Подп. и дата

Comment | Description | Designator | Footprint | LibRef | Quantity
10n | | C1, C8, C11, C12, C25, C39, C41, C43, C48, C61, C71, C80, C86, C104 | CH0805C | Capacitor | 14
100n | | C2, C3, C4, C5, C7, C9, C10, C14, C20, C21, C37, C38, C40, C42, C46, C47, C62, C64, C65, C67, C70, C72, C75, C76, C100, C105, C106, C109, C111 | CH0805C | Capacitor | 29
1uF | | C6, C44 | CH0805C | Capacitor | 2
2.2uF | | C13, C55 | CH0805C | Capacitor | 2
100p | | C15, C22, C28, C36, C49, C66, C79, C110 | CH0805C | Capacitor | 8
1n | | C16, C54 | CH0805C | Capacitor | 2
10uF | | C17, C73 | CH0805C | Capacitor | 2
220p | | C18, C56, C57, C58, C59 | CH0805C | Capacitor | 5
4.7uF | | C19, C45, C74 | CH0805C | Capacitor | 3
330p | | C23, C24 | CH0805C | Capacitor | 2
110p | | C26, C85 | CH0805C | Capacitor | 2
4.7n | | C27, C50, C68, C81, C107 | CH0805C | Capacitor | 5
15p | | C29, C30, C90, C91 | CH0805C | Capacitor | 4
56p | | C31, C87 | CH0805C | Capacitor | 2
39p | | C32, C33 | CH0805C | Capacitor | 2
68p | | C34, C88 | CH0805C | Capacitor | 2
3p | | C35, C53, C89 | CH0805C | Capacitor | 3
18p | | C51 | CH0805C | Capacitor | 1
27p | | C52 | CH0805C | Capacitor | 1
270pF | | C60 | CH1206ATC | Capacitor | 1
10uF | | C63, C99 | CH1206C | Capacitor | 2
0,47uF 16v | | C69, C108 | TANTAL_B | TantalCap | 2
20p | | C77, C78, C93, C94 | CH0805C | Capacitor | 4
82p | | C82, C83, C84, C101, C102, C103 | CH0805C | Capacitor | 6
470pF | | C92 | CH1206ATC | Capacitor | 1
30pF | | C95 | CH1206ATC | Capacitor | 1
36pF | | C96 | CH1206ATC | Capacitor | 1
47pF | | C97 | CH1206ATC | Capacitor | 1
22pF | | C98 | CH1206ATC | Capacitor | 1
PE4312 / PE4302 | | D1 | 20-QFN (4x4) | PE4312-№1 | 1
BAV99 | | D2, D3, D4 | SOT23_132 | BAV99 | 3
SN74LS145DR | | DA1 | 16-SOIC | SN74LS145N | 1
BLM21 | | FB1, FB2 | CH0805L | FB-1 | 2
IM06 | | K1, K2, K3, K5, K6, K7, K9, K10, K11 | IM06 | IM06-V1 | 9
IM06-12v | | K4 | IM06 | IM06-V1 | 1
G6S-2-DC12 | | K8, K12 | G6S-2-DC12 | G6S-2-12VDC | 2
150nH | | L1 | CH1210L | Inductor | 1
1uH | | L2, L11 | CH1210L | Inductor | 2
18 nH | | L3 | CH1210L | Inductor | 1
22nH | | L4, L18 | CH1206L | Inductor | 2
180nH | | L5, L6, L7, L9, L19, L20 | CH1206L | Inductor | 6
82nH | | L8 | CH1206L | Inductor | 1
12 nH | | L10 | CH1210L | Inductor | 1
82nH | | L12 | CH1210L | Inductor | 1
12nH | | L13, L15, L24, L26 | CH1206L | Inductor | 4
10nH | | L14, L25 | CH1206L | Inductor | 2
22 nH | | L16 | CH1210L | Inductor | 1
10uH | | L17 | CH1210L | Inductor | 1
0.047uH | | L21, L22, L23 | T50-6 | Inductor ring | 3
LP3878MR-ADJ | LP3878-ADJ HSOP-8 | LP1, LP2, LP3 | SOP-8 gnd | LP3878-ADJ | 3
PAW-145M2 | PAW-A022-145M2 | PAW-1 | PAW-145M2 | PAW-145M2 | 1
10k | | R1, R12, R19, R22, R37, R53 | CH0805R | Resistor | 6
4.7k | | R2, R13, R18, R23, R26, R30, R38, R48, R49, R54, R69, R70 | CH0805R | Resistor | 12
620 | | R3, R39, R50, R55, R73 | CH0805R | Resistor | 5
33 | | R4 | CH0805R | Resistor | 1
18 | | R5, R56 | CH2010R | Resistor | 2
180 | | R6, R7 | CH0805R | Resistor | 2
10K | | R8, R41, R57 | CH2010R | Resistor | 3
18 | | R9, R42, R58 | CH0805R | Resistor | 3
300 | | R10, R11, R43, R44, R59, R60 | CH0805R | Resistor | 6
3.3K | | R14, R15, R29 | CH0805R | Resistor | 3
3K | | R16, R20, R24, R27, R31 | CH0805R | Resistor | 5
30k | | R17, R21, R25, R28, R32 | CH0805R | Resistor | 5
0 | | R33, R34, R35, R36, R61, R62, R63, R64, R65 | CH1206R | Resistor | 9
12 | | R40 | CH2010R | Resistor | 1
51R | | R45, R66 | CH1206R | Resistor | 2
5.1k | | R46, R47, R67, R68 | CH0805R | Resistor | 4
100 | | R51, R71 | CH0805R | Resistor | 2
10k | | R52, R72 | RES: 3296W | ADJ resistor | 2
VHF Module | RA80H | RA1 | RA80H | RA80H | 1
VHF RA60H1317 | RA80H | RA2 | RA80H | RA80H | 1
SWR | SWR_VHF | SWR1, SWR2 | SWR_VHF | SWR_VHF | 2
TAU692 433MHz | TAU692 433MHz | TAU1, TAU2 | TAU-692 433 MHz | TAU692 433MHz | 2
1117-5.0 | LT1117CST-5.0 | U1, U3 | LT1117CST-3.3 | LT1117CST-3.3 | 2
1117-ADJ | LT1117CST-ADJ | U2, U4 | LT1117CST-3.3 | LT1117CST-3.3 | 2
SS14 | | VD1, VD2, VD3, VD4, VD5, VD6, VD7 | SMA | Diod Schottky | 7
LED BLUE | | VD8, VD9, VD10, VD11, VD12 | LED: 0805B | LED_single | 5
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

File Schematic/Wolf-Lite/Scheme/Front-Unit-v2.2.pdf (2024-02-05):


Инв. № подл. Инв. № дубл. Подп. и дата Взам. инв. № Подп. и дата

Конт. | Цепь

Comment | Description | Designator | Footprint | LibRef | Quantity
0.1 | | C1, C2, C3, C4, C7, C8, C9, C10, C11 | CH0805C | Capacitor | 9
10uF 10V | | C5, C6 | TANTAL_B | TantalCap | 2
AMS117-5 | | DA1 | SOT223 | AMS117 | 1
3V | | G1 | BAT: CH224-2032 | POWER_BAT | 1
1K | | R1, R7, R15, R19 | CH0805R | Resistor | 4
4.7K | | R2, R8, R9, R10, R11, R12, R14 | CH0805R | Resistor | 7
4K7 | | R3, R4, R5 | CH0805R | Resistor | 3
2K | | R6, R13, R16 | CH0805R | Resistor | 3
1R | | R17 | CH0805R | Resistor | 1
10K | | R18 | CH0805R | Resistor | 1
"Кнопка" | 6x6mm | SB1, SB2, SB3, SB4, SB5, SB6, SB7, SB9 | BUT: 5X5 | Tactile switches | 8
"Power" | 6x6mm | SB8 | BUT: 5X5 | Tactile switches | 1
PEC12 | Encoder | SW1 | Valkoder-m2 | PEC12 | 1
MCP3008-I/SL | | U1 | 16-SOIC | MCP3008-I/SL | 1
IRFR5103 | | VT1 | SOT23_132 | N-KANAL | 1
IPS 3.5 | | X1 | FPC-40P 0.5mm | LCD-IPS 3.5 | 1
FPC 0.5 | | X2 | CON: PBD2x20 | FPC-45-0.5 | 1
Valcoder | | X3 | CON: PLS-5 | 5-Connector | 1
IPS 3.5 | | X4 | IPS 3.5 ILI9481 | LCD-IPS 3.5 | 1

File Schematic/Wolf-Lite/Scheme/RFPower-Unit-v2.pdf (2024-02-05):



Инв. № подл. Инв. № дубл. Подп. и дата Взам. инв. № Подп. и дата Перв. примен. Справ. №

1 PLD1

Comment | Description | Designator | Footprint | LibRef | Quantity
0.1 | | C1, C2, C3, C4, C5, C31, C32, C33, C34, C40, C41, C42, C51, C52, C54, C55, C59, C60, C63, C64, C65, C70, C71, C72, C73, C78, C80, C81, C82, C83, C84 | CH0805C | C_smd, Capacitor | 31
1.5nF | | C6, C26 | CH1206C | C_smd | 2
1n | | C7, C18, C27 | CH1206C | C_smd | 3
470p | | C8, C28 | CH1206C | C_smd | 2
157p | | C9, C29 | CH1206C | C_smd | 2
100p | | C10, C12, C22, C30, C77, C79 | CH1206C | C_smd, Capacitor | 6
220p | | C11, C21 | CH1206C | C_smd | 2
47p | | C13, C23 | CH1206C | C_smd | 2
33p | | C14, C24 | CH1206C | C_smd | 2
22p | | C15, C25 | CH1206C | C_smd | 2
3nF | | C16 | CH1206C | C_smd | 1
2nF | | C17 | CH1206C | C_smd | 1
330p | | C19 | CH1206C | C_smd | 1
200p | | C20 | CH1206C | C_smd | 1
22x16 | | C53, C56 | TANTAL_B | AlumCap | 2
10n | | C57, C58, C61, C62, C66, C67 | CH0805C | Capacitor | 6
10n | | C68, C69 | CH1206C | Capacitor | 2
0.1 | | C74, C75 | CH1206C | Capacitor | 2
220x35 | | C76 | D8C3.2H12 | AlumCap | 1
BAT54A | | D1 | SOT23_132 | BAT54 | 1
10uH | | DR1 | DR2 | Inductor-1 | 1
JP1 | | JP1 | CON: PLS-2 | JP2 | 1
JP2 | | JP2 | CON: PLS-2 | JP2 | 1
| | K1, K2, K3, K4, K5, K6, K7, K8, K9, K10, K11, K12, K13 | G5V-1 | G5V-1 | 13
1,9 uH | | L1, L7 | T50-2 | L | 2
1uH | | L2, L8 | T50-6 | L | 2
0,6 uH | | L3, L9 | T50-6 | L | 2
0,26 uH | | L4, L10 | T50-6 | L | 2
3.9 uH | | L5 | T50-2 | L | 1
3,9 uH | | L6 | T50-2 | L | 1
100 | | R1, R2, R6, R8 | CH1206R | Resistor | 4
0 | | R3, R7 | CH0805R | Resistor | 2
510 | | R4, R5 | CH0805R | Resistor | 2
300 | | R9, R11 | CH0805R | Resistor | 2
18 | | R10 | CH0805R | Resistor | 1
10K | | R12, R13 | CH0805R | Resistor | 2
1K | | R14, R29, R30, R31 | CH0805R | Resistor | 4
330 | | R15, R16, R18, R19, R20, R24 | CH0805R | Resistor | 6
150* | | R17 | CH0805R | Resistor | 1
10 | | R21 | CH0805R | Resistor | 1
33 | | R22, R23 | CH0805R | Resistor | 2
| | R25, R28 | RES: 3296W | ADJ resistor | 2
2,2K | | R26, R27 | CH1206R | Resistor | 2
2.2K | | R32, R33 | CH0805R | Resistor | 2
BN-43-302 | | T1 | FT-37-43 | BN-43-302 | 1
BN43-302 | | TR1 | TANDEM | BN43-302 | 1
TR-kolco | | TR2 | TR-Kolco | TR-kolco | 1
TR-UM | | TR3 | TR-UM | TR-UM | 1
LM7809 | | U3 | DPAK | Kren_5 | 1
BAT46JFILM | | VD1, VD2 | D9B | Diod | 2
1N4148 | | VD3 | SOD123 | Diod | 1
IRFR6402 | | VT1 | SOT23_132 | P-KANAL | 1
| | VT2 | SOT23_123 | N-P-N | 1
BFG591 | | VT3, VT4 | BFG | N-P-N | 2
RD16HHF1 | | VT5, VT6 | rd16 | N | 2
PLD10 | | X1 | CON: PLD-10 | 10-Connector | 1
TX-IN | RF | X1 | CON: SMA | SMA | 1
TX/RX | RF | X2 | Connect | SMA | 1
| | X3 | CON: CWF-3 | 3-Connector | 1
| | X5 | CON: 300-02P-5.0 | 2-Connector | 1

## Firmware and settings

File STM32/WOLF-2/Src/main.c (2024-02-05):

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
/* Includes ------------------------------------------------------------------*/
#include "main.h"
#include "fatfs.h"

/* USER CODE BEGIN Includes */
#include "INA226_PWR_monitor.h" //Tisho
#include "audio_processor.h"
#include "bootloader.h"
#include "codec.h"
#include "fft.h"
#include "fpga.h"
#include "front_unit.h"
#include "functions.h"
#include "images.h"
#include "jpeg_utils.h"
#include "lcd.h"
#include "lcd_driver.h"
#include "profiler.h"
#include "rf_unit.h"
#include "sd.h"
#include "settings.h"
#include "trx_manager.h"
#include "usb_device.h"
#include "usbd_cat_if.h"
#include "usbd_debug_if.h"
#include "wifi.h"
/* USER CODE END Includes */

ADC_HandleTypeDef hadc1;
ADC_HandleTypeDef hadc3;

CRC_HandleTypeDef hcrc;

DMA2D_HandleTypeDef hdma2d;

I2S_HandleTypeDef hi2s3;

IWDG_HandleTypeDef hiwdg1;

JPEG_HandleTypeDef hjpeg;

RTC_HandleTypeDef hrtc;

SPI_HandleTypeDef hspi2;
DMA_HandleTypeDef hdma_spi2_rx;
DMA_HandleTypeDef hdma_spi2_tx;

TIM_HandleTypeDef htim2;
TIM_HandleTypeDef htim3;
TIM_HandleTypeDef htim4;
TIM_HandleTypeDef htim5;
TIM_HandleTypeDef htim6;
TIM_HandleTypeDef htim7;
TIM_HandleTypeDef htim15;
TIM_HandleTypeDef htim16;
TIM_HandleTypeDef htim17;

UART_HandleTypeDef huart6;
DMA_HandleTypeDef hdma_usart6_rx;

PCD_HandleTypeDef hpcd_USB_OTG_FS;

DMA_HandleTypeDef hdma_memtomem_dma2_stream5;
MDMA_HandleTypeDef hmdma_mdma_channel0_sw_0;
MDMA_HandleTypeDef hmdma_mdma_channel1_sw_0;
MDMA_HandleTypeDef hmdma_mdma_channel2_sw_0;
MDMA_HandleTypeDef hmdma_mdma_channel3_sw_0;
MDMA_HandleTypeDef hmdma_mdma_channel4_sw_0;
SRAM_HandleTypeDef hsram1;

/* USER CODE BEGIN PV */
DMA_HandleTypeDef hdma_spi3_rx;
DMA_HandleTypeDef hdma_spi3_tx;
static char greetings_buff[32] = {0};
/* USER CODE END PV */

void SystemClock_Config(void);
void PeriphCommonClock_Config(void);
static void MPU_Config(void);
static void MX_GPIO_Init(void);
static void MX_DMA_Init(void);
static void MX_MDMA_Init(void);
static void MX_ADC1_Init(void);
static void MX_FMC_Init(void);
static void MX_I2S3_Init(void);
static void MX_RTC_Init(void);
static void MX_SPI2_Init(void);
static void MX_TIM3_Init(void);
static void MX_TIM4_Init(void);
static void MX_TIM5_Init(void);
static void MX_TIM6_Init(void);
static void MX_TIM7_Init(void);
static void MX_USART6_UART_Init(void);
static void MX_USB_OTG_FS_PCD_Init(void);
static void MX_ADC3_Init(void);
static void MX_TIM15_Init(void);
static void MX_TIM16_Init(void);
static void MX_TIM17_Init(void);
static void MX_DMA2D_Init(void);
static void MX_TIM2_Init(void);
static void MX_CRC_Init(void);
static void MX_IWDG1_Init(void);
static void MX_JPEG_Init(void);
/**
 * @brief  The application entry point.
 * @retval int
 */
int main(void) {
	/* USER CODE BEGIN 1 */
	MX_GPIO_Init(); // pwr hold
	/* USER CODE END 1 */

	/* MPU Configuration--------------------------------------------------------*/
	MPU_Config();
	/* Enable the CPU Cache */

	/* Enable I-Cache---------------------------------------------------------*/
	SCB_EnableICache();

	/* Enable D-Cache---------------------------------------------------------*/
	SCB_EnableDCache();

	/* MCU Configuration--------------------------------------------------------*/

	/* Reset of all peripherals, Initializes the Flash interface and the Systick. */
	HAL_Init();

	/* Configure the system clock */
	SystemClock_Config();

	/* Configure the peripherals common clocks */
	PeriphCommonClock_Config();

	/* USER CODE BEGIN SysInit */
	// System stabilization
	uint8_t tryes = 0;
	while (tryes < 3 && (!__HAL_PWR_GET_FLAG(PWR_FLAG_VOSRDY) || (RCC->CR & RCC_CR_HSERDY) == 0 || (RCC->BDCR & RCC_BDCR_LSERDY) == 0 || (RCC->CR & RCC_CR_PLL1RDY) == 0 ||
	                     (RCC->CFGR & RCC_CFGR_SWS) != RCC_CFGR_SWS_PLL1)) {
		SystemClock_Config();
		tryes++;
	}
	if (tryes == 3) {
		MX_FMC_Init();
		LCD_Init();
		LCD_showError("STM32 crystals error", false);
	}

// Stack protection
#define stack_addr 0x20000000
	MPU_Region_InitTypeDef MPU_InitStruct = {0};
	MPU_InitStruct.Enable = MPU_REGION_ENABLE;
	MPU_InitStruct.Number = MPU_REGION_NUMBER4;
	MPU_InitStruct.BaseAddress = stack_addr + 256; // growning down
	MPU_InitStruct.Size = MPU_REGION_SIZE_32B;
	MPU_InitStruct.SubRegionDisable = 0x0;
	MPU_InitStruct.TypeExtField = MPU_TEX_LEVEL0;
	MPU_InitStruct.AccessPermission = MPU_REGION_NO_ACCESS;
	MPU_InitStruct.DisableExec = MPU_INSTRUCTION_ACCESS_ENABLE;
	MPU_InitStruct.IsShareable = MPU_ACCESS_NOT_SHAREABLE;
	MPU_InitStruct.IsCacheable = MPU_ACCESS_NOT_CACHEABLE;
	MPU_InitStruct.IsBufferable = MPU_ACCESS_NOT_BUFFERABLE;
	HAL_MPU_ConfigRegion(&MPU_InitStruct);

	/* USER CODE END SysInit */

	/* Initialize all configured peripherals */
	MX_GPIO_Init();
	MX_DMA_Init();
	MX_MDMA_Init();
	MX_ADC1_Init();
	MX_FMC_Init();
	MX_I2S3_Init();
	MX_RTC_Init();
	MX_SPI2_Init();
	MX_TIM3_Init();
	MX_TIM4_Init();
	MX_TIM5_Init();
	MX_TIM6_Init();
	MX_TIM7_Init();
	MX_USART6_UART_Init();
	MX_ADC3_Init();
	MX_TIM15_Init();
	MX_TIM16_Init();
	MX_TIM17_Init();
	MX_FATFS_Init();
	MX_DMA2D_Init();
	MX_TIM2_Init();
	MX_CRC_Init();
	MX_JPEG_Init();
	/* USER CODE BEGIN 2 */
	// HRDW_GoToInternalSPIClock();

#ifdef HAS_TOUCHPAD
	GPIO_InitTypeDef GPIO_InitStruct = {0};
	GPIO_InitStruct.Pin = T_INT_Pin;
	GPIO_InitStruct.Mode = GPIO_MODE_INPUT;
	GPIO_InitStruct.Pull = GPIO_PULLDOWN;
	HAL_GPIO_Init(T_INT_GPIO_Port, &GPIO_InitStruct);
#endif
	__HAL_RCC_CSI_ENABLE();
	__HAL_RCC_SYSCFG_CLK_ENABLE();
	__HAL_RCC_BKPRAM_CLK_ENABLE();
	HAL_EnableCompensationCell();
	println("\r\n----------------------------------");
	println("WOLF-2 Transceiver Initialization...");
	println("[OK] USB init");
	USBD_Restart();
	println("[OK] FIFO timer TIM7 init");
	HAL_TIM_Base_Start_IT(&htim7);
	println("[OK] ENC2 timer TIM16 init");
	HAL_TIM_Base_Start_IT(&htim16);
	println("[OK] Real Time Clock init");
	HAL_RTC_Init(&hrtc);
	println("[OK] Frontpanel init");
	FRONTPANEL_Init();

	println("[OK] Settings loading");
	bool reset_settings = false;
	bool reset_calibrations = false;
	bool go_dfu = false;

	if (PERIPH_FrontPanel_Buttons[34].state) { // go DFU (TUNE)
		go_dfu = true;
	}
	if (PERIPH_FrontPanel_Buttons[26].state) { // soft reset (F1)
		reset_settings = true;
	}
	if (PERIPH_FrontPanel_Buttons[26].state && PERIPH_FrontPanel_Buttons[24].state) { // Very hard reset (F1+F9)
		reset_calibrations = true;
	}

	if (reset_settings) {
		LoadSettings(true);
	} else {
		LoadSettings(false);
	}

	// DFU bootloader
	if (TRX.NeedGoToBootloader || go_dfu) {
		TRX.NeedGoToBootloader = false;
		SaveSettings();
		JumpToBootloader();
	} else {
		MX_IWDG1_Init();
	}

	println("[OK] Calibration & WiFi loading");
	if (reset_calibrations) {
		LoadCalibration(true);
	} else {
		LoadCalibration(false);
	}

	TRX.Locked = false;
	println("[OK] LCD init");
	LCD_busy = true;
	LCD_Init();
	if (SHOW_LOGO) {
		strcpy(greetings_buff, "ver. ");
		strcat(greetings_buff, STM32_VERSION_STR);

		LCDDriver_Fill(rgb888torgb565(255, 255, 255));
		LCDDriver_printImage_JPEGCompressed(0, 0, IMAGES_logo800_NY_jpeg, sizeof(IMAGES_logo800_NY_jpeg));
		LCDDriver_printTextFont(greetings_buff, 30, (LCD_HEIGHT - 30), COLOR_BLACK, rgb888torgb565(255, 255, 255), &FreeSans12pt7b);

		// show callsign greetings
		uint16_t x1, y1, w, h;
		strcpy(greetings_buff, "Hello, ");
		strcat(greetings_buff, TRX.CALLSIGN);
		strcat(greetings_buff, " !");
		LCDDriver_getTextBoundsFont(greetings_buff, LAYOUT->GREETINGS_X, LAYOUT->GREETINGS_Y, &x1, &y1, &w, &h, &FreeSans9pt7b);
		LCDDriver_printTextFont(greetings_buff, LAYOUT->GREETINGS_X - (w / 2), LAYOUT->GREETINGS_Y, COLOR->GREETINGS, rgb888torgb565(255, 255, 255), &FreeSans9pt7b);
	}
	println("[OK] Profiler init");
	InitProfiler();

	println("[OK] RTC calibration");
	RTC_Calibration();

	println("[OK] RF-Unit init");
	RF_UNIT_UpdateState(false);
	println("[OK] FFT/Waterfall & ADC & TIM4 init");
	FFT_PreInit();
	FFT_Init();
	HAL_TIM_Base_Start_IT(&htim4);
	println("[OK] STM32-ADC Calibration");
	HAL_ADCEx_Calibration_Start(&hadc1, LL_ADC_CALIB_OFFSET_LINEARITY, ADC_SINGLE_ENDED);
	HAL_ADCEx_Calibration_Start(&hadc3, LL_ADC_CALIB_OFFSET_LINEARITY, ADC_SINGLE_ENDED);
	println("[OK] AudioCodec init");
	CODEC_Init();
	println("[OK] TRX init");
	TRX_Init();
	println("[OK] Audioprocessor & TIM5 init");
	initAudioProcessor();
	HAL_TIM_Base_Start_IT(&htim5);
	LCD_busy = false;
	LCD_redraw(true);
	println("[OK] Misc timer TIM6 init");
	HAL_TIM_Base_Start_IT(&htim6);
	println("[OK] CPU Load init");
	CPULOAD_Init();
	println("[OK] PERIPHERAL timer TIM15 init");
	dma_memset(&SDFatFs, 0, sizeof(SDFatFs));
	HAL_TIM_Base_Start_IT(&htim15);
	println("[OK] Digital decoder timer TIM17 init");
	HAL_TIM_Base_Start_IT(&htim17);
	println("[OK] FPGA init");
	FPGA_Init(false, false);
	println("[OK] WIFI timer TIM3 init");
	HAL_TIM_Base_Start_IT(&htim3);
	println("UA3REO Transceiver started!\r\n");
	TRX_Inited = true;

	if (CALIBRATE.INA226_EN) { //	if INA226 is activated then initialise
		INA226_Init();
	}

	// while(true){HAL_Delay(3000); SCB->AIRCR = 0x05FA0004; } //debug restart
	/* USER CODE END 2 */

	/* Infinite loop */
	/* USER CODE BEGIN WHILE */
	while (1) {
		/* USER CODE END WHILE */

		/* USER CODE BEGIN 3 */
		CPULOAD_GoToSleepMode();
	}
	/* USER CODE END 3 */
}

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
/* USER CODE BEGIN 4 */
// обработка вывода отладки
FILE __stdout;
FILE __stdin;

int fputc(int ch, FILE *f) {
#pragma unused(f)

	// SWD
	if (SWD_DEBUG_ENABLED) {
		ITM_SendChar((uint32_t)ch);
	}

	// USB
#if HRDW_DEBUG_ON_CAT_PORT
	if (USB_DEBUG_ENABLED) {
		char usb_char = (char)ch;
		CAT_Transmit_FIFO((uint8_t *)&usb_char, 1);
	}
#else
	if (USB_DEBUG_ENABLED) {
		char usb_char = (char)ch;
		DEBUG_Transmit_FIFO((uint8_t *)&usb_char, 1);
	}
#endif

	// LCD
	if (LCD_DEBUG_ENABLED) {
		print_chr_LCDOnly((char)ch);
	}

	return (ch);
}
/* USER CODE END 4 */

/* MPU Configuration */

void MPU_Config(void) {
	MPU_Region_InitTypeDef MPU_InitStruct = {0};

	/* Disables the MPU */
	HAL_MPU_Disable();

	/** Initializes and configures the Region and the memory to be protected
	 */
	MPU_InitStruct.Enable = MPU_REGION_ENABLE;
	MPU_InitStruct.Number = MPU_REGION_NUMBER0;
	MPU_InitStruct.BaseAddress = 0x60000000;
	MPU_InitStruct.Size = MPU_REGION_SIZE_1MB;
	MPU_InitStruct.SubRegionDisable = 0x0;
	MPU_InitStruct.TypeExtField = MPU_TEX_LEVEL0;
	MPU_InitStruct.AccessPermission = MPU_REGION_FULL_ACCESS;
	MPU_InitStruct.DisableExec = MPU_INSTRUCTION_ACCESS_ENABLE;
	MPU_InitStruct.IsShareable = MPU_ACCESS_SHAREABLE;
	MPU_InitStruct.IsCacheable = MPU_ACCESS_NOT_CACHEABLE;
	MPU_InitStruct.IsBufferable = MPU_ACCESS_NOT_BUFFERABLE;

	HAL_MPU_ConfigRegion(&MPU_InitStruct);

	/** Initializes and configures the Region and the memory to be protected
	 */
	MPU_InitStruct.Number = MPU_REGION_NUMBER2;
	MPU_InitStruct.BaseAddress = 0x38800000;
	MPU_InitStruct.Size = MPU_REGION_SIZE_4KB;

	HAL_MPU_ConfigRegion(&MPU_InitStruct);
	/* Enables the MPU */
	HAL_MPU_Enable(MPU_PRIVILEGED_DEFAULT);
}

/**
 * @brief  This function is executed in case of error occurrence.
 * @retval None
 */
void Error_Handler(void) {
	/* USER CODE BEGIN Error_Handler_Debug */
	/* User can add his own implementation to report the HAL error return state */
	println("error handled");
	/*while (1)
	{
	  LCD_showError("Error handled", true);
	}*/
	// LCD_showError("Error handled", true);
	/* USER CODE END Error_Handler_Debug */
}

#ifdef USE_FULL_ASSERT
/**
 * @brief  Reports the name of the source file and the source line number
 *         where the assert_param error has occurred.
 * @param  file: pointer to the source file name
 * @param  line: assert_param error line source number
 * @retval None
 */
void assert_failed(uint8_t *file, uint32_t line) {
	/* USER CODE BEGIN 6 */
	/* User can add his own implementation to report the file name and line number,
	   tex: printf("Wrong parameters value: file %s on line %d\r\n", file, line) */
	printf("Wrong parameters value: file %s on line %u\r\n", file, line);
	/* USER CODE END 6 */
}
#endif /* USE_FULL_ASSERT */

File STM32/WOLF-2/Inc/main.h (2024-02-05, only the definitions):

#define ENC_CLK_Pin GPIO_PIN_2
#define ENC_CLK_GPIO_Port GPIOE
#define ENC_CLK_EXTI_IRQn EXTI2_IRQn
#define ENC_DT_Pin GPIO_PIN_3
#define ENC_DT_GPIO_Port GPIOE
#define ENC3_DT_Pin GPIO_PIN_4
#define ENC3_DT_GPIO_Port GPIOE
#define ENC2_CLK_Pin GPIO_PIN_5
#define ENC2_CLK_GPIO_Port GPIOE
#define ENC2_DT_Pin GPIO_PIN_6
#define ENC2_DT_GPIO_Port GPIOE
#define ENC3_CLK_Pin GPIO_PIN_13
#define ENC3_CLK_GPIO_Port GPIOC
#define SWR_FORW_Pin GPIO_PIN_0
#define SWR_FORW_GPIO_Port GPIOC
#define SWR_BACKW_Pin GPIO_PIN_1
#define SWR_BACKW_GPIO_Port GPIOC
#define FPGA_CLK_Pin GPIO_PIN_2
#define FPGA_CLK_GPIO_Port GPIOC
#define FPGA_SYNC_Pin GPIO_PIN_3
#define FPGA_SYNC_GPIO_Port GPIOC
#define FPGA_BUS_D0_Pin GPIO_PIN_0
#define FPGA_BUS_D0_GPIO_Port GPIOA
#define FPGA_BUS_D1_Pin GPIO_PIN_1
#define FPGA_BUS_D1_GPIO_Port GPIOA
#define FPGA_BUS_D2_Pin GPIO_PIN_2
#define FPGA_BUS_D2_GPIO_Port GPIOA
#define FPGA_BUS_D3_Pin GPIO_PIN_3
#define FPGA_BUS_D3_GPIO_Port GPIOA
#define FPGA_BUS_D4_Pin GPIO_PIN_4
#define FPGA_BUS_D4_GPIO_Port GPIOA
#define FPGA_BUS_D5_Pin GPIO_PIN_5
#define FPGA_BUS_D5_GPIO_Port GPIOA
#define FPGA_BUS_D6_Pin GPIO_PIN_6
#define FPGA_BUS_D6_GPIO_Port GPIOA
#define FPGA_BUS_D7_Pin GPIO_PIN_7
#define FPGA_BUS_D7_GPIO_Port GPIOA
#define PTT_IN_Pin GPIO_PIN_4
#define PTT_IN_GPIO_Port GPIOC
#define PTT_IN_EXTI_IRQn EXTI4_IRQn
#define RFUNT_THERM_Pin GPIO_PIN_5
#define RFUNT_THERM_GPIO_Port GPIOC
#define W25Q16_CS_Pin GPIO_PIN_0
#define W25Q16_CS_GPIO_Port GPIOB
#define RFUNT_ALC_Pin GPIO_PIN_1
#define RFUNT_ALC_GPIO_Port GPIOB
#define RFMIXER_CS_Pin GPIO_PIN_2
#define RFMIXER_CS_GPIO_Port GPIOB
#define AUDIO_48K_CLOCK_Pin GPIO_PIN_10
#define AUDIO_48K_CLOCK_GPIO_Port GPIOB
#define AUDIO_48K_CLOCK_EXTI_IRQn EXTI15_10_IRQn
#define SD_CS_Pin GPIO_PIN_11
#define SD_CS_GPIO_Port GPIOB
#define T_I2C_SDA_Pin GPIO_PIN_12
#define T_I2C_SDA_GPIO_Port GPIOB
#define PERI_SCK_Pin GPIO_PIN_13
#define PERI_SCK_GPIO_Port GPIOB
#define PERI_MISO_Pin GPIO_PIN_14
#define PERI_MISO_GPIO_Port GPIOB
#define PERI_MOSI_Pin GPIO_PIN_15
#define PERI_MOSI_GPIO_Port GPIOB
#define PWR_ON_Pin GPIO_PIN_11
#define PWR_ON_GPIO_Port GPIOD
#define PWR_ON_EXTI_IRQn EXTI15_10_IRQn
#define PWR_HOLD_Pin GPIO_PIN_12
#define PWR_HOLD_GPIO_Port GPIOD
#define ESP_1_TX_Pin GPIO_PIN_6
#define ESP_1_TX_GPIO_Port GPIOC
#define ESP_1_RX_Pin GPIO_PIN_7
#define ESP_1_RX_GPIO_Port GPIOC
#define AD1_CS_Pin GPIO_PIN_8
#define AD1_CS_GPIO_Port GPIOC
#define T_I2C_SCL_Pin GPIO_PIN_8
#define T_I2C_SCL_GPIO_Port GPIOA
#define T_INT_Pin GPIO_PIN_9
#define T_INT_GPIO_Port GPIOA
#define PTT_OUT_Pin GPIO_PIN_10
#define PTT_OUT_GPIO_Port GPIOA
#define WM8731_WS_LRC_Pin GPIO_PIN_15
#define WM8731_WS_LRC_GPIO_Port GPIOA
#define WM8731_BCLK_Pin GPIO_PIN_10
#define WM8731_BCLK_GPIO_Port GPIOC
#define WM8731_ADC_SD_Pin GPIO_PIN_11
#define WM8731_ADC_SD_GPIO_Port GPIOC
#define WM8731_DAC_SD_Pin GPIO_PIN_12
#define WM8731_DAC_SD_GPIO_Port GPIOC
#define ENC4_CLK_Pin GPIO_PIN_2
#define ENC4_CLK_GPIO_Port GPIOD
#define WM8731_SCK_Pin GPIO_PIN_3
#define WM8731_SCK_GPIO_Port GPIOD
#define WM8731_SDA_Pin GPIO_PIN_6
#define WM8731_SDA_GPIO_Port GPIOD
#define ENC4_DT_Pin GPIO_PIN_4
#define ENC4_DT_GPIO_Port GPIOB
#define AF_AMP_MUTE_Pin GPIO_PIN_5
#define AF_AMP_MUTE_GPIO_Port GPIOB
#define RFUNIT_RCLK_Pin GPIO_PIN_6
#define RFUNIT_RCLK_GPIO_Port GPIOB
#define RFUNIT_CLK_Pin GPIO_PIN_7
#define RFUNIT_CLK_GPIO_Port GPIOB
#define RFUNIT_DATA_Pin GPIO_PIN_8
#define RFUNIT_DATA_GPIO_Port GPIOB
#define RFUNIT_OE_Pin GPIO_PIN_9
#define RFUNIT_OE_GPIO_Port GPIOB
#define KEY_IN_DASH_Pin GPIO_PIN_0
#define KEY_IN_DASH_GPIO_Port GPIOE
#define KEY_IN_DASH_EXTI_IRQn EXTI0_IRQn
#define KEY_IN_DOT_Pin GPIO_PIN_1
#define KEY_IN_DOT_GPIO_Port GPIOE
#define KEY_IN_DOT_EXTI_IRQn EXTI1_IRQn

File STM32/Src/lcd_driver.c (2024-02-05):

#include "lcd_driver.h"
#include "fonts.h"
#include "functions.h"
#include "main.h"
#include "settings.h"

#if HRDW_HAS_JPEG
#include "jpeg_utils.h"
#endif

static bool _cp437 = false;
static uint16_t text_cursor_y = 0;
static uint16_t text_cursor_x = 0;
static bool wrap = false;

uint16_t LCDDriver_GetCurrentXOffset(void) { return text_cursor_x; }

void LCDDriver_SetCurrentXOffset(uint16_t x) { text_cursor_x = x; }

// Text printing functions
void LCDDriver_drawCharInMemory(uint16_t x, uint16_t y, unsigned char c, uint16_t color, uint16_t bg, uint16_t antiAliasedColorLeft, uint16_t antiAliasedColorRight, uint8_t size,
                                uint16_t *buffer, uint16_t buffer_w, uint16_t buffer_h) {
	uint8_t line;
	uint8_t zoom = (size > 0 ? size : 1);
	uint8_t size_w = (size > 0 ? RASTR_FONT_W : RASTR_FONT_4x6_W);
	uint8_t size_h = (size > 0 ? RASTR_FONT_H : RASTR_FONT_4x6_H);

	if ((x >= buffer_w) ||           // Clip right
	    (y >= buffer_h) ||           // Clip bottom
	    ((x + size_w * zoom) < 0) || // Clip left
	    ((y + size_h * zoom) < 0)) { // Clip top
		return;
	}

	if ((x + size_w * zoom) >= buffer_w || (y + size_h * zoom) >= buffer_h) {
		return;
	}

	if (c < 32) { // non-printable
		return;
	}
	if (!_cp437 && (c >= 176)) {
		c++; // Handle 'classic' charset behavior
	}

	if (size > 0) {
		for (int8_t j = 0; j < size_h; j++) // y line out
		{
			for (int8_t s_y = 0; s_y < zoom; s_y++) // y size scale
			{
				uint16_t *point = buffer + buffer_w * (y + j * (s_y + 1)) + x;
				uint16_t prev_x_color = bg;
				for (int8_t i = 0; i < size_w; i++) {
					// x line out
					if (i == 5) {
						line = 0x0;
					} else {
						line = rastr_font[(c * 5) + i]; // read font
					}
					line >>= j;
					for (int8_t s_x = 0; s_x < zoom; s_x++) // x size scale
					{
						if (line & 0x1) {
							if (prev_x_color != color) {
								*point = antiAliasedColorLeft; // anti-aliased font pixel
								prev_x_color = color;
							} else {
								*point = color; // font pixel
							}
						} else {
							if (prev_x_color != bg) {
								*point = antiAliasedColorRight; // anti-aliased background pixel
								prev_x_color = bg;
							} else {
								*point = bg; // background pixel
							}
						}
						point++;
					}
				}
			}
		}
	} else // size 0 4x6
	{
		for (int8_t j = 0; j < size_h; j++) // y line out
		{
			line = rastr_font_4x6[((c - 0x20) * 6) + j]; // read font
			uint16_t *point = buffer + buffer_w * (y + j) + x;
			uint16_t prev_x_color = bg;
			for (int8_t i = 0; i < size_w; i++) {
				if (line & 0x8) {
					if (prev_x_color != color) {
						*point = antiAliasedColorLeft; // anti-aliased font pixel
						prev_x_color = color;
					} else {
						*point = color; // font pixel
					}
				} else {
					if (prev_x_color != bg) {
						*point = antiAliasedColorRight; // anti-aliased background pixel
						prev_x_color = bg;
					} else {
						*point = bg; // background pixel
					}
				}
				point++;

				line <<= 1;
			}
		}
	}
}

void LCDDriver_printTextInMemory(char text[], int16_t x, int16_t y, uint16_t color, uint16_t bg, uint8_t size, uint16_t *buffer, uint16_t buffer_w, uint16_t buffer_h) {
	uint16_t i = 0;
	uint16_t offset = size * 6;
	uint16_t skipped = 0;

	uint16_t antiAliasedColorLeft = mixColors(color, bg, FONT_ANTIALIASING_COEFF_LEFT);
	uint16_t antiAliasedColorRight = mixColors(color, bg, FONT_ANTIALIASING_COEFF_RIGHT);

	for (i = 0; i < 128 && text[i] != 0; i++) {
		if (text[i] == '^' && text[i + 1] == 'o') // celsius
		{
			i++;
			skipped++;
			LCDDriver_drawCharInMemory(x + (offset * (i - skipped)), y - 3, text[i], color, bg, antiAliasedColorLeft, antiAliasedColorRight, size, buffer, buffer_w, buffer_h);
		} else {
			LCDDriver_drawCharInMemory(x + (offset * (i - skipped)), y, text[i], color, bg, antiAliasedColorLeft, antiAliasedColorRight, size, buffer, buffer_w, buffer_h);
		}
		text_cursor_x = x + (offset * (i + 1 - skipped));
	}
}

void LCDDriver_drawChar(uint16_t x, uint16_t y, unsigned char c, uint16_t color, uint16_t bg, uint16_t antiAliasedColorLeft, uint16_t antiAliasedColorRight, uint8_t size) {
	uint8_t line;
	uint8_t zoom = (size > 0 ? size : 1);
	uint8_t size_w = (size > 0 ? RASTR_FONT_W : RASTR_FONT_4x6_W);
	uint8_t size_h = (size > 0 ? RASTR_FONT_H : RASTR_FONT_4x6_H);

	if ((x >= LCD_WIDTH) ||              // Clip right
	    (y >= LCD_HEIGHT) ||             // Clip bottom
	    ((x + size_w * zoom - 1) < 0) || // Clip left
	    ((y + size_h * zoom - 1) < 0)) { // Clip top
		return;
	}

	if (c < 32) { // non-printable
		return;
	}
	if (!_cp437 && (c >= 176)) {
		c++; // Handle 'classic' charset behavior
	}

	LCDDriver_SetCursorAreaPosition(x, y, x + size_w * zoom - 1, y + size_h * zoom - 1); // char area
	if (size > 0) {                                                                      // 6x8 char
		for (int8_t j = 0; j < size_h; j++)                                                // y line out
		{
			for (int8_t s_y = 0; s_y < zoom; s_y++) // y size scale
			{
				uint16_t prev_x_color = bg;
				for (int8_t i = 0; i < size_w; i++) {
					// x line out
					if (i == 5) {
						line = 0x0;
					} else {
						line = rastr_font[(c * 5) + i]; // read font
					}
					line >>= j;
					for (int8_t s_x = 0; s_x < zoom; s_x++) // x size scale
					{
						if (line & 0x1) {
							if (prev_x_color != color) {
								LCDDriver_SendData16(antiAliasedColorLeft); // anti-aliased font pixel
								prev_x_color = color;
							} else {
								LCDDriver_SendData16(color); // font pixel
							}
						} else {
							if (prev_x_color != bg) {
								LCDDriver_SendData16(antiAliasedColorRight); // anti-aliased background pixel
								prev_x_color = bg;
							} else {
								LCDDriver_SendData16(bg); // background pixel
							}
						}
					}
				}
			}
		}
	} else // size 0 4x6
	{
		for (int8_t j = 0; j < size_h; j++) // y line out
		{
			line = rastr_font_4x6[((c - 0x20) * 6) + j]; // read font
			uint16_t prev_x_color = bg;
			for (int8_t i = 0; i < size_w; i++) {
				if (line & 0x8) {
					if (prev_x_color != color) {
						LCDDriver_SendData16(antiAliasedColorLeft); // anti-aliased font pixel
						prev_x_color = color;
					} else {
						LCDDriver_SendData16(color); // font pixel
					}
				} else {
					if (prev_x_color != bg) {
						LCDDriver_SendData16(antiAliasedColorRight); // anti-aliased background pixel
						prev_x_color = bg;
					} else {
						LCDDriver_SendData16(bg); // background pixel
					}
				}

				line <<= 1;
			}
		}
	}
}
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

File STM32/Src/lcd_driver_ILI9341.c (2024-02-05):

#include "settings.h"
#if defined(LCD_ILI9341)

// Header files
#include "fonts.h"
#include "functions.h"
#include "lcd_driver.h"
#include "lcd_driver_ILI9341.h"
#include "main.h"

//***** Functions prototypes *****//
static inline void LCDDriver_SetCursorPosition(uint16_t x, uint16_t y);
inline void LCDDriver_SetCursorAreaPosition(uint16_t x1, uint16_t y1, uint16_t x2, uint16_t y2);
static bool DC_mode = false;

// Write command to LCD
inline void LCDDriver_SendCommand(uint16_t com) {
	if (hspi4.Init.DataSize != SPI_DATASIZE_8BIT) {
		hspi4.Init.DataSize = SPI_DATASIZE_8BIT;
		HAL_SPI_Init(&hspi4);
	}

	// if(DC_mode)
	{
		LCD_DC_GPIO_Port->BSRR = (LCD_DC_Pin << 16U);
		// DC_mode = false;
	}

	/* Set the number of data at current transfer */
	MODIFY_REG(hspi4.Instance->CR2, SPI_CR2_TSIZE, 1);

	/* Enable SPI peripheral */
	__HAL_SPI_ENABLE(&hspi4);

	/* Master transfer start */
	SET_BIT(hspi4.Instance->CR1, SPI_CR1_CSTART);

	// Set data
	*((__IO uint8_t *)&hspi4.Instance->TXDR) = com;

	// Wait until TXP flag is set to send data
	while (!__HAL_SPI_GET_FLAG(&hspi4, SPI_FLAG_TXP)) {
	}

	// Wait for Tx (and CRC) data to be sent
	while (!__HAL_SPI_GET_FLAG(&hspi4, SPI_FLAG_EOT)) {
	}

	__HAL_SPI_CLEAR_EOTFLAG(&hspi4);
	__HAL_SPI_CLEAR_TXTFFLAG(&hspi4);

	__HAL_SPI_DISABLE(&hspi4);
}

// Write 8bit data to LCD
inline void LCDDriver_SendData8(uint8_t data) {
	if (hspi4.Init.DataSize != SPI_DATASIZE_8BIT) {
		hspi4.Init.DataSize = SPI_DATASIZE_8BIT;
		HAL_SPI_Init(&hspi4);
	}

	// if(!DC_mode)
	{
		LCD_DC_GPIO_Port->BSRR = LCD_DC_Pin;
		// DC_mode = true;
	}

	/* Set the number of data at current transfer */
	MODIFY_REG(hspi4.Instance->CR2, SPI_CR2_TSIZE, 1);

	/* Enable SPI peripheral */
	__HAL_SPI_ENABLE(&hspi4);

	/* Master transfer start */
	SET_BIT(hspi4.Instance->CR1, SPI_CR1_CSTART);

	// Set data
	*((__IO uint8_t *)&hspi4.Instance->TXDR) = data;

	// Wait until TXP flag is set to send data
	while (!__HAL_SPI_GET_FLAG(&hspi4, SPI_FLAG_TXP)) {
	}

	// Wait for Tx (and CRC) data to be sent
	while (!__HAL_SPI_GET_FLAG(&hspi4, SPI_FLAG_EOT)) {
	}

	__HAL_SPI_CLEAR_EOTFLAG(&hspi4);
	__HAL_SPI_CLEAR_TXTFFLAG(&hspi4);

	__HAL_SPI_DISABLE(&hspi4);
}

// Write 16 bit data to LCD
inline void LCDDriver_SendData16(uint16_t data) {
	if (hspi4.Init.DataSize != SPI_DATASIZE_8BIT) {
		hspi4.Init.DataSize = SPI_DATASIZE_8BIT;
		HAL_SPI_Init(&hspi4);
	}

	// if(!DC_mode)
	{
		LCD_DC_GPIO_Port->BSRR = LCD_DC_Pin;
		// DC_mode = true;
	}

	/* Set the number of data at current transfer */
	MODIFY_REG(hspi4.Instance->CR2, SPI_CR2_TSIZE, 2);

	/* Enable SPI peripheral */
	__HAL_SPI_ENABLE(&hspi4);

	/* Master transfer start */
	SET_BIT(hspi4.Instance->CR1, SPI_CR1_CSTART);

	// Set data
	*((__IO uint8_t *)&hspi4.Instance->TXDR) = data >> 8;

	// Wait until TXP flag is set to send data
	while (!__HAL_SPI_GET_FLAG(&hspi4, SPI_FLAG_TXP)) {
	}

	// Set data
	*((__IO uint8_t *)&hspi4.Instance->TXDR) = data;

	// Wait until TXP flag is set to send data
	while (!__HAL_SPI_GET_FLAG(&hspi4, SPI_FLAG_TXP)) {
	}

	// Wait for Tx (and CRC) data to be sent
	while (!__HAL_SPI_GET_FLAG(&hspi4, SPI_FLAG_EOT)) {
	}

	__HAL_SPI_CLEAR_EOTFLAG(&hspi4);
	__HAL_SPI_CLEAR_TXTFFLAG(&hspi4);

	__HAL_SPI_DISABLE(&hspi4);
}

// Initialise function
void LCDDriver_Init(void) {
	//------------------------------------ILI9341 Init Sequence-----------------------------------------//
	HAL_GPIO_WritePin(LCD_RST_GPIO_Port, LCD_RST_Pin, GPIO_PIN_SET);
	HAL_Delay(150);

	LCDDriver_SendCommand(0xEF);
	LCDDriver_SendData8(0x03);
	LCDDriver_SendData8(0x80);
	LCDDriver_SendData8(0x02);

	LCDDriver_SendCommand(0xCF);
	LCDDriver_SendData8(0x00);
	LCDDriver_SendData8(0xC1);
	LCDDriver_SendData8(0x30);

	LCDDriver_SendCommand(0xED);
	LCDDriver_SendData8(0x64);
	LCDDriver_SendData8(0x03);
	LCDDriver_SendData8(0x12);
	LCDDriver_SendData8(0x81);

	LCDDriver_SendCommand(0xE8);
	LCDDriver_SendData8(0x85);
	LCDDriver_SendData8(0x00);
	LCDDriver_SendData8(0x78);

	LCDDriver_SendCommand(0xCB);
	LCDDriver_SendData8(0x39);
	LCDDriver_SendData8(0x2C);
	LCDDriver_SendData8(0x00);
	LCDDriver_SendData8(0x34);
	LCDDriver_SendData8(0x02);

	LCDDriver_SendCommand(0xF7);
	LCDDriver_SendData8(0x20);

	LCDDriver_SendCommand(0xEA);
	LCDDriver_SendData8(0x00);
	LCDDriver_SendData8(0x00);

	LCDDriver_SendCommand(LCD_COMMAND_PWCTR1); // Power control VRH[5:0]
	LCDDriver_SendData8(0x23);

	LCDDriver_SendCommand(LCD_COMMAND_PWCTR2); // Power control SAP[2:0];BT[3:0]
	LCDDriver_SendData8(0x10);

	LCDDriver_SendCommand(LCD_COMMAND_VMCTR1); // VCM control
	LCDDriver_SendData8(0x3e);
	LCDDriver_SendData8(0x28);

	LCDDriver_SendCommand(LCD_COMMAND_VMCTR2); // VCM control2
	LCDDriver_SendData8(0x86);

	LCDDriver_SendCommand(LCD_COMMAND_MADCTL); // Memory Access Control
	LCDDriver_SendData8(0x48);

	LCDDriver_SendCommand(LCD_COMMAND_VSCRSADD); // Vertical scroll zero
	LCDDriver_SendData8(0x00);

	LCDDriver_SendCommand(LCD_COMMAND_PIXFMT);
	LCDDriver_SendData8(0x55);

	LCDDriver_SendCommand(LCD_COMMAND_FRMCTR1);
	LCDDriver_SendData8(0x00);
	LCDDriver_SendData8(0x18);

	LCDDriver_SendCommand(LCD_COMMAND_DFUNCTR); // Display Function Control
	LCDDriver_SendData8(0x08);
	LCDDriver_SendData8(0x82);
	LCDDriver_SendData8(0x27);

	LCDDriver_SendCommand(0xF2); // 3Gamma Function Disable
	LCDDriver_SendData8(0x00);

	LCDDriver_SendCommand(LCD_COMMAND_GAMMASET); // Gamma curve selected
	LCDDriver_SendData8(0x01);

	LCDDriver_SendCommand(LCD_COMMAND_GMCTRP1); // Set Gamma
	LCDDriver_SendData8(0x0F);
	LCDDriver_SendData8(0x31);
	LCDDriver_SendData8(0x2B);
	LCDDriver_SendData8(0x0C);
	LCDDriver_SendData8(0x0E);
	LCDDriver_SendData8(0x08);
	LCDDriver_SendData8(0x4E);
	LCDDriver_SendData8(0xF1);
	LCDDriver_SendData8(0x37);
	LCDDriver_SendData8(0x07);
	LCDDriver_SendData8(0x10);
	LCDDriver_SendData8(0x03);
	LCDDriver_SendData8(0x0E);
	LCDDriver_SendData8(0x09);
	LCDDriver_SendData8(0x00);

	LCDDriver_SendCommand(LCD_COMMAND_GMCTRN1); // Set Gamma
	LCDDriver_SendData8(0x00);
	LCDDriver_SendData8(0x0E);
	LCDDriver_SendData8(0x14);
	LCDDriver_SendData8(0x03);
	LCDDriver_SendData8(0x11);
	LCDDriver_SendData8(0x07);
	LCDDriver_SendData8(0x31);
	LCDDriver_SendData8(0xC1);
	LCDDriver_SendData8(0x48);
	LCDDriver_SendData8(0x08);
	LCDDriver_SendData8(0x0F);
	LCDDriver_SendData8(0x0C);
	LCDDriver_SendData8(0x31);
	LCDDriver_SendData8(0x36);
	LCDDriver_SendData8(0x0F);

	LCDDriver_SendCommand(LCD_COMMAND_SLPOUT); // Exit Sleep
	HAL_Delay(150);

	LCDDriver_SendCommand(LCD_COMMAND_DISPON); // Display on
	HAL_Delay(150);
}
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

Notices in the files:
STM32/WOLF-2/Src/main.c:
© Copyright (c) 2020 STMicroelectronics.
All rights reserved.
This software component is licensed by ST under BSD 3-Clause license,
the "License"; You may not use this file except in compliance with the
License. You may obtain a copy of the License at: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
